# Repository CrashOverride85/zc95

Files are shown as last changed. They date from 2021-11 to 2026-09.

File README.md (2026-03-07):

# ZC95

**Note**: This repo has submodules, so if cloning, it's best to use the recursive option.

## Introduction
The ZC95 is a DIY four channel EStim box with similar output design and feel to the MK312-BT (which in turn is a clone of the ET-312B).

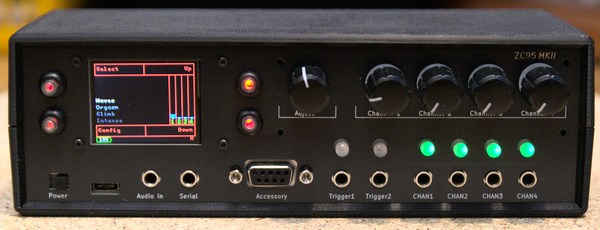
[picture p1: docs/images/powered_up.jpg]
zc95


The box is primarily intended for standalone use (i.e. not used whilst connected to phone/laptop/tablet), but can be controlled remotely via a Python GUI, and run Lua scripts that have been uploaded to it over serial or WiFi.

Main features:
- 4 isolated channels 
- [Audio input](./docs/AudioInput-Operation.md) - line level for estim tracks or microphone input (selectable via menu)
- [Many inbuilt patterns](./docs/Patterns.md) - around 14, not counting audio and more esoteric stuff
- Custom patterns can be written in [Lua](./docs/LuaNotes.md)
- Two stereo 3.5mm trigger input sockets, allowing for up to 4 external inputs (e.g. remote buttons, foot pedals, etc.)
- Support for many [BLE remote/camera buttons](./docs//BluetoothPeripherals.md), e.g. to trigger output when the button is pressed
- [Remote control](./docs/RemoteAccess.md) over WiFi or serial using a python app
- Allows limited control of a certain type of 433MHz shock collar
- Somewhat experimental [BLE steaming](./docs/BleStreaming.md) - allows for per-pulse level control from laptop or other device, with an example in python
- An accessory port with 3 output lines that can be controlled from Lua scripts, to allow interacting with other devices

Technical details:
- Has been designed with the JLC PCB assembly service in mind, and is mostly an SMD design with a few though hole parts
- Uses 2x Raspberry Picos
- Firmware is open source and mostly C++, and makes use of many [3rd party libraries](./docs/Credits.md)
- 26650 cell for power
- KiCad project files included in repo, not just gerbers
- Audio input includes microphone preamp that can be toggled via menu, along with variable gain
- Consists of 3 PCBs:
   * Front panel - no traces, just text / mounting holes
   * Front panel controls - 4x POTs and associated ADC, 1x rotary encoder and 6 serial RGB LEDs. Designed for production using the SMT assembly service at JLCPCB, with a handful of extra through hole parts also requiring hand soldering.
   * Main board - power supply / charging, pattern generation, button input, output signal generation, audio input
- Case is either an off the shelf Hammond 1598DBK (larger), or a 3D printed case (step/stl files provided)

## [Build guide](docs/Build.md)

## [Schematics](schematics/)

## [Gerbers](pcb/)

## [Compiled firmware](https://github.com/CrashOverride85/zc95/releases/)

## [Operation notes](docs/Operation.md)

## [Pattern guide](docs/Patterns.md)

## [Lua scripting notes](docs/LuaNotes.md)

## [Notes on building source](docs/SourceBuildNotes.md)

## [Credits](docs/Credits.md)

# Miscellaneous  
## History
The ZC95 is very heavily inspired by the MK312-BT, which is a reversed engineered version of the ET-312. The original repo for that project is long gone, but there is a fork [here](https://github.com/CrashOverride85/mk312-bt).

The [ZC95 mk1](https://github.com/CrashOverride85/zc95/tree/MKI) was made public in late 2021, and had a similar form factor to the MK312. That version has been built successfully by many.

The [ZC95 mk1](https://github.com/CrashOverride85/zc95/tree/MKI) had the output stage on a separate PCB. It's no longer part of the zc95 build, but could still be built and used to add 4 channel estim output to an Arduino (with notes for & tested with an ESP32).
The PCB / BoM / build notes for it are [here](./misc/OutputBoard/README.md).

## MKI vs. MKII
These are the main changes from the MKI to MKII:

 - Much smaller - the mainboard is less than half the size
 - Output, Audio and main board are now combined
 - USB-C charger input instead of 15v barrel jack
 - 26650 cell instead of 12v SLA battery (similar capacity)
 - "Aux" socket swapped for separate "Serial" and "Audio" sockets
 - Output sockets changed from 2.5mm to 3.5mm
 - Serial selectable (via jumpers) between 3.3v TTL and RS232
 - Display no longer briefly flashes white on power on
 - Removed: 12v output on accessory port

## Support, feedback, etc.
The ZC95 project is provided 'as is' without warranty of any kind, either express or implied. The project is provided for your use at your own risk.

Having said that, if you run into difficulties or have questions, the two best places to try are:
- Github [discussions](https://github.com/CrashOverride85/zc95/discussions) or [issues](https://github.com/CrashOverride85/zc95/issues)
- The ZC95 channel on [Joanne's E-Stim Community discord](https://discord.gg/HbGKY2t), see Estim control boxes -> zc95
  - I'd highly recommend joining this discord server anyway, the zc95 chanel is a _tiny_ part of what's there

## Other projects
Other related projects that are worth checking out:

- [NeoDK](https://github.com/Onwrikbaar/NeoDK) - Advanced electrostimulation machine development kit. In active development, and also has a chanel on [Joanne's E-Stim Community discord](https://discord.gg/HbGKY2t)

- MK-312BT - Project the ZC95 was inspired by, and shares lot in common with (original repo gone, but there are many [forks](https://github.com/CrashOverride85/mk312-bt))

- [WT-312](https://github.com/WendyTeslaburger/WT-312) - 312 style driver, intended for integration into other projects

- [FOC-Stim](https://github.com/diglet48/FOC-Stim) - In development, checkout the foc-stim channel on [Joanne's E-Stim Community discord](https://discord.gg/HbGKY2t) for the latest

# TODO
## Firmware
   - Triphase support from Lua 
   - Allow Lua scripts to interact with shock collars
   - Combo pattern? Having, e.g., waves on channels 1+2 plus something like TENS on 3+4 would be good
   - Save pattern settings on exit?
   - Disable when plugged in / switch to charging screen (maybe a setting in the menu to disable)
   - Accessory port doesn't do much - just 3 output lines. There's a serial interface there too, which could be exposed in the Lua environment

## Hardware
   - Improved 3D printed case?

## Known issues
   - Will charge faster if switched on when plugged in, and not switched off for at least 10 seconds (or just left on)
   - Sometimes when finished charging (battery icon showing solid green), the battery percentage will only show ~95% despite being fully charged. Should be fixed in a future firmware version. 

[zc95]: docs/images/powered_up.jpg "Assembled ZC95"

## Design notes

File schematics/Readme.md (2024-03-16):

For hardware change log, see [readme in PCB folder](../pcb/Readme.md)

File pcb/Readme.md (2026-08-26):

# Changes

## Front panel

### v1.1 (Mk2 Only)
- Kindly designed by rootuz. Please note that whilst the project files (EasyEDA) & gerbers for this PCB are available, they are provided under the [CERN-OHL-S](../pcb-project/FrontPanelControls/v1_x/LICENSE.txt) licence
- Updated to match the v1.1 FrontPanelControls board

### v0.5 (Mk2 only)
- Updated for Mk2: USB-C, separate audio & serial sockets, output sockets changed from 2.5mm to 3.5mm

### v0.4
- *Not publicly released*

### v0.3 (Mk1 only)
- Button holes enlarged to 8.1mm for LP1OA1Ax illuminated buttons

### v0.2 (Mk1 only)
- Left most 3.5mm socket renamed from "Serial" to "Aux"
- 4x holes for potentiometers enlarged so RK09L1140A2U fits without needing to manually enlarge the hole
- Project updated to KiCad 6

### v0.1 (Mk1 only)
First public version

## FrontPanelControls
### v1.1 (Mk2 only)
Technically this PCB should work on a Mk1, however there is no corresponding Front panel pcb
- Kindly designed by rootuz. Please note that whilst the project files (EasyEDA) & gerbers for this PCB are available, they are provided under the [CERN-OHL-S](../pcb-project/FrontPanelControls/v1_x/LICENSE.txt) licence
- Square buttons mounted direct to the PCB
- As the PCB extends to the buttons, the display is mounted to this PCB
- LEDs are surface mount, with light pipes to the front

### v0.2 (Mk1 & Mk2)
- Requires firmware version >=1.8
- Now mostly SMD aimed at JLCPCB's SMT assembly service
- 4x front panel buttons are now connected to this board, not the main board
- ADC changed from PCF8591 (EoL) to ADS1115
- I/O expander changed from PCF8574 to TCA9534
- Allows use of illuminated buttons (LP1OA1Ax) controlled by TLC59108
- Project updated to KiCad 6

### v0.1 (Mk1 only)
First public version

## MainBoard

### v2.6
Fix:
 - Improve layout: Move input capacitor closer to the BQ25601 charge controller

Tweaks:
 - Added header for audio input next to the audio jack

### v2.5
Fix:
 - Update power switch so that it toggles the power enable pin of the voltage regulators, instead of directly switching the power as before. To avoid over current fault / shutdown of BQ25601.

 Tweaks:
 - Changed 500mΩ sense resistors from 1218 to 2512 footprint for availability reasons
 - Sleeve and Ring of output TRS jacks are now connected together. Previously Ring was unconnected.

### v2.4
- *Not publicly released*

### v2.3
Tweaks:
 - No more vias in pads
 - Changed charge controller from TP4056 to BQ25601
 - Added 3.3v LDO powered from 5v rail to supply some of the audio circuitry (reduces noise when using a mic)
 - Changed footprint of LCD and Debug connectors to make intended orientation clear
 - Added ability to sense voltage on USB CC lines to determine type of charger connected
 - Display reset line now connected to port expander instead of pull up to 5v. Fixes intermittent issue where display would show pure white if the box was powered off, then powered up a few seconds later.

### v2.2
- *Not publicly released*

### v2.1
Fixed solder mask minimum width setting - restore to KiCad default of 0

### v2.0
Mk2. Many changes:
 - Now includes functionality that was previously on separate output & audio boards
 - USB-C charger input instead of 15v barrel jack
 - 26650 cell instead of 12v SLA battery (similar capacity)
 - "Aux" socket swapped for separate "Serial" and "Audio" sockets
 - Output sockets changed from 2.5mm to 3.5mm
 - Serial selectable (via jumpers) between 3.3v TTL and RS232
 - Display no longer briefly flashes white on power on
 - Removed: 12v output on accessory port
 - Will not work with FrontPanelControls PCB v0.1

### v0.2
Mk1. First public version.

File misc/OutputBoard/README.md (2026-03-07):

# Output board

The original ZC95 mk1 had the estim output stage on a separate PCB; that's been incorporated into the main board with the mkII. Whilst it was only ever intended to be used as a part of the ZC95, the output board could also be used from other projects, and there is an included [Arduino library](../Arduino/libraries/Zc624Output/README.md) for it.
So these are the (slightly tweaked) original build notes from that board, in case it's still of interest to anyone.

---

## PCBs
The output board ("ZC624 Output module") has been designed with the JLCPCB SMT assembly service in mind, although the footprints are the hand-solder versions where applicable, and some (through hole) parts still need hand assembly.
Order the board using [these gerbers](./pcb/OutputBoard-gerbers.zip) and the default options as per the other boards.

This time, select the "SMT Assembly" option at the bottom - pick "Assemble top side" and Tooling holes "Added by JLCPCB".
On the next page, add the BOM and CPL files:
* [output_bom_jlc.csv](./pcb/output_bom_jlc.csv)
* [output_cpl_jlc.csv](./pcb/output_cpl_jlc.csv)

The next page should show a list of all parts found / matched. The BoM/CPL file also includes some through hole parts - I'd suggest un-ticking these and soldering them yourself as it's cheaper.

## Other parts
Other parts required to assemble the board are listed in the [BoM](OutputModuleBom.fods).

## Transformers
The ZC624 output board was originally designed and tested with 42TL004 transformers in mind. However, v0.2 is designed so that the larger/more powerful 42TU200 transformers _should_ also fit. This isn't something I've tested. I recommend sticking with the 42TL004's listed in the BoM.

## Assembly
Photo of board as it arrived from JLCPCB:

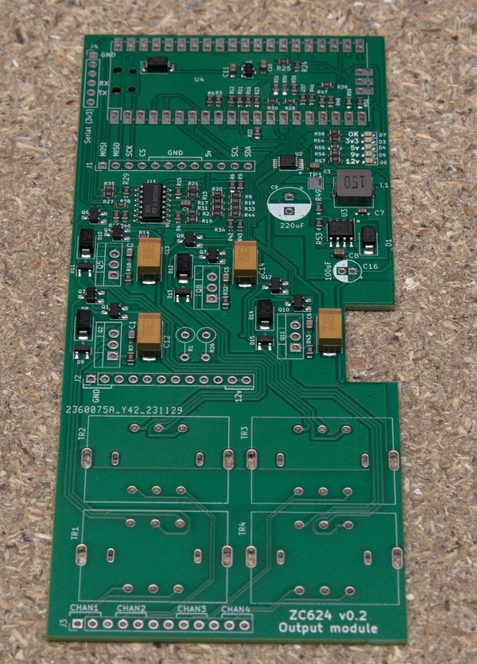
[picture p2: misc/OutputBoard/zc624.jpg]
zc624 smt only


Notes
* The pin headers J1, J2 & J3 go on the bottom of the board, J4 ("Serial") on the top. I found it easier to plug the board into the main board, then solder J1, J2 & J3 to be sure they were straight / lined up
* The 4 transformers have the "P" facing towards the bottom. Note that the transformers are used "backwards" - the side labelled primary goes to outputs.
* PFETs Q2, Q5, Q8 & Q11 should have the metal back facing towards the left of the board (silkscreen is correct)
* Solder on both the 1x20 pin sockets for the Pico. The 3 pin header on the right should be unpopulated.

Fully assembled board:

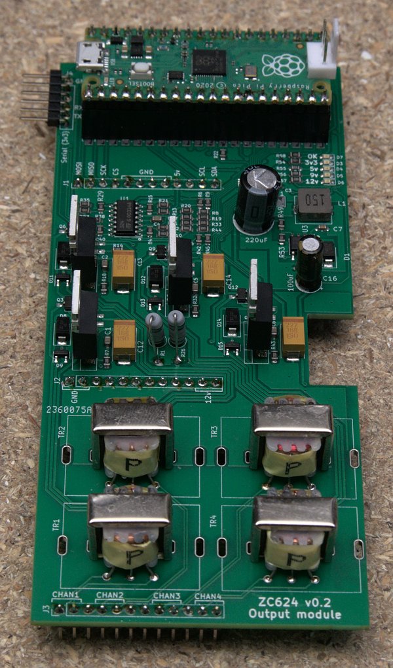
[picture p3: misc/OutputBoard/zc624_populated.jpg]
zc624 populated


## Loading firmware
Download the "OutputZc.uf2" firmware from [Releases](https://github.com/CrashOverride85/zc95/releases).

To load firmware onto a Pico:
* Hold down the BOOTSEL button
* Connect to PC via USB
* The Pico should appear as a USB mass storage device. Drag the uf2 firmware binary onto the drive

## Troubleshooting
If the ZC624 passes its self test, the OK LED should light (which should be ~1-2 seconds after power on). If it fails, this light should flash.

There is also debugging output from the ZC624 board on the serial header. Note that is at 3v3 level, and RS232 levels would damage it.

Connect a 3.3v TTL serial to USB adapter to the pins labelled Tx and GND on the header, connect at 115200 baud, and power it on. 
After the output of an I2C scan and a few other bits, it should output something similar to this on success:

```
calibrate for sm=0 OK: dac_val = 2860, voltage = 0.075732
calibrate for sm=1 OK: dac_val = 2870, voltage = 0.075732
calibrate for sm=2 OK: dac_val = 2870, voltage = 0.076538
calibrate for sm=3 OK: dac_val = 2840, voltage = 0.078149
Calibration success
```

On failure, the end of output may look something like this:

```
calibrate for sm=3 FAILED! final voltage = 0.011279, dac_value = 2600 (expecting 0.075v - 0.090v)
One or more chanel failed calibration, not enabling power.
CMessageProcess()
HALT.
```

### Self calibration notes
The purpose of the self calibration is to figure out exactly when the P-channel MOSFET for each channel starts to switch on, as this can vary slightly due to variances between parts, etc. It also serves as a basic self-test.

This probably needs a brief explanation about how the output board is working. The two n-channel MOSFETs per chanel are used to generate +ve/-ve pulses (in the range of 10-255 microseconds). In normal operation, only one is switched on at once, but during calibration both are switched on so that there is little/no estim output.

The P-channel MOSFET is connected to the DAC via an op-amp, and is used to set the output power. With the maximum DAC value (4096) the MOSFET will (should) be fully OFF, and at 0 fully ON (i.e. maximum power).

In practice, if starting at a DAC value of 4000 and working down, the MOSFET should start to turn on at around 3000, and be fully on by ~1000.

During calibration, the voltage across the 0.5R sense resistor is measured, which corresponds to current flow though the P-channel MOSFET and transformer. This can be used to tell when the MOSFET starts to switch on.

The process for self power-on calibration (for each channel) is:
1. With the 3 MOSFETs switched off (dac value = 4000), the voltage across the sense resistor is measured - ideally it should be 0v as everything is off, but in reality noise means it won't quite be 0; however if it is > 0.03v something is clearly wrong so the calibration errors out.
2. The DAC is set to 3400
3. Both N-chanel MOSFETs are switched on
4. The voltage across the sense resistor is measured, then the N-channel fets switched off
    - If > 0.09v, something's gone wrong (unexpected jump in current), and calibration errors out
    - If > 0.075v, the DAC value is saved as the calibration value, and calibration for the channel completes successfully
    - Otherwise, the DAC value is reduced and the process repeats from step 3. If it's reached 2400 and the voltage still hasn't hit 0.075v, calibration errors out as the P-channel fet should be starting to switch on by this point.

All this means is that an error like this:
```
calibrate for sm=3 FAILED! final voltage = 0.011279, dac_value = 2400 (expecting 0.075v - 0.090v)
```
means that the PFET never switched on (enough) to complete calibration successfully.

An error like this:
```
calibrate for sm=3 FAILED! final voltage = 1.541235, dac_value = 3400 (expecting 0.075v - 0.090v)
```
means the opposite - at the starting value of 3400, the voltage across the sense resistor (and therefore current flow though the PFET & transformer) was already way above what it should be.

Possible causes (not exhaustive!) for calibration to fail:
* If all channels are showing a similar and very low voltage (~0.01v) at a DAC value of 2400, suspect the 9v supply (and in turn, the 12v supply it's derived from)
* Bad/incorrect PFET - e.g. not an IRF9Z24**NPBF**
* Too low value sense resistor (if DAC value is 2400), or too high (if DAC value is 3400)
* Incorrect resistor value in the opamp circuit - likely if the final voltage is wildly off. Also suspect a bad/cracked resistor or poor solder joint if the final voltage keeps changing between power cycles 

**Note**: If calibration fails, the 9v supply is switched off, so this not being present after a calibration failure is not a fault.

[zc624 smt only]: zc624.jpg "ZC624 as received from JLCPCB"
[zc624 populated]: zc624_populated.jpg "Fully populated ZC624"

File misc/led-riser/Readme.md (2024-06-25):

LED riser for front panel LEDs, contributed by @electro991, see [#102](https://github.com/CrashOverride85/zc95/discussions/102)

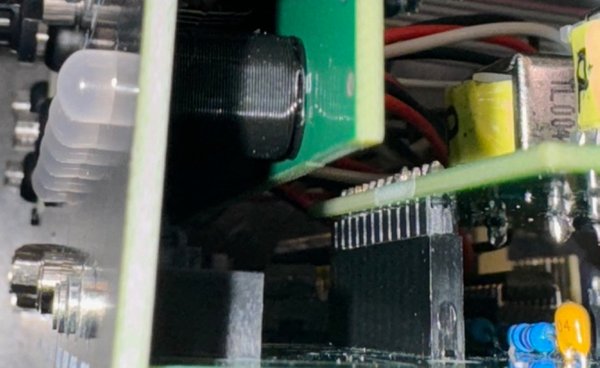
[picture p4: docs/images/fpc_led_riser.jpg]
Riser LED riser


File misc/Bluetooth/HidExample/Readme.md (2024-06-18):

# Bluetooth HID example

## Summary
This is the counterpart to the example [bluetooth_hid.lua](../../../remote_access/lua/bluetooth_hid.lua) script. It requires a separate Pico-W & a potentiometer. As the potentiometer is changed, the power level on the connected ZC95 running the bluetooth_hid script is changed.
It's intended as an example of the bluetooth support, not a useful project in its own right.

## Build
### Hardware
Connect a potentiometer (anything between 10k & 100k should be fine) between a ground pin and the 3v3 out pin of the Pico, and connect the wiper to pin 31 (ADC0/GP26). If needed, serial debug output is on pin 1 (GP0).
Power over USB.

### Firmware
Same as the [main ZC95 firmware](../../../docs/SourceBuildNotes.md) - run cmake & make, and copy the resulting UF2 file to the pico.

## Use
* Upload the [bluetooth_hid.lua](../../../remote_access/lua/bluetooth_hid.lua) script to the ZC95
* Enable bluetooth
* Power on the pico-w with the hid_example firmware
* On the ZC95, go to Config -> Bluetooth -> Scan/Pair
* Hopefully the "Zc Hid Ex" device shows up - pair with it
* Go back, and start the "BtHid" pattern previously uploaded
* Make sure the power is turned up on at least one chanel 

After a few moments it should connect, and turning the potentiometer should change the power level for all 4 channels.

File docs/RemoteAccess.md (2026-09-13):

# Remote access

***Warning***: All remote access and Lua stuff is somewhat experimental at this point

## Summary
The ZC95 can be controlled remotely either using serial (Aux port) or using WiFi if a Pico-W is used for the MCU on the main board.

The remote access options can be used to:
* Upload Lua scripts (of which 5 can be stored) using either a web interface or python utility
* Control the box remotely with a Python GUI
* Limited control using an Arduino/ESP32 with the [ZC95 Arduino library][ArduinoLib].
* Custom app using the [JSON interface](./JSON.md)

## Connecting using WiFi
If a Pico-W is used, the Config -> Remote Access menu should include options relating to WiFi.

Once connected to WiFi, patterns can be controlled either using the python scripts below ran on a PC, or using the mobile-friendly web interface (`webgui.py`, see below) from any device on the same network - e.g. a phone.

The basic process is use the "Config Wifi/AP mode" option, ideally connect to the ZC95 using a phone, then use the web interface to enter a WiFi SSID/Password. When the "Connect to Wifi" option is next used, these credentials will be used. At present, other than setting the WiFi SSID/password, nothing else can be done in ap mode.

When selecting "Config Wifi/AP mode", a screen showing the strongest networks found is displayed:

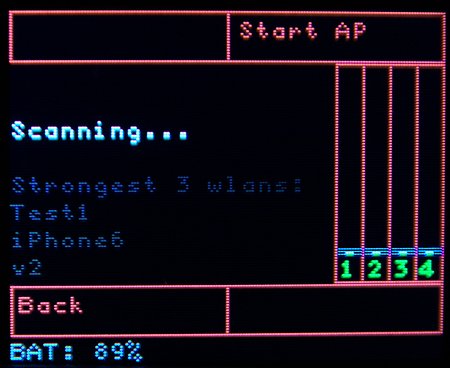
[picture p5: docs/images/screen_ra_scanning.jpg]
Scanning


This will continue to scan for networks for as long as the screen is open.

When at least one WiFi network is detected, the "Start AP" soft button (top right) is enabled. Pressing this starts the Access Point mode, and shows a QR code to allow connecting:

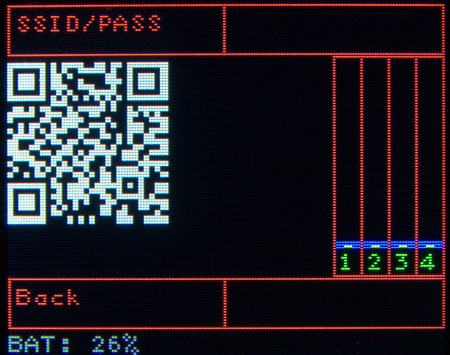
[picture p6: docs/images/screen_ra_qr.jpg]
QrCode


### Apple phones
Scan the QR code - you should get a popup to connect to the zc95-xxx WiFi network - press join. Then go to settings -> Wi-Fi, you should get a popup titled "Log in" followed by this screen (can take 4-5 seconds or so to appear):

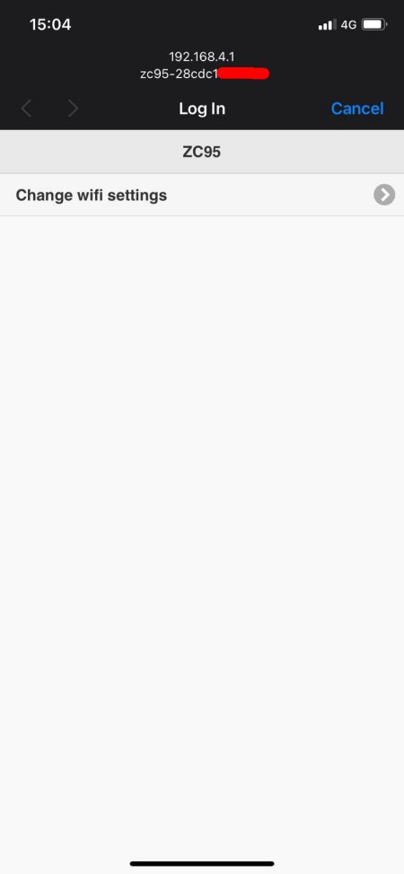
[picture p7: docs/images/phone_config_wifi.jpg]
PhoneConfigWifi


Go into "Change wifi settings", it should list all WiFi networks found. Pick the appropriate one, then enter the password for it when prompted then "Connect to the wifi network". 
That should be it - exit the menu on the ZC95 and try connecting to the network.

If the QR code isn't working for some reason, press the top left ("SSID/PASS") soft button and you should see a screen giving the SSID and password required to connect manually, e.g.:

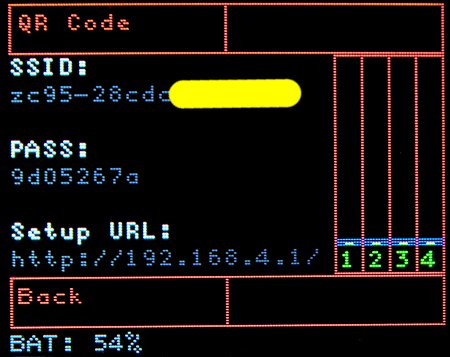
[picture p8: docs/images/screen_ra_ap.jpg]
ShowSsidAndPassword


If the config page doesn't automatically appear, manually browse to "http://192.168.4.1/" once connected to the hotspot.

### Android
Untested, but hopefully similar.

### Connecting
Select the "Connect to WiFi" option, and it should connect to the WiFi network previously configured using the above steps. Once connected, you should see something that looks like:

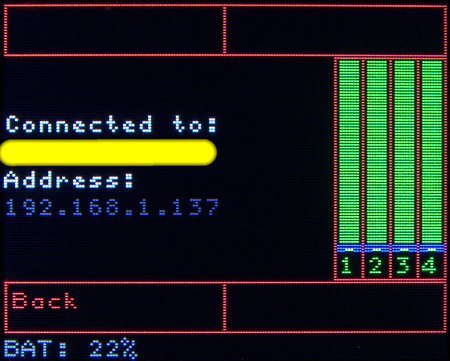
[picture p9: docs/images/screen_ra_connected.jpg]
ConnectedToWifi


At this point, the Python GUI, scripts and integrated web interface to list/upload Lua scripts should work if given the IP displayed on screen.

To upload a script using the built in web interface, browse to the address displayed on screen, click the "Upload" button next to one of the script slots, then pick a script to upload:

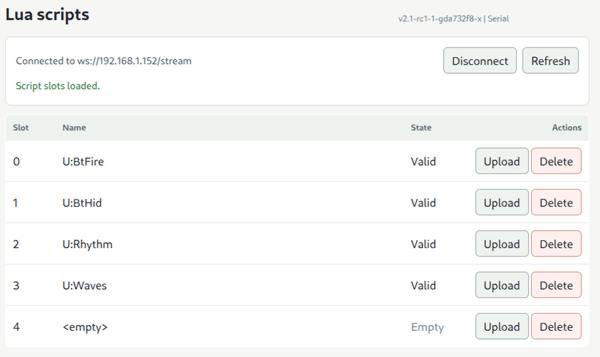
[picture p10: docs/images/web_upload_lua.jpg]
WebInterface


## Serial control
The ZC95 can also be controlled using serial via the 3.5mm aux/serial port. 
For the MKI, this is always RS-232. For the MKII, it is either TTL or RS-232 depending on the position of jumpers on J5 (see build notes).

Pin out:

* Tip = Receive
* Ring = Transmit (ZC95 output)
* Sleeve = Ground

Before this mode can be used, the hardware configuration needs to be set to:
* Debug output = `Accessory port` or `Off`
* MKI only: Aux port use = `Serial I/O`

(see Hardware config section in [Operation notes](./Operation.md))

Once selected, and screen is showing "Serial control mode", the Python GUI and scripts to list/upload Lua scripts should work if given the serial port the ZC95 is connected to.

## Python scripts
The python scripts can be used to upload and manage up to 5 scripts (stored in slots 0-4) on the ZC95.
Scripts in slots 1-4 can be up to 24k, slot 0 is larger and the script can be up to 48k.

There are a few Python scripts available in the `remote_access` folder for interacting with the ZC95 once it's connected to wifi, or via serial:
* pattern_list.py - lists all patterns available remotely, along with the ID number (excludes Audio patterns)
* lua_manage.py - lists uploaded Lua scripts, and allows for them to be deleted
* lua_upload.py - uploads a Lua script
* pattern_gui.py - starts a tkinter GUI that starts a pattern and can then be used to control it
* webgui.py - starts a web server providing a mobile-friendly version of pattern_gui.py, so a pattern can be started and controlled from a phone/tablet browser (or several at once) instead

For all scripts other than webgui.py (see its own section below):
* Either ``--ip <IP address>`` _or_ ``--serial <serial port>`` must be specified
* The optional `--debug` parameter can be used to show messages being sent/received, and sometimes other extra info

### pattern_list.py
Used to list all pattens on the ZC95 that can be controlled remotely, including any from Lua scripts uploaded. E.g.:
```
$ python3 pattern_list.py --ip 192.168.1.137
Connecting
Connection opened
Patterns on ZC95:
0       U:Waves
1       Waves
2       Toggle
3       RoundRobin
4       TENS
5       Climb
6       Triggered Climb
7       Fire
12      Climb with pulse
13      Predicament
14      Shock choice
15      Camera Trigger
16      Buzz
Websocket connection closed
$
```
All uploaded Lua scripts are prefixed with "U:". Note that the pattern ID listed isn't fixed - it will change as extra Lua scripts are uploaded and if the pattern order is changed in future versions.

Finally, the Audio patterns are excluded for the time being as these do not work remotely.

### lua_manage.py
Can be used to list and delete Lua scripts on the box, e.g.:
```
$ python3 lua_manage.py --serial /dev/ttyUSB0 --list
Opening: /dev/ttyUSB0
Connection opened
Script slots on ZC95:
4 - <empty>
3 - <empty>
2 - <empty>
1 - <empty>
0 - U:Waves
Connection closed
$
```
When uploading a Lua script, it's the id/index from the above list that needs to be used to specify where to put the script.

A script can be deleted by running `lua_manage.py --ip 192.168.1.137 --delete <index>`, but it can be overwritten without being deleted.

### lua_upload.py
Uploads a Lua script to the designated slot/index on the ZC95, e.g.:
```
$ python3 lua_upload.py --script ./lua/waves.lua --ip 192.168.1.137 --index 0
Connecting
Connection opened
Uploading...
Done!
Websocket connection closed
$ 
```

If the script isn't valid, you may see an error like:
```
$ python3 lua_upload.py --script ./lua/waves.lua --ip 192.168.1.137 --index 1
Connecting
Connection opened
Uploading...
Got error message: 
    Invalid script: [string "_freq_min_hz = 25..."]:9.00000: '=' expected near 'Config'
Websocket connection closed
Failed
$ 
```
The "9.00000" means the error is likely on/around line `9`; I'm not sure why Lua includes the `.00000`. 

Note that many errors won't be picked up at this stage - a successful upload doesn't mean the script is good.

Once uploaded, the script will be visible at the top of the usual patterns list, as well as being available for pattern_gui.py to control.

See [Lua](./LuaNotes.md) for notes on writing Lua scripts.

### pattern_gui.py
See next section for more details on running a pattern remotely. 

### webgui.py
Starts a small local web server providing a mobile-friendly equivalent of pattern_gui.py - the pattern to run is picked from a dropdown in the browser rather than passed on the command line, and any number of devices/tabs on the same network can connect at once, all controlling (and seeing the state of) the same running pattern.

Needs a couple of extra dependencies beyond the other scripts here:
```
$ pip3 install -r requirements-webgui.txt
```

Start it pointed at the ZC95's IP (serial isn't supported - a web interface reachable from a phone implies WiFi):
```
$ python3 webgui.py --ip 192.168.1.137
Starting web interface - browse to http://<ip of this machine>:8080/ from your phone/tablet/PC
```

Then, from any device on the same network (e.g. a phone), browse to `http://<ip of the PC running webgui.py>:8080/`. Use `--port` to change the port it listens on, and `--debug` to log messages sent/received to/from the ZC95 to the console.

See the next section for more on the power sliders/dials, which apply the same way here as with pattern_gui.py.

## Running a pattern remotely

### Power setting
When running a pattern remotely, the 4 power dials on the front panel are used to set the maximum power setting possible for the respective channel. I.e. setting all channels to maximum means the box can be fully controlled, up to maximum power, remotely. 

### Starting
Start by passing the index (as given by `pattern_list.py`) of the pattern to run to the pattern_gui.py script:
```
$ python3 pattern_gui.py --ip 192.168.1.137 --index 1
Connecting
Connection opened
```

After connecting the GUI should then appear:

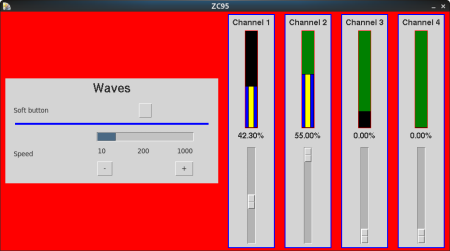
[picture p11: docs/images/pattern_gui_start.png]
Gui


The 4 channels are set to different levels:
1. Front panel is set to full power, and the GUI is slider is about half way; power is as set on the GUI
2. Front panel is set to just over half power, but the GUI slider is set to full power; power is limited to just over half
3. Front panel is set low, but GUI is set to zero; power is 0%
4. Front panel and GUI is at minimum; power is 0%

### Debug mode
If started with the ```--debug``` flag, in addition to showing messages sent/received, an output window appears at the bottom of the GUI:

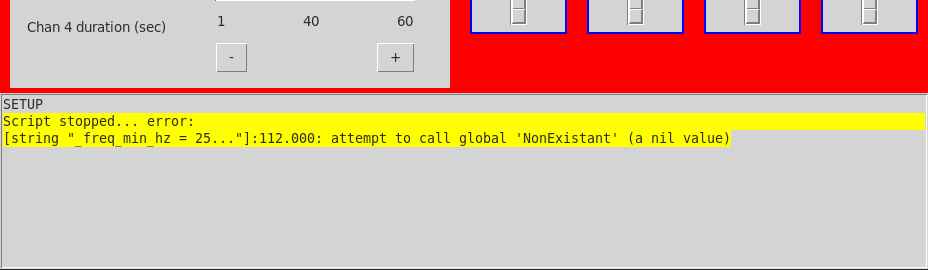
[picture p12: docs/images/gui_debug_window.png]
GuiDebug


In this case, it's showing a script that's failed on line 112 due to a call to a function that doesn't exist. Any `print()` output from Lua scripts will also appear here, making this mode useful for testing new Lua scripts.

[Scanning]: images/screen_ra_scanning.jpg "Remote access (AP mode) scanning screen"
[QrCode]: images/screen_ra_qr.jpg "Remote access (AP mode) screen showing QR code"
[PhoneConfigWifi]: images/phone_config_wifi.jpg "Configure wifi on iphone"
[ShowSsidAndPassword]: images/screen_ra_ap.jpg "Screen showing SSID and password for AP mode"
[ConnectedToWifi]: images/screen_ra_connected.jpg "Connected to WiFi screen"
[WebInterface]: images/web_upload_lua.jpg "Integrated web interface to upload Lua scripts"
[Gui]: images/pattern_gui_start.png "Python GUI showing Waves pattern"
[GuiDebug]: images/gui_debug_window.png "Python GUI showing debug window"
[ArduinoLib]: ../misc/Arduino/libraries/Zc95/README.md

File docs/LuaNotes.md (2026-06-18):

# Lua

## Capability
Lua scripts can be written / uploaded (see [Remote Access](./RemoteAccess.md) for how to upload) to add new patterns to the ZC95. These scripts are able to switch each channel on/off, set the frequency and pulse width, and set the power level (scaled to what the front panel is set to - i.e. a Lua script can't set the output power to higher than set on the front panel).
They can also receive notification of settings being changed via the menu, and inputs from the external trigger inputs along with the top left soft button being pressed.
There is also limited support for audio - so far only reacting to volume, and no audio wave display when running over Wifi (and no audio support at all over serial).

## Example scripts
There are a few example scripts in `remote_access/lua`, which demonstrate some of things that can be done from Lua. These scripts are:

* fire.lua - If the soft button is pressed, all channel's are activated for as long as the button is held down. If any of the 4 external triggers (assuming stereo connectors are being used), the the corresponding channel (1-4) is activated for as long the trigger is active.

* toggle.lua - switches between channel 1+2 & 3+4 at a speed that can be set via the menu. If the channels are switched on constant or just pulsed can also be set from the menu

* waves.lua - a basic waves pattern. For each channel, this varies the frequency between 25Hz and 250Hz and the pulse width between 40us and 200us, with the time taken for each cycle being set per channel on the menu.

* audio.lua - audio example assuming microphone input. Channels 1 & 2 are on constant at the default pulse width/frequency. Channels 3 & 4 react to volume changes

* bluetooth_fire.lua - uses Left/Up/Down/Right buttons on a bluetooth remote to trigger chanel's 1 to 4 respectively for a configurable pulse duration

* acc_test.lua - uses the accessory port to cycle between HIGH/LOW on the 3 output lines. See "AccIoWrite" section below for more details. Doesn't produce any estim output, so not really of any practical use, just a demo of how to use the accessory port.

The inbuilt Waves, Climb & Orgasm patterns are also written in Lua (contributed by someone who prefers to remain anonymous); the source for these can be found in `source/zc95/LuaScripts/`. Note that these are designed to closely resemble the patterns of the same name from another popular box, so might not be the best example to follow for new scripts.

## toggle.lua

It's probably easier to explain Lua as implemented in the ZC95 by going though one of the example scripts.

toggle.lua:
```
_delay_ms = 500

Config = {
    name = "Toggle",
    audio_processing_mode = "OFF",
    menu_items = {
        {
            type = "MIN_MAX",
            title = "Delay",
            group = 0,
            id = 1,
            min = 100,
            max = 2000,
            increment_step = 100,
            uom = "ms",
            default = _delay_ms
         },
         {
            type = "MULTI_CHOICE",
            title = "Output",
            group = 0,
            id = 2,
            choices = {
                {choice_id = 1, description = "Pulse"},
                {choice_id = 2, description = "Constant"}
            }
         }
    }
}

_channel12_on = false
_wait_until_ms = 0
_pulse_mode = true

function MinMaxChange(menu_id, min_max_val)
    if (menu_id == 1)
    then
        _delay_ms = min_max_val
    end
end

function MultiChoiceChange(menu_id, choice_id)
    if (menu_id == 2 and choice_id == 1)
    then
        _pulse_mode = true
    end

    if (menu_id == 2 and choice_id == 2)
    then
        _pulse_mode = false
    end
end

function Loop(time_ms)
    if (time_ms > _wait_until_ms)
    then
        ToggleChannel();
        _wait_until_ms = time_ms + _delay_ms
    end
end

function ToggleChannel()
    if (_channel12_on == true)
    then
        zc.ChannelOff(1)
        zc.ChannelOff(2)

        if (_pulse_mode == true)
        then
            zc.ChannelPulseMs(3, 100)
            zc.ChannelPulseMs(4, 100)
        else
            zc.ChannelOn(3)
            zc.ChannelOn(4)
        end
        _channel12_on = false
    else
        if (_pulse_mode == true)
        then
            zc.ChannelPulseMs(1, 100)
            zc.ChannelPulseMs(2, 100)
        else
            zc.ChannelOn(1)
            zc.ChannelOn(2)
        end

        zc.ChannelOff(3)
        zc.ChannelOff(4)
        _channel12_on = true
    end
end
```

The `Config` section is used to set the name and build the on screen menu:
```
Config = {
    name = "Toggle",
    audio_processing_mode = "OFF",
    menu_items = {
        {
            type = "MIN_MAX",
            title = "Delay",
            id = 1,
            group = 0,
            min = 100,
            max = 2000,
            increment_step = 100,
            uom = "ms",
            default = _delay_ms
         },
         {
            type = "MULTI_CHOICE",
            title = "Output",
            id = 2,
            group = 0,
            choices = {
                {choice_id = 1, description = "Pulse"},
                {choice_id = 2, description = "Constant"}
            }
         }
    }
}
```
`name = "Toggle"` sets the name for the script - this is prefixed with `U:` then used on the patterns menu.

Optional fields:
* `group` - group number; this only has any affect when ran remotely using the GUI, and allows related options to be grouped together, instead of appearing in one long list (useful for scripts with many options)
* `audio_processing_mode` - if the script can use audio, sets the mode. Currently either `OFF` (default) or `AUDIO_INTENSITY`. See audio section later.
* `bluetooth_remote_passthrough` - if present and set to `True`, keypresses from connected to bluetooth remotes are passed though to the `BluetoothRemoteKeypress()` function, instead of using the configured mappings from the config menu. See `BluetoothRemoteKeypress()` notes later for more details
* `serial` - see later "Serial I/O" section for options available in the `serial` block. If supplied, allows access to the serial lines on the accessory port from the script.

A menu entry is displayed when the script is running for each item in `menu_items`; each must be given a unique id, numbered sequentially from 1.

 There are four types supported:
* `MIN_MAX` - shows a horizontal bar graph that can be changed between the set min/max using the adjust dial. The unit of measure (uom) text is displayed as suffix to the numeric value in the bar chart 
* `MULTI_CHOICE` - used to show a menu option that allows for one of multiple settings to be picked. Each choice must have a unique id.
* `AUDIO_VIEW_INTENSITY_STEREO` - show a stereo waveform display; see audio section later
* `AUDIO_VIEW_INTENSITY_MONO` - show a mono waveform display; see audio section later

```
function MinMaxChange(menu_id, min_max_val)
    if (menu_id == 1)
    then
        _delay_ms = min_max_val
    end
end
```
If present, the `MinMaxChange(menu_id, min_max_val)` function is called whenever a `MIN_MAX` menu type is changed, with the ID of the menu and the new value.

```
function MultiChoiceChange(menu_id, choice_id)
    if (menu_id == 2 and choice_id == 1)
    then
        _pulse_mode = true
    end

    if (menu_id == 2 and choice_id == 2)
    then
        _pulse_mode = false
    end
end
```
Similar to MinMaxChange but for `MULTI_CHOICE` menu types; if present, the `MultiChoiceChange(menu_id, choice_id)` function is called whenever a `MULTI_CHOICE` type menu entry is changed, with the menu ID and the choice ID now selected.

```
function Loop(time_ms)
    if (time_ms > _wait_until_ms)
    then
        ToggleChannel();
        _wait_until_ms = time_ms + _delay_ms
    end
end
```
The `Loop(time_ms)` function is mandatory, and is called periodically for as long as the Lua script is running. The time_ms parameter is how long, in milliseconds, since the box was powered up.

```
function ToggleChannel()
    if (_channel12_on == true)
    then
        zc.ChannelOff(1)
        zc.ChannelOff(2)

        if (_pulse_mode == true)
        then
            zc.ChannelPulseMs(3, 100)
            zc.ChannelPulseMs(4, 100)
        else
            zc.ChannelOn(3)
            zc.ChannelOn(4)
        end
        _channel12_on = false
    else
        if (_pulse_mode == true)
        then
            zc.ChannelPulseMs(1, 100)
            zc.ChannelPulseMs(2, 100)
        else
            zc.ChannelOn(1)
            zc.ChannelOn(2)
        end

        zc.ChannelOff(3)
        zc.ChannelOff(4)
        _channel12_on = true
    end
end
```

The `ToggleChannel()` function (could have been named anything) is switching between the two pairs of channels. The relevant parts are the zc.* functions:
* `zc.ChannelPulseMs(channel, duration)` - will pulse a channel on for the specified number of milliseconds
* `zc.ChannelOn(channel)` - switches a channel on until switched off
* `zc.ChannelOff(channel)` - switches a channel off

See zc.* functions section below for more details along with all available zc.functions

## zc.* functions
Functions that can be called from Lua scripts to control the box. In addition to these, `print("<whatever>")` can be used from scripts (no `zc.` prefix); the output will appear in the serial output prefixed with '`[LUA]`', and in the debug window of the `pattern_gui.py` GUI if running remotely. 

### SetPower
```
Params:
    * channel - 1-4
    * power   - 0-1000
```
Sets the output power of channel from 0 to 1000. This output power is scaled based on what the front panel dial is set to for the channel. E.g if the front panel is set to 50% and a power level of 500 is set, the result will be a power level of 250 (25%).

If there is no `Setup()` function in the script, all channels will default to full power (i.e. only affected by front panel dials), so it often isn't necessary to use this. Most inbuilt patterns don't change the power level.

### SetFrequency
```
Params:
    * channel number (1-4)
    * frequency (1 - 300) Hz
```
Sets the output frequency of the specified channel. Currently defaults to 150Hz, but this default may move into the config menus at some point.

### SetPulseWidth
```
Params:
    * channel number (1-4)
    * positive pulse width (0-255) us
    * negative pulse width (0-255) us
```
Sets the pulse width used for the channel, defaults to 150us, but this default may move into the config menus at some point.
For symmetric pulses (as used by most/all inbuilt patterns), these two values should be the same. 

### SetMenuOption
```
Params:
    * menu_id
    * value
```
This can be used to allow a Lua script to change the setting of one of its menu options.
MenuId must match an `id` in the menu_items section of the Config block.

For MIN_MAX type menu entries, the `value` must be between the configured `min` and `max` for that menu entry.

For MULTI_CHOICE type menu entries, `value` must match one of the `choice_id`s. 

**Important**: The change will result in the scripts `MinMaxChange` or `MultiChoiceChange` function being called asynchronously when the update takes effect. After calling `SetMenuOption`, it is possible (but not guaranteed) that the `Loop` function could be called many times _before_ the menu is updated.

### ChannelPulseMs
```
Params:
    * channel number (1-4)
    * duration (ms)
```
Switch the channel on for the specified number of milliseconds, using the previously set frequency, pulse width and power level (or the defaults, if not changed).

### ChannelOn
```
Params:
    * channel number (1-4)
```
Switch on the specified channel, until ChannelOff is called, using the previously set frequency, pulse width and power level (or the defaults, if not changed).

### ChannelOff
```
Params:
    * channel number (1-4)
```
Switch off the specified channel.

### EnableTriphase
```
Params:
    * enabled true/false
```
Enables triphase support - see Triphase section further down. Requires `allow_triphase = true` to be present in the config section, and allows the use of `LinkChannels`.

### LinkChannels
```
Params:
    * lead channel 1-4
    * linked channel 1-4, or 0 to unlink
    * offset percentage (0-100)
```

`EnableTriphase(true)` must be called first.

Links `linked` channel to `lead` channel - causes a pulse on the linked channel to be generated to overlap with lead channel. An offset of 0% would generate the pulses simultaneously, where 100% would cause the pulses on the linked channel to be generated as the pulse on the lead finishes.
Once a channel is linked, the linked chanel should not be controlled directly other than changing its power setting - i.e. don't call `ChannelOn`, `SetPulseWidth` etc. for it - doing so will cause it to be unlinked.

See triphase section later for further details.

### AccIoWrite
```
Params:
    * Accessory I/O line number (1-3)
    * State: true (high) or false (low)
```
Controls the 3 I/O lines on the accessory port - allows setting between high (3.3v) and low.

Note that the default state of these 3 lines from power on is HIGH, so bear that in mind when connecting anything.
These lines can only source a few milliamps safely, so should only be used for signalling, i.e. it's probably best to connect a logic level MOSFET to switch anything more substantial than an LED.

Also worth noting that there is _very_ limited protection on this port, something to be corrected in a possible future hardware revision, so be careful to avoid higher voltages. In particular, there is 12v on pin 7 (in hindsight a poor decision) - connecting this to pretty much any other pin would be bad.

Minimal example for using the accessory port to control 3 LEDs. Can be used with the "acc_test.lua" example LUA script to switch between each LED in turn.

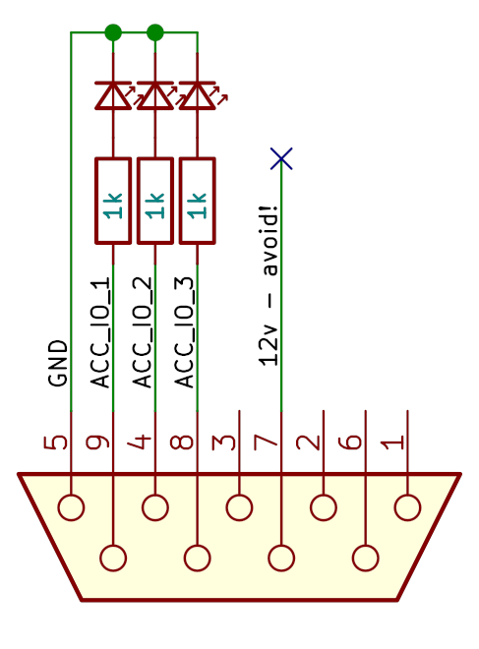
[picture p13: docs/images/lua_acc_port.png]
acc port


### AccIoSetInput
```
Params:
    * Accessory I/O line number (1-3)
```
Sets an I/O line on the accessory port to be an input, with a weak pull up.
This is the default state of the lines from power on, and each is reset to be an input when a pattern is started; i.e. there should not normally be a need to call this method.

When the state of an I/O line set to input changes, the `ExternalTrigger` method in the Lua script (if present) is called - see description of `ExternalTrigger` for more details.

### AccSerialWrite
```
Params:
    * String to write to serial on accessory port
```
See later "Serial I/O" section.

### DelayMs
```
Params:
    * Delay in milliseconds (0 - 10000)
```
Delay/sleep for the specified number of milliseconds. During the delay, other events (e.g. `MinMaxChange`, `SoftButton`) will still fire, so be sure the script is written to expect that.

## Special functions
These are functions that will be automatically called when applicable whilst the Lua script is running. With the exception of `Loop()`, all are optional. 

### MinMaxChange(menu_id, new_value)
Called when a `MIN_MAX` type pattern option is changed, and is called with the menu ID of the option, and the new value (which should lie between the min and max configured).

### MultiChoiceChange(menu_id, choice_id)
Called when a `MULTI_CHOICE` type pattern option is changed, and is called with the menu ID of the option, and the ID of the selected choice.

### SoftButton(pushed)
Called with `pushed=True` when the top left soft button is pressed, and then again when it is released with `pushed=False`. The soft button text is set by specifying `soft_button = "<label>"` in the `Config = {}` section. See `fire.lua` script for an example.

### ExternalTrigger(socket, part, active)
Called when an external trigger happens.

Socket: can be either "`TRIGGER1`", "`TRIGGER2`" or "`ACCESSORY`" for the Trigger1, Trigger2 or Accessory sockets respectively. 

For the 3.5mm trigger sockets, part can be either "`A`" or "`B`". With a stereo 3.5mm TRS cable inserted, shorting Tip and Sleeve is part `A` (trigger LED lights up green). Shorting Tip and Ring is part `B` (trigger LED lights up red). When triggered, `active` will be `True`, when released it will be `False`.

This function will also be called for input on the accessory port. Shorting ACC_IO_1, 2 or 3 to ground will result in a part of A, B or C respectively:

| I/O line | Pin | Part |
|---|-----|---|
| ACC_IO_1 |  9  |  A |
| ACC_IO_2 |  4  |  B |
| ACC_IO_3 |  8  |  C |
| GND |  5  | |

### BluetoothRemoteKeypress (key)
See bluetooth_fire.lua for an example of this.

If `bluetooth_remote_passthrough = true` is present in the config section, key presses from a [connected bluetooth remote](./Bluetooth.md) are passed through to this function, instead of using the mappings configured in the bluetooth menu. Key will be one of:
* "`KEY_BUTTON`"
* "`KEY_UP`"
* "`KEY_DOWN`"
* "`KEY_LEFT`"
* "`KEY_RIGHT`"
* "`KEY_SHUTTER`"
* "`KEY_UNKNOWN`"

Note that unlike `SoftButton` and `ExternalTrigger`, there is only a single event, i.e. not pressed followed by released.

If `bluetooth_remote_passthrough = false` (or is absent), this function is never called, and key presses from a connected bluetooth remote are interpreted according to the configured mappings. E.g. if SHUTTER is mapped to "`Top left soft`", pressing the shutter button will cause `SoftButton(true)` immediately followed by `SoftButton(false)` to be called.

### BluetoothHidEvent (usage_page, usage, value)
Allows the ZC95 to receive events from custom bluetooth devices. See `bluetooth_hid.lua` and the example BT project that can be paired with the ZC95 and use this functionality [HidExample](../misc/Bluetooth/HidExample/).

When paired to bluetooth HID device, this method will be called for each event received. If you value your sanity, I would suggest not attempting to write Lua scripts to support miscellaneous bluetooth devices unless you're particularly familiar with bt (I'm not) and _exactly_ what the device in question is sending. 

### SerialData(data)
If serial enabled, is called whenever serial data is received. See "Serial I/O" section.

### AudioIntensityChange(left_chan, right_chan, virt_chan)
Receive audio data from aux socket.

See audio section later.

### Setup()
Called once when the pattern is started, before `Loop()`. It can be used to do any initial setup, including setting power level. If this function does _not_ exist, the power level is defaulted to 1000, otherwise it is set to 0 and can be set to something more appropriate here. 

### Loop(time_ms)
Called periodically for as long as the pattern is running. `time_ms` is how long in milliseconds the box has been powered on, and since v1.7 is a floating point number with microsecond precision. 

`Loop()` is called as often as possible by default, but how often will depend enormously on how much work is done in the Loop() function - expect an empty Loop() to be called around every 50us, and a complex loop() to be called closer to every 4000us (or more).

If a specific frequency is required (rather than just as often as possible), a `loop_freq_hz = n` option can be added to the `Config = {}` block, where `n` is between 1 and 400. Be aware that for particularly complex scripts, higher values are unlikely to work well - and note that this setting will only reduce how often Loop() is called when compared to the default.

## Audio
Lua scripts can be made to react to audio intensity/volume changes when being ran locally, or over Wifi.

To use audio support:
* Configure the box for audio as per the usual [audio operation](./AudioInput-Operation.md) notes, and confirm that the inbuilt `Audio intensity` pattern is working as expected
* Set `audio_processing_mode = "AUDIO_INTENSITY"` in the script `Config` section
* Optionally, add a `AUDIO_VIEW_INTENSITY_STEREO` or `AUDIO_VIEW_INTENSITY_MONO` menu item. Only useful if the script isn't being ran remotely
* Implement `function AudioIntensityChange(left_chan, right_chan, virt_chan)` in the script to receive audio data

### Microphone input
With the [microphone pre-amp enabled](./AudioInput-Operation.md), the amplified signal will be present in the `left_chan` value. `right_chan` will have the same signal, but without the mic pre-amp so will be much weaker - likely unusablely so - therefore should be discarded. For microphone input, if a waveform display is desired a `AUDIO_VIEW_INTENSITY_MONO` menu item should be added.

### Line input
With the [microphone pre-amp disabled](./AudioInput-Operation.md), the line level signal will be present in `left_chan` and `right_chan` for the left and right audio channels respectively. 
If the signal is expected to be stereo, a stereo waveform display can be shown by adding a menu item with the type `AUDIO_VIEW_INTENSITY_STEREO`.

### AudioIntensityChange(left_chan, right_chan, virt_chan)
With `audio_processing_mode = "AUDIO_INTENSITY"` in the `Config` section of the script, it is expected that a `AudioIntensityChange` function will be present to receive audio volume/intensity changes. 

The `left_chan` and `right_chan` parameters are for the left and right audio channels respectively. The `virt_chan` is an attempt a simulating a triphase effect on a separate logical channel, and probably isn't much use - I suggest ignoring it for now.

All values sent to these functions will be 0-255, so if used to modulate the output power of a channel, will need to be scaled to 0-1000.

### Example
The `audio.lua` script shows an example of audio support assuming microphone input. Channels 1 & 2 are on constant at the default pulse width/frequency, and channels 3 & 4 react to volume changes

## TriPhase
The ZC95 now has _limited_ triphase support from Lua.

As recap, "triphase" is where two channels are linked together with a common electrode. There is a good description of it on [Joanne's Reviews](https://www.sexmachinereviews.co.uk/estim-systems-triphase-cable-review.html). Due to the interactions between channels, it is more important to **not make any connections above the waist with triphase enabled.**

In normal operation, the ZC95 will never generate two pulses at same time - if the channels have been configured with frequencies that would cause two pulses to overlap, one is delayed. This is done as pulses overlapping in an uncontrolled/unintended manner can cause unexpected spikes if electrodes are in close proximately, and certainly if two have been joined together in a triphase configuration.

The triphase support is used to allow the ZC95 to intentionally generate pulses that overlap, but in a controlled manner with consistent results. 

At present, it only allows one channel to be linked to another, where a pulse on the linked linked channel is generated with a set overlap with the lead channel (further options likely to follow in the future).

### Setup
Before triphase can be used, the Config section must include `allow_triphase = true` - without this the triphase commands will be ignored. Setting this flag causes the pattern to be displayed prefixed with a `(!)` on the menu, as a warning that it uses triphase / disables channel isolation.

With that set, `zc.EnableTriphase(true)` can then be called - the best place is probably in the `Setup` function, but it can be anywhere. With triphase enabled, the ZC95 will no longer do anything to stop pulses being generated at the same time, regardless of where the pulses are coming from. So be careful - even unlinked channels will start generating pulses that can overlap if the frequencies set will cause them to clash. For the time being, it's probably best to stick to 2 channels when using triphase until it's expanded to be more configurable.

Finally, link two channel together using `zc.LinkChannels`, e.g. running `zc.LinkChannels(1, 2, 0)`, will link channel 2 to channel 1 (lead channel), and cause a pulses to be generated on channel 2 at the same time as pulses on channel 1. 
Changing the pulse width & frequency of channel 1 will affect channel 2. Once linked, only the power level of the linked channel should should be changed.

### Example
See [trifade.lua](../source/zc95/LuaScripts/trifade.lua) for an example Lua script that enables triphase, then continually alters the offset between to the two channels at a speed set from the menu.

A graphic example of what's happening may help.

With channel 1 and 2 linked, using the default pulse width of 150, at three different offsets:

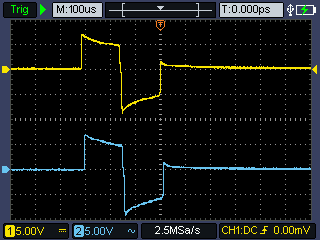
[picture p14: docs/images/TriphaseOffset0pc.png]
offset 0


*0% Offset* - No offset; the pulses on the linked channels are generated at the same time (result of `zc.LinkChannels(1, 2, 0)`)

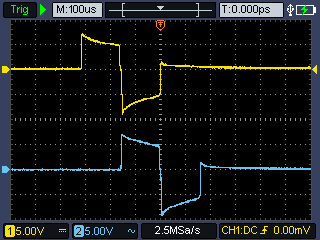
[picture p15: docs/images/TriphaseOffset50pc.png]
offset 50


*50% Offset* - the pulse on the linked channel starts half way through the pulse on the lead channel (result of `zc.LinkChannels(1, 2, 50)`)

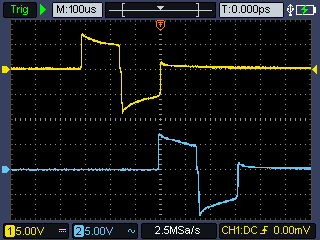
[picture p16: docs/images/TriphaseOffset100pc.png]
offset 100


*100% Offset* - the pulse on the linked channel starts as the pulse on the lead channel finishes  (result of `zc.LinkChannels(1, 2, 100)`)

## Serial I/O
If enabled in the `Config` block, Lua scripts can interact with devices connected via serial on the **Accessory** port.

To enable, include a serial block in `Config`, e.g:
```
    serial = {
      enabled = true,
      parity = "NONE",
      stop_bits = 1,
      baud = 9600,
      line_mode = true
    }
```

Fields:
* `enabled` - enables serial access. Defaults to false.
* `parity` - valid options are `ODD`, `EVEN` or `NONE` (default)
* `stop_bits` - valid options are 1 or 2. Defaults to 1.
* `baud` - Only tested with 9600 and 115200, but all common rates between at least 150 and 115200 should work. Defaults to 115200.
* `line_mode` - If true, received data is buffered until CR is received, then passed as a full line to the scripts `SerialData` function. If false, `SerialData` is called as data is received (can be 1 or a few characters at a time). When true, a CR is appended to any data sent using `zc.AccSerialWrite()`. Defaults to true.
    
    **Important**: with `line_mode = true`, any lines longer than 300 characters are discarded.

Where a field is omitted, the default is used.

When serial is enabled, it is expected that a 'SerialData` method will exist to receive serial data, e.g. to output received data:
```
function SerialData(data)
  print("> " .. data)
end
```

To send serial data, use the `zc.AccSerialWrite(<data>)` method, e.g.: `zc.AccSerialWrite("Hello world");`.

[acc port]: images/lua_acc_port.png "Accessory port"
[offset 0]: images/TriphaseOffset0pc.png "zc.LinkChannels(1, 2, 0)"
[offset 50]: images/TriphaseOffset50pc.png "zc.LinkChannels(1, 2, 50)"
[offset 100]: images/TriphaseOffset100pc.png "zc.LinkChannels(1, 2, 100)"

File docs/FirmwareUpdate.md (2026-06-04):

# Updating the firmware

The quickest way to update the firmware will always be the same process as originally flashing it - i.e. pull out the Picos, hold down the button, connect to usb, release the button, then copy over the appropriate uf2 file and reinstall in the zc95 after it completes. 

As an alternative, from F/W 2.1 onwards, there is bootloader present which allows the firmware to be updated using a USB to Serial cable plugged into the 3.5mm serial socket, then using the firmware upload tool in this repo.

This won't be of any practical use until F/W v2.2 as v2.1 will still need to be installed by direct connection to the picos via USB.

## Updating via serial

Download the most recent firmwares (zc95.uf2 and OutputZc.uf2) from the [Releases](https://github.com/CrashOverride85/zc95/releases) page.

From the [`misc/firmware_uploader`](../misc/firmware_uploader/) directory, run `python3 -m firmware_uploader.ui`. You might need to either run `pip install .` in that directory first, or if on Debian/Ubuntu, something like `apt-get install python3-xmodem python3-serial python3-tk`.

The tool should appear:

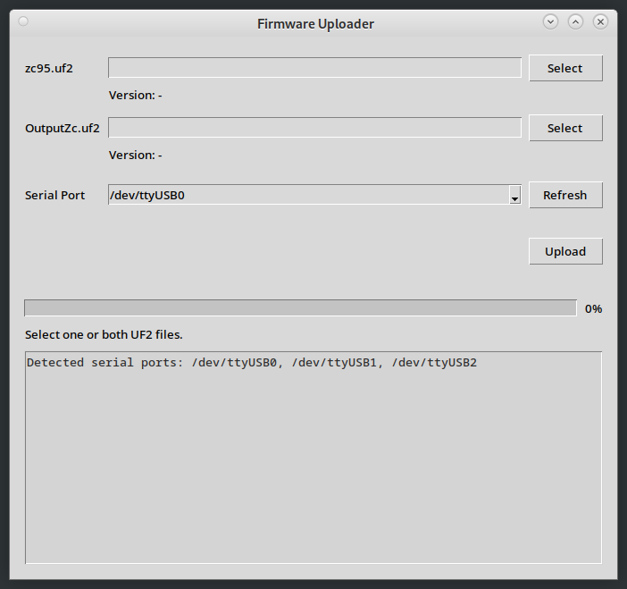
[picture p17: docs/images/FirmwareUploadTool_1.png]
Firmware upload tool


Select the zc95.uf2 and OutputZc.uf2 files downloaded from the [Releases](https://github.com/CrashOverride85/zc95/releases) page, and pick the serial port of the USB <> Serial cable.

**Note**: Versions 2.0 and older will be rejected with the error `xxx.uf2 is not a valid firmware image`.

Connect the zc95 leaving it switched off, click `Upload`, _then_ turn on the zc95. The upload should start within a few seconds. Expect the process to take 4-5 minutes, and for the first 1% to take longer than it should. 
All going well, after it completes you should get a `Firmware upload completed successfully` message, and the new firmware started on the ZC95.

If the update process gets interrupted, the zc95 likely won't boot, or will show an error. Just try again - this upload process can't update the bootloader, so it'll still be present to have another go.

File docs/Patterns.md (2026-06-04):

# Patterns

**Note**: Any pattern in the list/menu prefixed with `(!)` should not be used above the waist, as channel isolation - where only one channel pulses at the exact same moment - is disabled.

## Waves
Gradually increasing and decreasing intensity on all channels at different rates. Varying intensity is achieved by altering the gap between pulses rather than changing the power level.
Can NOT be used with shock collars.

### Menu options
* Frequency - controls how fast the intensity increases/decreases. 1-64, lower is faster.

## Orgasm
Pleasurable increasing and decreasing sensation, achieved by varying both pulse width and frequency. A full cycles takes a few minutes.

### Menu options
* Frequency - controls how fast the intensity increases/decreases. 15-255, lower is faster.

## Climb
Gradually increasing intensity.

### Menu options
* Frequency - controls how fast the intensity increases/decreases. 15-255, lower is faster.

## Phasing 2
An intensity ramp program, note that this is not triphase.

### Menu options
* Pulse Speed 

## Stroke
Channels 1+3 pulse to full set power, gradually reduce, then switch off. Channels 2+4 gently pulses around the present power level.

### Menu options
* Speed - lower is faster

## Rhythm
Outputs are enabled/disabled, with both the frequency and pulse widths changing.

### Menu options
* Spikeyness

## Torment
Short, activation of channels 1+3 and 2+4 and random intervals.

### Menu options
* (none)

## Combo

A mix of difference effects

### Menu options
* Speed - lower is faster

## Random 2

A mixture of different randomised effects, including varying pulse widths, frequency and power.

### Menu options
* (none)

## Intense
Continuous output on channels 1 & 2, with 3 & 4 switching/toggling. 

### Menu options
* Toggle delay - Delay between switching from channel 3 to 4 and back 100ms - 1000ms
* Chan 1&2 freq - Output frequency of channel 1 & 2
* Chan 3&4 freq - Output frequency of channel 3 & 4

## TriFade
Triphase effect - fades triphase effect in and out at the selected speed.

Only uses channel 1 & 2, and assumes they are connected together with a common electrode. Without the common electrode, the triphase effect won't be felt.

### Menu options
* Cycle time - controls how long, in milliseconds, it takes for a full cycle/fade in-out. Lower is faster.

*Warning*: Enables triphase mode / disables channel isolation, so should not be used above the waist. 

## Toggle
Switches between Channel 1+3 and 2+4. 
Can be used with shock collars.

### Menu options
* Speed - controls how fast it switches between 1+3 and 2+4. Higher is faster.
* Pulse/Cont.
  - Pulse - gives a brief (100ms) pulse on each channel
  - Continuous -  keeps the channel on until it's time to switch to the next

## RoundRobin
Cycles through channels 1->2->3->4.
Can be used with shock collars.

### Menu options
* Delay - How long (in ms) to wait before switching to the next channel. Lower is faster.
* Pulse/Cont.
  - Pulse - gives a brief (100ms) pulse on each channel
  - Continuous -  keeps the channel on until it's time to switch to the next

## TENS
Approximation of TENs style output, with all channels outputting the same.
Can NOT be used with shock collars.

### Menu options
* Mode - one of:
  - Burst - bursts of pulses at the rate configured by the "Burst frequency" option
  - Constant - continuous output at configured frequency / pulse width
  - Pulse rate mod - Pulse rate (frequency) modulation. The same as constant, except the frequency is varied between the configured frequency and 40% less
  - Pulse wid mod 40% - Pulse width modulation. The same as constant, except the pulse width is varied between the configured pulse width and 40% less
  - Pulse wid mod 70% - Pulse width modulation. The same as constant, except the pulse width is varied between the configured pulse width and 70% less

* Frequency - Frequency in Hz of signal, 20hz - 150hz. Most other modes use 150Hz
* Pulse width - Pulse width in microseconds. 10 - 255 us. Lower is weaker. Most other modes use 150us.
* Pulse type - Biphasic or Monophasic output. Other patterns generate Biphasic output, most TENS units generate Monophasic output
* Burst frequency - 0.1hz - 5hz. Applies only in "Burst" modes

## Triggered Climb
Power increases on channels 1+2 until a remote button is pressed, then a pulse is delivered on channels 3+4, and 1+2 is reset. Every time the button is pressed the shock delivered on channels 3+4 is increased.
Suggest bipolar nipple clamps for channels 3+4, 1-2 anywhere else, then handing the button to the person connected.
Channels 3+4 can be shock collars. Unlike Climb, this achieves increasing intensity by varying the power level (as can be seen on the display).

### Menu options
* Climb Duration - Approximately how long, in seconds, it takes to reach full power on channels 1+2
* Shock increment by - How many percentage points to increase the power level on channels 3+4 by every time the remote button is pressed (e.g. if the current power was 20%, a setting of "10" would mean increase from 20% -> 30%). Can be set to zero.
* Shock duration - How long, in milliseconds, should the shock delivered on channels 3+4 last.
* Soft button "Reset" - Reset power levels back to zero

### Extra hardware required
A remote button wired to trigger input 1.

## Fire
When either soft button or a remote button is pressed, trigger a shock on all channels.
Can be used with shock collars.

### Menu options
* Mode
  - Continuous - shock is delivered for as long as the button is held down
  - Pulse - a shock of preset (see below) length is delivered when the button is pushed
* Pulse length - When in pulse mode, how long, in milliseconds, the pulse should be
* Soft button "Fire" - deliver shock

### Extra hardware required
Optional: A remote button wired to trigger input 1 can be used as an alternative to the Fire soft button

## Audio Threshold
Only available if audio enabled. 
If the volume goes above the level set, triggers the output on all 4 channels. Intended to be used with a microphone.

### Menu options
* Audio trigger - Shows mini spectrum analyzer, with a horizontal red line that can be moved up/down using the adjust dial. Whenever the volume is loud enough to cross the line, the output is triggered.

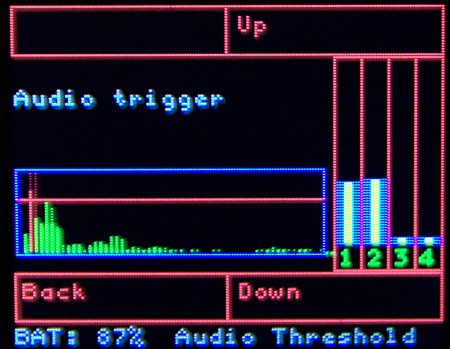
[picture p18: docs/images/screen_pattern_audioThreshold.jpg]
Audio Threshold


### Extra hardware required
Audio output board fitted and audio source

## Audio Wave
Only available if audio enabled. 

Well suited to estim audio tracks, with the audio [configured](./AudioInput-Operation.md) for line level input. It works with a triphase setup, where two channels are connected with a common electrode. Both frequency and volume of audio input affects the output.

The left audio channel is output on channels 1+2, the right on 3+4. It probably makes most sense to only use channel 1+3 (or 2+4) with this mode. 

*Warning*: Enables triphase mode / disables channel isolation, so should not be used above the waist. 

### Menu options
* Stereo view - Shows two wave forms - for left and right channels. 
* Triphase view - Shows three wave forms - left, right and a virtual / calculated triphase effect.
* Range - affects how much the input signal affects the output. 1%-100%. 100% (default, fixed <= v2.0 behaviour) means a strong signal is full power and weak signal is minimum power. 50% means a strong signal is full power but a weak signal is half power. No input signal always results in no output.

Note that the selected view does not affect the output, and the indicated triphase effect will only be felt if channel 1+3 (or 2+4) have a common electrode. The adjust dial changes the gain, which is displayed on the thin yellow bar at the bottom of the waveform display.

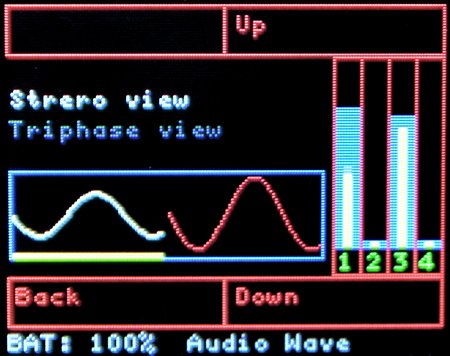
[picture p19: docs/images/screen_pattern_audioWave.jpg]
Audio Wave Stereo


### Extra hardware required
Audio output board fitted and audio source

## Audio intensity
Only available if audio enabled. 

Intended for use with a microphone (see [audio config](./AudioInput-Operation.md) to switch to mic mode), but also allows for stereo input. 

The louder the sound, the greater the output. Not much more to this pattern.

### Menu options
* Mono - Shows one waveform corresponding to the left channel, and all output channels are the same intensity depending on the input from the left channel
* Stereo - Shows two waveform corresponding to the left and right channels. Output channels 1+2 have an intensity corresponding to the left channel, and channels 3+4 have an intensity corresponding to the right channel

The adjust dial changes the gain, which is displayed on the thin yellow bar at the bottom. 

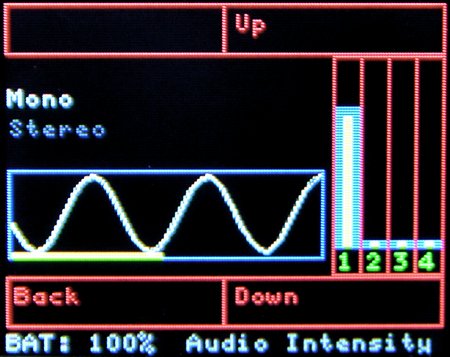
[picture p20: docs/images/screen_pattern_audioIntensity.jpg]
Audio intensity mono


### Extra hardware required
Audio output board fitted and audio source

## Audio virtual 3
Only available if audio enabled. 

Well suited to estim audio tracks, with the audio [configured](./AudioInput-Operation.md) for line level input. Generates a 3rd channel from the difference between the left and right channels, and outputs it on channel 3 (channel 4 is not used).

Unlike the "Audio Wave" pattern, this does not disable channel isolation, so could be used above the waist with suitable electrode placement (usual warnings still apply). This also means the channels should *not* be connected with a common electrode.

### Menu options
* Audio view - Shows three wave forms - left (channel 1), right (channel 2) and simulated "triphase" effect (channel 3).

The adjust dial changes the gain, which is displayed on the thin yellow bar at the bottom. 

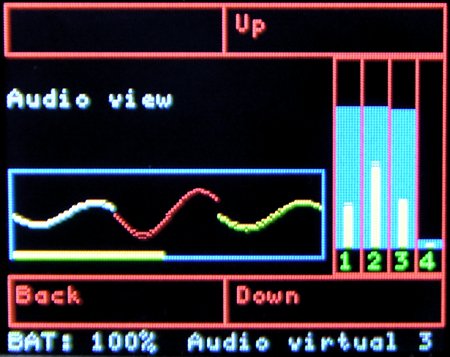
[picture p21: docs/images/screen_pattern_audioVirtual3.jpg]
Audio virtual 3


### Extra hardware required
Audio output board fitted and audio source

## Climb with pulse
Channels 1+2 behave the same as Climb, but when full intensity is reached, channels 3+4 are enabled/pulsed (depending on mode).
Channels 3+4 can be shock collars.

### Menu options
* Duration - Approximately how long, in seconds, it takes to reach full power
* Reset after climb
  - Yes - once full power is reached, start over
  - No - once full power is reached, stay there
* Pulse duration - how long, in milliseconds, the pulse delivered on channels 3+4 should be
* Soft button "Reset" - Reset power levels back to zero

## Predicament
Designed for predicament bondage scenarios. I'm finding this difficult to explain, so hopefully some examples will help.
Requires at least one input, ideally two, connected to the Trigger1 & Trigger2 ports. Based on the settings, delivers a shock
based on which inputs have been triggered.
For example, if two foot pedals are used, it can deliver a shock unless both are kept pressed (this is the default settings).

### Menu options
(assumes a Normally Open switch connected to both trigger inputs)
* Trigger1 invert - If "yes", the rest of the logic assumes that trigger1 is high if *not* pressed
* Trigger2 invert - As above, but for trigger 1
* Logic - "Or" or "And". If "Or", then either trigger being high will result in shock. If "And", both need to be high for a shock
* Output invert - Inverts the result of the above. I.e. if set to yes and "And" is set for Logic, then with both triggers high no shock is delivered

### Examples
| Trigger1 inv | Trigger2 inv | Logic | Output inv | Description  
| --- | --- | ----- | --- | ---
| No | No | And | Yes | Default. Shock if either button not pressed
| No | No | And | No | Shock if both both buttons pressed
| No | No | Or | No | Shock if either button pressed
| Yes | Yes | Or | No | Shock if either button not pressed (different way achieving the default behavior)
| No | No | Or | Yes | If only one button connected to trigger1, shock when it is not pressed

### Extra hardware required
Yes - Sensors (e.g. foot pedals) connected to trigger inputs 1 & 2

## Shock choice
Gives the subject a choice of where to receive a shock, with no decision resulting in both (and for longer).

Requires a remote button connected to each of the two trigger inputs.

Every _Choice frequency_ seconds, channel 4 is briefly pulsed as an indication that a choice needs to be made (channel 4 being configured as a shock collar in "beep" mode works well). If button A is pressed, a 0.5s shock is delivered on channel 1. If button B is pressed a 0.5s shock is delivered on channels 2+3 (think a pair of bipolar nipple clamps). If no choice is made within 3 seconds, a 1s shock is delivered on channels 1, 2 & 3.
Each time a shock is delivered, the power level for that channel(s) is increased.

### Menu options
* Choice frequency - How often, in seconds, does a shock need to be delivered
* Shock increment by - How many percentage points to increase the power level on channels 3+4 by every time the remote button is pressed (e.g. if the current power was 20%, a setting of "10" would mean increase from 20% -> 30%). Can be set to zero.
* Soft button "Reset" - Reset power levels back to zero

### Extra hardware required
Remote buttons wired to trigger inputs 1 & 2.

## Camera Trigger
When the "Trigger" soft button is pressed, a shock is delivered on all channels, then a preset amount of time later ACC_IO_1 (pin 9 on the DB9 socket) is pulsed low. The intention is for this to be connected to a remote camera trigger.
At present, there is a hard-coded assumption that the camera will take 300ms to react to the pulse (this was the case for me using a cheap wireless camera trigger).
This is only really practical if the camera is in manual focus mode.

### Menu options
* Shock Length - how long, in milliseconds, the shock should be
* Camera delay - how long to wait after delivering the shock before taking a photo. Note that if set to zero, ACC_IO_1 will be pulsed low 300ms _before_ the shock is delivered: i.e. assuming a 300ms response time from the camera should mean that the photo is taken as the shock is delivered. For good results, 500ms seems to work well.
* Soft button "Trigger" - deliver shock and take photo

### Extra hardware required
Something connected to the accessory port that triggers a photo on pin 9 being pulsed low.

## Buzz
Intended to be used with a buzz wire game, probably better explained with a photo:

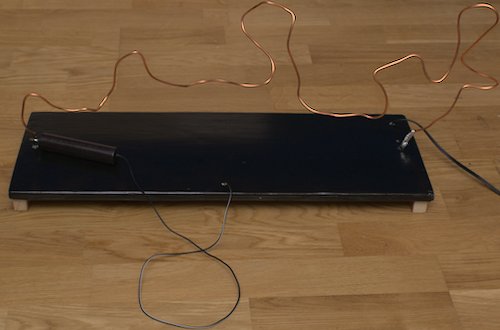
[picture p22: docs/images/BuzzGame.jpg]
Buzz wire game


Whenever the wand touches the wire, a shock is delivered on channels **3+4**. The shock level increases as the wire is touched.
As an option to make things more interesting, channels 1+2 generates a slowly increasing power level, to hurry things along a bit - although probably not worth the effort of connecting.

The game finishes (all outputs go to zero) when the wand is used touch a contact at the end.

Note: This mode works well enough when just channel 3 (or 4) is used with a pair of pads.

### Menu options
* Game length - how long, in seconds, it takes channels 1+2 to reach full power
* Shock increment - How many percentage points to increase the power level on channels 3+4 by when the wand touches the wire. Can be set to zero.
* Initial shock power - percentage power level shock delivered on channels 3+4 starts at
* Min shock length - the minimum length, in milliseconds, of the shock delivered on channels 3+4. The shock will continue to be delivered for as long as the wand touches the wire, this only sets the minimum duration that applies to brief touches
* Soft button "Start" - starts the game: channels 1+2 are switched on and start increasing, and touching the wand against the wire results in a shock from channel 3+4

### Extra hardware required
Yes! Trigger input 1 needs a stereo Tip, Ring, Sleeve (TRS) 3.5mm plug wired as follows:
* Tip = wand (common ground)
* Ring = contact at end of wire (green)
* Sleeve = wire (red)

Alternatively, the accessory socket can be used for input - use ACC_IO_1 for the contact at the end, and ACC_IO_2 for the wire.

[Buzz wire game]: images/BuzzGame.jpg "Buzz wire game"
[Audio Threshold]: images/screen_pattern_audioThreshold.jpg "Audio Threshold"
[Audio Wave Stereo]: images/screen_pattern_audioWave.jpg "Audio Wave"
[Audio virtual 3]: images/screen_pattern_audioVirtual3.jpg "Audio virtual 3"
[Audio intensity mono]: images/screen_pattern_audioIntensity.jpg "Audio intensity mono"

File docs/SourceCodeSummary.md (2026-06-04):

# ZC95 source

## Summary
* `zc95Bootloader` - bootloader for the zc95. This builds `zc95Bootloader.bin`, which is included by the main zc95 project, so no need to upload the bootloader separately (although it can be).
* `zc95` - main ZC95 source code. Copies in the zc95Bootloader, so that needs to be built first.
* `zc624Bootloader` - Same as `zc95Bootloader`, except for the zc624 (output) pico
* `zc624` - main zc624 source. Copies in the zc624Bootloader, so that needs to be built first.
* `common` - header files that are shared between the above 4 projects. Include hardware config for the zc95 & zc624 which will be common with their respective bootloaders, and i2c message details for communication between zc95 & zc624.

If you're looking to make changes to patterns, the UI etc, the `zc95` source is almost certainly the one you want.

## zc95Bootloader
The bootloader is designed to allow the main firmware (zc95 & zc624) to be updated without having to open the case, by using serial or SD card (a future version of the zc95 firmware should manage downloading to SD).
Updating the bootloader itself still requires a direct USB connection to the Pico; although a benefit of that is that it should be extremely difficult to get the zc95 into a state where it can't be updated via serial.

### Main features
* Accessed using the 3.5mm serial connector, with some debug (output only) on the accessory port
* Menu driven, or API access from the firmware upload tool
* Can backup current firmware (zc95 & zc624) to an SD card, and copy a pending firmware from SD to flash
* An EEPROM flag can be set which triggers the bootloader to update the firmware from SD card
* Checks the ZC624 firmware version is compatible with the zc95 firmware on startup. If it's not, and a compatible version can be found on the SD card, the zc624 is updated to use that.

### Memory map
The image below shows the flash part of the memory map of the zc95, and where the bootloader fits in:

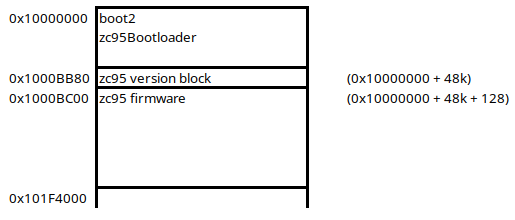
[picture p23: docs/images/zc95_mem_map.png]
zc95mem


When the zc95 firmware is built, instead of including the standard Pico boot2 bootloader, it includes zc95Bootloader (which has boot2 at the start). This means the resulting uf2 file can be copied straight to the Pico, without having to upload the bootloader, then use that to upload the zc95 firmware.

### Firmware upload process
Steps to prepare and upload a firmware to the zc95 without using the python tool, and the general overview of what happening:

#### zc95
1. Build the zc95 firmware as usual

2. Use the generated `zc95.bin` file from the build directory, or use a uf2 to bin converter (what the upload tool does)

3. Remove the first 48k bytes of the file, e.g.: `dd if=./zc95.bin of=./zc95.for_upload.bin bs=1 skip=48k`
  
   This is to strip off the bootloader, which can't be updated via serial.

4. Use a serial terminal which supports XMODEM (minicom is good here), connect to the 3.5mm serial connector on the zc95, set to 115200 8N1

5. Hold down ESC, and power on the box, after a banner showing the version, you should see a menu

6. Pick `[ 1 ] Manage ZC95 firmware`, then `[ 5 ] Upload f/w direct to flash`

7. In the serial terminal, start an XMODEM/CRC transfer of the `zc95.for_upload.bin` file

  After a few moments, the transfer should start. After the first block is received, the bootloader will wipe all flash after the first 48k used for the bootloader, then start writing the received file 256 bytes at a time. The very first 256 bytes of the file is buffered, and only written at the end after the transfer completes; this hopefully ensure partial transfers result in a non-booting box, rather than an unstable box.

  After the transfer is completed, the menu is re-displayed, and `[ 7 ] Launch f/w` can be used to start the new firmware.
  If the firmware is invalid / corrupt, power cycling the box will result in it staying in the bootloader (left and right most LEDs illuminated purple), showing an error on the 3.5mm serial connection, then showing the menu.

  The bootloader can detect obviously bad firmware by looking at the first 128 bytes. This is a version block which includes a version string, compatible zc624 versions, and a magic 32bit value that must be present.
  This is enough to protect against the wrong file being uploaded, but more subtle errors won't be picked up and it'll try to start it.

#### zc624
Essentially follow steps 1-7, but pick the zc624 option from the menu.

The bootloader will then check the zc624 is still in bootloader mode, send a flash erase command over i2c, then start transferring the received firmware in 128 byte blocks as received via XMODEM. Like with the zc95, it will buffer the first 256 byte block and write that last.

## zc624Bootloader
Similar in structure - i.e. same memory map, but there is no way of directly interacting with it. It receives instructions via i2c from the zc95Bootloader, doesn't have access to a SD card and is generally much simpler.

[zc95mem]: images/zc95_mem_map.png "zc95 memory map"

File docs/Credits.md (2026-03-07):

## Credits

The ZC95 is built on top of many great libraries and bits of other code. Hopefully I've managed to list all of them here.

In addition to code, the hardware - in particular the estim output section - draws very heavily on the design of the MK312-BT.

----

### Library/code:
hagl & hagl_pico_mipi - Hardware Agnostic Graphics Library & Pico HAL

### License:
    MIT License

    Copyright (c) 2021 Mika Tuupola

### URL:
https://github.com/tuupola/hagl

https://github.com/tuupola/hagl_pico_mipi

### Use:
Everywhere! - Display driver

----

### Library/code:
ESP32 FFT

### License:
MIT License

    This code was written by [Robin Scheibler](http://www.robinscheibler.org) during rainy days in October 2017.
    "Classified" for ESP and ARduino by M. Steltman Mey 2021

### URL:
https://github.com/yash-sanghvi/ESP32/issues/1

https://github.com/yash-sanghvi/ESP32/files/6474828/ESPfft.zip

### Use:
Spectrum analyzer in the "Audio Threshold" pattern

----

### Library/code:
picow-wlan-setup-webinterface

### License:
    * Author: Floris Bos
    * ### License: public domain / unlicense

### URL:
https://github.com/maxnet/picow-wlan-setup-webinterface
 
### Use:
Forms the base of the WiFi AP mode and configuration, including QR code and Web interface to set SSID/PSK. Whilst not a library, large parts (including the web interface) are mostly used as-is

----

### Library/code: 
LWIP HTTP server implementation

### License:
BSD-3-Clause

    * Copyright (c) 2001-2003 Swedish Institute of Computer Science.
    * All rights reserved.

    * Author: Adam Dunkels <adam@sics.se>
    *         Simon Goldschmidt

### Use:
HTTP server used both when in AP mode for WiFi setup, and when connected to Wifi for the websocket server. Modifications:
 * In AP mode, returns a "HTTP/1.1 511 Network Authentication Required" response which causes phones (only tested on an iPhone so far) to automatically display the web config page on connecting, instead of having to either enter an address, or browse to a non-https page first.
 * Websocket support - see below

----

### Library/code: 
esp-httpd - for websocket support

### License:
As per lwIP httpd

### URL:
https://github.com/lujji/esp-httpd

### Use:
Websocket server when connected to WiFi. Websocket code extracted and patched into the Pico version of the httpd server, then modified to support websocket pings (opcode 0x09).

----

### Library/code: 
RFC 1521 base64 encoding/decoding
    
### License:
    *  Copyright (C) 2006-2015, ARM Limited, All Rights Reserved
    *  SPDX-License-Identifier: Apache-2.0
 
### Use:
Websocket implementation

----

### Library/code: 
sha1

### License:
BSD-3-Clause
    
     Copyright (c) 2011, Micael Hildenborg
     All rights reserved.
 
### URL:
https://github.com/daviswalker/smallsha1
 
### Use:
Websocket implementation

----

### Library/code: 
QR Code generator library (C)

### License:
    Copyright (c) Project Nayuki. (MIT License)
### URL:
https://www.nayuki.io/page/qr-code-generator-library

### Use:
Generating QR code used to provide network details when in AP mode for WiFi setup

----

### Library/code: 
dhcpserver - part of the MicroPython project

### License:
    * The MIT License (MIT)
    * Copyright (c) 2018-2019 Damien P. George

### Use:
DHCP server used when running in AP mode

----

### Library/code: 
dnsserver 

### License:
    * The MIT License (MIT)
    * Copyright (c) 2015 by Sergey Fetisov <fsenok@gmail.com>
  
### Use:
DNS server used when running in AP mode
    
----

### Library/code:
ArduinoJson

### License:
The MIT License (MIT)

    Copyright © 2014-2022, Benoit BLANCHON

### URL:
https://arduinojson.org/
 
### Use:
Serializing and deserializing JSON based websocket messages

----

### Library/code: 
Lua 5.1.5

### License:
    MIT License

    Copyright (C) 1994-2012 Lua.org, PUC-Rio.  All rights reserved.

### URL:
https://www.lua.org
 
### Use:
Running uploaded Lua scripts

----

### Library/code: 
Lua CMake files

### License:
?

### URL:
https://github.com/walterschell/Lua
 
### Use:
Building Lua with CMake. Note above URL includes Lua 5.4.4, but has been tweaked to build Lua 5.1.5

----

### Library/code: 
Lua-5.1.5-TR - Lua 5.1.5 with tiny ram patch
    
### License:
    MIT License
    Copyright (c) 2021 Vincent Hamp

### URL:
https://github.com/higaski/Lua-5.1.5-TR
 
### Use:
Running uploaded Lua scripts

----

### Library/code: 
BQ27441 LiPo Fuel Gauge
    
### License:
    * Apache-2.0 license 
    * Copyright (c) 2020 Vitaliy Nimych (Cvetaev) @ cvetaevvitaliy@gmail.com

### URL:
https://github.com/cvetaevvitaliy/bq27441
 
### Use:
Battery monitoring

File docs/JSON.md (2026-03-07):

# JSON interface

The ZC95 can be controlled remotely using a JSON based interface over either serial or a WiFi/Websocket connection.

Consider this a work in progress, with the messages subject to change for the time being.
These messages primarily exist to allow the supplied python utilities (see [Remote Access](./RemoteAccess.md)) to interact with the box, and have been available since firmware version 1.4.

These allow for Lua scripts to be uploaded, deleted, started, and controlled. Unlike a [BLE connection](./BleStreaming.md), it does not allow direct control of the estim output / per pulse control. It can be used to manage the scripts on the box, and start + control a script.

The messages sent are the same regardless of connection method.

## Connection method
### Websocket
After configuring WiFi and connecting, connect to the box on `ws://<ip>:80/stream`. There is a fairly short timeout / idle disconnection period, so I would recommend setting a low ping interval on the connection - e.g. 6 seconds.

On disconnection, any running pattern will be stopped.

### Serial
Connect using 115200-8-N-1. All messages should be surrounded with STX (0x02) / ETX (0x03) characters, e.g. 

```<STX>{"Type": "GetLuaScripts", "MsgId": 3}<ETX>```

Messages sent from the ZC95 are also sent surrounded by STX/ETX. Any data received from the ZC95 not enclosed with STX/ETX should be ignored. 

An EOT (0x04) character can be sent at any point to reset the connection - this has much the same effect as disconnecting if using a web socket connection, and will stop any running pattern and reset power levels.

Consider sending an EOT, then waiting ~50ms, on first connection to make sure the ZC95 is in a known state. The python utilities currently don't do this. They probably should.

## States
The connection can be in one of three states, with the initial state being `ACTIVE`. The state affects which messages are valid.

![states diag]

The LUA_LOAD is used to upload a script, ROUTINE_RUN to run and control a pattern, and ACTIVE for everything else.

## Messages
### Structure
All messages sent should have at least these two fields:
* `Type` - type / name of message 
* `MsgId` - incrementing message counter. This will be present in the response from the ZC95

The ZC95 will respond to all messages sent to it, and at a minimum the response will include:
* `Type` - will either be specific to the request (e.g. if `GetLuaScripts` was sent, the response would have a type of `LuaScripts`), or just `Ack`
* `MsgId` - id of the message that it is a response to
* `Result` - Either `OK` on success, or `ERROR` on failure

On error, the response _may_ also include an `Error` field, which includes an error message with more details about the problem.

Some messages (e.g. power level change) will be sent by the ZC95 not linked to any request - these will have the `MsgId` set to `-1`, and will not include a `Result` field.

### Messages for state: ACTIVE
In the active state, these messages are recognised:

* GetLuaScripts
* DeleteLuaScript
* GetPatterns
* GetPatternDetail
* GetVersion
* LuaStart
* PatternStart

#### GetLuaScripts
Returns a list of all uploaded Lua scripts, e.g.:

Send:
```
{"Type": "GetLuaScripts", "MsgId": 3}
```

Response:
```
{
   "Type":"LuaScripts",
   "MsgId":3,
   "Scripts":[
      {
         "Index":4,
         "Empty":true,
         "Valid":false,
         "Name":"<empty>"
      },
      {
         "Index":3,
         "Empty":true,
         "Valid":false,
         "Name":"<empty>"
      },
      {
         "Index":2,
         "Empty":true,
         "Valid":false,
         "Name":"<empty>"
      },
      {
         "Index":1,
         "Empty":false,
         "Valid":true,
         "Name":"U:Test Script"
      },
      {
         "Index":0,
         "Empty":true,
         "Valid":false,
         "Name":"<empty>"
      }
   ],
   "Result":"OK"
}
```
Assume scripts array is unordered, as the order may change in future versions.

Fields:
- `Index` - script slot. Currently 0-4, may be extended in the future
- `Empty` - true if there is no script in the slot
- `Valid` - true if there is a script uploaded, and it parses ok
- `Name` - name of script as displayed on the zc95 scripts menu

#### DeleteLuaScript
Clears a Lua script slot, removing the script from the menu. It is _not_ necessary to call this before uploading a new script to an in-use slot.

There is no error when deleting an already empty script slot.

Send:
```
{"Type": "DeleteLuaScript", "MsgId": 5, "Index": 1}
```

Response:
```
{"Type":"Ack","MsgId":5,"Result":"OK"}
```

#### GetPatterns
Returns a list of all patterns that can be ran remotely - i.e. including uploaded scripts along with built in patterns.

Send:
```
{"Type": "GetPatterns", "MsgId": 4}
```

Response:
```
{
   "Type":"PatternList",
   "MsgId":4,
   "Patterns":[
      {
         "Id":0,
         "Name":"U:Test script"
      },
      {
         "Id":1,
         "Name":"Waves"
      },
      {
         "Id":2,
         "Name":"Orgasm"
      },
      {
         "Id":3,
         "Name":"Climb"
      }

      ....
   ],
   "Result":"OK"
}
```

#### GetPatternDetail
Get all details required to show an option screen for a specific pattern. Expects an `Id` parameter that corresponds to pattern id as returned in the `PatternList` message (i.e. not a slot number/index from the `LuaScripts` message).

The contents of the `PatternDetail` message is mostly generated from, and so closely related to, the Config block in Lua scripts.

```
{"Type": "GetPatternDetail", "MsgId": 6, "Id": 11}
```

Response:
```
{
   "Type":"PatternDetail",
   "MsgId":6,
   "Name":"Toggle",
   "Id":11,
   "ButtonA":"",
   "MenuItems":[
      {
         "Id":1,
         "Title":"Speed",
         "Group":0,
         "Type":"MIN_MAX",
         "Min":500,
         "Max":4000,
         "IncrementStep":50,
         "UoM":"mHz",
         "Default":2000
      },
      {
         "Id":2,
         "Title":"Pulse/Cont.",
         "Group":0,
         "Type":"MULTI_CHOICE",
         "Default":0,
         "Choices":[
            {
               "Id":0,
               "Name":"Continuous"
            },
            {
               "Id":1,
               "Name":"Pulse"
            }
         ]
      }
   ],
   "Result":"OK"
}
```

#### GetVersion
Used to query the zc95 for its version.

Send:
```
{"Type": "GetVersion", "MsgId": 2}
```

Response:
```
{"Type":"VersionDetails","MsgId":2,"ZC95":"v2.0-rc3-7-g052b00a","WsMajor":1,"WsMinor":0,"SerialNo":"E661640843703B2B","Result":"OK"}
```

The `ZC95` field holds the firmware version of the zc95 - this will match the text displayed in grey at the bottom of the ZC95 boot screen.

`WsMajor` is likely to be increased for breaking changes to this JSON interface, and the `WsMinor` for additional features. For time being, don't trust them, and consider everything on this page to be work in progress. At some point I'll start incrementing them, and keeping a proper change log for the messages.

#### LuaStart
Used to start the upload of a Lua script, and switch to the `LUA_LOAD` state on success. Expects an `Index` parameter, which is the script slot (0-4) to upload the following script to.

Send:
```
{"Type": "LuaStart", "Index": 0, "MsgId": 2}
```

Response:
```
{"Type":"Ack","MsgId":2,"Result":"OK"}
```

#### PatternStart
Used to start a pattern, and on success, switches to the `ROUTINE_RUN` state. Expects one parameter, `Index`, which is the script id (as returned in the `PatternList` message) to start.

Send:
```
{"Type": "PatternStart", "MsgId": 7, "Index": 1}
```

Response:
```
{"Type":"Ack","MsgId":7,"Result":"OK"}
```

### Messages for state: LUA_LOAD
Entered following a successful `LuaStart` message.
Used to upload a new Lua script. 

The expected sequence is:
- LuaStart
- 1 LuaLine message per line in the script
- LuaEnd

In this state, these messages are recognised:

* LuaLine
* LuaEnd

#### LuaLine
Send a line of a Lua script

Send:
```
{"Type": "LuaLine", "LineNumber": 0, "Text": "_delay_ms = 500", "MsgId": 3}
```

Response:
```
{"Type":"Ack","MsgId":3,"Result":"OK"}
```

Wait for the `Ack` for each line before sending the next `LuaLine` message.
`LineNumber` should be incremented for each line sent.

#### LuaEnd
Send after the final `LuaLine` message has been sent and Ack'd. Causes the zc95 to parse the script, and make it available in the Menu if it appears to be valid.

Even on failure, it is likely that the previous script in the target slot/index will have been removed.

Success or failure, the state will return to `ACTIVE` after this message.

Send:
```
{"Type": "LuaEnd", "MsgId": 90}
```

Response:
```
{"Type":"Ack","MsgId":90,"Result":"OK"}
```

### Messages for state: ROUTINE_RUN
This state is entered following a successful `PatternStart` message.

In this state, these messages are recognised:

* PatternMinMaxChange
* PatternMultiChoiceChange
* PatternSoftButton
* PatternStop
* SetPower

Additionally, the zc95 can send these messages at any time whilst in this state (with a `MsgId` of -1):

* LuaScriptError
* LuaScriptOutput
* MenuOptionChanged
* PowerStatus

#### PatternMinMaxChange
Send to change the value of a min/max pattern parameter.

Send:
```
{"Type": "PatternMinMaxChange", "MsgId": 5, "MenuId": 1, "NewValue": 5100}
```

Response:
```
{"Type":"Ack","MsgId":5,"Result":"OK"}
```

#### PatternMultiChoiceChange
Send to change the value of a multi choice pattern parameter.

Send:
```
{"Type": "PatternMultiChoiceChange", "MsgId": 5, "MenuId": 2, "ChoiceId": 1}
```

Response:
```
{"Type":"Ack","MsgId":5,"Result":"OK"}
```

#### PatternSoftButton
Send to simulate the top left soft button being pressed or released. Send with Pressed=1 to "press" the button, then Pressed=0 to release.

To avoid unexpected results, always send a Pressed=1 message followed by a Pressed=0 message, with similar timings to the button being physically pushed/released.

Send:
```
{"Type": "PatternSoftButton", "MsgId": 5, "Pressed": 1}
```

Response:
```
{"Type":"Ack","MsgId":5,"Result":"OK"}
```

#### PatternStop
Stops the running pattern, and returns to the `ACTIVE` state.

Either disconnecting if using the web socket interface, or sending an EOT (0x04) over serial, will achieve a similar result.

Send:
```
{"Type": "PatternStop", "MsgId": 4}
```

Response:
```
{"Type":"Ack","MsgId":4,"Result":"OK"}
```

#### SetPower
Set the power level for each channel, 0-1000. The front panel dials act as an upper limit to power level. E.g if the front panel is set to 50%, and a power level of 1000 is sent, the actual power level will be set to 500.

Send:
```
{"Type": "SetPower", "MsgId": 5, "Chan1": 0, "Chan2": 0, "Chan3": 0, "Chan4": 0}
```

Receive:
```
{"Type":"Ack","MsgId":5,"Result":"OK"}
```

#### LuaScriptError
Sent if a Lua script errors out and is stopped. Equivalent to the display showing a red x and "script error"

A `LuaScriptOutput` message will also usually be sent if more details are available. 

Receive:
```
{"Type":"LuaScriptError","MsgId":-1}
```

#### LuaScriptOutput
Sent either if `print("<message>")` is called from script, or if a script fails/errors out.

Fields:
* `TextType` will either be `Print` for messages from a `print` statement, or `Error` for error messages
* `Text` is either the message from a `print` statement, or an error message
* `Time` corresponds to the time the message was generated/queued to send. It is the number of microseconds since the box was powered on.

Receive:
```
{"Type":"LuaScriptOutput","MsgId":-1,"Text":"Script stopped... error: \n[string \"...\"]:34.0000: attempt to call field 'fff' (a nil value)","Time":3856714853,"TextType":"Error"}
```

#### MenuOptionChanged
Sent if a script changes one of its own parameters by calling `zc.SetMenuOption`. At present, none of the inbuilt pattern do this, but the option is there for uploaded Lua scripts.

Fields:
* `MenuId` - corresponds to Config.menu_items.id in the Lua script
* `Value` - for MIN_MAX type menu entries, will be between the min and max value. For MULTI_CHOICE menu entries, it will be one of the choice_id's for that entry

Receive:
```
{"Type":"MenuOptionChanged","MsgId":-1,"MenuId":1,"Value":500}
```

#### PowerStatus
Sent whenever the front panel dials are changed, or the script changes the requested output power.

Fields:
* `OutputPower` - 0-1000. Actual output power after front panel power limit, power sent in the `SetPower` message, and level requested by script considered. Corresponds to the yellow bar on the display
* `MaxOutputPower` - 0-1000. The lower of the power set for the chanel using the `SetPower` message, and the limit set on the front panel
* `PowerLimit` - 0-1000. Power limit set on the front panel

Receive:
```
{
   "Type":"PowerStatus",
   "MsgId":-1,
   "Channels":[
      {
         "Channel":1,
         "OutputPower":0,
         "MaxOutputPower":0,
         "PowerLimit":183
      },
      {
         "Channel":2,
         "OutputPower":0,
         "MaxOutputPower":0,
         "PowerLimit":0
      },
      {
         "Channel":3,
         "OutputPower":0,
         "MaxOutputPower":0,
         "PowerLimit":1000
      },
      {
         "Channel":4,
         "OutputPower":1000,
         "MaxOutputPower":1000,
         "PowerLimit":1000
      }
   ]
}
```

[states diag]: images/states.png "Valid states"

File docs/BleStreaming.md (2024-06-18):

# BLE remote access
## Summary
Right now, the BLE remote access functionality is likely only of use to developers. It allows the box to be controlled at a more fundamental level remotely, where patterns are generated remotely and streamed to it. 

There are two main ways in can be used:
1. For each channel, the pulse width, frequency and power level can be set. When the channel is then switched on, it will continue outputting with these settings until either changed, or BLE disconnection. This level of control is all most inbuilt patterns use (arguably more, as most inbuilt patterns don't change the power level).
There's a pattern_runner python script, and a couple of python patterns that demonstrate this.
2. Individual pulse pairs can be streamed to the box. There's some examples of doing this from a CSV file. This allows for the possibility of creating triphase effects if enabled, if the pulses are created with that in mind. This mode should be considered experimental. 

Whilst the examples are in python, it should be easy enough to use this from embedded projects.

Unless you _know_ you need #2, I'd suggest #1 is far easier to use and produce good results with. 
Whilst there's nothing stopping you, mixing the two approaches on the same channel is unlikely to go well.

To use either mode, start BLE remote access by going to `Config -> Remote access -> BLE remote access`.

All python scripts are in [misc/PythonBle](../misc/PythonBle/).

## Configuration
BLE remote access can be configured from `Config -> Remote access -> BLE config`. There are two options:
* Allow triphase - `Yes`/`No`. See "Channel isolation & triphase" section later, but allows for channel isolation to be remotely disabled allowing for tripahse affects (**a triphase cable is still required**)
* Power dial mode - affects how the front panel dials impact the power level output
  - `Limit` - Sets the maximum output power. E.g. if a power level of 500 is set remotely and the dial is at 50%, you get 50% power. If 750 is set remotely, you still get 50%
  - `Scale` - the output power is scaled according to the power dial setting. E.g. if a power level of 500 is set remotely and the dial is at 50%, you get 25% power. If 750 is set remotely, you get 37.5%

The intention is for the `Scale` option to be used when a pattern is to be generated remotely, but using the power dials on the ZC95 to control output power as needed, and for the `Limit` mode to be used where ZC95 is being fully controlled remotely, but keeping the the ability to set a limit for each channel to avoid unexpectedly high outputs.

## Setting pulse width, frequency and power level 
All relevant characteristics are grouped together in the custom "General control service", one per property, see table under "Services & characteristics".

These are hopefully fairly self explanatory; e.g. the general approach to output a 100hz, 120us signal on channel 1 and 50% power would be:
- set "Channel 1 pulse width" to 120
- set "Channel 1 frequency" to 100
- set "Channel 1 power level" to 500 (range is 0-1000 for 0-100%)
- Switch on power for the channel by setting "Channel 1 power enable" to 1

Changing the pulse width/frequency/power level whilst the channel is on _does_ work, and is how internal patterns work.

The difference between 0% output and a switched off channel is how it shows on the user interface. Switching a channel off sets the LED to green, and on to red. Setting the power to 0% changes the yellow bar in the power graph to a stub at the bottom, setting to 100% causes it to match the height of the blue bar.

### Examples

The `pattern_runner.py` script should scan for the ZC95, connect, then start the specified python pattern.

The script expects 1 parameter, which is the pattern to run, expected to be in the `patterns/` directory. Currently there are two:
- `intense.py` 
- `toggle.py`

E.g. `pattern_runner.py toggle`

## Sending individual pulses
Using this mode requires a slightly greater understanding of exactly what signals the zc95 can generates, and, fair warning, is just much harder to use. 

### ZC95 output capability
The ZC95 has been designed around the idea of generating pulses in pairs - I've called them positive and negative, but in reality A and B may have made more sense. I'm sticking with it for now.
E.g. one pulse pair where both positive and negative pulses are 80us looks something like:

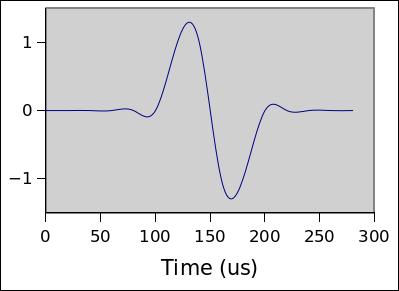
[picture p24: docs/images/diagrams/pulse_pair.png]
p1


And a pulse pair where the positive pulse was 80us and the negative pulse 0us would be:

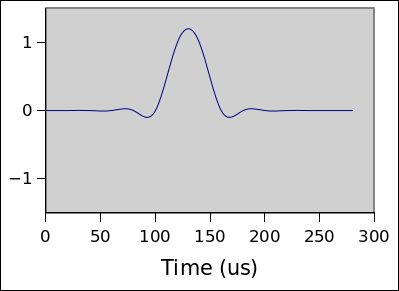
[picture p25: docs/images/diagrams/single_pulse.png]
p2


To generate a 150hz output similar to the below it would be necessary to send pulse pairs to the ZC95 with timestamps 10ms apart:

p150hz

(pulse widths not to scale!)

Firmware limitations of the ZC95 (which I currently have no intention to change) mean that it cannot:
* Swap the positive/negative pules around
* Insert a short - less than around 500us - delay between the positive and negative pulses. For longer, you can send a pulse pair with only a negative pulse then a pair with only a positive pulse

### Channel isolation & triphase
By default, the ZC95 will never generate more than one pulse at the same time - there will always be a minimum of 150us between a pulse pair finishing and the next pulse pair being generated; this is mostly for safety reasons to avoid unanticipated interactions between the channels. Where pulses have the same timestamp (or the same message is used to generate pulses on multiple channels), these pulses will automatically be separated by the ZC624 output board when channel isolation is enabled (default).

However, this prevents the generation of triphase effects where multiple channels need to be active at once, so it can be disabled. Whilst the channel outputs still need to be physically connected with a suitable triphase cable to generate triphase effects, **do not place any electrodes above the waist** with channel isolation disabled.

Steps required to support triphase effects:
* Use a triphase cable to connect two channels together
* Using the `Config -> Remote access -> BLE config` screen, set `Allow triphase` to `Yes`
* Write 0x00 to the the "Channel isolation" characteristic
* -> The ZC95 screen should show "Triphase: ACTIVE"

### Message format
When in this mode the ZC95 is expecting to receive messages which have:
* time_us - time to generate the pulse. To allow for buffering, this should be in the region of 10-100ms in the future, and not more than 1 second in the future
* positive & negative pulse width
* channel mask - which channel(s) to generate the pulse on
* power - what power level to set

A single BLE packet can have multiple messages, and these messages are streamed over the "Pulse stream" service, using the "Pulse stream" characteristic.

Messages should have the format:

```
 0                8                16               24               32  
 +-+-+-+-+-+-+-+-+-+-+-+-+-+-+-+-+-+-+-+-+-+-+-+-+-+-+-+-+-+-+-+-+-+-+
 | cmd_type       | pulse_width_pos| pulse_width_neg| channel_mask   |
 +-+-+-+-+-+-+-+-+-+-+-+-+-+-+-+-+-+-+-+-+-+-+-+-+-+-+-+-+-+-+-+-+-+-+
 |                              time_us                              |
 |                                                                   |
 +-+-+-+-+-+-+-+-+-+-+-+-+-+-+-+-+-+-+-+-+-+-+-+-+-+-+-+-+-+-+-+-+-+-+
 | Amplitude                       | Reserved                        |
 +-+-+-+-+-+-+-+-+-+-+-+-+-+-+-+-+-+-+-+-+-+-+-+-+-+-+-+-+-+-+-+-+-+-+
 ```

 Or as a C structure:
 ```
 struct ble_message_pulse_t
{
    uint8_t cmd_type;          
    uint8_t pulse_width_pos;   
    uint8_t pulse_width_neg;   
    uint8_t channel_mask;  
    uint64_t time_us;
    uint16_t amplitude;        
    uint16_t reserved;
} __attribute__((packed));
```

(fields are little endian where applicable)

`cmd_type` can be:
* 0x00 = START
* 0x01 = PULSE

`pulse_width_pos` & `pulse_width_neg` - pulse widths in us. All values supported

`channel_mask` - which channel(s) the pulse is for, and if positive, negative or both pulses should be generated for that channel:

```
 0         2         4         6         8
 +-+-+-+-+-+-+-+-+-+-+-+-+-+-+-+-+-+-+-+-+
 |C1+ |C1- |C2+ |C2- |C3+ |C3- |C4+ |C4- |
 +-+-+-+-+-+-+-+-+-+-+-+-+-+-+-+-+-+-+-+-+
 ```

So, for example, 0x03 would generate the pulse pair on just channel 1, 0x0C on channel 2 etc.

`time_us` - Time the pulse should be generated. `time_us = 0` is when the START message was sent, so all times are expected to be relative to that message, and must be sequential

`amplitude` - Power level - 0-1000 for 0-100%. **Warning**: At present power level changes happen asynchronously to pulse generation, so while this will change the power level, it may not necessarily be in time for the pulse. If you're wanting to modulate the power on a per-pulse basis, consider sending a message with the new power level, and a 0us pulse width, with a timestamp a few hundred microseconds before the new power level is needed. 

`reserved` - Reserved for future use. Send as 0x0000.
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

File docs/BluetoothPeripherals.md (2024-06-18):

# Bluetooth Peripherals

The ZC95 allows for the use of small shutter remotes meant for phones, and custom Bluetooth (HID) devices. The remotes can be used to either simulate keypresses / triggers, or passed through more directly to a Lua script to use. Events from custom Bluetooth devices can only be used with Lua scripts.

When bluetooth is active, a logo is displayed in the bottom right corner of the screen. White means trying to connect and blue connected.
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

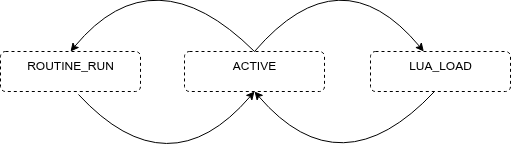
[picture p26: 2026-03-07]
docs/images/states.png

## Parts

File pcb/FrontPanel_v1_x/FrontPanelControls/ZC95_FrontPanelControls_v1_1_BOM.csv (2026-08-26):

No. | Quantity | Comment | Designator | Footprint | Value | Manufacturer Part | Manufacturer | Supplier Part | Supplier
1 | 17 | 100nF | C1,C4,C5,C6,C7,C8,C9,C10,C11,C13,C14,C15,C16,C17,C18,C19,C20 | C0603 | 100nF | CC0603KRX7R9BB104 | YAGEO(国巨) | C14663 | LCSC
2 | 2 | 10uF | C2,C12 | C0603 | 10uF | CL10A106KP8NNNC | SAMSUNG(三星) | C19702 | LCSC
3 | 6 | WS2812 | LED1,LED2,LED3,LED4,LED5,LED6 | LED-SMD_4P-L5.0-W5.0-TL_WS2812B-B |  | WS2812 | worldsemi | C5380881 | LCSC
4 | 1 | HC-FPC-05-09-18RLTAG | P3 | FPC-SMD_18P-P0.50_HC-FPC-05-09-18RLTAG |  | HC-FPC-05-09-18RLTAG | HCTL(华灿天禄) | C5213754 | LCSC
5 | 5 | 100Ω | R1,R16,R17,R18,R19 | R0603 | 100Ω | 0603WAF1000T5E | UNI-ROYAL(厚声) | C22775 | LCSC
6 | 9 | 10kΩ | R2,R3,R4,R5,R7,R8,R9,R10,R11 | R0603 | 10kΩ | 0603WAF1002T5E | UNI-ROYAL(厚声) | C25804 | LCSC
7 | 1 | 1kΩ | R6 | R0603 | 1kΩ | 0603WAF1001T5E | UNI-ROYAL(厚声) | C21190 | LCSC
8 | 4 | 10kΩ | RV1,RV2,RV3,RV4 | RES-ADJ-TH_RK09L1140A65 | 10kΩ | RK09L1140A2U | ALPSALPINE(阿尔卑斯阿尔派) | C470448 | LCSC
9 | 1 | PEC11L-4125F-S0020 | SW1 | SW-TH_PEC11L-4125F-S0020 |  | PEC11L-4125F-S0020 | BOURNS | C143783 | LCSC
10 | 4 | K6-6275D03 | SW2,SW3,SW4,SW5 | SW-TH_K6-6275D03 |  | K6-6275D03 | 韩国韩荣 | C693828 | LCSC
11 | 1 | TLC59108IPWR | U1 | TSSOP-20_L6.5-W4.4-P0.65-LS6.4-BL |  | TLC59108IPWR | TI(德州仪器) | C130031 | LCSC
12 | 1 | TCA9534APWR | U2 | TSSOP-16_L5.0-W4.4-P0.65-LS6.4-BL |  | TCA9534APWR | TI(德州仪器) | C206010 | LCSC
13 | 1 | ADS1115IDGSR | U3 | MSOP-10_L3.0-W3.0-P0.50-LS5.0-BL |  | ADS1115IDGSR | TI(德州仪器) | C37593 | LCSC

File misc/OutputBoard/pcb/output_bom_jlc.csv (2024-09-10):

Comment | Designator | Footprint | LCSC Part #
100nF | C1,C2,C3,C4,C5,C6 | C_0603_1608Metric_Pad1.08x0.95mm_HandSolder | C14663
10nF | C7 | C_0603_1608Metric_Pad1.08x0.95mm_HandSolder | C57112
10uF | C8 | C_0603_1608Metric_Pad1.08x0.95mm_HandSolder | C96446
220uF | C9 | CP_Radial_D8.0mm_P3.50mm | C440836
1uF | C10,C11 | C_0603_1608Metric_Pad1.08x0.95mm_HandSolder | C15849
220uF | C12,C13,C14,C15 | CP_EIA-7343-43_Kemet-X_Pad2.25x2.55mm_HandSolder | C122311
100uF | C16 | CP_Radial_D5.0mm_P2.00mm | C108360
SS34 | D1,D2 | D_SMA | C8678
3v3 | D3 | LED_0603_1608Metric_Pad1.05x0.95mm_HandSolder | C2986059
5v | D4 | LED_0603_1608Metric_Pad1.05x0.95mm_HandSolder | C2986059
9v | D5 | LED_0603_1608Metric_Pad1.05x0.95mm_HandSolder | C2986059
12v | D6 | LED_0603_1608Metric_Pad1.05x0.95mm_HandSolder | C2986059
OK | D7 | LED_0603_1608Metric_Pad1.05x0.95mm_HandSolder | C2986059
SMAJ13A | D8,D10,D12,D14 | D_SMA | C110519
BAV23CL | D9,D11,D13,D15 | SOT-23-3 | C232533
15uH | L1 | L_7.3x7.3_H3.5 | C177243
AO3400A | Q1,Q3,Q4,Q6,Q7,Q9,Q10,Q12 | SOT-23_Handsoldering | C20917
IRF9Z24NPBF | Q2,Q5,Q8,Q11 | TO-220-3_Vertical | C2576
0.5R | R1,R26 | R_Axial_DIN0309_L9.0mm_D3.2mm_P5.08mm_Vertical | C479327
100k | R2,R4,R5,R8,R10,R12,R13,R15,R16,R19,R21,R23,R24,R25,R27,R29,R30,R33,R35,R37,R38,R40,R41,R44,R46,R48,R52 | R_0603_1608Metric_Pad0.98x0.95mm_HandSolder | C25803
10k | R3,R7,R11,R14,R18,R22,R28,R32,R36,R39,R43,R47,R49,R56,R57 | R_0603_1608Metric_Pad0.98x0.95mm_HandSolder | C25804
150k | R6,R9,R17,R20,R31,R34,R42,R45 | R_0603_1608Metric_Pad0.98x0.95mm_HandSolder | C22807
4k7 | R50,R51,R55 | R_0603_1608Metric_Pad0.98x0.95mm_HandSolder | C23162
1.5k | R53,R54,R58 | R_0603_1608Metric_Pad0.98x0.95mm_HandSolder | C22843
680 | R59 | R_0603_1608Metric_Pad0.98x0.95mm_HandSolder | C23228
LM324 | U1 | SOIC-14_3.9x8.7mm_P1.27mm | C71035
MCP4728 | U2 | MSOP-10_3x3mm_P0.5mm | C108207
TPS5430DDA | U3 | TI_SO-PowerPAD-8_ThermalVias | C9864
XC6206P332MR | U5 | SOT-23 | C5446

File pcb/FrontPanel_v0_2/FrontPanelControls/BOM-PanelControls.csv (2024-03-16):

Comment | Designator | Footprint | LCSC
TLC59108IPWR | U9 | TSSOP-20_4.4x6.5mm_P0.65mm | C130031
100nF | C1,C10,C11,C13,C14,C15,C4,C5,C6,C7,C8,C9 | C_0603_1608Metric_Pad1.08x0.95mm_HandSolder | C14663
10uF | C12,C2 | C_0603_1608Metric_Pad1.08x0.95mm_HandSolder | C19702
TCA9534 | U2 | TSSOP-16_4.4x5mm_P0.65mm | C206010
1K | R6 | R_0603_1608Metric_Pad0.98x0.95mm_HandSolder | C21190
100R | R1 | R_0603_1608Metric_Pad0.98x0.95mm_HandSolder | C22775
10K | R10,R11,R2,R3,R4,R5,R7,R8,R9 | R_0603_1608Metric_Pad0.98x0.95mm_HandSolder | C25804
ADS1115IDGS | U1 | TSSOP-10_3x3mm_P0.5mm | C37593
WS2812D | U3 | WS2812D-F5
WS2812D | U4 | WS2812D-F5
WS2812D | U5 | WS2812D-F5
WS2812D | U6 | WS2812D-F5
WS2812D | U7 | WS2812D-F5
WS2812D | U8 | WS2812D-F5
R_POT | RV1 | ALPSALPINE RK09L1140A2U
R_POT | RV2 | ALPSALPINE RK09L1140A2U
R_POT | RV3 | ALPSALPINE RK09L1140A2U
R_POT | RV4 | ALPSALPINE RK09L1140A2U
ADJ | SW1 | BOURNS PEC11L-4125F-S0020
Conn_02x04_Odd_Even | J5 | IDC-Header_2x04_P2.54mm_Vertical

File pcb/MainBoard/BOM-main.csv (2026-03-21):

Comment | Designator | Footprint | LCSC
0.01R | R126 | R_1206_3216Metric_Pad1.30x1.75mm_HandSolder | C105362
MCP4728 | U7 | MSOP-10_3x3mm_P0.5mm | C108207
SMAJ13A | D11,D15,D7,D9 | D_SMA | C110519
220uF | C11,C14,C17,C19,C46 | CP_EIA-7343-43_Kemet-X_Pad2.25x2.55mm_HandSolder | C122311
USB_C_Receptacle | J20 | 1054500101 | C134092
HT7533-1 | U16 | SOT-89-3 | C14289
433TX | J9 | PinSocket_1x03_P2.54mm_Vertical | C146243
100nF | C10,C12,C13,C15,C16,C18,C20,C28,C3,C30,C31,C34,C4,C49,C51,C59,C6,C61,C7,C8 | C_0603_1608Metric_Pad1.08x0.95mm_HandSolder | C14663
MCP4651 | U10 | TSSOP-14_4.4x5mm_P0.65mm | C148010
AO3401A | Q1,Q14,Q15,Q16,Q18 | SOT-23_Handsoldering | C15127
1uF | C1,C2,C21,C26,C32,C36,C37,C39,C41,C42,C43,C44,C45,C48,C5,C52 | C_0603_1608Metric_Pad1.08x0.95mm_HandSolder | C15849
USBLC6-2P6 | U19,U20,U21,U22,U23,U24,U25 | SOT-666 | C15999
3.3nF | C29,C33,C35,C60 | C_0603_1608Metric_Pad1.08x0.95mm_HandSolder | C1613
47nF | C50 | C_0603_1608Metric_Pad1.08x0.95mm_HandSolder | C1622
0.47uF | C47 | C_0603_1608Metric_Pad1.08x0.95mm_HandSolder | C1623
1.5uH | L1,L2 | FXL0630 | C167217
1SMA4734A | D5 | D_SMA | C19077477
4.7uF | C69 | C_0603_1608Metric_Pad1.08x0.95mm_HandSolder | C19666
10uF | C25,C40,C56,C66,C67,C68,C70,C72,C9 | C_0603_1608Metric_Pad1.08x0.95mm_HandSolder | C19702
AT24C04CDRG | U5 | SOP-8_3.76x4.96mm_P1.27mm | C19723707
AO3400A | Q10,Q11,Q13,Q17,Q19,Q2,Q4,Q5,Q7,Q8 | SOT-23_Handsoldering | C20917
1k | R102,R115,R130,R131 | R_0603_1608Metric_Pad0.98x0.95mm_HandSolder | C21190
BZX584C3V6 | D1,D18,D20,D21,D22,D23,D24,D25,D26,D27,D28,D6 | D_SOD-523 | C22395574
100R | R110,R121,R124,R127,R134,R135,R14,R16,R19,R20,R21,R22,R27,R28,R29,R30,R31,R32,R35,R5,R6,R7,R8,R88,R9,R156,R157 | R_0603_1608Metric_Pad0.98x0.95mm_HandSolder | C22775
150k | R148,R149,R41,R44,R52,R55,R66,R69,R79,R82,R91,R92,R97,R99 | R_0603_1608Metric_Pad0.98x0.95mm_HandSolder | C22807
1.5k | R78 | R_0603_1608Metric_Pad0.98x0.95mm_HandSolder | C22843
330K | R141,R153,R86,R95 | R_0603_1608Metric_Pad0.98x0.95mm_HandSolder | C23137
4k7 | R100,R106,R107,R113,R133,R154,R93,R94 | R_0603_1608Metric_Pad0.98x0.95mm_HandSolder | C23162
5.1k | R139,R140 | R_0603_1608Metric_Pad0.98x0.95mm_HandSolder | C23186
56k | R145,R87,R89 | R_0603_1608Metric_Pad0.98x0.95mm_HandSolder | C23206
BAV23CL | D10,D12,D16,D8 | SOT-23-3 | C232533
IRF9Z24NPBF | Q12,Q3,Q6,Q9 | TO-220-3_Vertical | C2576
100k | R104,R108,R111,R112,R116,R118,R119,R12,R122,R13,R142,R144,R147,R150,R37,R39,R40,R42,R45,R47,R48,R50,R51,R53,R56,R58,R59,R60,R62,R64,R65,R67,R70,R72,R73,R75,R76,R80,R83,R85,R96,R98 | R_0603_1608Metric_Pad0.98x0.95mm_HandSolder | C25803
10k | R1,R101,R103,R105,R109,R11,R114,R117,R125,R128,R129,R132,R136,R137,R146,R15,R151,R152,R155,R17,R18,R2,R23,R24,R25,R26,R3,R33,R34,R38,R4,R43,R46,R49,R54,R57,R63,R68,R71,R74,R77,R81,R84 | R_0603_1608Metric_Pad0.98x0.95mm_HandSolder | C25804
500mA | F1 | Fuse_0805_2012Metric_Pad1.15x1.40mm_HandSolder | C269104
Conn_01x02 | J13 | Molex_KK-254_AE-6410-02A_1x02_P2.54mm_Vertical | C27543
BQ25601 | U2 | Texas_S-PWQFN-N24_EP2.7x2.7mm_ThermalVias | C2859691
0.5R | R36,R61 | R_2512_6332Metric_Pad1.40x3.35mm_HandSolder | C2904268
9v | D13,D14,D3,D4 | LED_0603_1608Metric_Pad1.05x0.95mm_HandSolder | C2986059
LCD | J6 | Molex_KK-254_AE-6410-10A_1x10_P2.54mm_Vertical | C30169
SW_SPDT | SW1 | SS-12D06L5 | C319015
TRG1 | J1,J11,J12,J14,J15,J18,J2,J4 | PJ-3062-CO | C319113
MAX3232EEAE+T | U4 | SOP65P777X199-16N | C33379
SN74LVC1G3157DCKR | U12,U18,U26,U27 | SOT-363_SC-70-6_Handsoldering | C38663
2k2 | R10,R120,R123,R138,R143,R90 | R_0603_1608Metric_Pad0.98x0.95mm_HandSolder | C4190
22uF | C22,C23,C24,C38,C53,C54,C55,C64,C65 | C_0805_2012Metric_Pad1.18x1.45mm_HandSolder | C45783
BQ27441-G1 | U13 | Texas_S-PDSO-N12 | C473397
Conn_02x04_Odd_Even | J3,J5 | PinSocket_2x04_P2.54mm_Vertical | C492421
10nF | C27,C57,C62 | C_0603_1608Metric_Pad1.08x0.95mm_HandSolder | C57112
FTC201610S1R0MBCA | L3 | FTC201610S | C5832342
26650 Cell | BT1 | BH-26650-A5BJ001 | C6937119
LM324 | U11,U6 | SOIC-14_3.9x8.7mm_P1.27mm | C71035
ACC Port | J7 | DSUB-9_Female_Horizontal_P2.77x2.84mm_EdgePinOffset7.70mm_Housed_MountingHolesOffset9.12mm | C75749
TCA9534 | U1,U28 | TSSOP-16_4.4x5mm_P0.65mm | C783615
HY2111-GB | U14 | SOT-23-6_Handsoldering | C82747
SS34 | D17 | D_SMA | C8678
TPS61088 | U17,U8 | IC_TPS61088RHLR | C87357
FS8205A | U15 | SOT-23-6_Handsoldering | C908265
FrontPanel | J8 | IDC-Header_2x04_P2.54mm_Vertical | C9135

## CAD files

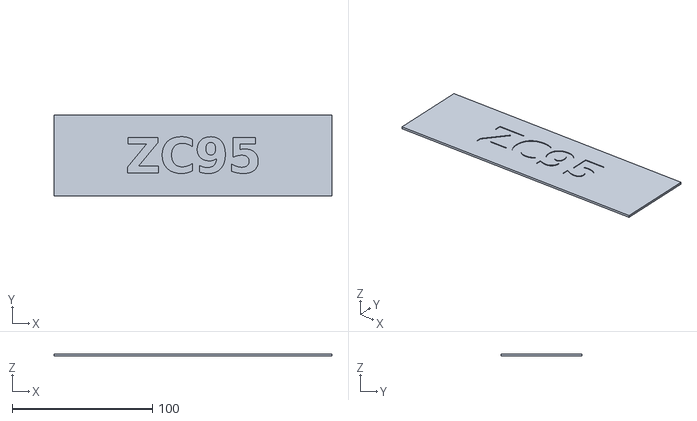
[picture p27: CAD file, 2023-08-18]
misc/case_backplate/zc95panel.stl
198.0 x 58.0 x 1.50

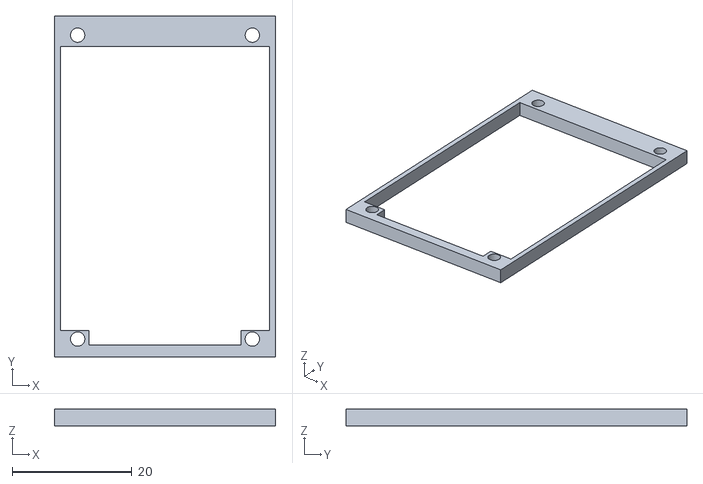
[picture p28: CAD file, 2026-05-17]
misc/display-frame/lcd_frame_ada.stl
37.0 x 57.0 x 2.80

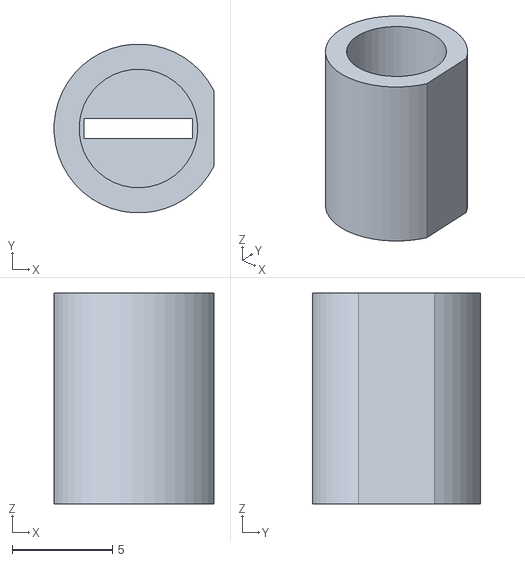
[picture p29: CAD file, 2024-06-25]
misc/led-riser/led-riser.stl
7.94 x 8.38 x 10.5

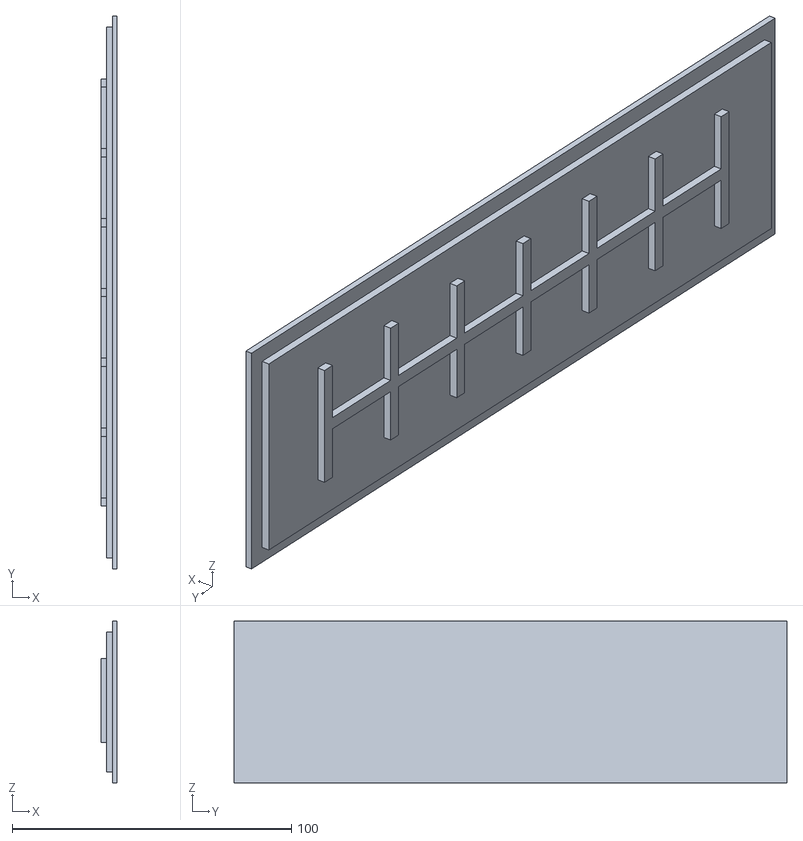
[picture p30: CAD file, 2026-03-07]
misc/Mk2Case/endplate.stl
5.65 x 198.0 x 58.0

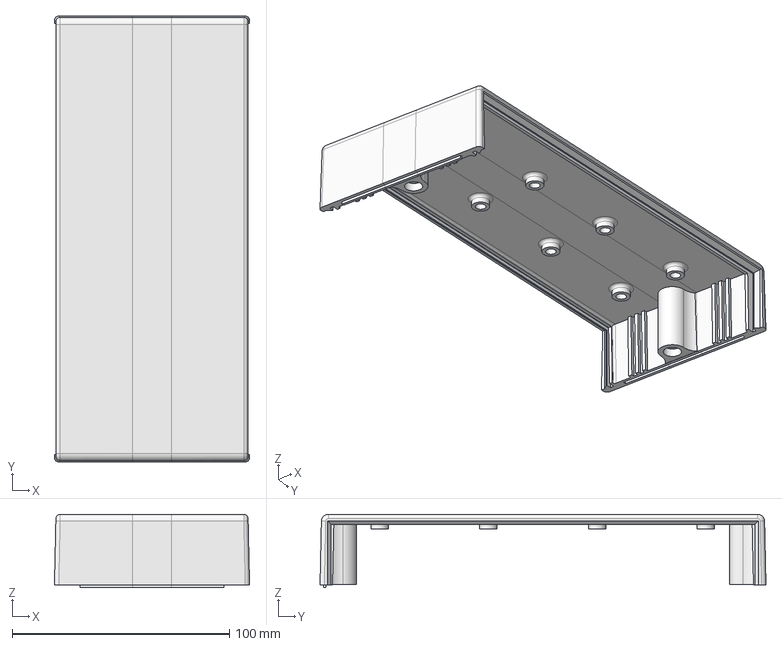
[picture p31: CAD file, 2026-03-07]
misc/Mk2Case/top.step
89.8 x 205.1 x 33.8 mm

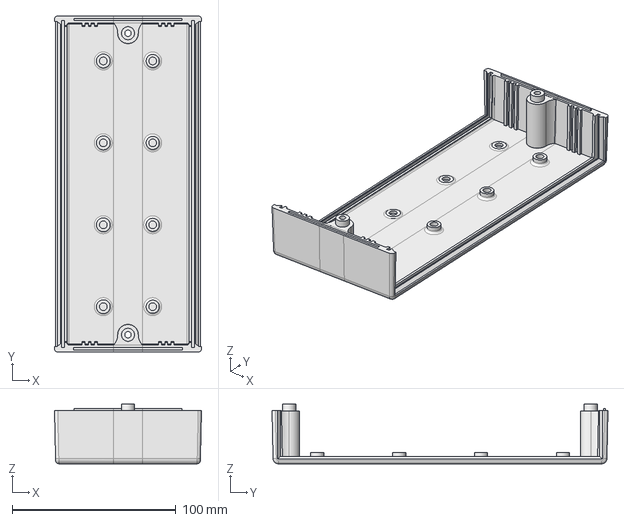
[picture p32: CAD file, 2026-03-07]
misc/Mk2Case/bottom.step
89.8 x 205.1 x 36.4 mm

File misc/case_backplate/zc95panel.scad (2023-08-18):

difference() {
  cube([198,58,1.5]);
  translate([0,0,1])linear_extrude(height=.5){ 
    translate([198/2, 58/2]) {
         text("ZC95", font = "Liberation:style=Bold", size=25,halign="center",valign="center");
    }
  }
}

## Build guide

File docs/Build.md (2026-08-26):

# Hardware build notes 

## Prerequisites 
These notes assume a reasonable amount of experience assembling electronic kits. I suggest having a read though these notes before ordering anything.

Not covered, but assumes you have a crimp tool for molex kk style connectors, something to make up IDC cables (I just use a mini-vice) and the usual tools.

## PCB + Parts ordering

The ZC95 is made up of 3 PCBs:
1. Main board
2. Front panel controls - board with potentiometers, LEDs etc on it
3. Front panel - no components, previous board is mounted to the back of it

1 + 2 have CPL & BOM files as well as gerbers, and are aimed at JLCPCB SMT assembly service. 

For the pair of front panel PCBs, there are two options:
1. Original version (v0.2): through hole LEDs, hand soldered (round) buttons with leads attaching to a smaller PCB
  
  zc95 powered up

2. New version (v1.1), kindly contributed by rootuz: SMD LEDs with light pipes to front, (square) buttons mounted directly onto a larger PCB

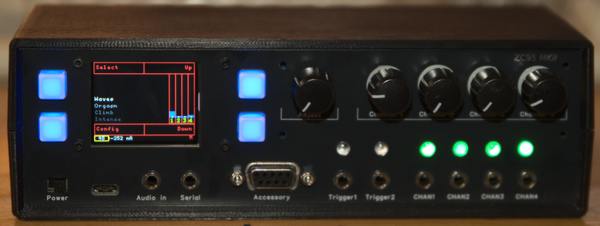
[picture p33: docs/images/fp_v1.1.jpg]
fp v1.1
  

For either option, order a matching pair of "Front panel controls" and "Front panel" boards.

### PCBs

#### 1. Main board
Order from JLCPCB using the linked gerbers and default settings (FR-4, 1.6mm thick, 1oz, etc.):

* [Main board](../pcb/MainBoard/GERBER-main.zip)

Select the "SMT Assembly" option at the bottom - pick "Assemble top side" and Tooling holes "Added by JLCPCB". 
On the next page, add the BOM and CPL files:

* [BOM-main.csv](../pcb/MainBoard/BOM-main.csv)
* [CPL-main.csv](../pcb/MainBoard/CPL-main.csv)

#### 2. Front panel
Order a pair of matching front panel PCBs - see "Order PCBs" section in relevant notes:
* [Notes for v0.2 - round buttons](./Build_fp_0_2.md)
* [Notes for v1.1 - square buttons](./Build_fp_1_x.md)

### PCB Parts
All remaining parts not covered by the JLC PCB assembly service required to populate the PCBs - with the exception of the transformers - can be purchased from LCSC, and this BOM spreadsheet lists required parts + quantity with the LCSC part number for each board on separate tabs:

[BoM (openoffice format)](BoM.fods)

#### Part substitutions
A few parts in particular are likely to cause problems if substituted:

* Transformers. The zc95 is designed around the 42TL004, and that's what all my testing (Mk1 & Mk2) has been with. The larger 42TU200's would _likely_ also work, but I'm not sure if they'll physically fit - there is space / mounting holes on the main PCB for them, but I suspect there wouldn't be enough clearance between them and the front panel. Expect problems using other transformers unless they are a very close match.

* IRF9Z24NPBF P-chanel MOSFETs - if out of stock with JLC, I strongly advise either obtaining these elsewhere and fitting yourself, or waiting. The design is _very_ sensitive to any changes to this particular part. 

### Case
There are two options for a case:
1. Hammond 1598DBK - same case as Mk1
2. 3D printed case - works, but somewhat of a work in progress

The Hammond case is just over twice as deep as the 3D printed case, but if size isn't a concern, it's a good option as it's strong/well made, readily available and quite affordable.

#### 3D printed case
The case is based on a design for the Mk1 case by [@liselotte111](https://github.com/CrashOverride85/zc95/discussions/84), that I've modified for the Mk2.
I've not got a 3D printer, and editing the case to fit the Mk2 is my first attempt at doing something like that, so beware! 

There are three parts:

1. [Top section](../misc/Mk2Case/top.step) STEP
2. [Bottom section](../misc/Mk2Case/bottom.step) STEP
3. [End plate](../misc/Mk2Case/endplate.stl) STL

I got mine produced by JLCPCB, and went for the "FDM(Plastic)", "ABS", black option. No idea if that's the most suitable, but the result seemed ok.

### Misc parts
[The BoM spreadsheet](BoM.fods) includes a Misc tab with the rest of the parts required to complete the build (battery, display, etc.).

* Battery: Use a **protected** 26650 cell that can can be safely charged at 2000 mA. The firmware currently has a hardcoded assumption of a 5300mAh cell, but it will learn the battery to an extent after a full discharge/charge cycle, so anything reasonably close should be fine (and it only affects the battery gauge anyway). Be aware that a battery is _required_ for the ZC95 to function correctly. It might power on and pass the self test without it if you're lucky, but expect stability problems without it.

* Display: I would advise sticking to the ADA358 despite the cost, as the front panel has been designed for it. However I'm aware of at least one person who used a generic 1.8" ST7735 display from aliexpress, and it mostly worked ok. 

## Assembly

### Case
Applies to the 3D printed case; there's nothing extra to do for the Hammond one.

If you're familiar with 3D printing stuff, you probably have a better idea than me here. But what I've done:

- The bottom part of the case has two rows of 4 PCB standoffs - the back row is pretty much cut off and (intentionally) mostly missing, ignore them. Of the front row, only the left and right most holes are used and line up with the PCB.

- Use M4 heat set inserts on the left and right most PCB stand offs at the front, leave the rest unused / empty

- Use M3 heatset inserts in the two screw holes used to hold the case together. Not sure how you're supposed to use them, but after installing them I ended up using (I think) a 2.5mm drill though the holes and down ~1cm, then running an M3 tap though the insert and into the hole so the length of screw used didn't matter as much.

- The back plate doesn't quite fit the way around I think it's supposed to fit due to the PCB being right up against the edge of the case - you need to have the side with cross pattern facing outwards

### Main board
Photo of board as it arrived from JLCPCB:

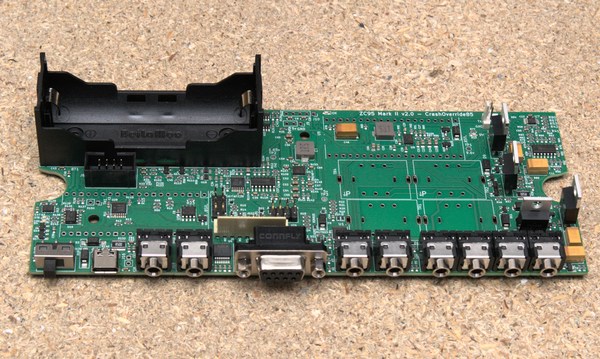
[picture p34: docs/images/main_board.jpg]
main board


* Solder four 20-pin pin sockets for the two Picos

* Configure jumpers. There is a serial interface on the "Serial" 3.5mm socket and on the 9pin accessory port - both can be independently changed between TTL & RS232 signalling. This is much easier to do before the front panel is attached and it's in a case!
My suggestion would be to have the 3.5mm socket as 3.3v TTL level as compatible serial cables are cheap on aliexpress. If you have one, a 2B cable should also work if set to TTL.

3.5mm set for TTL and accessory set for RS232:

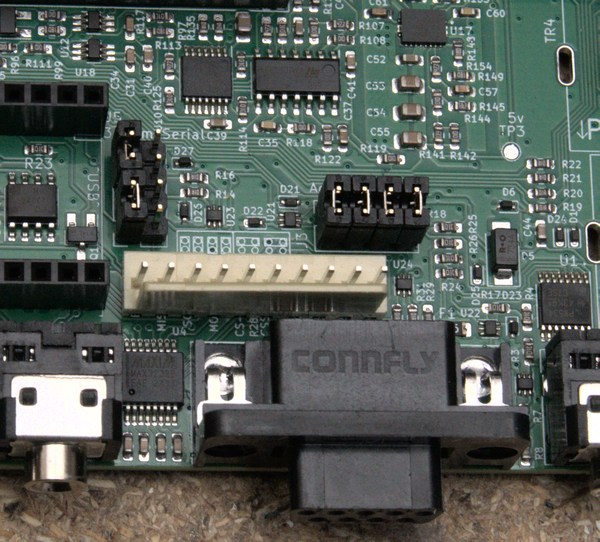
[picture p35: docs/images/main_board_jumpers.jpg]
main board_jumpers


* Fit the 4 transformers. These have the "P" facing towards the front of the case. Note that the transformers are used "backwards" - the side labelled primary goes to outputs.

* Thermistor: Attach two short wires to TH1 (under the left most Pico), and connect to a 10k thermistor. Later this will taped to the battery. For now, thread it through one of the slots in the PCB that lines up with a slot in the battery holder. I'd suggest using heat-shrink to insulate the legs of it.

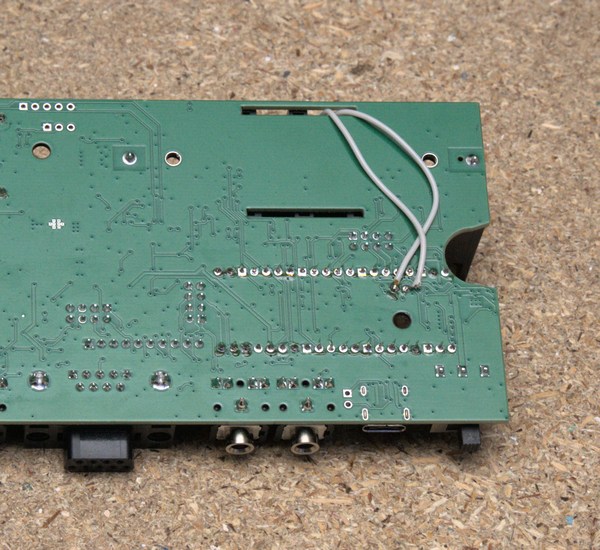
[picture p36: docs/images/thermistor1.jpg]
thermistor1


Given that it's a large protected cell being charged with quite a low current, the thermistor probably isn't really essential. If you skip it, use a 10k resistor across TH1 instead (with nothing, the battery won't charge).

* Optional: If you want to use a 433 MHz transmitter with it, solder a 3-pin pin socket onto J9 (top, to the right of the battery holder)

Populated board, minus Picos:

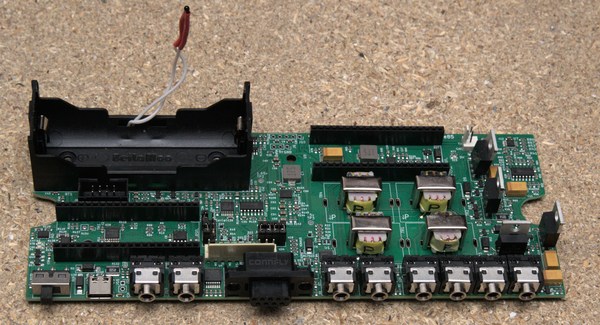
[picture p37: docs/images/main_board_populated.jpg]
main board populated


### Front panel

If using the "new" version of the display, there's a pull up resistor on the backlight enable pin that needs to be removed to prevent the display showing white on power on for a few seconds:

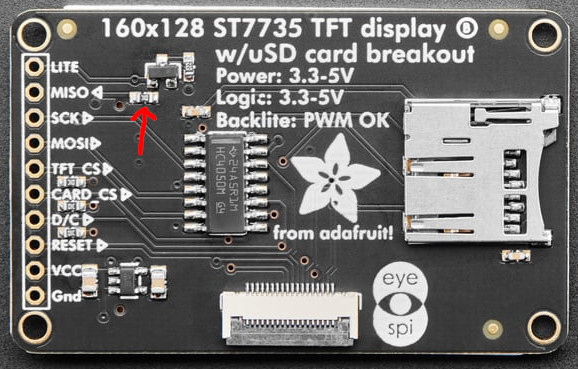
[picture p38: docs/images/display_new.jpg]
new ada358 display


The old version of the display (with a blue PCB and without the ribbon connector) doesn't have this issue, so there is nothing to remove.

Then follow the appropriate notes depending on the version of the front panel ordered:

* [Notes for v0.2 - round buttons](./Build_fp_0_2.md)
* [Notes for v1.1 - square buttons](./Build_fp_1_x.md)

### Miscellaneous
* Create a 10pin F-F cable for the display:

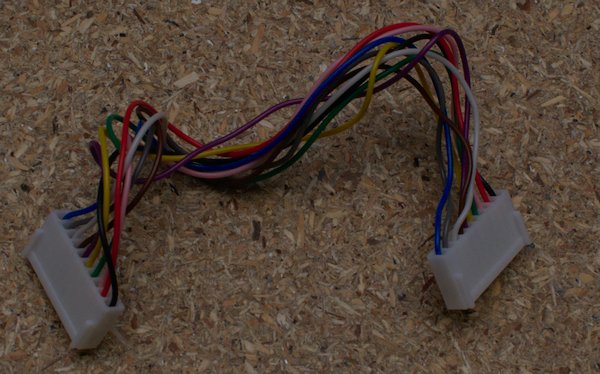
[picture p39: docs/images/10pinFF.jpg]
10pin F-F cable


(ok, so that looks pretty messy, but it works)

* Create a 2x4 way IDC cable for the front panel controls to main board:

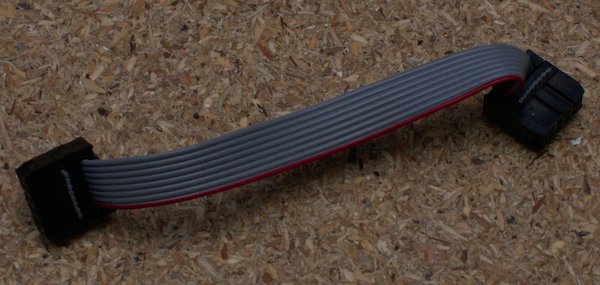
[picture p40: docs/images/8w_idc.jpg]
8w IDC


* Push the front panel (with controls board already attached) onto the main board, then screw on the DB9 socket:

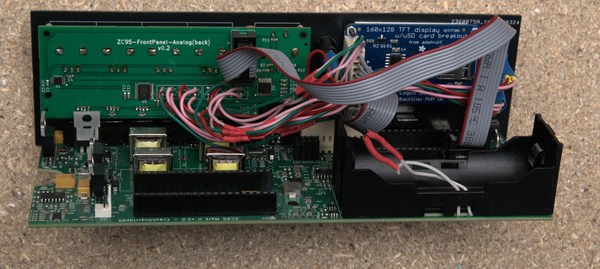
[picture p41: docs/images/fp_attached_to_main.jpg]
front panel attached to main


* Slot the boards into the case, and screw in place. There are two screw holes, one of which is hiding under the left most Pico
  - Hammond case: use screw Length (Excluding Head): 1/4" (6.5mm), Screw Size: No.6 (3.5mm)
  - 3D printed case: I used 6mm M4 screws

* Connect front panel to main board using IDC cable

* Connect LCD to main board using 10pin cable

* Copy main board firmware onto PicoW on the left (see section below), then plug into main board (USB socket pointing towards the right / towards case centre). This can be a bit fiddly

* Copy ZC624 firmware onto second Pico (see section below), then plug into the right most Pico socket, USB socket pointing towards the right / edge of the case

* Use kapton tape to secure the thermistor to the battery, then insert battery. This is a tight fit! I've found it helps to use pliers to flatten one of the contacts on the battery holder a bit first. The zc95 also might not power up on first switch on even if the battery has sufficient charge (due to battery protection). If this happens, briefly connect a charger then power it up. It should be fine after that until/unless the battery is removed/reinstalled.

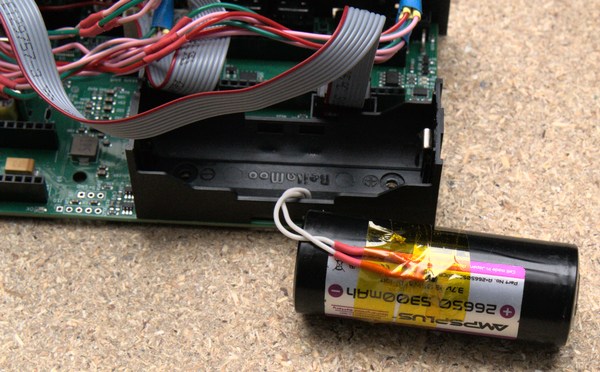
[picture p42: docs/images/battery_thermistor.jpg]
battery thermistor


Assembled ZC95 should look something like this (3d printed & Hammond 1598DBK):

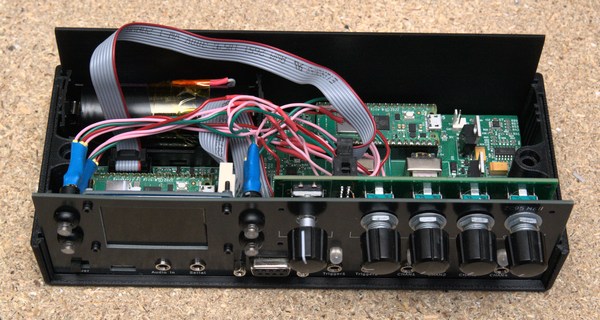
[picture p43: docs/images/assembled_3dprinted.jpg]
zc95 assembled1
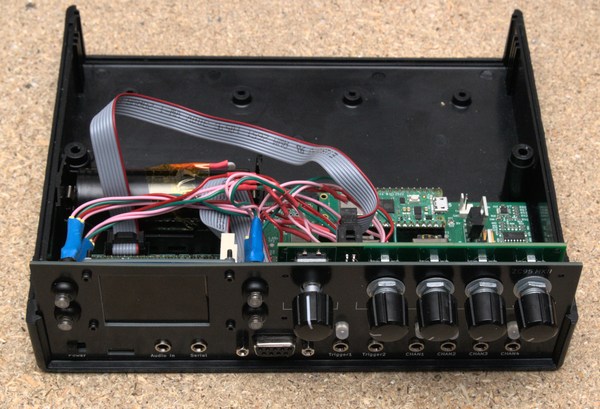
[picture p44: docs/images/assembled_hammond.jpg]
zc95 assembled2
 

### The two Picos
I feel like some explanation here is required. The ZC95 Mk1 had the output stage on a separate daughter board ("ZC624") with its own Pico, in addition to a Pico on the main board. This Mk2 is very much an evolution of that design, so retains the two Picos, except everything has now been combined onto one PCB to make it smaller, as well as making assembly easier/cheaper.

Quick summary of what they do:
* Pico on the left, below the battery - UI, pattern generation / Lua interpreter, I/O (serial, accessory, triggers), WiFi, BLE, audio
* Pico in the top right - signal generation

Any references in the documentation/code/etc to either the "ZC624" or "Output module" is about the pico/circuitry now on the right hand side of the mainboard PCB.

### Loading firmware
Download firmware from [Releases](https://github.com/CrashOverride85/zc95/releases). Use the latest version, but certainly something >= v2.0-rc2

To load firmware onto a Pico:
* Hold down the BOOTSEL button
* Connect to PC via USB
* The Pico should appear as a USB mass storage device. Drag the appropriate uf2 firmware binary onto the drive:
  - zc95.uf2 - Pico on the left, below the battery (1)
  - OutputZc.uf2 - Pico at the top right (2)

{TODO}

### Power up
On power up, the LEDs should briefly turn purple (~2s), then turn green as the screen switches on and shows:

zc95 powered up

To vastly improve the accuracy of the battery gauge, I recommend leaving the box on until the battery is flat and it shuts off, then fully charging. 

# Troubleshooting
## Doesn't power on without charger attached
For the first power on after installing a battery, a USB-C charger needs to be connected - this is to be expected and not a fault.

Applies to PCB v2.3 (only): If the ZC95 doesn't power on after having being switched off for more than a few minutes, fit a 100uF capacitor (this is on the BoM) between the right most switch contact (as viewed from the top, with the switch towards you) and the top of the USB-C connector, like so:

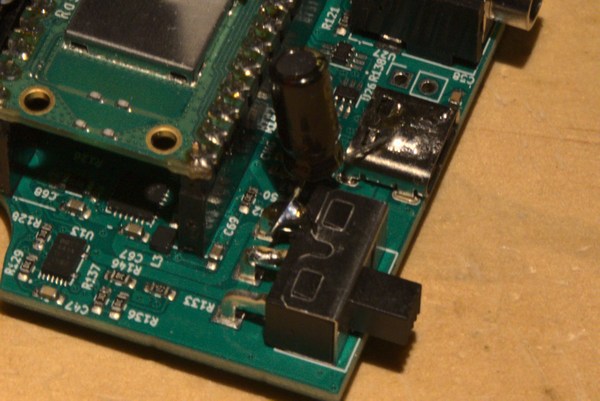
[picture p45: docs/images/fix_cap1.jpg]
fix1 100uF


If C64 & C65 are fitted, also remove them:

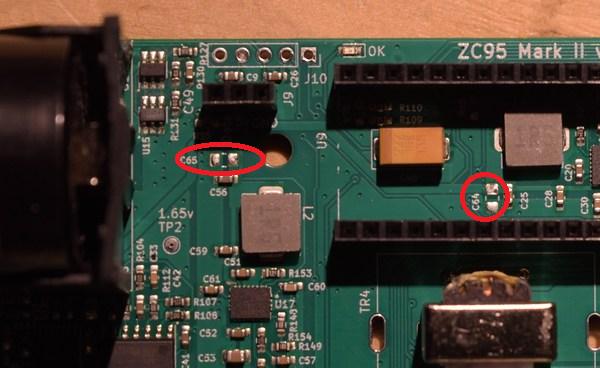
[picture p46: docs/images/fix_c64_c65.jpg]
fix1 C64 C65


(these were removed from the BoM/CPL files 2025-08-18)

That should fix the issue. In the unlikely event it doesn't, try fitting something like a 22uF 1210 capacitor between the same switch contact as before and a ground on the bottom of the PCB, e.g.:

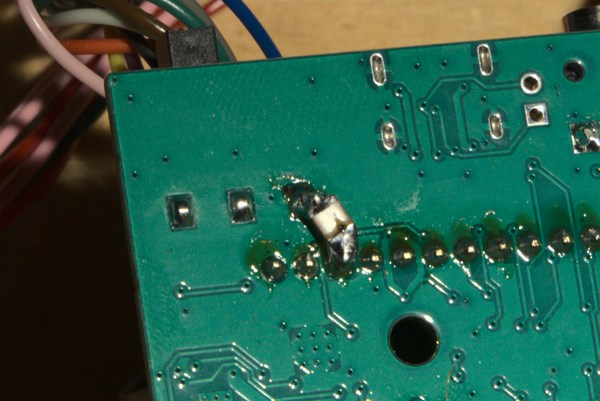
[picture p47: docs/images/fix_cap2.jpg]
fix1 22uF


## Hardware check failed
If any of the I2C devices aren't detected, you should see an error similar to the below:

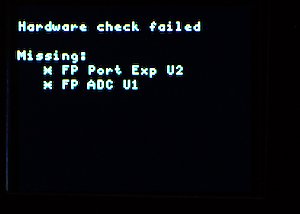
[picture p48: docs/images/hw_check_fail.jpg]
hw check fail


Here, it can't find the two ICs on the front panel (in this case, the IDC cable was unplugged).
There is serial debugging output on the "Accessory" DB9 connector (tx pin 3, ground pin 5) on the front panel. Either 3v3 TTL or RS232, depending on jumper settings.

## Battery gauge is wrong
If the battery gauge is showing filled green to indicate finished charging, but the percentage is some way off 100%, the best approach is to disconnect the charger, leave the box on until it shuts off due to low battery, then fully charge it (this should only need doing once). If you're impatient, removing the battery, leaving it a few minutes (maybe 15 to be sure), then reinstalling it and connecting the charger will probably improve it. But a full discharge/recharge cycle is best if you want it to be accurate. 

## Clearing saved settings / EEPROM
So far I've never found it necessary, but the EEPROM and user settings in flash can be reset to defaults by holding down the top right button and powering the box on. This will show a confirmation screen asking what should be reset:
* EEPROM - reset to defaults all settings that can be changed via the menus
* Flash  - clear any uploaded Lua scripts along with a section used by the btstack library for some bluetooth pairing data

Once reset, there should be a confirmation message, followed by flashing red lights. Power cycle the box, and the flash or EEPROM will have been reset to defaults.

Before showing the confirmation screen, the box will have confirmed the EEPROM IC can be detected, but no saved settings will have been used. 

## Flashing LEDs / no or corrupted display / output fault / general stability problems
For general erratic behaviour, the most likely cause is a problem with the battery - and is especially likely if the device sometimes powers up, but shows a red "?" in the battery indicator.

Even when powered via USB, a battery must still be present for reliable operation. If you're determined to run it without a battery, try putting a 470 uF (or higher) electrolytic capacitor in place of the battery.

## Output section
If the output section passes its self test, the OK LED, which is just above the left corner of the right most pico, should light (which should be ~1-2 seconds after power on). If the self test fails, this light will flash slowly (on for 0.5s, off for 0.5s etc).

There is also debugging output from the output pico on a 2 pin serial header next to it. Note that is at 3v3 level, and RS232 levels would damage it.

Connect a 3.3v TTL serial to USB adapter to the pins labelled Tx and GND on the header, connect at 115200 baud, and power it on. 
After the output of an I2C scan and a few other bits, it should output something similar to this on success:

```
calibrate for sm=0 OK: dac_val = 2860, voltage = 0.075732
calibrate for sm=1 OK: dac_val = 2870, voltage = 0.075732
calibrate for sm=2 OK: dac_val = 2870, voltage = 0.076538
calibrate for sm=3 OK: dac_val = 2840, voltage = 0.078149
Calibration success
```

On failure, the end of output may look something like this:

```
calibrate for sm=3 FAILED! final voltage = 0.011279, dac_value = 2600 (expecting 0.075v - 0.090v)
One or more chanel failed calibration, not enabling power.
CMessageProcess()
HALT.
```

### Self calibration notes
The purpose of the self calibration is to figure out exactly when the P-channel MOSFET for each channel starts to switch on, as this can vary slightly due to variances between parts, etc. It also serves as a basic self-test.

This probably needs a brief explanation about how the output stage is working. The two n-channel MOSFETs per chanel are used to generate +ve/-ve pulses (in the range of 10-255 microseconds). In normal operation, only one is switched on at once, but during calibration both are switched on so that there is little/no estim output.

The P-channel MOSFET is connected to the DAC via an op-amp, and is used to set the output power. With the maximum DAC value (4096) the MOSFET will (should) be fully OFF, and at 0 fully ON (i.e. maximum power).

In practice, if starting at a DAC value of 4000 and working down, the MOSFET should start to turn on at around 3000, and be fully on by ~1000.

During calibration, the voltage across the 0.5R sense resistor is measured, which corresponds to current flow though the P-channel MOSFET and transformer. This can be used to tell when the MOSFET starts to switch on.

The process for self power-on calibration (for each channel) is:
1. With the 3 MOSFETs switched off (dac value = 4000), the voltage across the sense resistor is measured - ideally it should be 0v as everything is off, but in reality noise means it won't quite be 0; however if it is > 0.03v something is clearly wrong so the calibration errors out.
2. The DAC is set to 3400
3. Both N-chanel MOSFETs are switched on
4. The voltage across the sense resistor is measured, then the N-channel fets switched off
    - If > 0.09v, something's gone wrong (unexpected jump in current), and calibration errors out
    - If > 0.075v, the DAC value is saved as the calibration value, and calibration for the channel completes successfully
    - Otherwise, the DAC value is reduced and the process repeats from step 3. If it's reached 2400 and the voltage still hasn't hit 0.075v, calibration errors out as the P-channel fet should be starting to switch on by this point.

All this means is that an error like this:
```
calibrate for sm=3 FAILED! final voltage = 0.011279, dac_value = 2400 (expecting 0.075v - 0.090v)
```
means that the PFET never switched on (enough) to complete calibration successfully.

An error like this:
```
calibrate for sm=3 FAILED! final voltage = 1.541235, dac_value = 3400 (expecting 0.075v - 0.090v)
```
means the opposite - at the starting value of 3400, the voltage across the sense resistor (and therefore current flow though the PFET & transformer) was already way above what it should be.

Possible causes (not exhaustive!) for calibration to fail:
* If all channels are showing a similar and very low voltage (~0.01v) at a DAC value of 2400, suspect the 9v supply
* Bad/incorrect PFET - e.g. not an IRF9Z24**NPBF**
* Too low value sense resistor (if DAC value is 2400), or too high (if DAC value is 3400)
* Incorrect resistor value in the opamp circuit - likely if the final voltage is wildly off. Also suspect a bad/cracked resistor or poor solder joint if the final voltage keeps changing between power cycles 
* If either chanel 1+2 or 3+4 fail with the same figures, take a close look at the corresponding ADC input pin on the Pico (pin 31/ADC0 for chan 1+2 or 32/ADC1 for chan 3+4) for bad solder joints. Also inspect the DAC (U7) and look for any bridged pins

**Note**: If calibration/self test fails, the 9v supply is switched off, so this not being present after a calibration failure is likely a symptom not a cause.

[main board]: images/main_board.jpg "Unpopulated main board"
[main board_jumpers]: images/main_board_jumpers.jpg "Main board with jumpers set"

[thermistor1]: images/thermistor1.jpg "Thermistor attached"

[main board populated]: images/main_board_populated.jpg "Populated main board"

[10pin F-F cable]: images/10pinFF.jpg "10 pin F-F cable"
[8w IDC]: images/8w_idc.jpg "2x4 IDC cable"
[display frame]: images/display_frame.jpg
[front panel attached to main]: images/fp_attached_to_main.jpg "Front panel attached to main board"
[battery thermistor]: images/battery_thermistor.jpg "Thermistor taped to battery"
[zc95 assembled1]: images/assembled_3dprinted.jpg "Fully assembled ZC95 in 3d printed case, minus cover"
[zc95 assembled2]: images/assembled_hammond.jpg "Fully assembled ZC95 in 1598DBK case, minus cover"
[zc95 powered up]: images/powered_up.jpg "Fully assembled ZC95 powered up"
[fp v1.1]: images/fp_v1.1.jpg "Front panel v1.1"
[hw check fail]: images/hw_check_fail.jpg "Power up error"
[fix1 C64 C65]: images/fix_c64_c65.jpg "C64 and C65 location on PCB"
[fix1 100uF]: images/fix_cap1.jpg "100uF capacitor between switch and USB-C"
[fix1 22uF]: images/fix_cap2.jpg "22uF capacitor on underside of PCB"
[new ada358 display]: images/display_new.jpg "New version of the ADA358 display"
[q1]: images/build_Q1.jpg "Use diode for Q1"
[gh25]: https://github.com/CrashOverride85/zc95/discussions/25
[gh46]: https://github.com/CrashOverride85/zc95/issues/46

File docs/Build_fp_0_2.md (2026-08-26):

 # Front panel v0.2
 
Ordering & build instructions for front panel v0.2, which should result in a zc95 that looks like this:

zc95 powered up

## Order PCBs

### Front panel controls
Order the board using [these gerbers](../pcb/FrontPanel_v0_2/FrontPanelControls/GERBER-PanelControls.zip) and the default options as per the main board.

Select the "SMT Assembly" option again at the bottom - pick "Assemble **BOTTOM** side" (this is _not_ the default) and Tooling holes "Added by JLCPCB". 
On the next page, add the BOM and CPL files:
* [BOM-PanelControls.csv](../pcb/FrontPanel_v0_2/FrontPanelControls/BOM-PanelControls.csv)
* [CPL-PanelControls.csv](../pcb/FrontPanel_v0_2/FrontPanelControls/CPL-PanelControls.csv)

### Front panel
Order the board using [these gerbers](../pcb/FrontPanel_v0_2/FrontPanel.zip). Not essential, but as the board forms the front of the case, I would suggest:
* **Order in black**; or at least, think about what colour you want the front panel to be and don't just go with the default of green unless that's what you really want
* For "Mark on PCB" in the "High-spec Options" section, pick "Order Number (Specify Position)". This is makes sure the order number is put on the back of the PCB (the placeholder is already on the back of the board for this)

Keep the other options as default.

### 3D printed parts

Both of these are optional.

#### LED riser
Order or 3d print LED riser: [STL file](../misc/led-riser/led-riser.stl). These make it easier to install the LEDs at the correct/consistent height.

#### Display frame
Allows the screws holding the Adafruit display to the front panel to be tightened without crushing the display. [STL file](../misc/display-frame/lcd_frame_ada.stl).

### Misc ordering notes

* If substituting parts, be aware that not all WS2812D LEDs have the pinout

* Buttons: Consider what colour you want the buttons. The BoM lists LP1OA1A**B** for blue (as I used for the Mk1), but for this Mk2 I've gone with LP1OA1A**R** for red. Still not sure which I prefer ¯\_(ツ)_/¯

## Assembly

### Front panel controls 
* Photo of board as it arrived from JLCPCB:

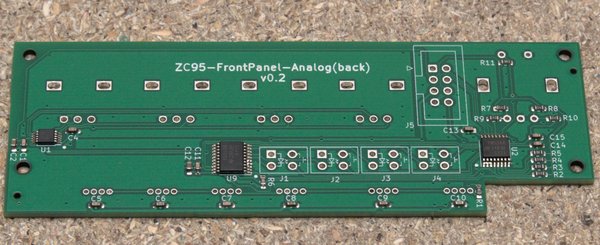
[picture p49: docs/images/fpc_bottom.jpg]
front panel controls-bottom

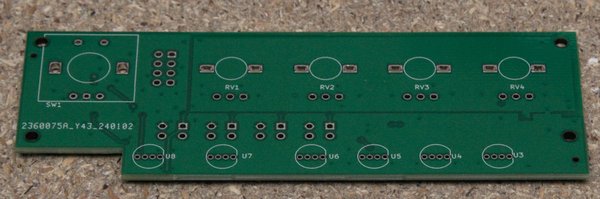
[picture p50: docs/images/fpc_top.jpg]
front panel controls-top


* If printed/ordered, use the LED risers to get the LEDs at the correct height, e.g.:

  ![front panel LED riser]:

  (Photo shows front panel attached to a mk1)

  Thanks to @electro991 for this, see [#102][gh102].

* Otherwise, getting the LEDs at the correct height can be a little awkward. Suggest soldering the POTs + rotary encoder first, putting the LEDs in (no solder yet), then attaching the board to the front panel (using 20mm bolts). Make sure the LEDs are level-ish, then solder in place.
* Stating the obvious, but put all the hand-solder parts (LEDs, POTs and rotary encoder) on the side indicated by the silkscreen

Fully assembled board:

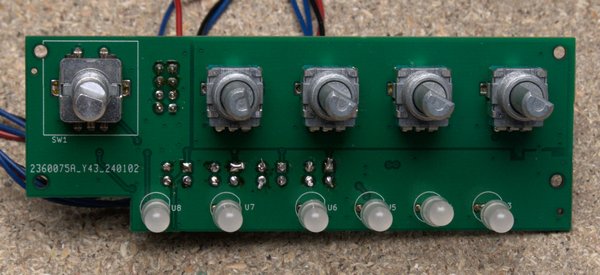
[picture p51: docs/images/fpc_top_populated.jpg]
front panel controls-top-populated


### Front panel
Photo of board as it arrived from JLCPCB:

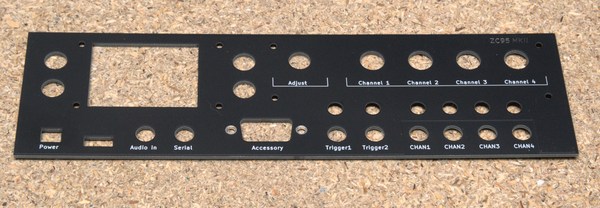
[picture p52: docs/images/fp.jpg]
front panel


Perhaps the most annoying part of the whole build is wiring the 4 buttons to the front panel. The buttons should be attached to the corresponding position on the front panel controls PCB:

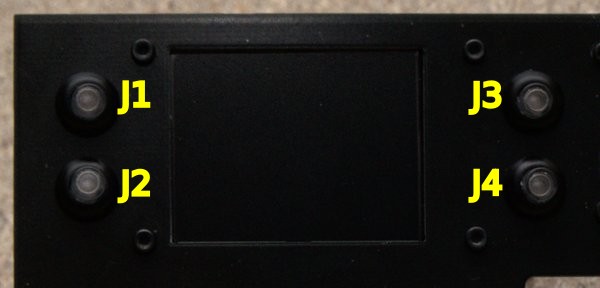
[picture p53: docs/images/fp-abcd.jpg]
front panel buttons


If using the illuminated LP1OA1Ax buttons, there are 4 wires per button - 2x for switch contacts and 2x for the LED. The LED part of the buttons should be connected like this:

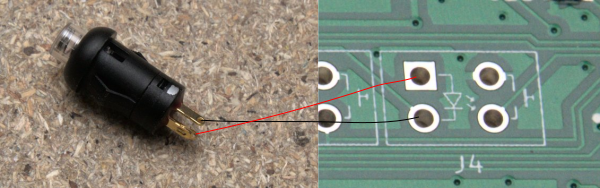
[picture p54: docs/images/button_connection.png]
button connections


The pin marked with the white dot is the LED cathode, the opposite pin is the anode, the other two pins are the switch contacts.

Once connected, it should look something like:

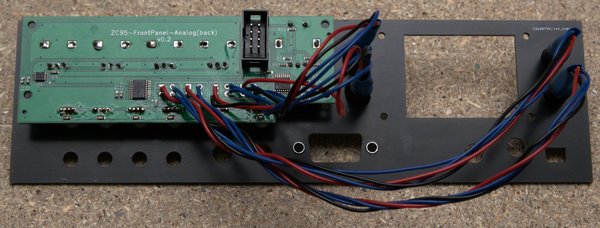
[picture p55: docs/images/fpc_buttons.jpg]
front panel buttons connected


_Optional_: If you ordered/printed the display frame, place it around the display before mounting to the front panel:

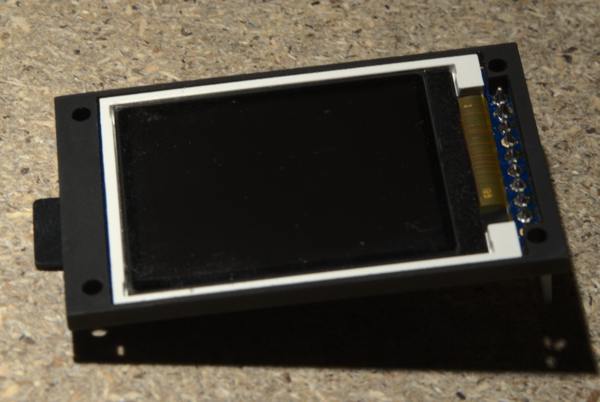
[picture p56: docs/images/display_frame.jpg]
display frame


(Thanks to rootuz for this frame)

Use the M2 nuts & 20mm bolts to attach the board to the front panel, then screw on the washers & nuts for the potentiometers. 

Attach connector to back of LCD, then LCD to the front panel with M2 nuts, 12mm bolts.

The assembled front panel should look something like this:

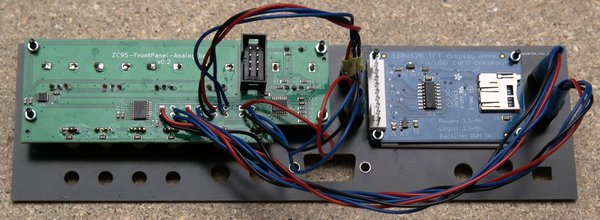
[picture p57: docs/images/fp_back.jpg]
front panel back


[button connections]: images/button_connection.png "Front panel buttons to fpc board connection"
[display frame]: images/display_frame.jpg
[front panel]: images/fp.jpg "Front panel"
[front panel buttons]: images/fp-abcd.jpg "Front panel with buttons labelled"
[front panel back]: images/fp_back.jpg "Back of front panel with LCD and buttons attached"
[front panel buttons connected]: images/fpc_buttons.jpg "Front panel with buttons attached"
[front panel controls-bottom]: images/fpc_bottom.jpg "Unpopulated front panel controls board - bottom"
[front panel controls-top]: images/fpc_top.jpg "Unpopulated front panel controls board - top"
[front panel controls-top-populated]: images/fpc_top_populated.jpg "Populated front panel controls board - top"
[front panel LED riser]: images/fpc_led_riser.jpg "Front panel with LED riser"
[zc95 powered up]: images/powered_up.jpg "ZC95 with v0.2 front panel"
[gh102]: https://github.com/CrashOverride85/zc95/discussions/102

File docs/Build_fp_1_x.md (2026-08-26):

 # Front panel v1.x
 
Ordering & build instructions for new front panel kindly designed and contributed by rootuz. This should result in a zc95 that looks like this:

fp v1.1

Please note that whilst the project files & gerbers for these PCBs are available, they are provided under the [CERN-OHL-S](../pcb-project/FrontPanelControls/v1_x/LICENSE.txt) licence.

## Order PCBs

### Front panel controls
Order the board using [these gerbers](../pcb/FrontPanel_v1_x/FrontPanelControls/ZC95_FrontPanelControls_v1_1_Gerber.zip) and the default options as per the main board.

On the next page, add the BOM and CPL files:
* [BOM-PanelControls.csv](../pcb/FrontPanel_v1_x/FrontPanelControls/ZC95_FrontPanelControls_v1_1_BOM.csv)
* [CPL-PanelControls.csv](../pcb/FrontPanel_v1_x/FrontPanelControls/ZC95_FrontPanelControls_v1_1_CPL.csv)

### Front panel
Order the board using [these gerbers](../pcb/FrontPanel_v1_x/FrontPanel.zip). Not essential, but as the board forms the front of the case, I would suggest
 **Order in black**; or at least, think about what colour you want the front panel to be and don't just go with the default of green unless that's what you really want

Keep the other options as default.

## 3D printed parts

### Display frame
Optional: Allows the screws holding the Adafruit display to the front panel to be tightened without crushing the display. [STL file](../misc/display-frame/lcd_frame_ada.stl).

## Boards

Photo of front panel as it arrived from JLCPCB:

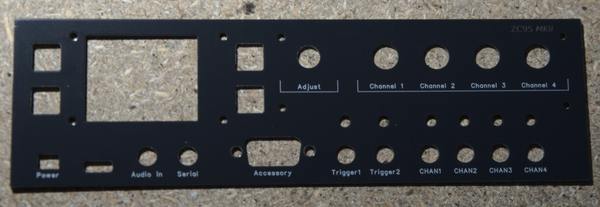
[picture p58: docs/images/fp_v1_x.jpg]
fp


Photo of front panel controls board as it arrived from JLCPCB:

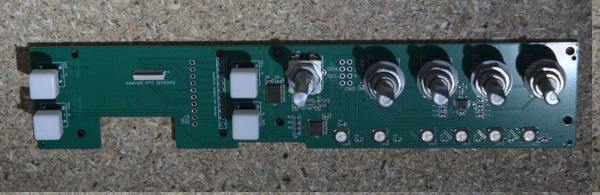
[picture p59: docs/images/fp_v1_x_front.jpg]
fp front

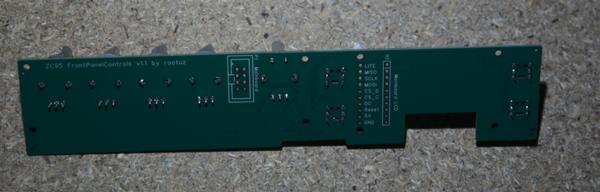
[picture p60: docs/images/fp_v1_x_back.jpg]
fp back


## Assembly
There are two ways to attached the display to the front panel: either solder it, or connect it using an 18 way 0.5mm pitch FPC flat flexible ribbon cable (recommended).

* Solder on a 2x4 IDC socket on the rear of the board for "P1" - make sure orientation matches the silkscreen.

* Solder a 10 pin molex KK style connector for "H1" ("Mainboard LCD").

* If soldering display to front panel: Solder 10 way pin header onto back on LCD. Skip this if using FPC ribbon.

* If ordered/printed, fit the display frame to the display:
  
  display frame

* Use 4x bolts to attach the display (& optional frame) to the front panel, and secure with nuts

* Remove all nuts & washers from the potentiometers & rotary encoder, and push the front panel onto the controls board, lining up display header with PCB

* Either
  1. Ensure the rear/controls PCB is level (all buttons are level), and solder display in place, **OR**
  2. Plug in the FPC ribbon to the display and the front panel:

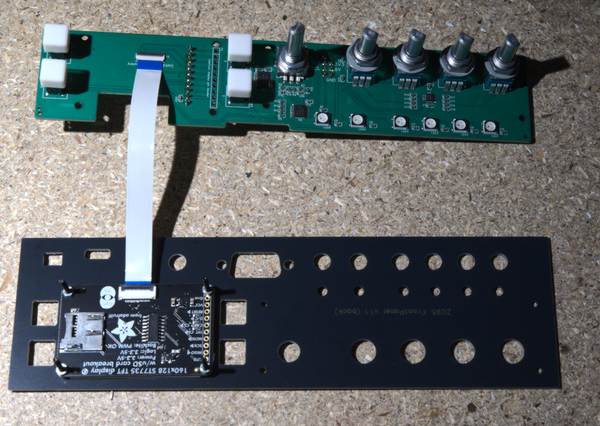
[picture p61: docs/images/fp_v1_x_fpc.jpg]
fp fpc
     

* Add remaining nuts for display/pcb, and add the 4x nuts & bolts around the potentiometers & rotary encoder

* Push the 6x light pipes into front panel. This should require some force.

The assembled front panel should look something like this:

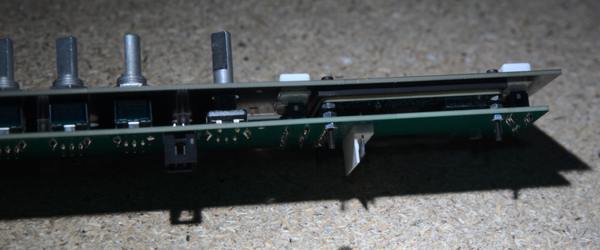
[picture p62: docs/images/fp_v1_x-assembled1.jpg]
fp assembled1


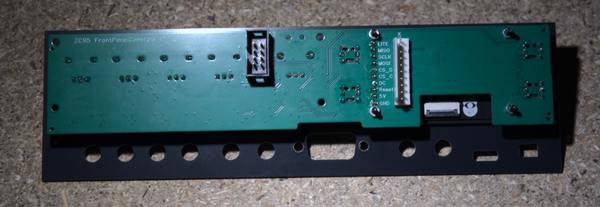
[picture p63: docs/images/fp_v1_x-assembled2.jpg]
fp assembled2


(shows assembled with display soldered to front panel)

[fp v1.1]: images/fp_v1.1.jpg "Front panel v1.1"
[fp front]: images/fp_v1_x_front.jpg "Front panel controls PCB, top side as it arrived from JLCPCB" 
[fp back]: images/fp_v1_x_back.jpg "Front panel controls PCB, bottom side as it arrived from JLCPCB" 
[fp fpc]: images/fp_v1_x_fpc.jpg "Front panel attached to display using FPC" 
[fp]: images/fp_v1_x.jpg "Front panel as it arrived from JLCPCB"
[display frame]: images/display_frame.jpg

[fp assembled1]: images/fp_v1_x-assembled1.jpg "Front panel, assembled, top down view " 
[fp assembled2]: images/fp_v1_x-assembled2.jpg "Front panel, assembled, rear view"

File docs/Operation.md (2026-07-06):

# Operation

## Device layout
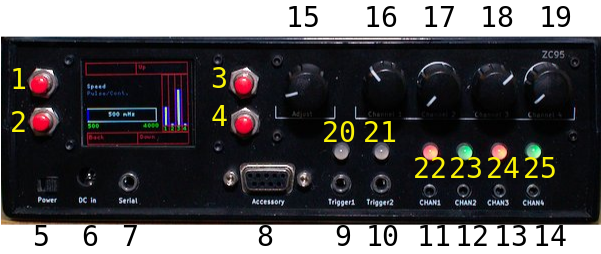
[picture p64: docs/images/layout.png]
device layout


Buttons 1 - 4 are soft buttons and the purpose changes dependant on the screen. 

| Number | Description
| --- | ---
| 1 | Softbutton - Used to select pattern from the main menu, and changes dependant on the selected pattern.
| 2 | Softbutton - Usually back / return to previous screen
| 3 | Softbutton - Usually scroll up
| 4 | Softbutton - Usually scroll down
| 5 | Power. Left is off, right is on. Probably should have labelled that.
| 6 | Power in. MKI: Should be centre positive 15v DC. MKII: any USB-C charger
| 7 | MKI: Either Serial port, or if optional audio input board fitted, can be toggled between serial and audio input. MKII: separate serial and audio sockets (not in photo). Both: In serial mode, Tip is TX / output from box, Sleeve is ground.
| 8 | Accessory port. Includes power, serial and 3x GPIO pins. See "Accessory port" in misc section. Currently not really used by much.
| 9 | Trigger input 1. Shorting either Sleeve or Ring to Tip registers trigger. The box can differentiate between S-T and R-T triggers (i.e. each trigger socket can react to two different inputs)
| 10 | Trigger input 2. As above, except currently unused.
| 11 | 2.5mm (MKI) or 3.5mm (MKII) socket for channel 1 output
| 12 | 2.5mm (MKI) or 3.5mm (MKII) socket for channel 2 output
| 13 | 2.5mm (MKI) or 3.5mm (MKII) socket for channel 3 output
| 14 | 2.5mm (MKI) or 3.5mm (MKII) socket for channel 4 output
| 15 | Adjust - Used to change the setting of on-screen sliders / multi choice options. A blue bar/background in the middle/left section of the screen indicates when the Adjust control can be used
| 16 | Power control for channel 1
| 17 | Power control for channel 2
| 18 | Power control for channel 3
| 19 | Power control for channel 4
| 20 | LED indicator for trigger 1. Lights up when triggered
| 21 | LED indicator for trigger 2. Lights up when triggered
| 22 | LED indicator for channel 1. Green = Internal channel 1 selected, but no output. Yellow = Shock collar 1 selected - see config section - but no output (2.5mm CHAN1 unused). Red = output on (either 2.5mm output or shock collar, depending on config)
| 23 | As above, but for channel 2 
| 24 | As above, but for channel 3
| 25 | As above, but for channel 4

## Screen
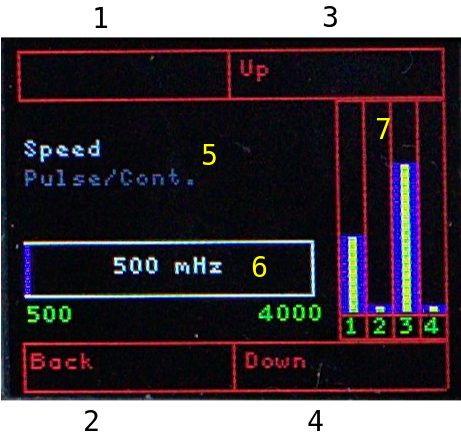
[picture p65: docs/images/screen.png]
screen layout


| Number | Description
| --- | ---
| 1 | Softbutton - Text for softbutton 1
| 2 | Softbutton - Text for softbutton 2 
| 3 | Softbutton - Text for softbutton 3
| 4 | Softbutton - Text for softbutton 4
| 5 | Menu items. White text is the currently selected option
| 6 | Option corresponding to selected menu item. Can be changed using the Adjust dial
| 7 | Current power level for each channel. The blue bar represents the current maximum power the pattern can use, as set by the power control dials. The yellow bar inside it shows the current power level the patten is using. For most patterns, these will be the same, but some (e.g. triggered climb) will have a much smaller (but rising) yellow bar.

## On power up
On first power up, the box shows a menu of available patterns. Either the highlighted pattern can be started by pressing soft button 1, or the config menu can be entered by using soft button 2.

## Config
Configuration options so far:

* Remote access - Allows for remote access to the ZC95 over WiFi + BLE (if running on a Pico-W) and serial, for the purpose of either remotely controlling it or uploading Lua scripts. See [Remote Access](./RemoteAccess.md) for serial & WiFi, and [BLE Streaming](./BleStreaming.md) for BLE remote control

* BLE peripherals - Only visible if running on a Pico-W. For configuring bluetooth remotes; see [Bluetooth peripherals page](./BluetoothPeripherals.md)

* Output - Settings related to signal output. Options:
  - Power level - High (default), Medium or Low
  - Start ramp duration - When starting a pattern, how many seconds does it take to ramp up to the power level set for the channel on the front panel
  - Extended ramp conf. - in addition to the initial ramp up period whenever a pattern is started, the ZC95 can also gradually increase the power level over an extended period of time - from a few minutes to over an hour. The extended ramp configuration menu has these options:

    * Show ramp start - Yes or No. If Yes, when running a pattern the top item on the list will always be "Ramp start". To start the ramp up, select this option, and press the top left soft button (labelled "Start"). 
    * Start level - 1% - 100%. At what percentage of the power selected on the front panel does the ramp start. Setting to 100% effectively disables the ramp function
    * Time per p.p. - Time taken in seconds to increase the power level by one percentage point. This increase is relatively smooth, and will increase the power level in 0.1% increments to achieve the selected rate.
    * Ramp shape - Affects how the ramp is performed. -ve values result in a fast initial rise that slows down as the ramp progresses. +ve values result in a slow initial rise, which speeds up as the ramp progresses. The graph on screen gives a visual representation of how the ramp will progress for the selected value. The default setting of 0 results in a linear rise (which is how the ramp functioned prior to this setting).
    * Show on status bar - if set to "Yes", shows the progress in percent and the ramp time remaining in the status bar whilst the ramp is running.

    With either "Start level" or "Time per p.p." selected, the bottom of the menu will indicate the estimated time in minutes for the ramp to complete.

* Channel config - For each channel 1-4, picks if either the internal output (on the 3.5mm connector) should be used, or if a shock collar should be triggered

* Collar config - Allows 4x shock collars to be configured. Each shock collar needs to be paired to the box, and the bottom option allows for testing the collar with the current settings. The "Chan." option corresponds to the CH button on the original remote, and it probably makes sense to be left as 1 for all collars, as each will have a unique ID anyway. Note that the mode (shock / vibrate / beep) needs to be set here, and won't change outside of this config screen (for the time being, at least)

* Display options - sub-menu, with:
  - LED brightness - Pretty much what it says. If you value your eyesight, single digit values are good.

  - Power level display - where to show the numeric power level as percentage. Options are:
    - Off (default) - Only show power level as a bar graph
    - Disappearing - Show in large text on screen for a few moments on change
    - In bar graph - Show value, rotated 90 degrees, inside the corresponding bar graph
    - Both - Enable Disappearing text display and in bar graph

  - Battery status - Controls what is displayed in the battery icon: Percentage (default) or voltage

  - Button brightness - controls how bright the LEDs in the 4 front panel buttons are

  - MKII only: Display brightness - as you would expect, changes the display brightness

  - MKII only: Status bar text. What the status bar should show. Options:
    - Running pattern - name of the currently running pattern, or blank if nothing running. This is what MKI's show
    - Battery current - current draw from battery in mA. -ve indicates current being drawn from battery, +ve current going into battery (i.e. charging).
      For PCB versions >= 2.3, this may go negative even when plugged in, as if the charger can't supply enough current, the difference will come from the battery.

    Note that if the extended ramp configuration has been set to show progress on the status bar, that will override this setting whilst the ramp is in progress.

* Audio input - Displayed if audio board present by default, depends on "Hardware config > Audio" setting. See [Audio Input](./AudioInput-Operation.md)

* Hardware config - configure various hardware settings. Shouldn't need changing. Options:
  - Audio - control display of audio options. See [Audio Input](./AudioInput-Operation.md) 
  - Debug output - where debugging information is sent:
    - Accessory port
    - Aux port
    - Off

    Note that if the Aux port is configured to be used for audio, picking Aux port here is essentially the same as "Off". Also worth noting that when the box is first powered up, debug info is always sent to the accessory port until the configuration is read, before potentially switching to aux or off.

  - MKI only: Aux port use - what the Aux port on the front is used for. Options:
    - Audio input
    - Serial I/O

    If the audio board isn't present, this menu has no effect, i.e. Aux is always in Serial I/O mode.

  - v2.3+ only: Batt charge current. Set the maximum charge current for the battery between 0 mA and 3000 mA.

      **Caution** : Do not rely on this - the battery must be capable of being _safely_ charged at 2000 mA, even if a lower value is set for battery longevity / power consumption (whatever) reasons. 2000 mA is the default for the charge controller, so it's possible there are some scenarios where the default may get used.

  - LED colour format - set the colour format (RGB, GBR, etc) expected by the 6 front panel LEDs. This should only need changing if not using the part specified in the BoM. When this option is selected, the LEDs should show:
    
      - Trigger1 + Trigger2: Red
      - Chan1 + Chan2: Green
      - Chan3 + Chan4: Blue

    Adjust the colour format until the LEDs on the front panel show as above.

* Battery info - MKI & MKII: Shows battery voltage and state of charge (%). MKII only: Also shows estimated battery capacity and capacity remaining in mAh along with current flow in/out of battery in mA (-ve is out of battery, +ve is in, i.e. charging).

* About - shows firmware version of main board, and zc624 output board

## Shock collars
If the box is fitted with a 433Mhz AM transmitter in J11 on the main board, it can be used to control one specific type of shock collar:

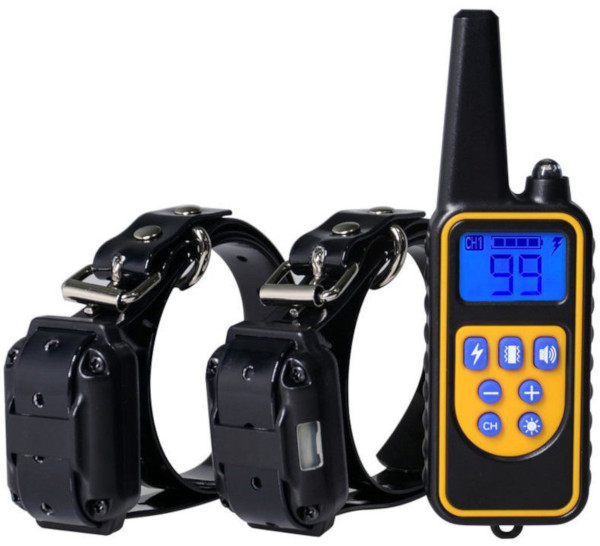
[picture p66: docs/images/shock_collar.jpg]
Shock collar


(note that there is 915MHz variant of these that looks identical on the outside...)

These will only function in certain patterns which have simpler output demands, and is generally pretty experimental.

[device layout]: images/layout.png "Device layout"
[screen layout]: images/screen.png "screen layout"
[shock collar]: images/shock_collar.jpg "Supported shock collar"

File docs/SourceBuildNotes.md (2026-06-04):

# Building

## Docker
If you just want to build the current dev release, the quickest and easiest way to compile the firmware is to use the docker image ([source](../misc/Docker/)).

Steps to build the dev branch, adjust paths as required:
```
cd /data
git clone -b dev https://github.com/CrashOverride85/zc95.git --recurse-submodules
docker run -v /data/zc95:/src --rm ghcr.io/crashoverride85/zc95-build:1.1.0
```
All going well, complied firmware images should appear in /data/zc95/source/CompiledUF2/

### pico2
This project has been designed around and tested with the original pico (rp2040). However if you really want to build for the pico2, add `pico2` as the first and only command line argument to the container, i.e.:
```
docker run -v <path to repo>:/src --rm ghcr.io/crashoverride85/zc95-build:1.1.0 pico2
```
I do not recommend using pico2's for the zc95:

- This project is likely going to continue to target the original pico(w) for as long as it is readily available in order to remain compatible with exiting zc95's, so the advantages of the pico2 (and there are many) will be wasted
- It doesn't include the bootloader; so firmware upgrades via serial - and likely later from the UI - won't be possible
- I'm not going to be routinely testing future changes even build for the pico2, much less work as intended
- I've barely tested it. On 2026/04/16, it does build from the dev branch, boots up, and appears functional at first glace 🤷‍♂️️

You have been warned.

## Local setup

Quick start building notes for Linux, tested on a fresh install of Debian Bookworm, but should be very similar for any Debian derived distro.
For other environments, see the [pico getting started guide][gs].

This is the bare minimum to get to the point where you can build a binary to copy to the Pico.

### Install build tools
```
apt-get install git cmake gcc-arm-none-eabi libnewlib-arm-none-eabi build-essential libstdc++-arm-none-eabi-newlib python3 python3-pycryptodome
```

### Setup pico-sdk
```
git clone https://github.com/raspberrypi/pico-sdk.git
cd pico-sdk
git submodule update --init
export PICO_SDK_PATH=`pwd`
cd ..
```

### Get zc95 source & build
```
git clone https://github.com/CrashOverride85/zc95.git --recursive
cd zc95/source/zc95/
cmake .
make

cd ../zc624/
cmake .
make
```
This should result in the two pico binaries being built that can be copied to the pico. 
* zc95/source/zc95/zc95.uf2 - for main board
* zc95/source/zc624/OutputZc.uf2 - for output board

## Debugging
For small fixes/changes/tweaks the above is fine, but requires manually copying to Pico via USB, and doesn't allow for debugging, so very quickly gets tedious for larger changes.

The pico-sdk integrates really well with Visual Studio Code & an SWD debugger, allowing single keypress build & upload, along with setting breakpoints, stepping through code, etc., so that would be my recommendation for a development environment. 
For the SWD debugger, I'm using a J-Link as that's what I had, but a [Picoprobe][pp] seems to be the Raspberry Pi recommend option, and well documented elsewhere.

Describing that setup is documented in the [pico getting started guide][gs], see Chapter 7 & Appendix A.

It's probably worth noting that the code is using both cores, so bare that in mind if unexpected things happen when debugging, setting break points, etc.

[gs]: https://datasheets.raspberrypi.com/pico/getting-started-with-pico.pdf
[pp]: https://www.raspberrypi.com/products/debug-probe/

## BTStack patch
In order to get one of the bluetooth remotes to work (#7 in [the bluetooth notes](./Bluetooth.md), and potentially later ones), in `pico-sdk/lib/btstack/src/ble/sm.c` I needed to comment this out:
```
        default:
            // Unexpected PDU
            log_info("Unexpected PDU %u in state %u", packet[0], sm_conn->sm_engine_state);
        //    sm_pdu_received_in_wrong_state(sm_conn);
            break;
    }

    // try to send next pdu
    sm_trigger_run();
}
```
(in `sm_pdu_handler()`, around line 4788)

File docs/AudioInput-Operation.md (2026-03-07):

# Audio Input

Audio input can be either line level or mic level (selectable), and optionally power can be provided for mics. It's intended to be used with PC style electret microphones. I've found this microphone works particularly well (and with the mk312bt): https://www.amazon.co.uk/gp/product/B07L6H7YYQ/

## Mk1 only:
When the audio input board is installed, the Aux port on the front can be configured for either Audio input (default) or serial I/O (currently only debug out).

## Configuration
There are two relevant menus for configuring audio - "Audio input", and for MK1's "Hardware config" ("Audio" and "Aux port use").

### Audio input
This is used to set gain, enable/disable microphone preamp (so set for mic or line level), enable/disable microphone power, and show a preview of the audio signal to aid setting volume and gain.
The configuration set here will be used in patterns, and will be retained after power off. 

On opening the screen, it should show the currently configured settings. E.g.:

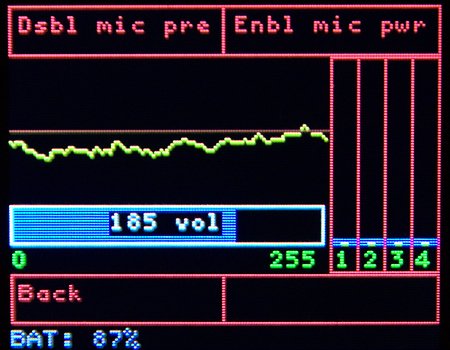
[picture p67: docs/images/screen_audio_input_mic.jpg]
Audio input mic


The above screenshot is when in microphone mode, with the microphone power disabled (using a self powered electret mic). Options:
* Ddbl mic pre: Disable microphone preamp - i.e. switch to line level input
* Enbl mic pwr: Enable microphone power - provide power for an unpowered electret microphone. Note this should not be used with dynamic mics or when connected to a line level output

Disabling the mic preamp switches to line level input, and shows stereo input:

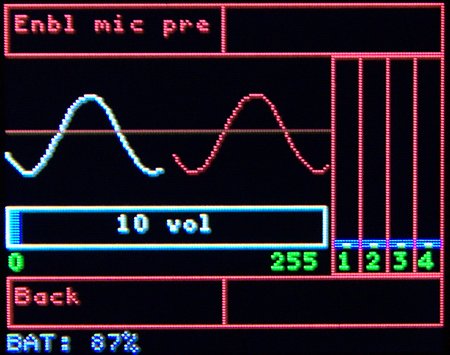
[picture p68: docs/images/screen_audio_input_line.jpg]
Audio input line


### Hardware config
Only applies to the Mk1 which has a single, dual purpose, serial+audio 3.5mm socket (Mk2s have separate/dedicated serial & audio sockets).

There are two relevant entries in the hardware config menu:

1. Audio. 
This is used to control audio functionality, and has 3 options
    - Auto - Default. If the audio output board is detected (specifically, if the MCP4651 digital potentiometer is found), then audio functionality is enabled, otherwise it's hidden.
    - On (no gain) - Audio input functionality is enabled regardless of the audio board being detected or not. But the gain/volume option is removed, as that requires the digital potentiometer to be present.
    - Off - hide audio functionality even if audio input board found

2. Aux port use. 
With the audio board present, the zc95 has the ability to switch the use of the port between serial I/O (for remote control or debugging output) and audio input. Two options:
    - Audio input - Default. Port is used for audio input
    - Serial I/O - port is used for serial I/O

Note this option has no effect if the audio input board isn't present; the port is always routed to the serial interface.

[Audio input mic]: images/screen_audio_input_mic.jpg "Audio input configuration screen - mic"
[Audio input line]: images/screen_audio_input_line.jpg "Audio input configuration screen - line input"

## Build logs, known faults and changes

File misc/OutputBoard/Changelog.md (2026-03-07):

## OutputModule changelog
### v0.2
- Fixed snubber. Swapped diode for diode + TVS diode (thanks to Onwrikbaar for suggestion)
- _Might_ now also work with larger 42TU200 transformers (currently out of stock, so unable to test)
- Increased resistor values for status LEDs to reduce brightness
- Swapped 4x 100uF through hole electrolytic capacitors for 4x 220uF tantalum capacitors
- Project updated to KiCad 6

### v0.1
First public version

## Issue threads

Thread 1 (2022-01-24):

Big Thanks & Audio

seuchato, 2022-01-24:
Hi
1st: Big fat thanks for developing this! Excellent work, indeed!
I ordered the stuff and expect it to arrive at my home soon. I'd be very interested in adding an audio input. Is there something else than the extra daughter board to be considered when assembling the pcb?
Do you have an eta for the audio daaghter board?
I'd like to suggest to add the audio jack seperate from the serial jack. I think it would be nice to have both.
Greez
seuchato

CrashOverride85, 2022-01-24:
Hi, I'm not sure about the audio input yet, it's on my list, but if I'm honest I'd say not soon, it's more an idea at this point.

I agree it'd be nice to have both audio and serial, but adding an audio jack would mean new versions of the front panel and main board, in which case it'd probably make more sense to just integrate the audio input circuitry straight onto the main board (there's plenty of space), and forget about a daughterboard.

The reason for adding the possibility of a daughterboard in the future was so audio input could to be added to an existing box, rather than having to build another.

bkifft, 2022-04-22:
Does it actually need analog audio in? Shouldn't the pi's  be beefy enough, to parse mp3 straight to output? Skipping the DAC and ADC.

If someone can describe me the input output behaviour I can try to do a proof of concept.

CrashOverride85, 2022-04-22:
Need? not really really, it's very much on my nice-to-have list :)
It's using Pico's not Pi's, which I don't think are really powerful enough to decode MP3 in any practical way - although a quick google suggests it is possible if that's all it's doing and with very low bitrate MP3s.
Getting MP3's into it would also be awkward... in theory there's a micro SD slot on the back of the display module, but I can't remember if it's connected, and even if it is, having to open the box to change the MP3's wouldn't be great.

I'll be honest, an internal digital source isn't something I'd considered, though. I've only ever used the mic audio input on a mk312bt, and that was just to trigger off, ummm, noises, made by the person attached to it, rather than dedicated estim audio files.

>If someone can describe me the input output behaviour I can try to do a proof of concept.
Heh, yes, I think figuring out that behaviour is likely going to be the hardest part, and a large part of the reason I've not attempted this yet.

CrashOverride85, 2022-08-27:
Audio input board and first pattern using it now added (#13). The current pattern is only really suitable for microphone input, but I hope to add a couple more over the next few months.
Its using the existing hardware for the time being, so no extra sockets, etc. on the front panel.

Closed 2022-08-27.

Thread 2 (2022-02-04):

Deviation kicad-gerber

electric1711, 2022-02-04:
Hi

Thanks for the project.
I'm in the process of building one.
I noticed that the Gerber flies for the frontpanel are available in version 0.2 the bom list and kikad files are in version 0.1.
Here is the question, are still all unmarked resistors 10k except those marked with 100R.
Is U2 still a PCF8574 and what is the replacement for U1.
What are the holes above the POTs for?

CrashOverride85, 2022-02-04:
Hi,

I am so sorry... I seem to have uploaded completely the wrong gerber for that board :(
It was for an alternate version of the front panel that used 4 rotary encoders for the channel power adjustments instead of 4 POTs.
I have corrected this, and uploaded the correct gerber.
Well spotted, and thanks for letting me know - I can only apologise if you've already ordered the board :/

BTW, which holes did you mean?

Crash

electric1711, 2022-02-04:
Hi

Thanks for the quick reply
Fortunately, I noticed it before ordering.
The additionally holes would probably have been for other pots (v0.2) .

Closed 2022-02-04.

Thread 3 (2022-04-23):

Polyfuse is undersized

CrashOverride85, 2022-04-23:
The current Polyfuse is a BK60-050 with a trip current somewhere between 0.5A and 1.0A, which is a bit too low. In TENs mode, when set to a large pulse width and high frequency with all the channels set to max, the box can pull ~900mA, which is enough to trip the fuse.
The schematic calls for a 1A fuse, so a BK60-090 (0.9A - 1.8A) or BK60-110 (1.1A - 2.2A) is probably a better option.

heavyrubberslave, 2024-09-01:
Would this be the recommended replacement: https://www.lcsc.com/product-detail/Resettable-Fuses_Brightking-BK60-110-DI-E0-6_C523033.html

CrashOverride85, 2024-09-01:
Yes, that should be fine.
TBH I'd probably go for the lower rated [BK60-090](https://www.lcsc.com/product-detail/Resettable-Fuses_Brightking-BK60-090-DI-E0-5_C523029.html) instead, as in my experience so far, it's only possible to trip the current fuse if you're deliberately trying to, so I think the BK60-110 is likely higher that it needs to be.

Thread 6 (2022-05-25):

Holes for potentiometers on front panel too small

CrashOverride85, 2022-05-25:
The holes for potentiometers on front panel are a bit too small, and need to be manually enlarged.
Need to fix gerbers to increase the size of these holes

Closed 2022-07-15.

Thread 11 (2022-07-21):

Possible DAC alternative?

shiny-mira, 2022-07-21:
Hi,

first - let me say thank you - this is a really great project and I am looking forward to try to build this.

I noticed that the DAC that is used in this (the MCP4728) is currently completely unavailable; Mouser, e.g., gives an estimated in-stock date of December 2023. I was just wondering if you randomly know of another DAC that one might be able to use instead - or if I just have to wait it out.

Thank you again :)

CrashOverride85, 2022-07-22:
Ahhh, that sucks, I hadn't realised. No - I'm not aware of anything else that could be used as a drop in replacement that's available :(
If I can find another suitable DAC that's still got plenty of stock in most places, I might have a go a tweaking the design to use that - having footprints for both may be an option

It does look like the MCP4728 is still in stock at conrad (I've never bought anything from them before though).

CrashOverride85, 2022-10-13:
It looks like the MCP4728 is currently in stock at LCSC, although at a somewhat inflated price. I guess an alternative is to buy a board with it on and remove it - e.g. the Adafruit ADA4470, which is about the same as the part costs at LCSC anyway.
Hopefully the parts situation will improve early next year...

Closed 2022-10-15.

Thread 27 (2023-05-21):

Problems with the adjustment knob

piepa12, 2023-05-21:
I also built myself a box and I think the concept and the idea are great!

I have a problem with the adjustment knob. I have to turn it very slowly so that the values change. Is the problem known or did I install the wrong component?

Greetings from Germany.

CrashOverride85, 2023-05-22:
hmmm, how slowly? You can't turn it that fast, but it shouldn't be much worse than, for example, the adjust dial on a 2B (if you have or have used one)

piepa12, 2023-05-22:
I made a short video of the mistake.

[Video](https://youtu.be/Rgsg2NaYpd8)

CrashOverride85, 2023-05-22:
Thanks, yeah, something is definitely wrong there, it should be possible to adjust it a lot faster than that.
Is it the same rotary encoder from the BoM, or if not, could you let me know the part number?

But I think it's most likely being caused by the interrupt pin of U2 (pin 13) on the front panel not being connected to the Pico (pin 9) on the main board, could you try measuring for continuity between the two?

If there isn't continuity, I'd suggest checking the cable between the main board on the front panel - the interrupt is on pin 2.

Closed 2023-07-31.

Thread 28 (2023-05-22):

Clear EEPROM

CrashOverride85, 2023-05-22:
Having a way to clear the EEPROM is probably a good idea to aid diagnosing some issues. E.g. hold down a certain button (or combination of buttons) on startup and the EEPROM will be reset to defaults.

CrashOverride85, 2023-06-04:
Can now hold down top right button when powering up to clear EEPROM (but requires confirmation by pressing bottom left button when prompted)

Closed 2023-06-04.

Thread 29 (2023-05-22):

Serial debug - main board

CrashOverride85, 2023-05-22:
Improve documentation to include notes on  the different ways to get debug output from the main board.

Documentation for serial output from output board looks ok.

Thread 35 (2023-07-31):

Menu layout in pattern_gui.py

RupertB-ES, 2023-07-31:
It would be good to add a gui_column tag to menu items in scripts - could be single or groups
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

CrashOverride85, 2023-07-31:
Interesting idea, I'll see if I can add this, but there's a couple of things I'm working on before that

CrashOverride85, 2023-08-12:
v1.6 now allows "group" to be specified in Lua scripts

Closed 2023-08-12.

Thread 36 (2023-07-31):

A few small build notes

shiny-mira, 2023-07-31:
Hi,

thank you very much for creating this repository. This is an awesome project.

I finished building my first zc95 a couple of weeks ago - and I have one small comment that might be neat for the manual, plus a couple of notes about deprecated components (with replacements for most of them).

For the "Front panel controls" board, it might be nice to somehow note the orientation of the PCF8591 - I don't think that it is currently indicated on the board; I had to look it up in the Kicad files.

To continue with the PCF8591 - sadly, NXP just EOL-ed that chip, and it will not be available after January 2024. The  notice for this is available here: https://media.digikey.com/pdf/PCNs/NXP/202306034DN%20.pdf. I am not sure if there is an easy substitute for it.

Two of the LCSC components are no longer available; there are easy substitutes for them.

For the front panel controls, C191532 is discontinued; I used C216315 instead. Main & output boards: C50984 -> C124410

Thank you very much again,
 Mira

CrashOverride85, 2023-07-31:
Thanks for your feedback 🙂
Those suggestions look good, thanks, I'll try and update the BoM and build notes this week.

I'm not sure what to do about the PCF8591 yet, I was trying to keep that board as easy to hand solder as possible, and IIRC that didn't leave many choices at all for the ADC.
Hopefully it's still going to be available for a while yet, whilst I figure out what to swap it for - thanks for the warning.

CrashOverride85, 2023-08-05:
Build notes & BoM updated, thanks :+1:

Closed 2023-08-05.

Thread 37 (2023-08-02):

lua upload issue

RupertB-ES, 2023-08-02:
Error uploading lua script - syntax appears to be clean according to https://www.jdoodle.com/execute-lua-online/
ps Github doesn't support attaching lua files either !

C:\zc95>python lua_upload.py --script ./lua/ramp_exp_phases_rb.lua --ip 192.168.1.157 --index 3
Connecting
Connection opened
Uploading...
Didn't get any message, expected Ack (msgId = 261)
[ramp_exp_phases_rb.txt](https://github.com/CrashOverride85/zc95/files/12237843/ramp_exp_phases_rb.txt)

Websocket connection closed
Failed

C:\zc95>python lua_upload.py --script ./lua/ramp_exp_rb.lua --ip 192.168.1.157 --index 3
Connecting
Connection opened
Uploading...
Done!
Websocket connection closed

CrashOverride85, 2023-08-02:
Hmm, looks like it's hitting a line length limit. At the moment, each line is limited to ~155 characters. If you break up the 3 long lines with line breaks, it should upload ok.

I'll look at increasing this limit, and also include an error when whatever the limit becomes is reached.

RupertB-ES, 2023-08-02:
Thanks
I simplified the logic and it fixed the problem pro tem
Also the debug print statement seems to have a real hit on performance

CrashOverride85, 2023-08-03:
Yeah, I don't think there's much I can realistically do about that one :(
I'd suggest using print() really is only good for debugging - Loop() is called often enough that having it call print will badly affect it, to the point it may start dropping debug messages.

CrashOverride85, 2023-08-12:
Should now be resolved in v1.6 by increasing max line length limit, and showing an error then the new limit is hit

Closed 2023-08-12.

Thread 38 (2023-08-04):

zc.SetPower(chan,0)

RupertB-ES, 2023-08-04:
Setting the power to 0 on a channel seems to be ignored in code - is this intentional - setting power to 1 works as a minimum
i.e. is this a documentation bug and the power range should be 1-1000 not 0-1000

CrashOverride85, 2023-08-04:
No - definitely a bug; there's no good reason why it's not possible to set the power for a channel to 0

Closed 2023-08-12.

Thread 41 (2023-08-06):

Issue on script startup

RupertB-ES, 2023-08-06:
Got this trace on starting a pattern - its worked ok up to now and I hadn't changed it at all

C:\zc95>python pattern_gui.py --ip 192.168.1.154 --index 3
Connecting
Connection opened
Didn't get any message, expected PatternDetail (msgId = 2)
Traceback (most recent call last):
  File "C:\zc95\pattern_gui.py", line 220, in <module>
    gui = ZcPatternGui(root, pattern, zc_messages, rcv_queue, args.debug)
  File "C:\zc95\pattern_gui.py", line 24, in __init__
    self.InitDisplay(self.root)
  File "C:\zc95\pattern_gui.py", line 76, in InitDisplay
    self.DrawPatternFrame(root, row=0, col=0)
  File "C:\zc95\pattern_gui.py", line 92, in DrawPatternFrame
    Label(pattern_frame, text=pattern["Name"], font='Helvetica 18 bold').grid(row=0, column=0, padx=5, pady=5)
TypeError: 'NoneType' object is not subscriptable

RupertB-ES, 2023-08-06:
PS Worked ok the next time I ran the same command

RupertB-ES, 2023-08-08:
Its only done it the once - I notice that the speed of running a remote pattern via python seems a bit variable especially initially  launching the gui

CrashOverride85, 2023-08-09:
hmmm, interesting, thanks. How fast the pattern actually runs _shouldn't_ be affected by running remotely, even if the GUI runs a bit slow

RupertB-ES, 2023-08-09:
I think its just the speed of the python vm launch/run but its surprising its so variable as its on an i7 box with nothing else much going on

CrashOverride85, 2023-08-10:
I wonder if it's a wifi thing / not a great connection for some reason. It shouldn't me taking long for the gui to start up

RupertB-ES, 2023-08-10:
I am seeing some WiFi strangeness but haven't figured out a pattern - it seems to be something DHCP Lease related - other wireless devices I have seem to be ok - phones/Echo Dots.
The connection drops after several hours sometimes a couple of days and doesn't reestablish unless I power cycle the box  - just selecting reconnect gives me a message Connected - No IP most times

RupertB-ES, 2023-08-11:
Similar error today in pattern list after rebooting box
5>python pattern_list.py --ip 192.168.1.146
Connecting
Connection opened
Didn't get any message, expected PatternList (msgId = 2)
Traceback (most recent call last):
  File "C:\zc95\pattern_list.py", line 22, in <module>
    patterns = zc_messages.GetPatterns()
  File "C:\zc95\lib\ZcMessages.py", line 52, in GetPatterns
    return response["Patterns"]
TypeError: 'NoneType' object is not subscriptable

CrashOverride85, 2023-08-11:
Thanks - I may have seen the DHCP thing when fairly rapidly rebooting the box, and figured it was probably just the router. I'll take a closer look at that

CrashOverride85, 2023-08-13:
I'm starting to wonder if WiFi flakiness is related to #46  and #25

RupertB-ES, 2023-08-13:
Just reflashed the box this morning - it feels snappier but have not tried anything in anger on it

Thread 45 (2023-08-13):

UT232A is out of stock most places, worth noting it on the BoM

jlatex, 2023-08-13:
UT232A has been unavailable at LCSC for some time.  MAX3232CPE+ is a pin compatible alternative, I got mine from mouser as 700-MAX3232CPE.  It works.

CrashOverride85, 2023-08-13:
In order to try and avoid having to order too many parts from different places, I think these two parts that LCSC sell are also pin compatible:
* C427446 - SIT SIT232EPE
* C968668 - XINLUDA XD3232

I'm going to order them and check they work, and update the BoM if they do. In the meantime, I'll list the MAX3232CPE+ as an alternative part.

jlatex, 2023-08-13:
Also those are both significantly cheaper than the MAXIM part!

Closed 2023-08-13.

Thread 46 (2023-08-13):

Wifi Config AP mode fails - add note to docs about known issue

jlatex, 2023-08-13:
With 1.6 release and with current git head, after selecting 'config wifi/ap mode' on the UI the UI freezes and the box is unresponsive.  Serial log:

```
CMenuApMode()
SetupWebInterface()
Loop time: 514, batt: 100
CAnalogueCapture::stop()
CAnalogueCapture::stop() done
CMenuApMode::wifi_scan(): Start scanning for wifi networks
CWifi::init(): wifi/cyw43 init success
dhcp_release_and_stop()
```

Since this is a new box I've not had this working yet

jlatex, 2023-08-13:
Oh, this might be https://github.com/CrashOverride85/zc95/discussions/25 I'll try that!

jlatex, 2023-08-13:
Okay, this is #25 and our friends box has the same problem, so suggest adding a note to the discussion from the docs for now until there's a solution.  Updated title of this issue

CrashOverride85, 2023-08-13:
Thanks for reporting this - I'm going to treat this more as a bug in the design (poor choice of MOSFET as you've identified), than just a documentation issue. Although short term, I agree that's a good idea.

CrashOverride85, 2023-08-13:
Added to known issues, will look for a more suitable mosfet

jlatex, 2023-08-15:
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

CrashOverride85, 2023-08-15:
Ahh cool, good to know it works, thanks for letting me know. I'm going to try a smaller diode when it arrives, and update BoM & build notes to match

Closed 2023-08-26.

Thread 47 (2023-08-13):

Add quick 'get starting building the source code' notes

jlatex, 2023-08-13:
I'd not built anything for rp2040 before, so would save a little time if there was a note somewhere of the quick steps to get up and running

i.e.

- checkout repo, ensure recursive (if you already have it checkout out then make sure to update the modules example 'git submodule update --recursive')
- get the pico-sdk (example 'git clone https://github.com/raspberrypi/pico-sdk.git; cd pico-sdk/; git -C . submodule update --init; export PICO_SDK_PATH=`pwd`' )
- get the arm gnu toolchain such as using https://lindevs.com/install-arm-gnu-toolchain-on-ubuntu and ensure it's on your path (example 'export PATH=$PATH:`pwd`/gcc-arm-none-eabi/bin/')
- in the zc95/source/zc95 directory 'cmake -Wno-dev .' then 'make' as usual

jlatex, 2023-08-14:
Thanks btw, got it working with jlink/vscode too which is great for debugging (although as far as I can tell you have to have the serial port connected as well to see the debug output)

CrashOverride85, 2023-08-14:
Ahhh cool :+1: , it makes life so much easier.
And yeah, still need to use a serial cable to get the debug output

Closed 2023-08-13.

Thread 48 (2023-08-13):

Consider adding a serial baud rate menu config option

jlatex, 2023-08-13:
By default the serial port runs at PICO_DEFAULT_UART_BAUD_RATE (115200).  My longish serial cable and usb serial adapter on aux couldn't keep up with that and so I edited CDebugOutput.cpp to drop the baud rate to 38400.  Ideally this would be a menu config option.

CrashOverride85, 2023-08-13:
Depending on what you're using serial for, this might be slightly harder than it seems.
For the new remote control & Lua upload over serial stuff, having it changeable via the menus should be ok.

But for debug/diagnostic output, the main issue I can see is that on startup there's a few things it does before reading the EEPROM, so it's going to be outputting at the default baud rate until that happens. Switching baud rates during startup doesn't seem ideal really.

jlatex, 2023-08-13:
That's fair; I don't mind keeping mine at 57600 or something by just compiling it myself.  And if anyone else has issues with the speed perhaps consider using that as the default.

Closed 2023-08-13.

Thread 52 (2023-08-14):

Wishlist item, display power levels

jlatex, 2023-08-14:
While using a zc95 we miss being able to see the power level as a percentage. This is handy when setting a level similar to one used before (knowing that say a 57 on channel A is a 'sweet spot'), but also when adjusting the control (wanting to turn it up by 1%). But the display doesn't have a lot of space for it with the current UI.

This issue is a wishlist for the future to find a nice way to display power levels.

I did a quick hack that overwrites the screen with the levels of the four channels whenever you change one of the levels (vanishing again after half a second ish) and that works okay, but it looks a bit messy (and hagl doesn't have a nice scaled large font so it just scales the bitmaps).  It's here, but not as a PR as it's probably not for everyone.

https://github.com/jlatex/zc95/compare/main...jlatex:zc95:displaypowerlevels?expand=1

CrashOverride85, 2023-08-14:
Interesting idea, probably wouldn't hurt to have as an optional thing that can be turned on/off as wanted

CrashOverride85, 2023-08-16:
Hi, yeah, I'm also crashoverride85 on discord.
Speaking of discord, I'd recommend joining [Joanne's E-Stim Community](https://discord.gg/rY8C27S) discord server, I kinda assumed that's how you found the project. There's a few people in there particularity knowledgeable about estim box design - the #boxes-pulse-based-diy channel is especially relevant to this kind of project

jlatex, 2023-08-22:
Tested, looks great to me!  Thanks!

Closed 2023-08-22.

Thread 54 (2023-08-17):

Confused menu when you have no audio board with 1.6

jlatex, 2023-08-17:
seemed to happen occasionally after using a mode the menu would be a bit confused, without an audio board the menu doesn't show the audio modes, but you occasionally get them anway:

reproducer for me: turn box on, select triggered climb, hit back, select climb with pulse - you get audio threshold instead, and the menu options now don't match what you get.

CrashOverride85, 2023-08-17:
Thanks for reporting this, should be fixed in the next version

jlatex, 2023-08-17:
works!

Closed 2023-08-17.

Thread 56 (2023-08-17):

MQTT/XToys integration

RupertB-ES, 2023-08-17:
I believe there is a LUA implementation of MQTT -any plans on this or other routes to integrate with XToys?

RupertB-ES, 2023-08-18:
This is what caught my eye https://github.com/xHasKx/luamqtt

CrashOverride85, 2023-08-18:
I think the problem's going to be that it depends on luasocket, which depends on a BSD-style sockets API, which LwIP used by the Pico SDK doesn't really provide. Plus I think trying to run Lua scripts of that size/complexity just isn't going to work well (if at all).
I think the way to get mqtt support in Lua would be to add a wrapper around the LwIP MQTT client to expose it in the Lua environment.

Also I need to have a think about how it would work when running Lua script locally, as at present, the box will only connect to WiFi when in remote access mode.

RupertB-ES, 2023-08-19:
I guess there are 2 routes - initially could the LUA client just handshake with a python app and let python do the work but in the longer term having the LUA client "phone home" and start the wifi in code would be the better way performance headroom permitting.

CrashOverride85, 2023-08-20:
Yeah, doing _something_ via the python app might be an option too

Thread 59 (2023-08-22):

Don't display Up/Down button text if there is no action

jlatex, 2023-08-22:
When in a mode that has no options, buttons C and D display the text up/down even though they have no action (and so is a little confusing when there's a bar graph if you forget it's controlled by the rotary encoder)

jlatex, 2023-08-23:
wfm

Closed 2023-08-23.

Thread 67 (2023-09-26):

OK LED on output board doesn't do anything

CrashOverride85, 2023-09-26:
There's an LED labelled "OK" on the output board, but currently doesn't do anything.
Either document in the build notes that it's not used, or make it do something vaguely useful, and document that.

Closed 2023-10-07.

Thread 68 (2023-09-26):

Update self test to check for working SPI comms between main and output board

CrashOverride85, 2023-09-26:
If there's a break in the SPI lines between main and output board, it currently still passes self test, but there is no estim output.
It should be possible to detect this during the self test / hw check at power on, and report it to aid debugging.

Closed 2023-10-08.

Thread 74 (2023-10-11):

Arduino library to control ZC95 via serial

CrashOverride85, 2023-10-11:
Add a basic Arduino library that can be used to control the ZC95 via serial.
(from #72 )

CrashOverride85, 2023-11-22:
Very basic Arduino lib added. More to follow at some point.

Closed 2023-11-22.

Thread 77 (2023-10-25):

PIO program question.

martinmikula, 2023-10-25:
Hi,

at first thanks for great project...
I'm not very good in pio programming in RP2040, but i found one thing which doesn't make sense for me:

you pulling block - 32bits into OSR register
`pull block`
then shifting 2x8bit into x and y regs
`out x, 8
out y, 8`
and then shifting 32bits into null
`out null, 32`

How the PIO works if there is not enough data to shift? I found that it can be configured to auto pull, but i think this is not the case, otherwise the x and y will be messed up... Probably you will also find if there is a problem, I just not understand so writing for clarification. :)

BR
Martin

CrashOverride85, 2023-10-26:
I've only written two PIO programs, and that was a couple of years ago now... so I can't quite remember unfortunately 😥️
I _think_ the reasoning behind the shift was just to make sure any remaining data got discarded, as only the first two bytes have any meaning.
When the `pull block` runs, it grabs the next 32bit entry on the FIFO buffer.
The code seems to do what it needs to, which is why I've not looked at it for so long

martinmikula, 2023-11-02:
Ok, than it's fine... :) I'm also programmer and hw designer, so if you have any new ideas or just need some help with some new features or problems please let me know... :) I don't have the hw now, but i'm working on it... :)

CrashOverride85, 2023-11-04:
heh thanks :)
No major changes planned for the hardware in the short term, but always trying to add bits to the firmware :slightly_smiling_face:
If you get one built, I'd deffo be interested in hearing how you get on with it, especially if it "just works", I only tend to hear about the ones that don't lol

Closed 2023-12-13.

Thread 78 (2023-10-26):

"ZC624 is not ready " issues when using the ZC-624 standalone

anonymous2nd, 2023-10-26:
Hi guys, thanks for the great work first. Really well done.

I use the ZC-624 output module separately for a custom box. The module is connected to an ESP32 (Az-Delivery).

I ordered 5 pcbs of the ZC-624  from JLC and got one working instantly. (This tells me that it's not an issue with my connection to the ESP32 or the connections)

The other 4 boards are assembled with exactly the same components (yes I use the correct mosfets) but none of them works.

When I run the demo firmware on the ESP32 I get the following message in the Serial Monitor:

MOSI: 23
MISO: 19
SCK: 18
SS: 5
ZC624 Version string: v1.6
Major version: 0
Minor version: 3
ZC624 is not ready (status = 1073500848)
Error: Zc624 is not ready. Stop.

What really confuses me is that the version string seems to be transmitted successfully via I2C. The major/minor version is a bit weird, but probably I overlooked something and 0.3 is correct? I expected 1.6 as maj.min. But then the scary stuff starts to begin. I checked the Raspi firmware and as far as I saw, it should either return 0, 1 or 2 but definitely not  1073500848 as the status. How is the version string correct but I2C transmits garbage as the status?

Another weird thing are the LED states. When I connect the 5V 3.3V and 5V LEDs glow. When I connect the 12V supply, the 12V LED glows and the 9V LED glows too but it only glows a short time and instantly fades then (capacitor?). The OK LED never glows. Should the 9V LED always glow when 12V is powered, or is this the expected behavior?

Do you guys have any idea how that can happen and how I can fix the boards?

What I tried already:
- Different ESP32 and Raspberry Pico
- Flashing the firmware on both again
- Checking the connectivity outside of my normal module using breadboard

Thanks in regard. Keep up the great work.

PS: I'm using version 1.6 and I replaced the 50V 220uf capacitor with a 25V 220uf capacitor but that should be fine, right?

CrashOverride85, 2023-10-26:
1. Major/minor versions
Yeah, that's right. It's more of an API version than a firmware version, and the ZC95 main board uses it to figure out if the zc624 version is compatible, without unnecessarily requiring an exact match.

2. 1073500848 state
That has to be a bug in the arduino library, I'll try and have a look at the weekend. It's reading an 8bit value, so anything over 255 is nonsense. I think it's just a display issue, and it it will be getting valid value, just not outputting it properly

3. LED state
In v1.6, the OK LED does nothing (always off), so that's to be expected. It's more useful in v1.7, but I still need to update the arduino library to work with v1.7.

The 9v supply will be switched off if the zc624 fails it's self test, so that's most likely more a symptom of it failing its self test, rather than an issue itself, so yeah - kinda expected behaviour.

4. Capacitor
Yeah, a 25v rated one is fine

I would suggest taking a look at the zc624 trouble shooting notes:
https://github.com/CrashOverride85/zc95/blob/main/docs/Build.md#zc624-output-module

But if you connect up a 3.3v serial adapter (115k baud) to the output board, it should tell you why the self test is failing.

CrashOverride85, 2023-10-29:
If you update the zc624 to v1.7 and use the new version of the arduino library, the state should be correctly reported, and the OK LED doing something more useful.

CrashOverride85, 2023-11-04:
Nice, great to hear you've fixed it :)
The new FW & Arduino lib version shouldn't really make any difference if it's all working, but updating would at least give non-corrupted error messages if it goes wrong

Closed 2023-12-05.

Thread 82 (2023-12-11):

Increase script size limit

CrashOverride85, 2023-12-11:
### Discussed in https://github.com/CrashOverride85/zc95/discussions/81

Lua scripts are currently limited to around 24k. Look at increasing this to at least 48k for one of the script slots, if not all of them.
Confirm that the upload utility still works, as it likely needs tweaking to wait a little longer after the last line of the script has been sent.

CrashOverride85, 2024-02-29:
Will be in v1.8.

But see #81 for a v1.7 fw with this change added in

Closed 2024-02-29.

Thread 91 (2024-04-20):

Uploading a large script causes a crash (bad stack size)

CrashOverride85, 2024-04-20:
See https://github.com/CrashOverride85/zc95/discussions/81#discussioncomment-9132948

Notes mostly for future me.

Uploading the script attached to the above discussions causes core0 to crash (hardfault).

## Observations:
* Disabling stack guards (PICO_USE_STACK_GUARDS) causes the upload to work
* On crashing, the stack pointer isn't close to limit, so it doesn't appear to be a stack overflow
* PICO_STACK_SIZE is set to 12288. _Reducing_ it to 8192 causes the upload to work, but breaks remotely running some scripts due to stack overflow (stack pointer at limit).

Although it doesn't appear to be explictly documented in the pico C SDK, the limit for PICO_STACK_SIZE seems to be 8k (multicore complicates things, so the limit is sort-of 4kb).
Going beyond that means the end of the stack - and the write protected section of memory that is the stack guard - ends up in memory that can be used for the heap.

### Cause of crash
Due to the stack/heap overlap, malloc is returning memory which includes the stack guards, and as soon as that gets written to => hardfault. So not a stack overflow, but the heap expanding to the area assigned to the stack.

## Fix
Options:
### 1. Expand stack properly
Keep `PICO_STACK_SIZE=12288`, and create a custom linker script which is just a copy/paste of the SDK `memmap_default.ld` named `memmap_zc95.ld`, with:
`RAM(rwx) : ORIGIN =  0x20000000, LENGTH = 256k `
changed to:
`RAM(rwx) : ORIGIN =  0x20000000, LENGTH = 244k `

Then added to `CMakeLists.txt` as:
`pico_set_linker_script(zc95 ${CMAKE_SOURCE_DIR}/memmap_zc95.ld)`

This means the heap can't ever expand into the region where the stack (and stack guard) is, effectively working around the 8kb stack limit.

Trying to upload the script with this change results in the error:
```
Opening: /dev/ttyUSB1
Connection opened
Uploading: |██████████████████████████████████████████████████| 100.0% Complete

Got error message:
    Invalid script: not enough memory
Connection closed
Failed
```
So significant improvement - it's no longer crashing, and is giving a reasonable error. And mostly confirms that it is the heap growing into the stack as the cause, as the 4kb reduction is enough to cause malloc to fail (note that `PICO_MALLOC_PANIC=0`, hence Lua being able to handle this rather than a panic).

### 2. Reduce stack usage
Set PICO_STACK_SIZE to 8192, and fix the issue where a lot of memory is being (unnecessarily!) used on the stack when generating messages to send of serial/wifi in remote access mode.

Going with 2 as it actually fixes the issue, but it's good to understand _why_ it was going so wrong.

CrashOverride85, 2024-04-20:
Mostly fixed in branch fix_large_script_crash, but need to have a rethink about how large scripts are uploaded. ATM the full 48k is allocated in memory at the start of the upload, then written to flash at the end.
It probably want's changing to write it in blocks, with a marker somewhere to indicate it's a valid script (maybe set the first block to nulls or something until it's finished).

CrashOverride85, 2024-04-25:
Fixed in dev, fix will be in version >=1.9

Closed 2024-04-25.

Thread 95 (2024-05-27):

Option to reduce output power

CrashOverride85, 2024-05-27:
Other boxes with a similar maximum output power have an option to reduce the output power.
It probably makes sense to add such an option to the ZC95.

Things to consider:
- What options to have, e.g. something like Low, Normal and High, or High and Low, or something else
- The UI should probably make it clear when the maximum output power has been reduced

See #94

CrashOverride85, 2024-06-15:
Will be in v1.9

Closed 2024-06-15.

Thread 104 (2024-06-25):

Update build notes

CrashOverride85, 2024-06-25:
### Discussed in https://github.com/CrashOverride85/zc95/discussions/102

<div type='discussions-op-text'>

<sup>Originally posted by **electro991** June 23, 2024</sup>
Here are some notes from my recent build that may be useful to others:

When ordering the output board from JLCPCB,
the LEDs (D3, D4, D5, D6, D7) part #C72043 were out of stock, i replaced with C2986059
Also, C16 part# C250973 no longer exist on the LCSC site, I replaced with C43348

On the main board BOM spreadsheet, J16 components could be removed as they are not needed anymore with the current rev of the board.

The placement of the header and orientation for the 2X4P IDC (J19) on the main board is not specified on the silkscreen. I had to make sure I soldered it in the right orientation, cable notch facing the rear of the board. (assuming you create your IDC cable pin to pin)
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

Finally, for the front panel controls board, I have created a 3d printed riser for the 6 LEDs (U3,U4,U5,U6,U7,U8). The LEDs slip (with a little pressure) into it and are automatically the proper height when fitting the front panel. see attached.
[led-riser.zip](https://github.com/user-attachments/files/15944518/led-riser.zip)

Hope this helps</div>

Closed 2024-06-25.

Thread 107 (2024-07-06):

HW check failure detecting front panel version

CrashOverride85, 2024-07-06:
### Discussed in https://github.com/CrashOverride85/zc95/discussions/106

<div type='discussions-op-text'>

<sup>Originally posted by **electro991** July  1, 2024</sup>
I get occasional « Hardware check failed » « Unable to determine front panel version » on boot. A simple off / on resolves it

It seems to occur only on first boot after being off.

Would you have an idea what could be causing this ?</div>

----

ZC95 is sometimes failing to detect which version of the front panel (v0.1 or v0.2) is connected.

The current logic looks for the presence of the v0.1 ADC on 0x38, and the v0.2 ADC on 0x48. If both (or neither) are found it errors out.

This sometimes goes wrong because on initial power up the TLC59108 LED driver also appears on an "ALLCALL" address of 0x48, and its reset line is floating (connected to the unconfigured TCA9534 port expander). So usually it doesn't show up on 0x48, but sometimes it does and the hw check fails.

Summary of i2c addresses in use:
### v0.1
0x26 I/O expander
0x48 ADC

### v0.2
0x38 I/O expander - doesn't show up on i2c scan unless written to first
0x41 LED driver (if reset high)
0x48 LED driver (if reset high and not configured - in addition to 0x41)
0x49 ADC

Firmware fix is probably to identify v0.1 by looking for the presence of 0x26, and v0.2 by looking for 0x49.
But ideally a pull up or pull down is needed at some point on the reset line to put the LED driver into a known state right from power up.

Closed 2024-07-06.

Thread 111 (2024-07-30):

433 mhz collar beeping only every other time unless quickly repeated

electro991, 2024-07-30:
It seems that the 433mhz collar i have requires the zc95 to send the beep signal twice every time it is required

if only sent once, for some reason the collar will skip every other beep request from the zc95

this behaviour is not the case for shock or vibrate mode

it is especially problematic if using shock choice as a beep is only heard every other time a choice needs to be made

electro991, 2024-07-30:
Correction; it seems to be inconsistent for vibrate as well. I believe the original remote sends its signal 2x as the vibration is longer on original (2x the length)

i believe it may just be that shock choice is just too brief for the collar to work every time. In other modes for example Round Robin, it never skips a beat at 1000ms

CrashOverride85, 2024-08-01:
I've tweaked the times so it should now be sending sending 2 sets of messages to a collar instead of 1 set as before.
This isn't a problem I've experienced, so I can't really test it beyond that it still works for me,
I've attached an updated F/W for the zc95 that has this fix, and the one for needing a reboot after changing settings, could you let me know if it works any better?
[zc95.uf2.zip](https://github.com/user-attachments/files/16460957/zc95.uf2.zip)

electro991, 2024-08-02:
Awesome. Thank you. I will test after the weekend and get back to you.

electro991, 2024-08-07:
Good evening,
I have tested this change and it is better but still missing some warnings on chan4 at times. I have loaded the increase_shockchoice_pulse_length branch and increased simple_channel_pulse(3, 600) to simple_channel_pulse(3, 1200) and recompiled. With that, it appears to be consistently working for me. I came up with 1200 by testing at what point it became consistent using the roundrobin pattern and increasing the delay until it worked every time.

CrashOverride85, 2024-08-08:
I'm assuming it's down to slightly different versions of the collars. I'll update it to 1200 shorty, thanks for experimenting that letting me know what works

electro991, 2024-08-08:
Thank you. Much appreciated. I have tested with 3 different of that model too. Pretty confident about the value

CrashOverride85, 2024-08-17:
Updated to 1200. With the collar/transmitter I've got, that consistently results in 2x pairs of beeps rather than one as before, but that's probably better than being intermittent with some combinations

Closed 2024-08-17.

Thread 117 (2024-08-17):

LCD startup

electro991, 2024-08-17:
Nothing serious but i have the following odd thing happening with the LCD

on assembled unit 1, screen on power up goes all white for a seconds, then black, then 2-3 seconds later, the populated main screen appears. This is rather clean except the white for one second

on assembled unit 2, screen on power goes white for a second, then mainly white with somewhat garbage pixels of purpleish colors for about another second, then main menu unpopulated appears, then about 2 seconds later main menu populates. This behaviour I think is not so clean

After troubleshooting, the problem follows the screen (keeping everything else consistent, including cable)

i tried a 3rd screen i had lying around and it behaves like assembled unit 2

i am not sure if within code the init of the screen can be optimized in any way. I have seen some discuss this behaviour on doing a google search. Turning off the backlight thru code during init seems to do it for them. I have not inspected the code for this project yet to determine if this has been tried.

CrashOverride85, 2024-08-17:
Mine behaves as per your unit 1, and that white flash is essentially design flaw in the zc95 main board unfortunately. The backlight pin on the display is connected to a PCF8574 I/O expander, which on power up defaults all the I/O pins to high. The brief flash is the time it takes to do some initial init then set that output pin to low. It then switches it back on when init is complete.

There's probably some scope to init the I/O expander and switch off the backlight slightly sooner, but I think there'd still be a white flash, and it wouldn't do anything for the other displays.

It sounds like the backlight pin isn't working on the other two displays, although it also seems quite unlikely that two displays would have a fault. I'm struggling to spot what could be causing it though.

Having tested mine, it behaves as per your unit 2 if I comment out line 192 in zc95.cpp

electro991, 2024-08-17:
Thank you for the insights. I will check that pin’s solder and continuity to the pcf and get back in a few days.

electro991, 2024-09-04:
Fixed! thank you.  It was a loose contact on the cable. It was on and off. For some reason it worked on one screen lol. Just had the right angle for the contact to work.

Closed 2024-09-04.

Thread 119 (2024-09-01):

Help: JLCPCB ordering issues with incompatible parts

moarkaboom, 2024-09-01:
After placing my order with JLCPCB they sent me the following response.
Even though I am not entirely sure what option A is, it seems the preferable one. I am unsure if they will recommend suitable parts or if I have to redefine them myself.
It's the first time for me ordering a populated PCB and my electronics skills are *very* basic. It would be a tremendous help, if somebody could support me in this process.

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

CrashOverride85, 2024-09-01:
arggg thanks for reporting this...
It looks like I've got the wrong part (0805 vs 0603) in the BoM/CPL files for those parts. I've been back and checked, and it was the same wrong parts when I ordered it from JLCPCB, I have no idea how they managed to assemble mine!

I've about to push a fix to the BoM & CPL files, so you can either do option C and use that, or option A and make these substitutions:
C4310   => C22843 (1.5k)
C17798  => C23228 (680)
C49678  => C14663 (100nF)
C149504 => C25803 (100k)
C17414  => C25804 (10k)
C17470  => C22807 (150k)
C28323  => C15849 (1uF)

Sorry about that!

electro991, 2024-09-01:
I had the same when i ordered but they advised they could still solder so that’s the option i took. Thanks for the fix

moarkaboom, 2024-09-02:
Thanks for taking care of this so quickly!
I noticed you didnt replace C15850, does that mean this part remains?

CrashOverride85, 2024-09-02:
Ahh yeah good spot, I missed that one
Now fixed
C15850 => C96446

Closed 2024-09-10.

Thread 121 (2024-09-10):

Sourcing help: 0.5 Ohm resistor

moarkaboom, 2024-09-10:
I am having real trouble finding the correct part for C479296 which is a 0.5 Ohm Resistor used on the output board (R1, R26).
Can somebody either point so a supplier (preferably EU) or to a better available part?

Edit: I just discovered, these two Rs are already on the board, but on the BOM, they are under hand assembly? Am I missing somthing here?

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

CrashOverride85, 2024-09-10:
Hadn't noticed that was out of stock, I'll update it.

From LCSC, [C479327](https://www.lcsc.com/product-detail/Through-Hole-Resistors_VO-MF1W-0-5-2-6T63_C479327.html) would be a suitable replacement, or [MCKNP01SJ050KA10](https://uk.farnell.com/multicomp/mcknp01sj050ka10/res-0r5-5-1w-axial-wirewound/dp/1903704) from farnell.

The resistor is listed in the BoM file, and it seems C479296 is still in stock with jlcpcb, so if it wasn't un-ticked when ordering, jlcpcb would have assembled it. The main reason some parts are marked as hand assembly is because it is (or was, not checked recently) quite a bit cheaper.

moarkaboom, 2024-09-10:
Thanks  for the response. Bur I don't need to source it now, right?

CrashOverride85, 2024-09-10:
Nope :)

Closed 2024-09-10.

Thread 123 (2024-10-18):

Suggestions for improvements/changes

heavyrubberslave, 2024-10-18:
Hello,

I successfully built the ZC95. Thank you so much for all the hard work you put into this and for sharing it with the public.

I have a list of things I see some improvements could be made. You may or may not had reasons for solving it the way you did. Let me post the list here and I can do separate issues in case you think it's worth looking into some of those:

### FrontPanel Controls
* J5 comes with just a pin header instead of a socket if assembly by JLCPCB is chosen. (Could be removed from BOM.)
* Make it possible to use a 2x2pin (Dupont or alike) plugs for the 4 LED buttons so the button's wires don't need to be soldered onto the board.
* Replace the Adafruit display with a cheaper alternative (with same driver).
* Use a rotary encoder which has the same/similar length as the potentiometers.

### Mainboard
* Use 3.5mm audio jacks for channels as well (for compatibility with MK312/E-Stim System's 2B)
* Use a 10pin JST XH pin header/socker for display (same on the display end), that way one could use standard 10pin JST XH cables
* Use a (15V PB) USB-C socket for charging

### Audio board
* Add option to use the assembly service for U1 (and potentially other components)

CrashOverride85, 2024-10-18:
Hi, glad to hear you've built it, hope you have fun with it :)

Thanks for your feedback, these are my comments on the issues:

### FrontPanel Controls
> J5 comes with just a pin header instead of a socket if assembly by JLCPCB is chosen. (Could be removed from BOM.)

Ahh yeah, that was unintentional - I think I must have unticked that part when ordering, and forget to take it out of the BoM file. Probably also means the LCSC part number is wrong for part in the schematic if it got populated with a pin header not a socket.
I'd always intended for that to be hand soldered.

> Make it possible to use a 2x2pin (Dupont or alike) plugs for the 4 LED buttons so the button's wires don't need to be soldered onto the board.

Didn't think of that, good idea, just changing the pin spacing to a 2x2 2.54mm grid should do it, then it could either be directly soldered or a connector used

> Replace the Adafruit display with a cheaper alternative (with same driver).

I chose that specific display because at the time it seemed to be widely available. A lot of the cheaper displays often either don't have an easy to search for model name, were only available from one retailer, and/or looked like the sort of part that would disappear quickly. I also wanted a complete module I could mount to the front panel (i.e. not just a bare display) for simplicity's sake.
The ADA358 module also had great documentation that actually gives dimensions / positions for mounting holes, it's surprising how few other display modules have this available!

Also whilst the display driver does support a wide variety of displays, it's a compile-time configuration thing, and I really don't want to get into maintaining two separate firmware binaries unless I have to (e.g. if the current display gets discontinued), so I'm not planning to change the display.

> Use a rotary encoder which has the same/similar length as the potentiometers.

Interesting, hadn't spotted there was much of a difference, I'll see what I can find

### Mainboard
> Use 3.5mm audio jacks for channels as well (for compatibility with MK312/E-Stim System's 2B)

This was a very deliberate choice as most of my cables are 2.5mm, and I've got 2.5mm<>3.5mm adaptors for things that aren't. I think @shiny-mira has a fork with a modified version of the main PCB and front panel which does have 3.5mm connectors though

> Use a 10pin JST XH pin header/socker for display (same on the display end), that way one could use standard 10pin JST XH cables

This really comes down to the choice of display :/ JST XH connectors have a 2.5mm pin pitch, but the header on the ADA358 display is 2.54mm, so it wouldn't be possible use a ready made JST cable. I guess cutting the end off one and soldering to the display would be an option, as it only really needs to be removable at one end. That would at least remove the need for a crimp tool to create the cable.

> Use a (15V PB) USB-C socket for charging

I think all USB-C PD IC's are SMT, and I was trying to keep the main board through hole only. I'm not keen on using a separate USB-C PD module as selecting one that's likely to still be easy to find in a year or two is probably tricky, and mounting it could be awkward.
Very long term (> 1 year definitely), I do plan to combine the main / output / audio boards into one SMD board, swap over to a lithium battery, and move to USB-C charging. But I agree a 15v barrel jack is far from ideal.
All I can suggest for the moment is a 15v USB-C to barrel jack cable - that's what I've been using and works well enough.

### Audio board
> Add option to use the assembly service for U1 (and potentially other components)

Redesigning this board to be SMT and using the JLC assembly service is high up my todo list - and definitely for more than just U1. I'll probably leave just the pin sockets and _maybe_ the relay requiring hand soldering.

> I think the pin headers J1 and J2 are not included in the BOM

It's line 9, part C35445 on the audio board tab of the BoM spreadsheet

> I think the IC socket for U2 (2x7pin) is not included in the BOM

ahhh good spot, looks like the socket for U3 is also missing, but you likely had a spare from the main board

electro991, 2024-10-21:
Regarding the 2.5mm plugs, i used this adapter. I like it as it prevents wear and tear on the sockets on the units itself

2.5mm Male to 3.5mm Female Aux Stereo Cable Connector Adapter
https://a.aliexpress.com/_ms5xhnO

electro991, 2024-10-21:
I had no issues here with this adapter

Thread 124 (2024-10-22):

FrontPanel Controls update BoM and allow use of connector for buttons

CrashOverride85, 2024-10-22:
1. If the JLCPCB assembly service is used (recommend), J5 is populated with a pin header instead of a socket. This was intended to be hand assembled, so should not be populated at all. Remove it from the BOM/CPL files

2. Update the footprint used to solder the button wires to so it is a 2x2 2.54mm grid, allowing a connector to be fitted if desired

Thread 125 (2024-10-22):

Audio board rework

CrashOverride85, 2024-10-22:
Whilst it does mostly work, there are numerous issues with the current audio board:
* Silkscreen for D3 is backwards
* 2n7000 is poor choice of MOSFET (see #114)
* R27 pull down should either be a pull up, or just omitted
* BoM spreadsheet is missing IC sockets for U2 and U3
* Having that one SMD part in there isn't great

Solution: redesign the board to be fully SMD, using the JLCPCB assembly service. Swap to AO3400 MOSFET.

heavyrubberslave, 2024-11-02:
I have a question regarding the R27. According to this issue it should be "omitted". Does this mean I need to jump/connect the two pads of the R27 with some plain wire, or does it mean I don't need to solder anything and leave the pads for R27 completely blank?

CrashOverride85, 2024-11-02:
Yeah, just don't solder anything and leave the pad for R27 empty.
Without R27, I think the odds are good that a 2n7000 will be ok; it's working for me with an 2n7000 and R27 present, and removing R27 will only make it (much) more likely to work.
I'll _hopefully_ be posting an update about the redesigned SMD board in about a week.

Closed 2024-11-06.

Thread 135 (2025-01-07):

Pairing shock collars

heavyrubberslave, 2025-01-07:
I ordered some shock collars that looked like the ones you show here but I cannot figure out how to pair them. I pressed the power button for 3s, it beeps, the light is blinking but what now? I tried to click TEST in the collar config menu several times but nothing happens. I haven’t paired them with the remote before, they‘re fresh out of the packaging.

Can anyone maybe point out the obvious I‘m missing?

CrashOverride85, 2025-01-07:
That does sound like you're trying to pair them the correct way. BTW they can be re-paired anytime by pressing and holding power button for a couple of seconds as you describe, i.e. swapping them between remote(s) & zc95 isn't an issue.

The only things I can think of is
1) double checking the 433 tx module is seated correctly and the right way around
2) seeing if you can check what frequency the collar operate at, e.g. using an SDR.
Alternatively, remove the back of the remote, and see if it looks more like the 433 or 915 version:
https://github.com/CrashOverride85/collar/blob/master/extra/Type1.MD

heavyrubberslave, 2025-01-08:
Okay, good to know, thanks. Maybe the menu point "TEST" could then be renamed to "PAIR/TEST"? Just so it's obvious.

1. It is placed correctly. But I ordered 5 modules from AliExpress and one module even prevented the ZC95 from starting up and there was a high-pitched buzzing sound coming from the capacitors/diodes at the top of the mainboard. When I removed it, the device started up normally. Maybe the store I got the modules from was bad. Where did you get yours from?
2. I opened it and it looks 1:1 like the 433 version in your picture, except the PCB being blue instead of green. But the layout looks exactly the same.

CrashOverride85, 2025-01-09:
Yes, I agree renaming is probably a good idea. TBH I need to revisit shock collars soon, and might see if I can make the pairing process more obvious.

I can't remember where mine came from, but it would have either been aliexpress or ebay. TBH I've bought a few over the last few years from various sellers. But see #103 . it sounds like some of these modules are a bit iffy

heavyrubberslave, 2025-02-09:
I ordered new transmitter modules and with those the shock collars work. But the TEST function works randomly. Sometimes they vibrate every single time when I click "TEST", sometimes they just don't react at all for a few times pressing "TEST".

CrashOverride85, 2025-02-09:
I wonder if this is related to #111, I think I might need to increase the duration of the signal sent when test is pressed

heavyrubberslave, 2025-02-09:
Could be. Maybe it would be worth exploring the idea of making the signal length configurable per collar, so everyone can find the length that works best for their collar(s)?

CrashOverride85, 2025-02-10:
Yeah, good idea, having that configurable probably makes a lot of sense, will add it to the list

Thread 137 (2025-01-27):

Hardware check failed - Output 9v missing

simonsolutions, 2025-01-27:
I have assembled a complete box with all boards (Main, Output, Audio v0.4, 433Mhz Board) and the box worked.

Now after one week not using it and reconnecting the battery the box shows FAULT on all channels and the Output Board is NOT lighting the LED 9V and OK - all other 3 are light.

- I assembled a new Output board and tried this.
- I reflashed board Raspi Picos with the current and correct image.
- I tried another battery.
Nothings changes and the FAULT message persists.

Any idea what i can check further?

Thanks in advance.

CrashOverride85, 2025-01-27:
What's the exact error it's showing?
Also is the OK  LED off completely, or flashing? Does the 9v LED briefly come on when the box is first powered on, then go off? or is it never on?

Just to confirm, the output board isn't connected to USB power?

To get more info on what's going wrong, can you try connecting a ttl serial cable to the output boards serial header? (115200 baud)
On power up, it should be giving some info on what's going wrong.

simonsolutions, 2025-01-27:
The exact error I attached as photo.

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

The OK is completely off and the 9v LED never is on when turning on.
Non of the Raspis or anything else is connected to USB power or something else. Just the battery.
This is on both output boards the same.

I tried a serial TTL, and didn't get any response. I just ordered another USB TTL converter to try.

CrashOverride85, 2025-01-27:
That's certainly a fault I've not encountered before. The 9v LED should always switch on moments after start up, then after a couple of seconds or so the OK LED should either stay on along with the 9v LED, or flash and the 9v LED switch off.
As neither is happening, it suggests something is very wrong with the output board.

The fault screen you're seeing does mean the output board has definitely been detected and successfully queried during startup though, which is odd given the lack of activity on the LEDs suggest it's not doing anything.

Could you try swapping the pico's over and reflashing? to rule out a problem with the pico on the output board.
Other than that, it's worth checking the actual voltages of the 5v & 12v supplies reaching the output board if you haven't already. A very low 12v would cause all channels to report a fault & possibly no 9V LED (but wouldn't explain no OK LED...)

simonsolutions, 2025-01-27:
Tthe exact same problem occurs with 2 completely separate output boards. so a mistake on one output board i would say could not be the reason.
The LED behaviour with all voltage LED on and then seconds later the OK i had at the beginning. i dont know what happend during on week not using it and then reconnecting the battery. The first output worked already some time.

I reflashed the picos already with no change in behaviour. I ordered new ones (will arrive at the end of the week) to try new Picos.

The voltages at the the measure points:
Battery directly: 12,66V (box turned off)
Output: TP1: 190 mV raising over time slowly to 266 mV
Mainboard:
TP1: 12,44 V
TP2: 0 V
TP3: 5,06 V
TP4: 3,346 V

CrashOverride85, 2025-01-27:
Yeah, two boards having the same issue does seem quite unlikely, but I'm struggling to see what else could cause it. Even if the self test fails, the OK LED should be flashing - that not happenings points to something being very wrong.

The output board should only need +5v and ground to get a flashing OK led, and +12v as well to pass the self test. It should do that even if the main board isn't working (beyond providing power), e.g. including if the main board pico was absent.

Those voltages look absolutely fine - to rule out poor connections, could you also check them on output board connector on top of the PCB? +v5 and +12v are labelled on the silkscreen

simonsolutions, 2025-01-28:
I checked the +5v and +12v on the top of the output board and they have the same current as on the mainboard, so there are no breaks in this connection.

The interesting part that it worked and when replugging the battery after one week it showed this behaviour. The new picos are already shipped and should arrive by the end of the week. So maybe there is the problem in the pico itself.

If it helps you I can send you a video of the behaviour via email.

CrashOverride85, 2025-01-28:
It does seem really odd that it initially worked, don't think I can explain that. I suspect getting serial output from it will help explain what's going on. Although hopefully a new pico fixes it 🤞

simonsolutions, 2025-01-28:
I tried serial output today, but didnt get any. Just to be sure on the output board i have to connect ground to ground of the 3,3 Serial TTL Converter und Tx of the board to Tx of the Converter? 115200 baud in the arduino ide serial monitor will work? or do i need something different?

As soon as the new Picos arrive i will test it an keep you posted. If it works then, we can see how we analyse the error in order to better address it in the future.

CrashOverride85, 2025-01-28:
ahhh, no, connect the TX on the output board to the RX line on the serial board (along with ground).
I've not used it with the Arduino serial monitor, but yes, that should work when set to 115200

simonsolutions, 2025-01-28:
Ok i'll try it Tx (board) <> Rx (converter).
With which program did you log the serial output?

simonsolutions, 2025-01-29:
Ok I tried it but there is no output on the serial port with Gnd-Gnd and Tx-board<>Rx-converter.

I tried to remove the Pico on the Output Board. That changes the message in the display that the ZC624 is missing - what would be a correct behaviour. But the LEDs dont change at all. 9V and OK never light up and the other 3 light up.

CrashOverride85, 2025-01-29:
That is really confusing :/
As it's clearly being detected, it should be outputting to serial on startup.
Could you double check with something else that the serial board is working as expected?
If it's not outputting to serial, there must be something wrong with the output board, even if it's affecting both of them.
If the output board's pico is getting power, it outputs the firmware version to serial before any communication with the main board can happen.

simonsolutions, 2025-01-30:
Okay today the new Picos arrived, just taking a new Pico (non-W) soldering the pins, flashing the output firmware and now it works again. I dont know what the old pico had, but that seems now as it was the source of the problem.

CrashOverride85, 2025-01-30:
Nice 🎉
At least it's working :)

simonsolutions, 2025-01-30:
Absolutely. If you need any analysis for further development, let me know

Closed 2025-01-30.

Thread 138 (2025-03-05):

Mainboard BoM - two parts not found

CrashOverride85, 2025-03-05:
Parts that don't seem to exist anymore at LCSC:
* C125988 - C9, C19
* C433514 - R14

CrashOverride85, 2025-03-05:
R14 shouldn't even be on the BoM. It's the resistor for a power LED that shouldn't be installed (and correctly is absent from the BoM)
C713347 looks like a suitable alternative for C9 & C19

Closed 2025-03-05.

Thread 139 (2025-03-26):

Board outline error

CrashOverride85, 2025-03-26:
Error showing 3D preview and exporting STEP file for the mainboard and front panel PCBs.
I'm pretty sure this must have worked at some point, but possibly related to originally designing in a 4 year old version of Kicad(?)

Closed 2025-03-26.

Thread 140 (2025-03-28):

Crash on BLE peripherals screen

CrashOverride85, 2025-03-28:
Open BLE peripherals, select "Scan/Pair", spin the rotary encoder. Box crashes,

Closed 2025-03-28.

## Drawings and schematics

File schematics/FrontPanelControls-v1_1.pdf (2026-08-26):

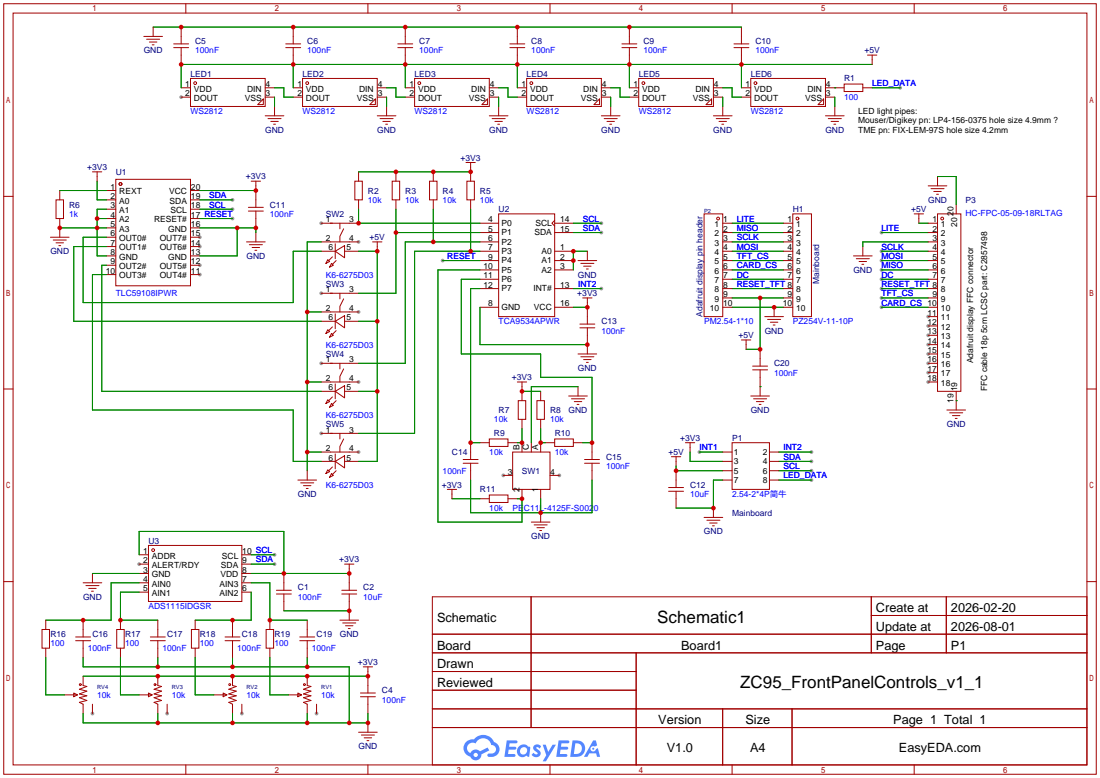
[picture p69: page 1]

LED_DATA
LED light pipes:
Mouser/Digikey pn: LP4-156-0375 hole size 4.9mm ?
TME pn: FIX-LEM-97S hole size 4.2mm

Adafruit display pin header

FFC cable 18p 5cm LCSC part: C2857498

Adafruit display FFC connector

Schematic | Schematic1 | Create at | 2026-02-20

Update at | 2026-08-01

Board | Board1 | Page | P1
Drawn | | ZC95_FrontPanelControls_v1_1
Reviewed

Version | Size | Page 1 Total 1
V1.0 | A4 | EasyEDA.com

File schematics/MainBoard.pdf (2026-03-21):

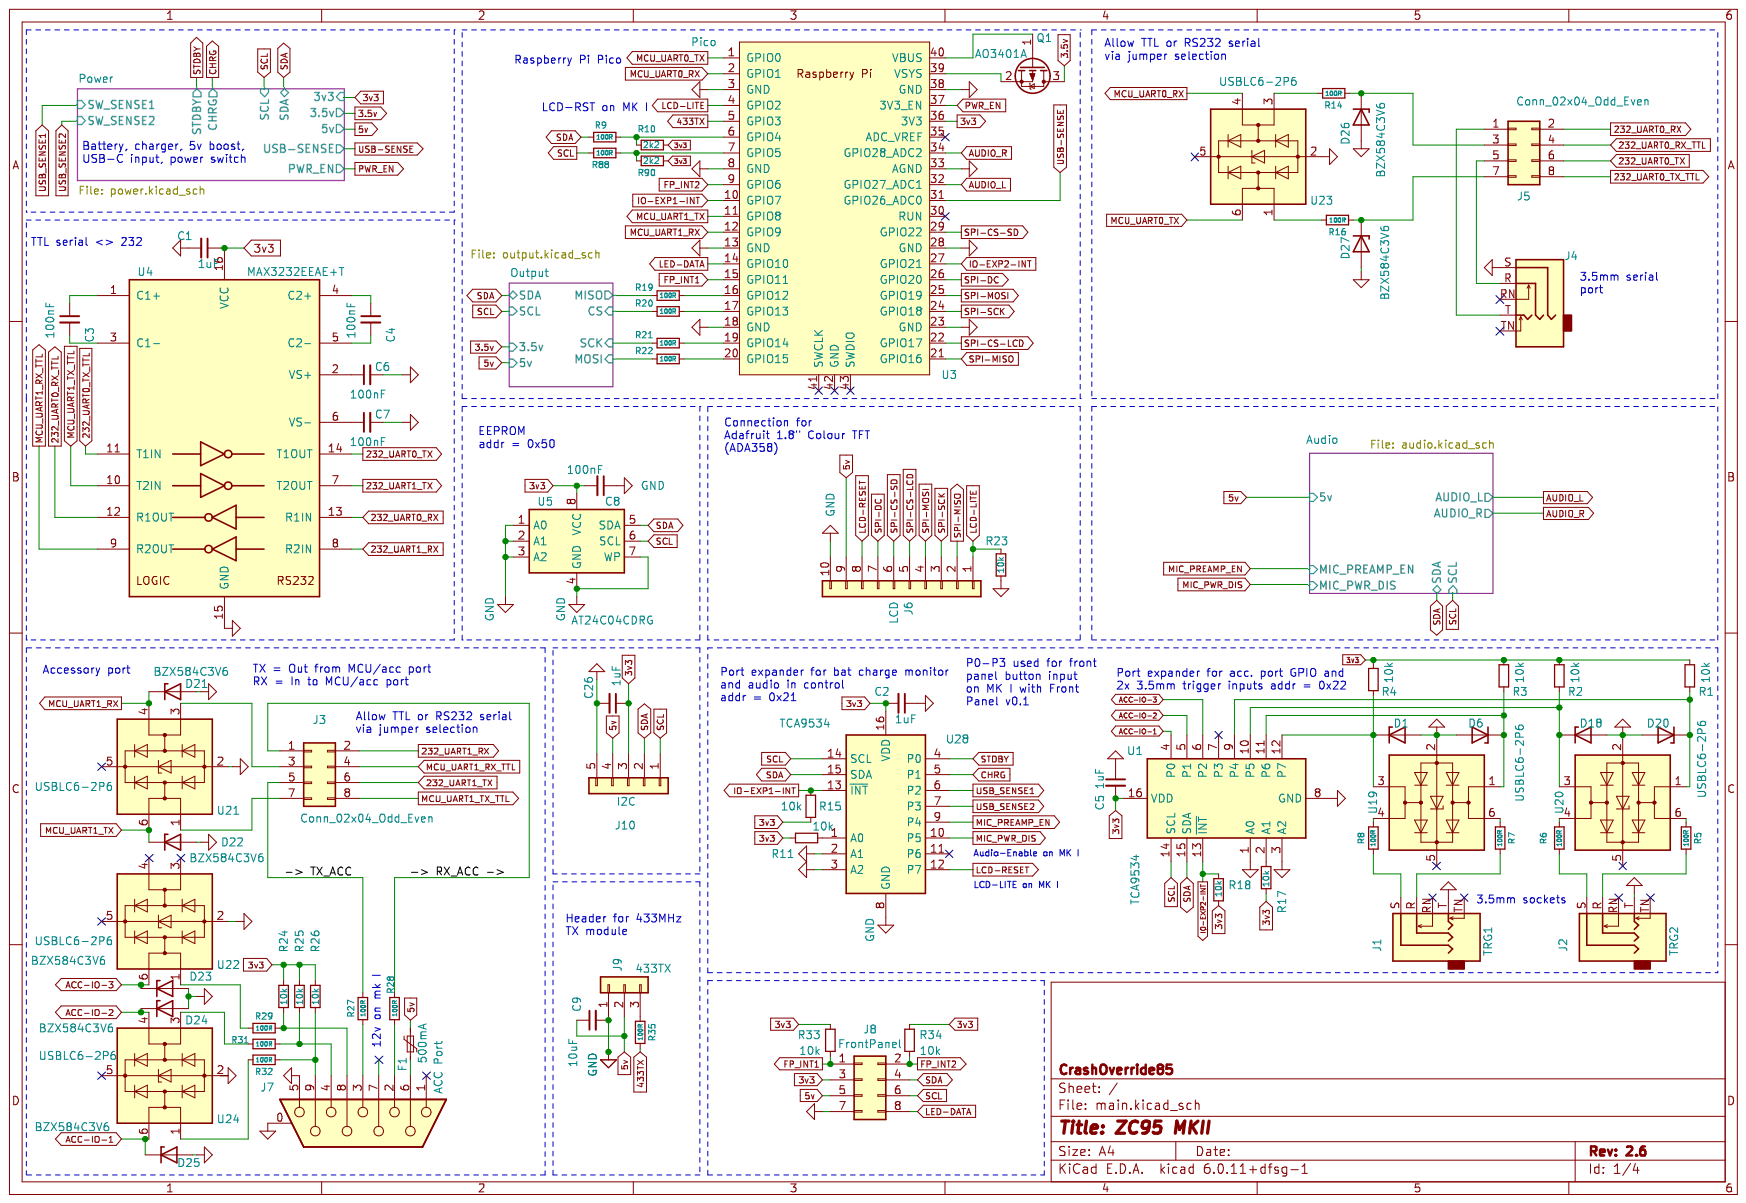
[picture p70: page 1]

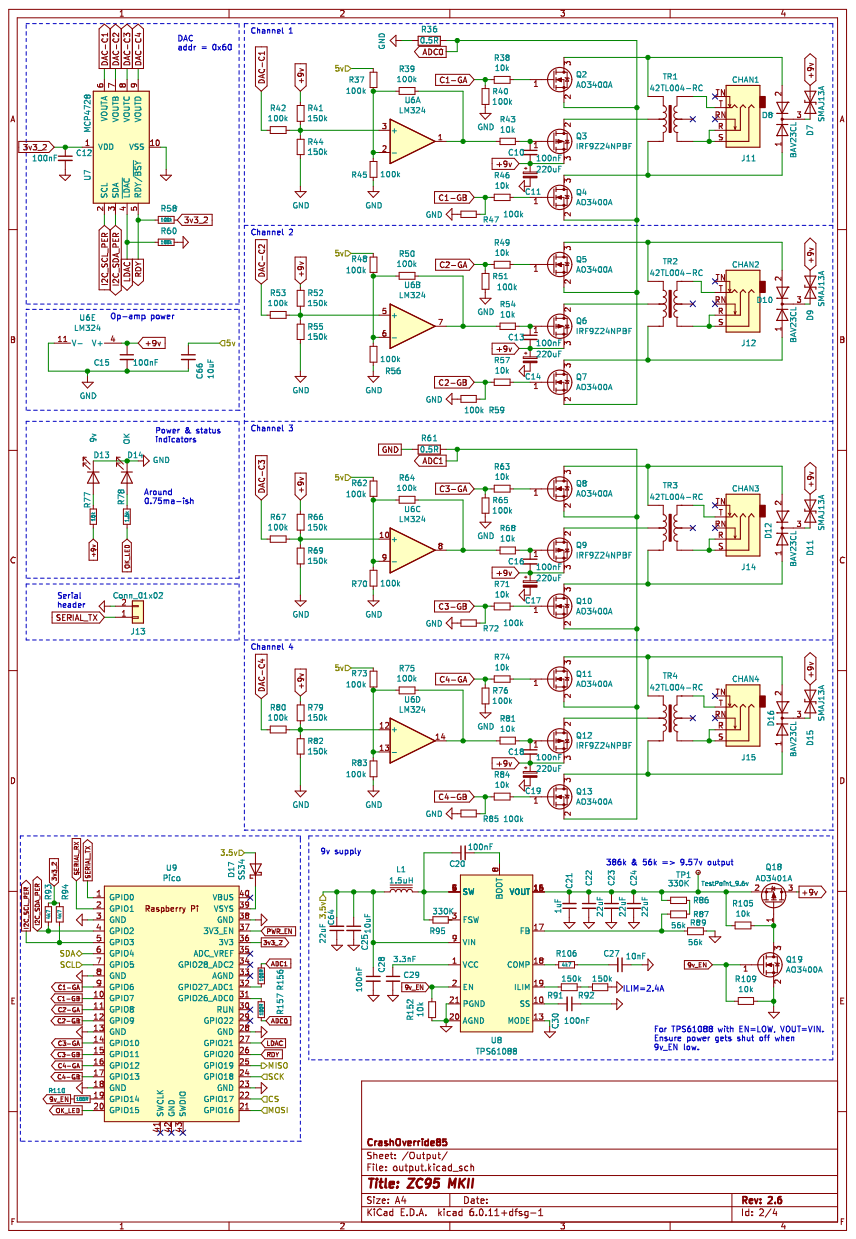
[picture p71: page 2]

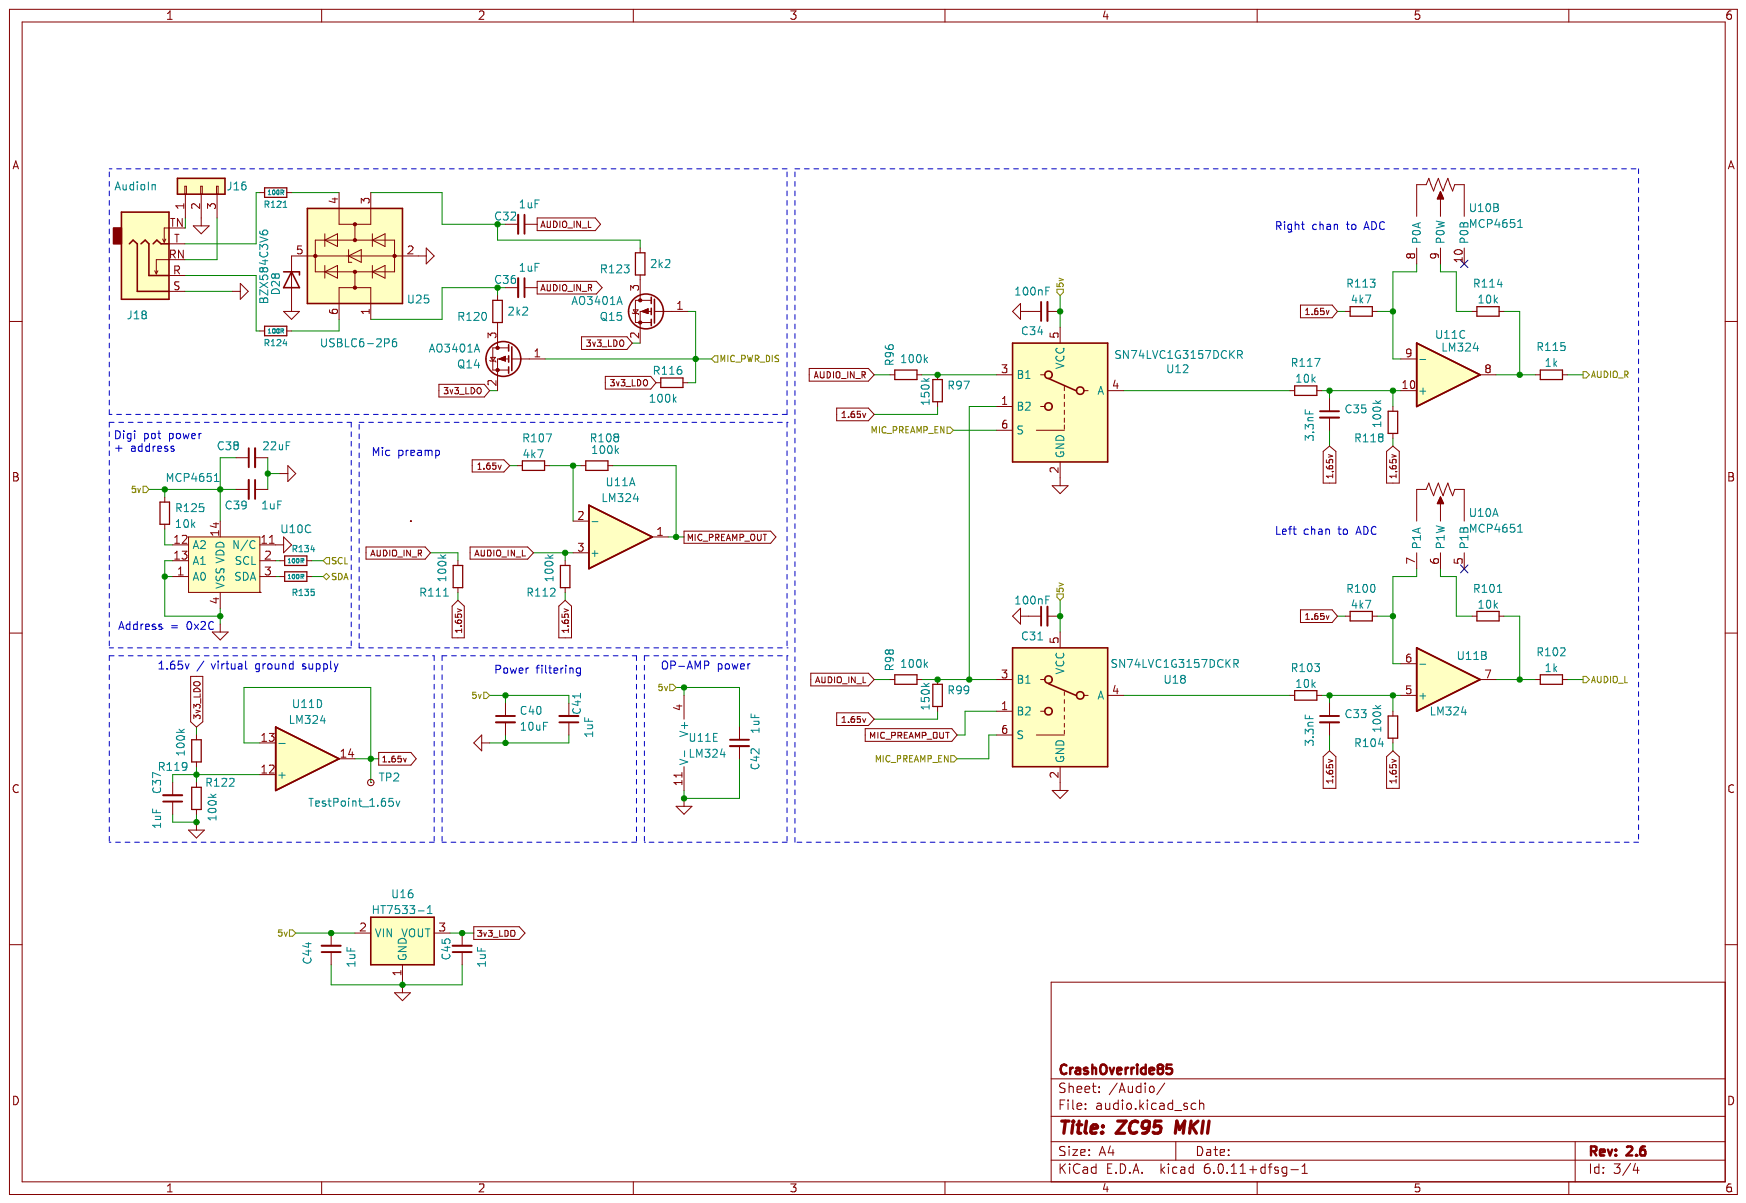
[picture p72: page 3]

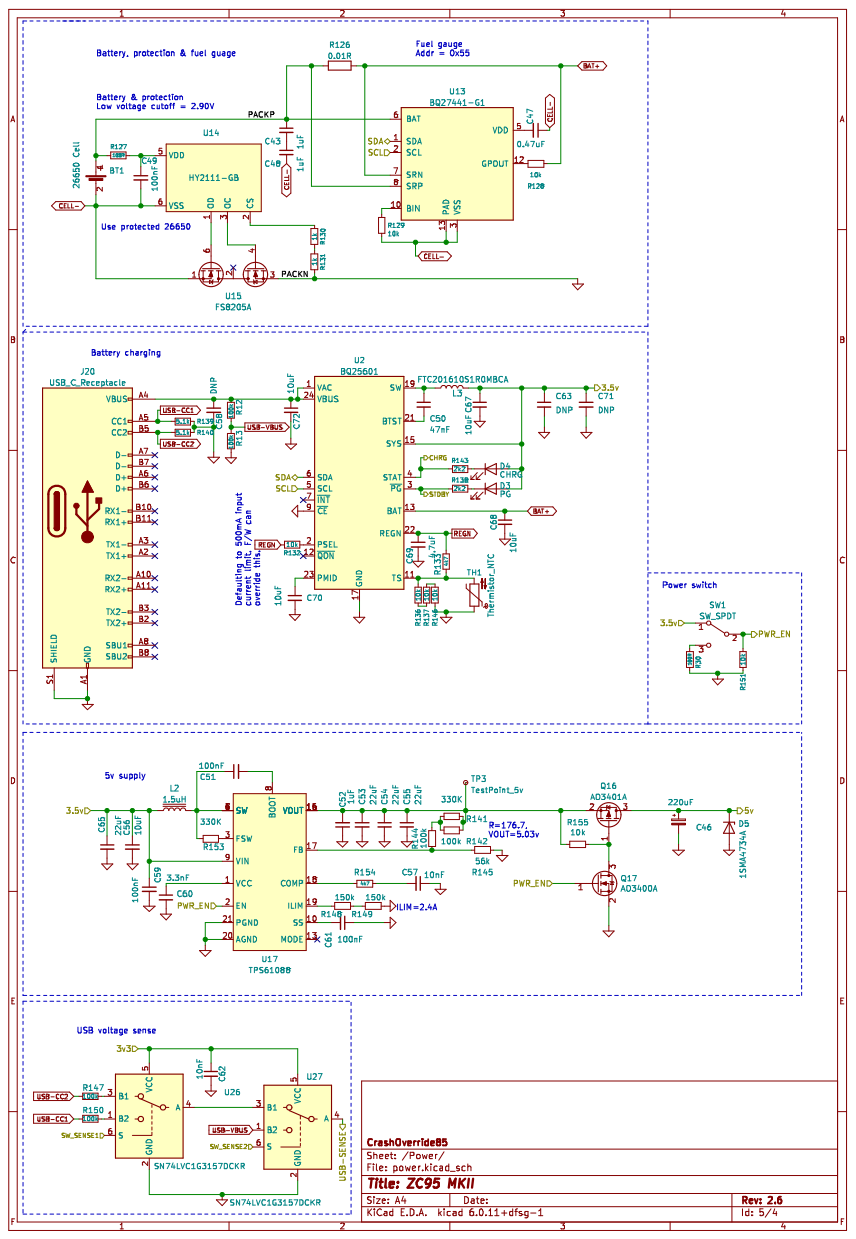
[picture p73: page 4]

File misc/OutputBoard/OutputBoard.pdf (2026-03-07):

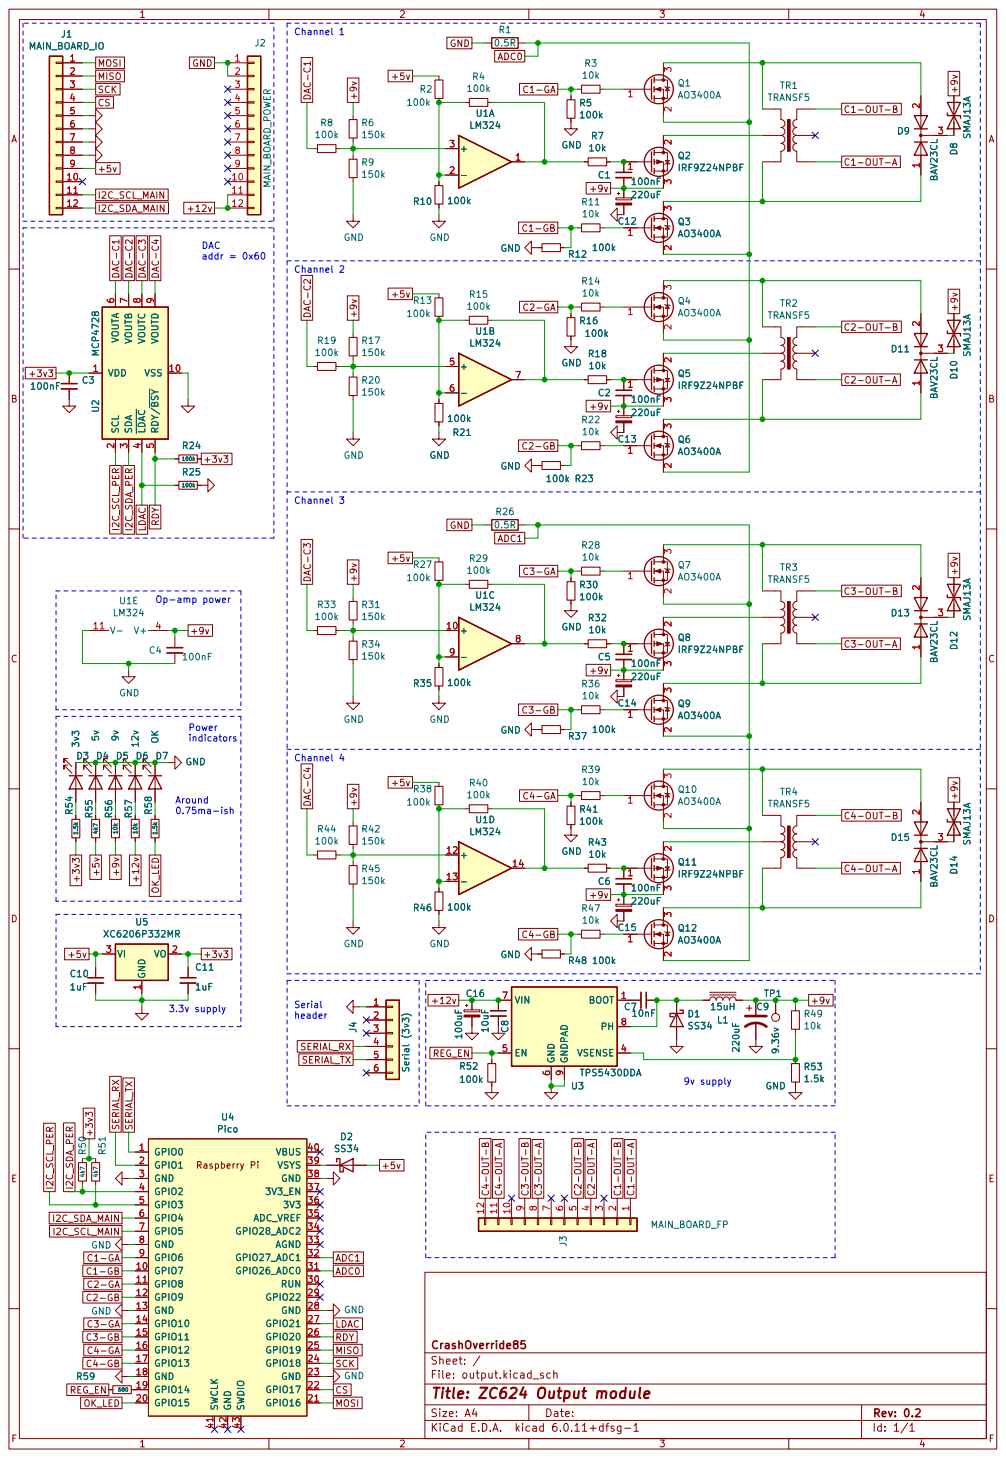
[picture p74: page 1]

3 ~{LDAC} 4 RDY/~{BSY} 5 VOUTA

Id: 1/1 Title: ZC624 Output module

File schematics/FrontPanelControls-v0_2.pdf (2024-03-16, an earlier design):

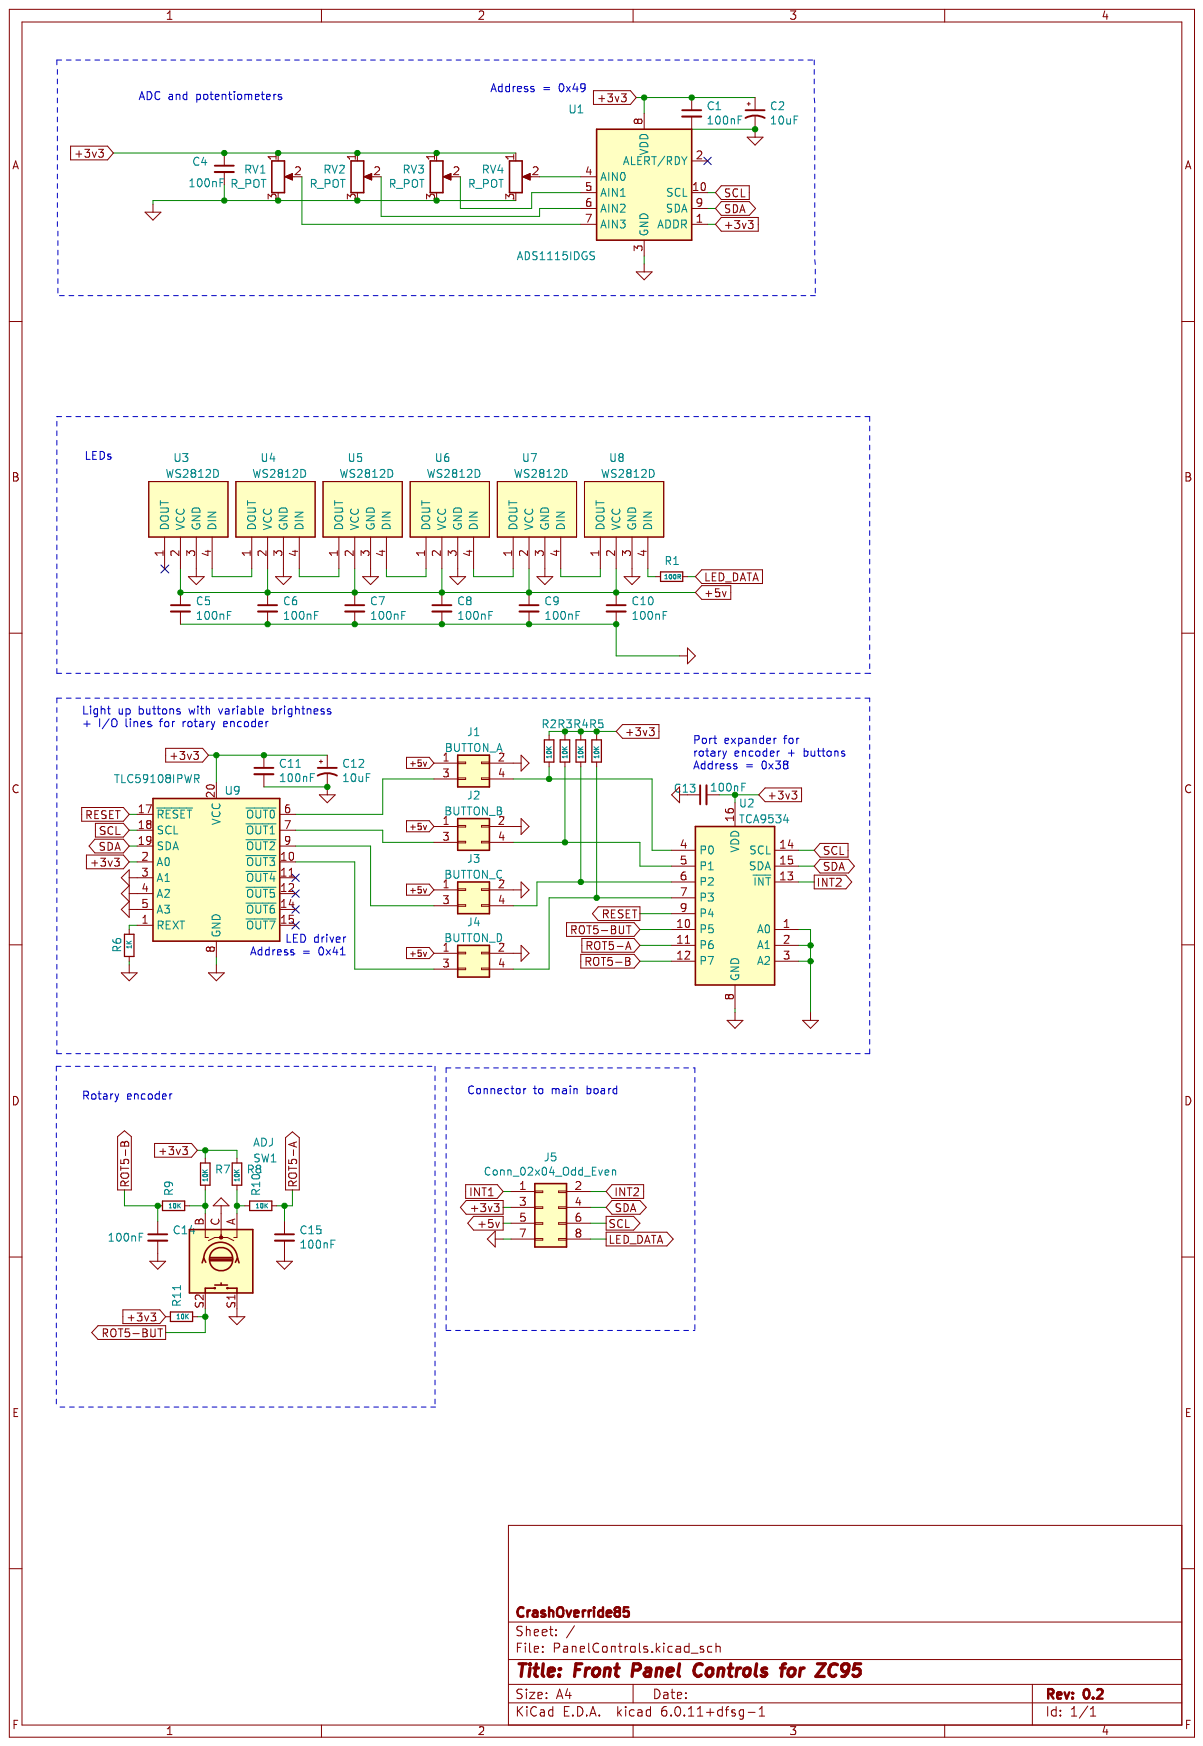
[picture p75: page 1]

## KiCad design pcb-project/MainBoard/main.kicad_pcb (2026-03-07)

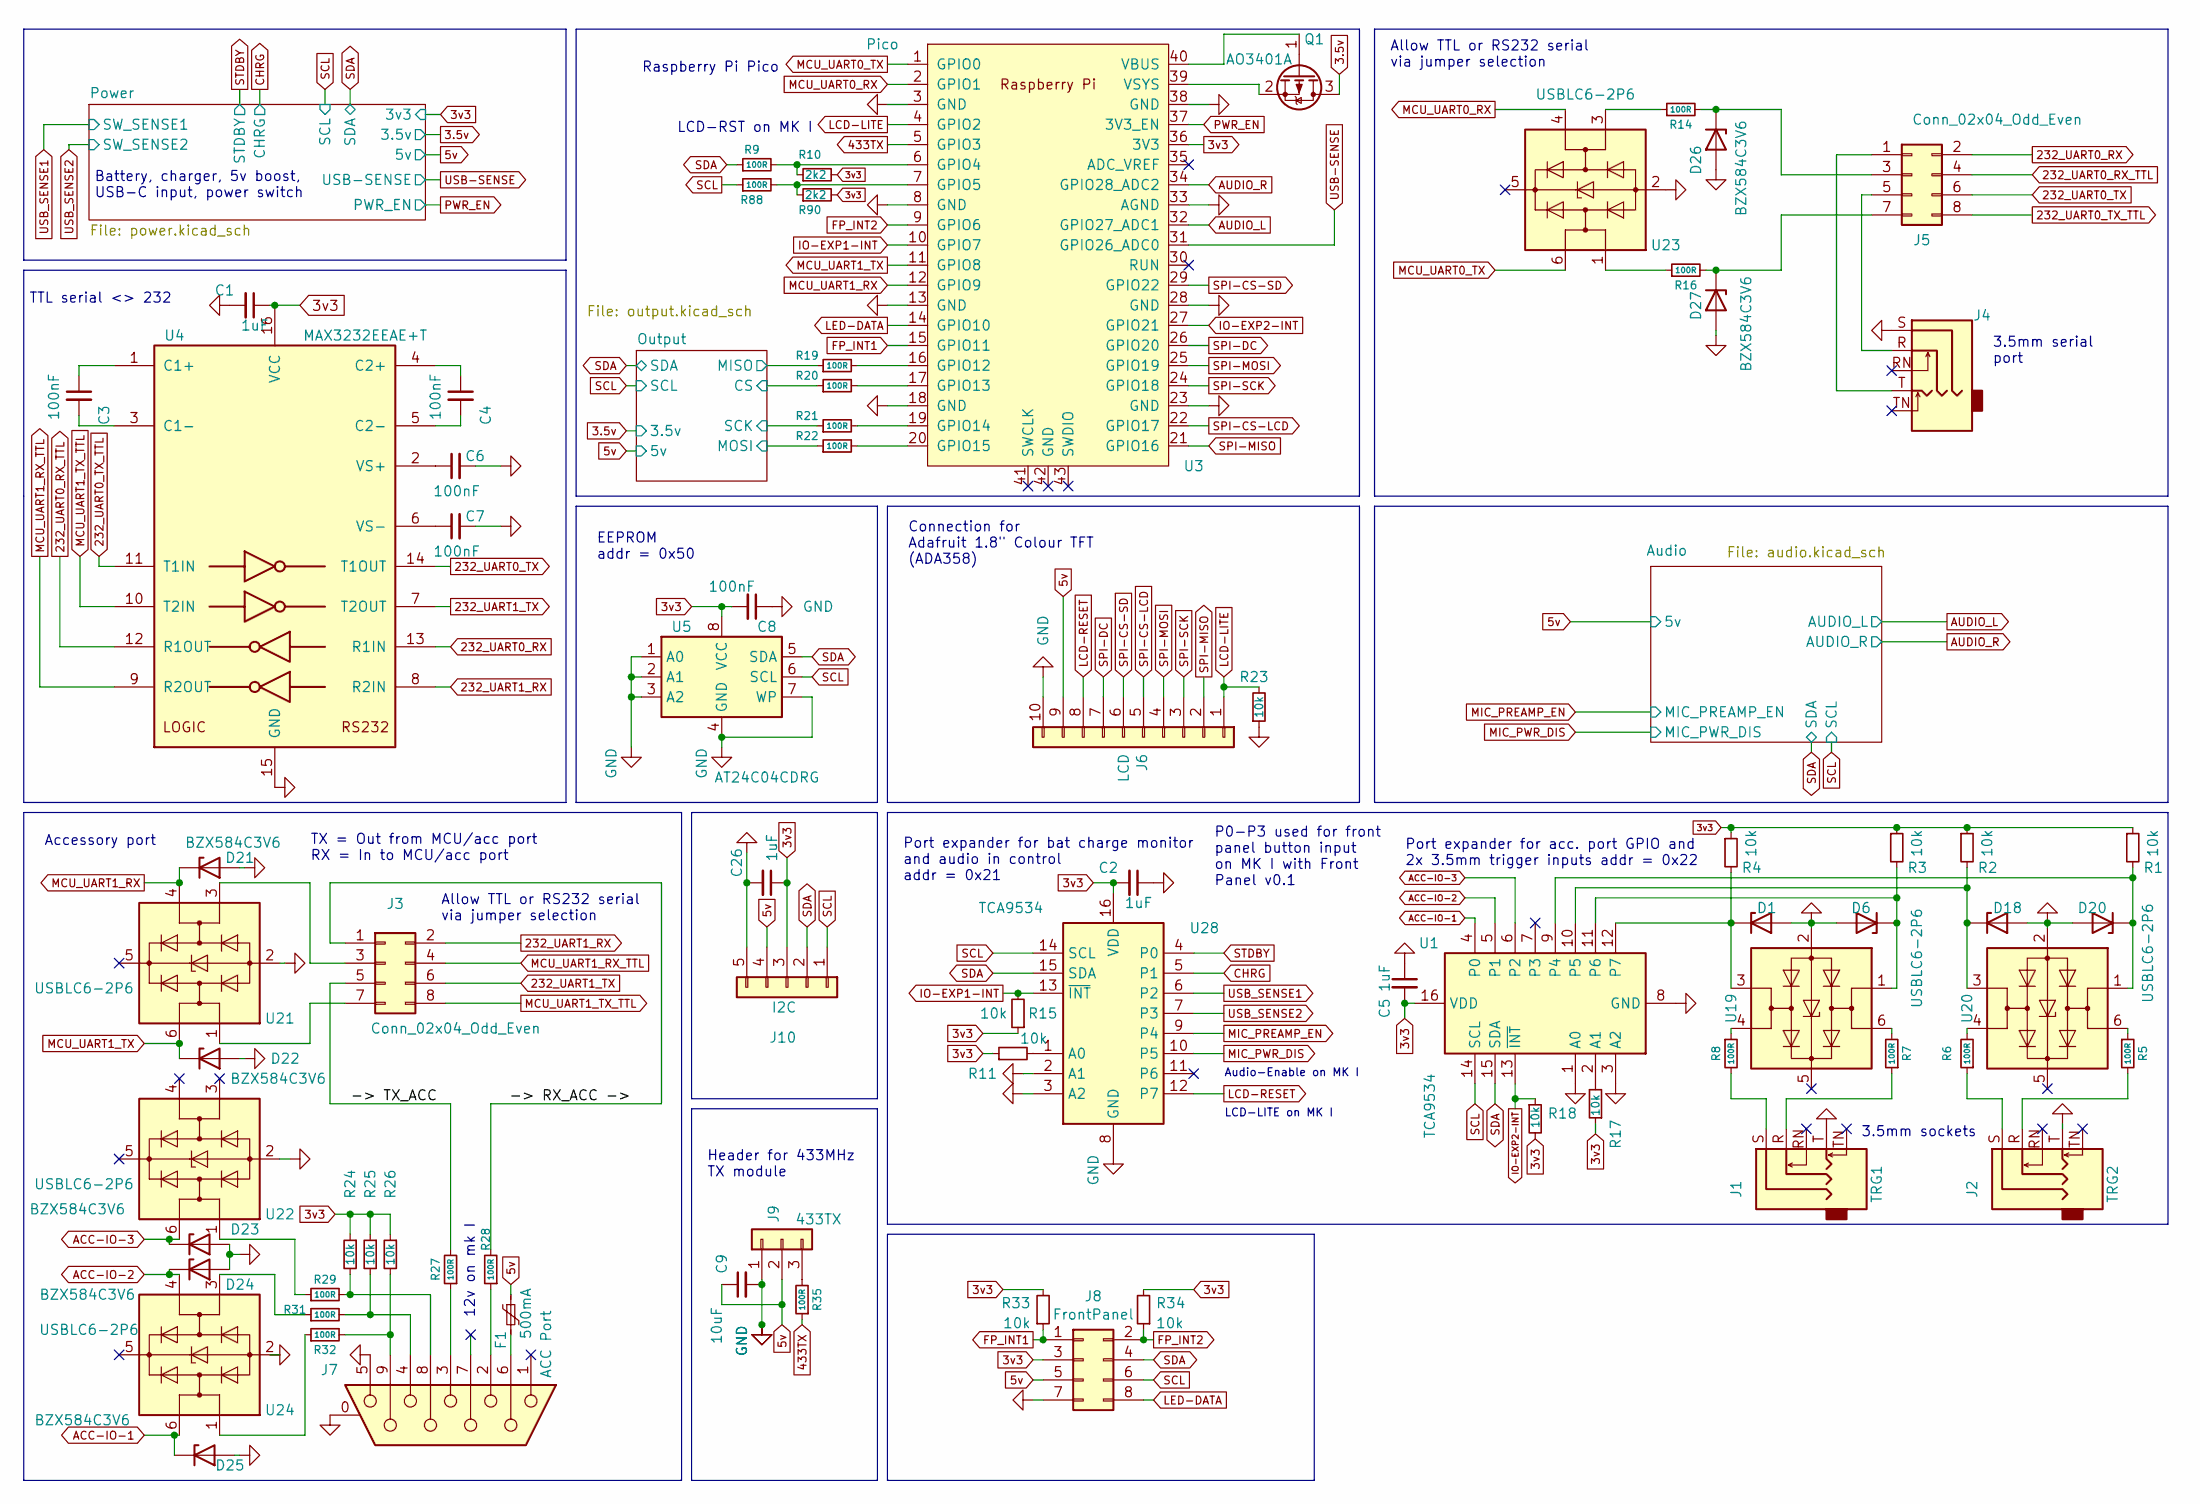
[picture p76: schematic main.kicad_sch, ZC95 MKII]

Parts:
C1, C2, C5, C26: 1uF; C_0603_1608Metric_Pad1.08x0.95mm_HandSolder; LCSC C15849
C3, C4, C6, C7, C8: 100nF; C_0603_1608Metric_Pad1.08x0.95mm_HandSolder; LCSC C14663
C9: 10uF; C_0603_1608Metric_Pad1.08x0.95mm_HandSolder; LCSC C19702
D1, D6, D18, D20, D21, D22, D23, D24, D25, D26, D27: BZX584C3V6; D_SOD-523; LCSC C22395574
F1: 500mA; Fuse_0805_2012Metric_Pad1.15x1.40mm_HandSolder; LCSC C269104
J1: TRG1; PJ-3062-CO; LCSC C319113
J2: TRG2; PJ-3062-CO; LCSC C319113
J3, J5: Conn_02x04_Odd_Even; PinSocket_2x04_P2.54mm_Vertical; LCSC C492421
J4: AudioJack3_SwitchTR; PJ-3062-CO; LCSC C319113
J6: LCD; Molex_KK-254_AE-6410-10A_1x10_P2.54mm_Vertical; LCSC C30169
J7: ACC Port; DSUB-9_Female_Horizontal_P2.77x2.84mm_EdgePinOffset7.70mm_H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; LCSC C75749
J8: FrontPanel; IDC-Header_2x04_P2.54mm_Vertical; LCSC C9135
J9: 433TX; PinSocket_1x03_P2.54mm_Vertical; LCSC C146243
J10: I2C; PinSocket_1x05_P2.54mm_Vertical
Q1: AO3401A; SOT-23_Handsoldering; LCSC C15127
R1, R2, R3, R4, R11, R15, R17, R18, R23, R24, R25, R26, R33, R34: 10k; R_0603_1608Metric_Pad0.98x0.95mm_HandSolder; LCSC C25804
R5, R6, R7, R8, R9, R14, R16, R19, R20, R21, R22, R27, R28, R29, R31, R32, R35, R88: 100R; R_0603_1608Metric_Pad0.98x0.95mm_HandSolder; LCSC C22775
R10, R90: 2k2; R_0603_1608Metric_Pad0.98x0.95mm_HandSolder; LCSC C4190
U1, U28: TCA9534; TSSOP-16_4.4x5mm_P0.65mm; LCSC C783615
U3: Pico; RPi_Pico_SMD_TH
U4: MAX3232EEAE+T; SOP65P777X199-16N; LCSC C33379
U5: AT24C04CDRG; SOP-8_3.76x4.96mm_P1.27mm; LCSC C19723707
U19, U20, U21, U22, U23, U24: USBLC6-2P6; SOT-666; LCSC C15999

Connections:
3.5v: Q1.3 (D); also elsewhere on the board
3v3: C1.1, C2.2, C5.2, C8.2, C26.1, J8.3, J10.3, R1.1, R2.1, R3.1, R4.1, R10.2, R11.1, R15.1, R17.1, R18.2, R24.1, R25.1, R26.1, R33.2, R34.2, R90.2, U1.16 (VDD), U3.36 (3V3), U4.16 (VCC), U5.8 (VCC), U28.16 (VDD); also elsewhere on the board
5v: C9.1, F1.1, J6.9, J8.5, J9.2, J10.4; also elsewhere on the board
232_UART0_RX: J5.2, U4.13 (R1IN)
232_UART0_RX_TTL: J5.4, U4.12 (R1OUT)
232_UART0_TX: J5.6, U4.14 (T1OUT)
232_UART0_TX_TTL: J5.8, U4.11 (T1IN)
232_UART1_RX: J3.2, U4.8 (R2IN)
232_UART1_TX: J3.6, U4.7 (T2OUT)
433TX: R35.1, U3.5 (GPIO3)
/-> RX_ACC ->: J3.1, R28.2
/-> TX_ACC: J3.5, R27.2
/Output/CS: R20.1; also elsewhere on the board
/Output/MISO: R19.1; also elsewhere on the board
/Output/MOSI: R22.1; also elsewhere on the board
/Output/SCK: R21.1; also elsewhere on the board
ACC-IO-1: D25.1 (K), U1.4 (P0), U24.6 (I/O1)
ACC-IO-2: D24.1 (K), U1.5 (P1), U24.4 (I/O2)
ACC-IO-3: D23.1 (K), U1.6 (P2), U22.6 (I/O1)
AUDIO_L: U3.32 (GPIO27_ADC1); also elsewhere on the board
AUDIO_R: U3.34 (GPIO28_ADC2); also elsewhere on the board
CHRG: U28.5 (P1); also elsewhere on the board
FP_INT1: J8.1, R33.1, U3.15 (GPIO11)
FP_INT2: J8.2, R34.1, U3.9 (GPIO6)
GND: C1.2, C2.1, C5.1, C6.2, C7.2, C8.1, C9.2, C26.2, D1.2 (A), D6.2 (A), D18.2 (A), D20.2 (A), D21.2 (A), D22.2 (A), D23.2 (A), D24.2 (A), D25.2 (A), D26.2 (A), D27.2 (A), J1.T, J2.T, J4.S, J6.10, J7.0 (PAD), J7.5, J8.7, J9.1, J10.5, R23.1, U1.1 (A0), U1.3 (A2), U1.8 (GND), U3.3 (GND), U3.8 (GND), U3.13 (GND), U3.18 (GND), U3.23 (GND), U3.28 (GND), U3.33 (AGND), U3.38 (GND), U4.15 (GND), U5.1 (A0), U5.2 (A1), U5.3 (A2), U5.4 (GND), U5.7 (WP), U19.2 (GND), U20.2 (GND), U21.2 (GND), U22.2 (GND), U23.2 (GND), U24.2 (GND), U28.2 (A1), U28.3 (A2), U28.8 (GND); also elsewhere on the board
IO-EXP1-INT: R15.2, U3.10 (GPIO7), U28.13 (~INT)
IO-EXP2-INT: R18.1, U1.13 (~INT), U3.27 (GPIO21)
LCD-LITE: J6.1, R23.2, U3.4 (GPIO2)
LCD-RESET: J6.8, U28.12 (P7)
LED-DATA: J8.8, U3.14 (GPIO10)
MCU_UART0_RX: U3.2 (GPIO1), U23.4 (I/O2)
MCU_UART0_TX: U3.1 (GPIO0), U23.6 (I/O1)
MCU_UART1_RX: D21.1 (K), U3.12 (GPIO9), U21.4 (I/O2)
MCU_UART1_RX_TTL: J3.4, U4.9 (R2OUT)
MCU_UART1_TX: D22.1 (K), U3.11 (GPIO8), U21.6 (I/O1)
MCU_UART1_TX_TTL: J3.8, U4.10 (T2IN)
MIC_PREAMP_EN: U28.9 (P4); also elsewhere on the board
MIC_PWR_DIS: U28.10 (P5); also elsewhere on the board
unnamed: C3.1, U4.1 (C1+)
unnamed: C3.2, U4.3 (C1-)
unnamed: C4.1, U4.4 (C2+)
unnamed: C4.2, U4.5 (C2-)
unnamed: C6.1, U4.2 (VS+)
unnamed: C7.1, U4.6 (VS-)
unnamed: D1.1 (K), R4.2, U1.12 (P7), U19.3 (I/O2)
unnamed: D6.1 (K), R3.2, U1.11 (P6), U19.1 (I/O1)
unnamed: D18.1 (K), R2.2, U1.10 (P5), U20.3 (I/O2)
unnamed: D20.1 (K), R1.2, U1.9 (P4), U20.1 (I/O1)
unnamed: D26.1 (K), J5.3, R14.2
unnamed: D27.1 (K), J5.7, R16.2
unnamed: F1.2, J7.6
unnamed: J1.R, R7.1
unnamed: J1.S, R8.2
unnamed: J2.R, R5.2
unnamed: J2.S, R6.1
unnamed: J3.3, U21.3 (I/O2)
unnamed: J3.7, U21.1 (I/O1)
unnamed: J4.R, J5.5
unnamed: J4.T, J5.1
unnamed: J7.2, R28.1
unnamed: J7.3, R27.1
unnamed: J7.4, R25.2, R31.2
unnamed: J7.8, R24.2, R29.2
unnamed: J7.9, R26.2, R32.2
unnamed: J9.3, R35.2
unnamed: Q1.1 (G), U3.40 (VBUS)
unnamed: Q1.2 (S), U3.39 (VSYS)
unnamed: R5.1, U20.6 (I/O1)
unnamed: R6.2, U20.4 (I/O2)
unnamed: R7.2, U19.6 (I/O1)
unnamed: R8.1, U19.4 (I/O2)
unnamed: R9.2, R10.1, U3.6 (GPIO4)
unnamed: R11.2, U28.1 (A0)
unnamed: R14.1, U23.3 (I/O2)
unnamed: R16.1, U23.1 (I/O1)
unnamed: R17.2, U1.2 (A1)
unnamed: R19.2, U3.16 (GPIO12)
unnamed: R20.2, U3.17 (GPIO13)
unnamed: R21.2, U3.19 (GPIO14)
unnamed: R22.2, U3.20 (GPIO15)
unnamed: R29.1, U22.1 (I/O1)
unnamed: R31.1, U24.3 (I/O2)
unnamed: R32.1, U24.1 (I/O1)
unnamed: R88.2, R90.1, U3.7 (GPIO5)
PWR_EN: U3.37 (3V3_EN); also elsewhere on the board
SCL: J8.6, J10.1, R88.1, U1.14 (SCL), U5.6 (SCL), U28.14 (SCL); also elsewhere on the board
SDA: J8.4, J10.2, R9.1, U1.15 (SDA), U5.5 (SDA), U28.15 (SDA); also elsewhere on the board
SPI-CS-LCD: J6.5, U3.22 (GPIO17)
SPI-CS-SD: J6.6, U3.29 (GPIO22)
SPI-DC: J6.7, U3.26 (GPIO20)
SPI-MISO: J6.2, U3.21 (GPIO16)
SPI-MOSI: J6.4, U3.25 (GPIO19)
SPI-SCK: J6.3, U3.24 (GPIO18)
STDBY: U28.4 (P0); also elsewhere on the board
USB-SENSE: U3.31 (GPIO26_ADC0); also elsewhere on the board
USB_SENSE1: U28.6 (P2); also elsewhere on the board
USB_SENSE2: U28.7 (P3); also elsewhere on the board

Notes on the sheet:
Allow TTL or RS232 serial via jumper selection
3.5mm serial port
LCD-RST on MK I
Battery, charger, 5v boost, USB-C input, power switch
P0-P3 used for front panel button input on MK I with Front Panel v0.1
Accessory port
Header for 433MHz TX module
Raspberry Pi Pico
TX = Out from MCU/acc port RX = In to MCU/acc port
EEPROM addr = 0x50
3.5mm sockets
Connection for Adafruit 1.8" Colour TFT (ADA358)
Audio-Enable on MK I
Port expander for acc. port GPIO and 2x 3.5mm trigger inputs addr = 0x22
TTL serial <> 232
12v on mk I
Port expander for bat charge monitor and audio in control addr = 0x21
LCD-LITE on MK I

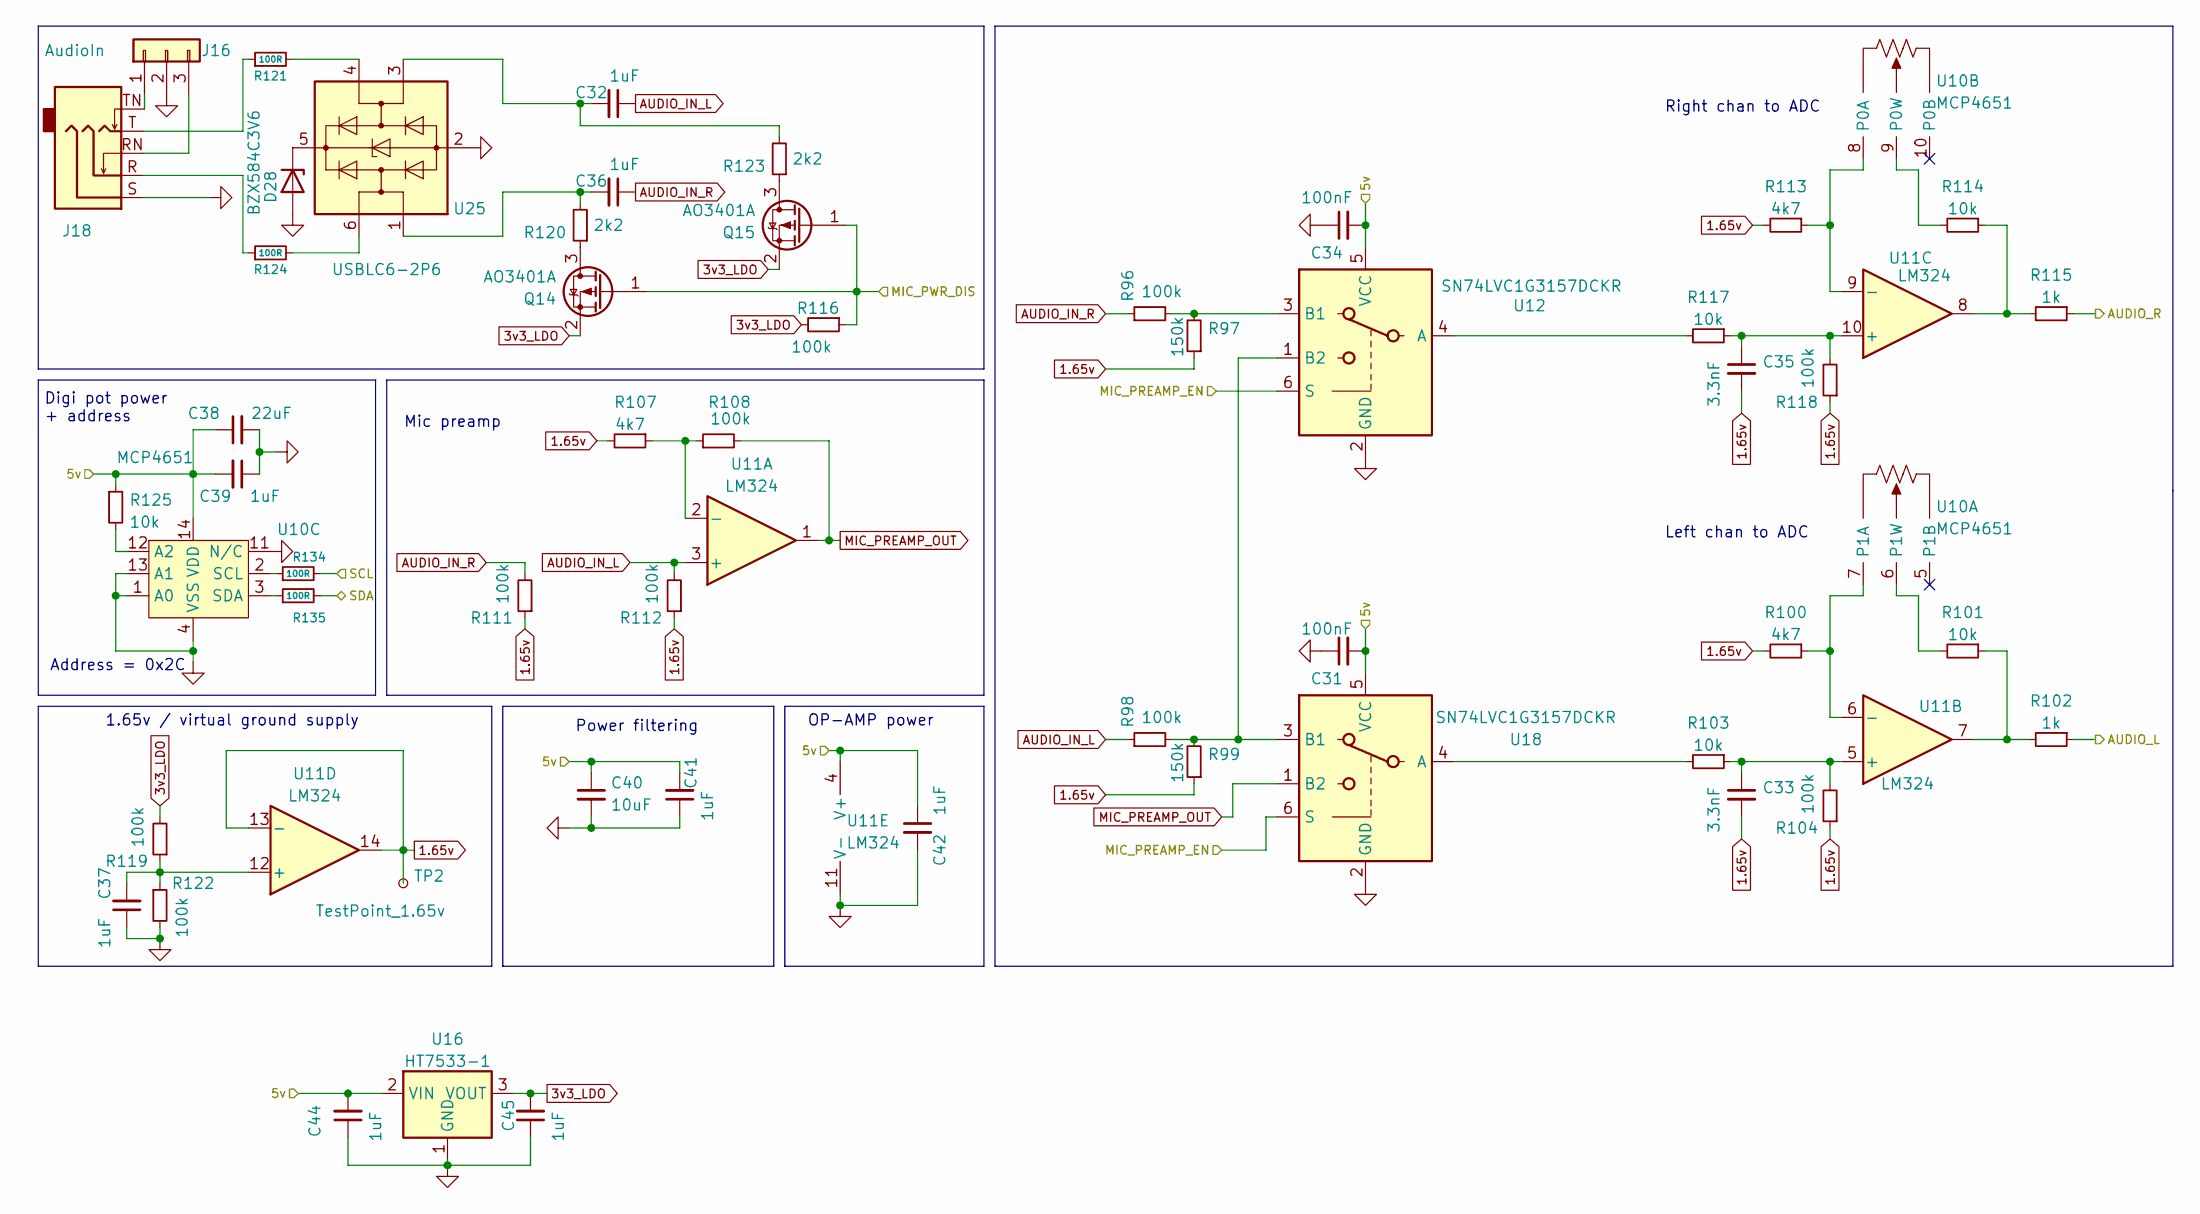
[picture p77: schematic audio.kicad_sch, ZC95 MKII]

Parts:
C31, C34: 100nF; C_0603_1608Metric_Pad1.08x0.95mm_HandSolder; LCSC C14663
C32, C36, C37, C39, C41, C42, C44, C45: 1uF; C_0603_1608Metric_Pad1.08x0.95mm_HandSolder; LCSC C15849
C33, C35: 3.3nF; C_0603_1608Metric_Pad1.08x0.95mm_HandSolder; LCSC C1613
C38: 22uF; C_0805_2012Metric_Pad1.18x1.45mm_HandSolder; LCSC C45783
C40: 10uF; C_0603_1608Metric_Pad1.08x0.95mm_HandSolder; LCSC C19702
D28: BZX584C3V6; D_SOD-523; LCSC C22395574
J16: AudioIn; PinSocket_1x03_P2.54mm_Vertical; LCSC C146243
J18: AudioJack3_SwitchTR; PJ-3062-CO; LCSC C319113
Q14, Q15: AO3401A; SOT-23_Handsoldering; LCSC C15127
R96, R98, R104, R108, R111, R112, R116, R118, R119, R122: 100k; R_0603_1608Metric_Pad0.98x0.95mm_HandSolder; LCSC C25803
R97, R99: 150k; R_0603_1608Metric_Pad0.98x0.95mm_HandSolder; LCSC C22807
R100, R107, R113: 4k7; R_0603_1608Metric_Pad0.98x0.95mm_HandSolder; LCSC C23162
R101, R103, R114, R117, R125: 10k; R_0603_1608Metric_Pad0.98x0.95mm_HandSolder; LCSC C25804
R102, R115: 1k; R_0603_1608Metric_Pad0.98x0.95mm_HandSolder; LCSC C21190
R120, R123: 2k2; R_0603_1608Metric_Pad0.98x0.95mm_HandSolder; LCSC C4190
R121, R124, R134, R135: 100R; R_0603_1608Metric_Pad0.98x0.95mm_HandSolder; LCSC C22775
TP2: TestPoint_1.65v; TestPoint_Pad_D1.5mm
U10: MCP4651; TSSOP-14_4.4x5mm_P0.65mm; LCSC C148010
U11: LM324; SOIC-14_3.9x8.7mm_P1.27mm; LCSC C71035
U12, U18: SN74LVC1G3157DCKR; SOT-363_SC-70-6_Handsoldering; LCSC C38663
U16: HT7533-1; SOT-89-3; LCSC C14289
U25: USBLC6-2P6; SOT-666; LCSC C15999

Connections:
1.65v: C33.2, C35.2, R97.1, R99.1, R100.2, R104.1, R107.2, R111.1, R112.1, R113.2, R118.1, TP2.1, U11.13 (-), U11.14
3v3_LDO: C45.2, Q14.2 (S), Q15.2 (S), R116.2, R119.2, U16.3 (VOUT)
5v: C31.2, C34.2, C38.1, C39.2, C40.1, C41.2, C42.1, C44.2, R125.1, U10.14 (VDD), U11.4 (V+), U12.5 (VCC), U16.2 (VIN), U18.5 (VCC); also elsewhere on the board
AUDIO_IN_L: C32.1, R98.1, R112.2, U11.3 (+)
AUDIO_IN_R: C36.1, R96.1, R111.2
AUDIO_L: R102.1; also elsewhere on the board
AUDIO_R: R115.1; also elsewhere on the board
GND: C31.1, C34.1, C37.1, C38.2, C39.1, C40.2, C41.1, C42.2, C44.1, C45.1, D28.2 (A), J16.2, J18.S, R122.2, U10.1 (A0), U10.4 (VSS), U10.11 (N/C), U10.13 (A1), U11.11 (V-), U12.2 (GND), U16.1 (GND), U18.2 (GND), U25.2 (GND); also elsewhere on the board
MIC_PREAMP_EN: U12.6 (S), U18.6 (S); also elsewhere on the board
MIC_PREAMP_OUT: R108.2, U11.1, U18.1 (B2)
MIC_PWR_DIS: Q14.1 (G), Q15.1 (G), R116.1; also elsewhere on the board
unnamed: C32.2, R123.2, U25.3 (I/O2)
unnamed: C33.1, R103.1, R104.2, U11.5 (+)
unnamed: C35.1, R117.1, R118.2, U11.10 (+)
unnamed: C36.2, R120.2, U25.1 (I/O1)
unnamed: C37.2, R119.1, R122.1, U11.12 (+)
unnamed: D28.1 (K), U25.5 (VBUS)
unnamed: J16.1, J18.TN
unnamed: J16.3, J18.RN
unnamed: J18.R, R124.1
unnamed: J18.T, R121.1
unnamed: Q14.3 (D), R120.1
unnamed: Q15.3 (D), R123.1
unnamed: R96.2, R97.2, U12.3 (B1)
unnamed: R98.2, R99.2, U12.1 (B2), U18.3 (B1)
unnamed: R100.1, U10.7 (P1A), U11.6 (-)
unnamed: R101.1, R102.2, U11.7
unnamed: R101.2, U10.6 (P1W)
unnamed: R103.2, U18.4 (A)
unnamed: R107.1, R108.1, U11.2 (-)
unnamed: R113.1, U10.8 (P0A), U11.9 (-)
unnamed: R114.1, R115.2, U11.8
unnamed: R114.2, U10.9 (P0W)
unnamed: R117.2, U12.4 (A)
unnamed: R121.2, U25.4 (I/O2)
unnamed: R124.2, U25.6 (I/O1)
unnamed: R125.2, U10.12 (A2)
unnamed: R134.1, U10.2 (SCL)
unnamed: R135.1, U10.3 (SDA)
SCL: R134.2; also elsewhere on the board
SDA: R135.2; also elsewhere on the board

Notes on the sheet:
Left chan to ADC
Power filtering
OP-AMP power
Right chan to ADC
1.65v / virtual ground supply
Digi pot power + address
Mic preamp
Address = 0x2C

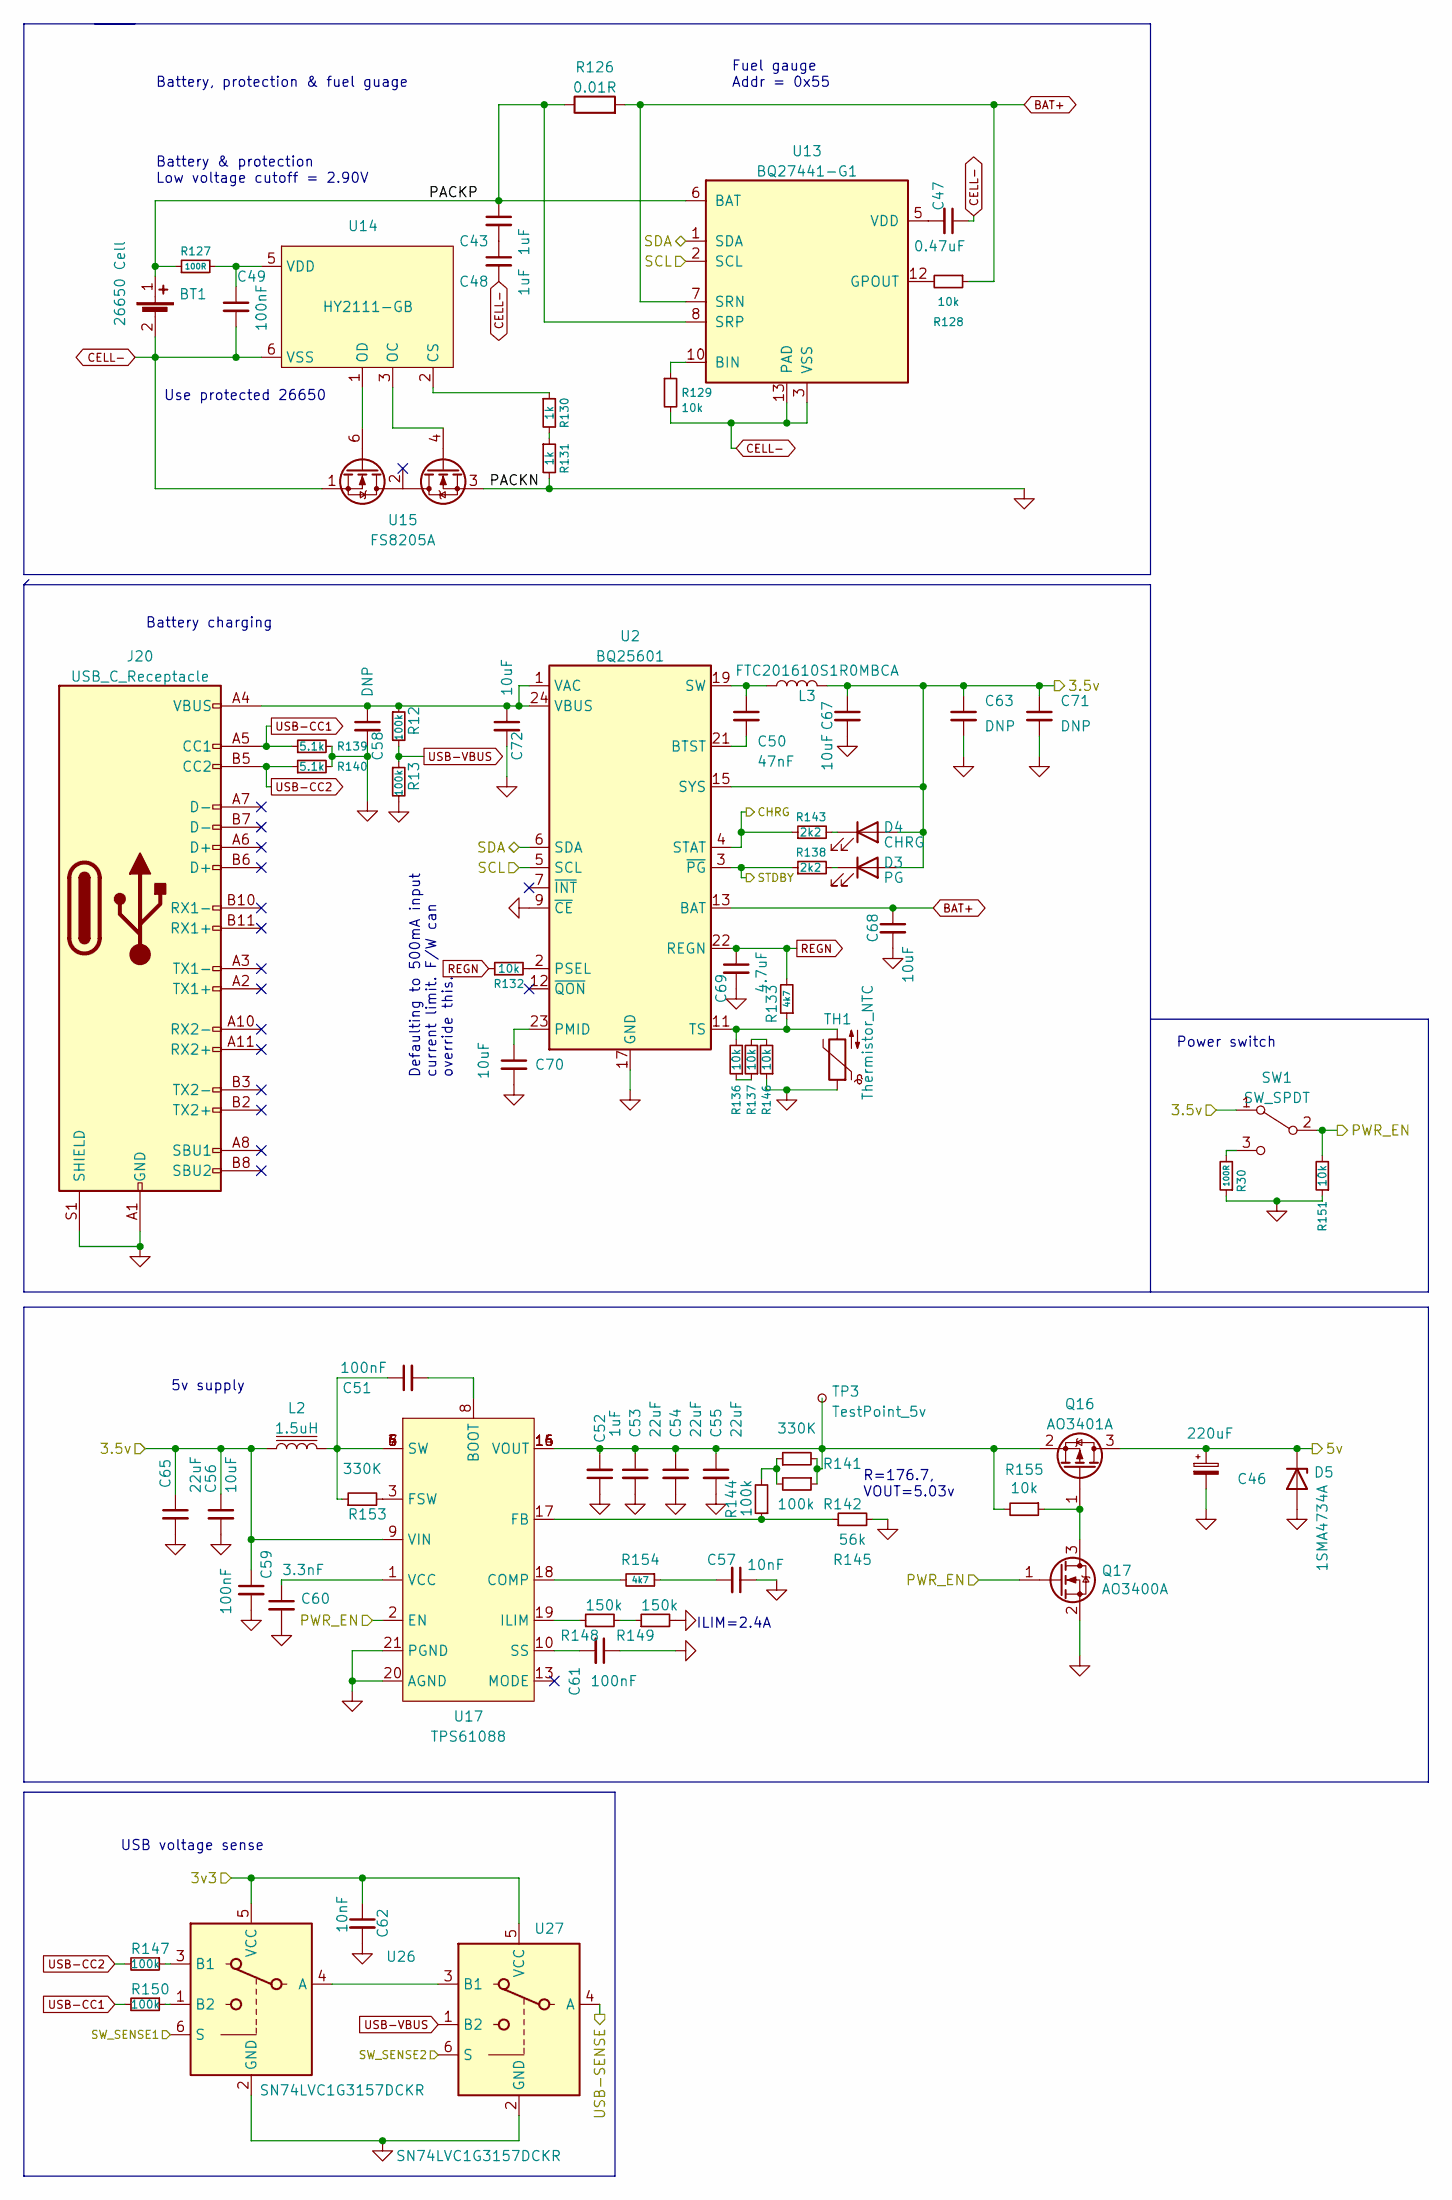
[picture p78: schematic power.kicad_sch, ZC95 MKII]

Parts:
BT1: 26650 Cell; BH-26650-A5BJ001; LCSC C6937119
C43, C48, C52: 1uF; C_0603_1608Metric_Pad1.08x0.95mm_HandSolder; LCSC C15849
C46: 220uF; CP_EIA-7343-43_Kemet-X_Pad2.25x2.55mm_HandSolder; LCSC C122311
C47: 0.47uF; C_0603_1608Metric_Pad1.08x0.95mm_HandSolder; LCSC C1623
C49, C51, C59, C61: 100nF; C_0603_1608Metric_Pad1.08x0.95mm_HandSolder; LCSC C14663
C50: 47nF; C_0603_1608Metric_Pad1.08x0.95mm_HandSolder; LCSC C1622
C53, C54, C55, C65: 22uF; C_0805_2012Metric_Pad1.18x1.45mm_HandSolder; LCSC C45783
C56, C67, C68, C70, C72: 10uF; C_0603_1608Metric_Pad1.08x0.95mm_HandSolder; LCSC C19702
C57, C62: 10nF; C_0603_1608Metric_Pad1.08x0.95mm_HandSolder; LCSC C57112
C58, C71: DNP; C_0603_1608Metric_Pad1.08x0.95mm_HandSolder
C60: 3.3nF; C_0603_1608Metric_Pad1.08x0.95mm_HandSolder; LCSC C1613
C63: DNP; R_0805_2012Metric_Pad1.20x1.40mm_HandSolder
C69: 4.7uF; C_0603_1608Metric_Pad1.08x0.95mm_HandSolder; LCSC C19666
D3: PG; LED_0603_1608Metric_Pad1.05x0.95mm_HandSolder; LCSC C2986059
D4: CHRG; LED_0603_1608Metric_Pad1.05x0.95mm_HandSolder; LCSC C2986059
D5: 1SMA4734A; D_SMA; LCSC C19077477
J20: USB_C_Receptacle; 1054500101; LCSC C134092
L2: 1.5uH; FXL0630; LCSC C167217
L3: FTC201610S1R0MBCA; FTC201610S; LCSC C5832342
Q16: AO3401A; SOT-23_Handsoldering; LCSC C15127
Q17: AO3400A; SOT-23_Handsoldering; LCSC C20917
R12, R13, R142, R144, R147, R150: 100k; R_0603_1608Metric_Pad0.98x0.95mm_HandSolder; LCSC C25803
R30, R127: 100R; R_0603_1608Metric_Pad0.98x0.95mm_HandSolder; LCSC C22775
R126: 0.01R; R_1206_3216Metric_Pad1.30x1.75mm_HandSolder; LCSC C105362
R128, R129, R132, R136, R137, R146, R151, R155: 10k; R_0603_1608Metric_Pad0.98x0.95mm_HandSolder; LCSC C25804
R130, R131: 1k; R_0603_1608Metric_Pad0.98x0.95mm_HandSolder; LCSC C21190
R133, R154: 4k7; R_0603_1608Metric_Pad0.98x0.95mm_HandSolder; LCSC C23162
R138, R143: 2k2; R_0603_1608Metric_Pad0.98x0.95mm_HandSolder; LCSC C4190
R139, R140: 5.1k; R_0603_1608Metric_Pad0.98x0.95mm_HandSolder; LCSC C23186
R141, R153: 330K; R_0603_1608Metric_Pad0.98x0.95mm_HandSolder; LCSC C23137
R145: 56k; R_0603_1608Metric_Pad0.98x0.95mm_HandSolder; LCSC C23206
R148, R149: 150k; R_0603_1608Metric_Pad0.98x0.95mm_HandSolder; LCSC C22807
SW1: SW_SPDT; SS-12D06L5; LCSC C319015
TH1: Thermistor_NTC; PinHeader_1x02_P2.54mm_Vertical
TP3: TestPoint_5v; TestPoint_Pad_D1.5mm
U2: BQ25601; Texas_S-PWQFN-N24_EP2.7x2.7mm_ThermalVias; LCSC C2859691
U13: BQ27441-G1; Texas_S-PDSO-N12; LCSC C473397
U14: HY2111-GB; SOT-23-6_Handsoldering; LCSC C82747
U15: FS8205A; SOT-23-6_Handsoldering; LCSC C908265
U17: TPS61088; IC_TPS61088RHLR; LCSC C87357
U26, U27: SN74LVC1G3157DCKR; SOT-363_SC-70-6_Handsoldering; LCSC C38663

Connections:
3.5v: C56.1, C59.1, C63.1, C65.1, C67.1, C71.1, D3.2 (A), D4.2 (A), L2.1, L3.2, SW1.1 (A), U2.15 (SYS), U2.16 (SYS), U17.9 (VIN); also elsewhere on the board
3v3: C62.1, U26.5 (VCC), U27.5 (VCC); also elsewhere on the board
5v: C46.1, D5.1 (K), Q16.3 (D); also elsewhere on the board
/Power/PACKP: BT1.1 (+), C43.1, R126.1, R127.1, U13.6 (BAT), U13.8 (SRP)
BAT+: C68.1, R126.2, R128.1, U2.13 (BAT), U2.14 (BAT), U13.7 (SRN)
CELL-: BT1.2 (-), C47.1, C48.2, C49.2, R129.2, U13.3 (VSS), U13.13 (PAD), U14.6 (VSS), U15.1
CHRG: R143.1, U2.4 (STAT); also elsewhere on the board
GND: C46.2, C52.1, C53.2, C54.2, C55.2, C56.2, C57.1, C58.2, C59.2, C60.2, C61.1, C62.2, C63.2, C65.2, C67.2, C68.2, C69.2, C70.2, C71.2, C72.2, D5.2 (A), J20.A1 (GND), J20.A12 (GND), J20.B1 (GND), J20.B12 (GND), J20.S1 (SHIELD), Q17.2 (S), R13.2, R30.1, R131.2, R139.2, R140.2, R145.2, R146.1, R149.2, R151.1, TH1.1, U2.9 (~CE), U2.17 (GND), U2.18 (GND), U2.25 (GND), U15.3, U17.20 (AGND), U17.21 (PGND), U26.2 (GND), U27.2 (GND); also elsewhere on the board
unnamed: C43.2, C48.1
unnamed: C47.2, U13.5 (VDD)
unnamed: C49.1, R127.2, U14.5 (VDD)
unnamed: C50.1, L3.1, U2.19 (SW), U2.20 (SW)
unnamed: C50.2, U2.21 (BTST)
unnamed: C51.1, L2.2, R153.1, U17.4 (SW), U17.5 (SW), U17.6 (SW), U17.7 (SW)
unnamed: C51.2, U17.8 (BOOT)
unnamed: C52.2, C53.1, C54.1, C55.1, Q16.2 (S), R141.2, R142.1, R155.2, TP3.1, U17.14 (VOUT), U17.15 (VOUT), U17.16 (VOUT)
unnamed: C57.2, R154.1
unnamed: C58.1, C72.1, J20.A4 (VBUS), J20.A9 (VBUS), J20.B4 (VBUS), J20.B9 (VBUS), R12.1, U2.1 (VAC), U2.24 (VBUS)
unnamed: C60.1, U17.1 (VCC)
unnamed: C61.2, U17.10 (SS)
unnamed: C70.1, U2.23 (PMID)
unnamed: D3.1 (K), R138.2
unnamed: D4.1 (K), R143.2
unnamed: Q16.1 (G), Q17.3 (D), R155.1
unnamed: R30.2, SW1.3 (C)
unnamed: R128.2, U13.12 (GPOUT)
unnamed: R129.1, U13.10 (BIN)
unnamed: R130.1, U14.2 (CS)
unnamed: R130.2, R131.1
unnamed: R132.2, U2.2 (PSEL)
unnamed: R133.1, R136.2, TH1.2, U2.11 (TS)
unnamed: R136.1, R137.1
unnamed: R137.2, R146.2
unnamed: R141.1, R142.2, R144.2
unnamed: R144.1, R145.1, U17.17 (FB)
unnamed: R147.1, U26.3 (B1)
unnamed: R148.1, U17.19 (ILIM)
unnamed: R148.2, R149.1
unnamed: R150.1, U26.1 (B2)
unnamed: R153.2, U17.3 (FSW)
unnamed: R154.2, U17.18 (COMP)
unnamed: U14.1 (OD), U15.6
unnamed: U14.3 (OC), U15.4
unnamed: U26.4 (A), U27.3 (B1)
PWR_EN: Q17.1 (G), R151.2, SW1.2 (B), U17.2 (EN); also elsewhere on the board
REGN: C69.1, R132.1, R133.2, U2.22 (REGN)
SCL: U2.5 (SCL), U13.2 (SCL); also elsewhere on the board
SDA: U2.6 (SDA), U13.1 (SDA); also elsewhere on the board
STDBY: R138.1, U2.3 (~PG); also elsewhere on the board
USB-CC1: J20.A5 (CC1), R139.1, R150.2
USB-CC2: J20.B5 (CC2), R140.1, R147.2
USB-SENSE: U27.4 (A); also elsewhere on the board
USB-VBUS: R12.2, R13.1, U27.1 (B2)
USB_SENSE1: U26.6 (S); also elsewhere on the board
USB_SENSE2: U27.6 (S); also elsewhere on the board

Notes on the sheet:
Defaulting to 500mA input current limit. F/W can override this.
Power switch
Battery, protection & fuel guage
Battery charging
ILIM=2.4A
Use protected 26650
USB voltage sense
R=176.7, VOUT=5.03v
Battery & protection Low voltage cutoff = 2.90V
5v supply
Fuel gauge Addr = 0x55

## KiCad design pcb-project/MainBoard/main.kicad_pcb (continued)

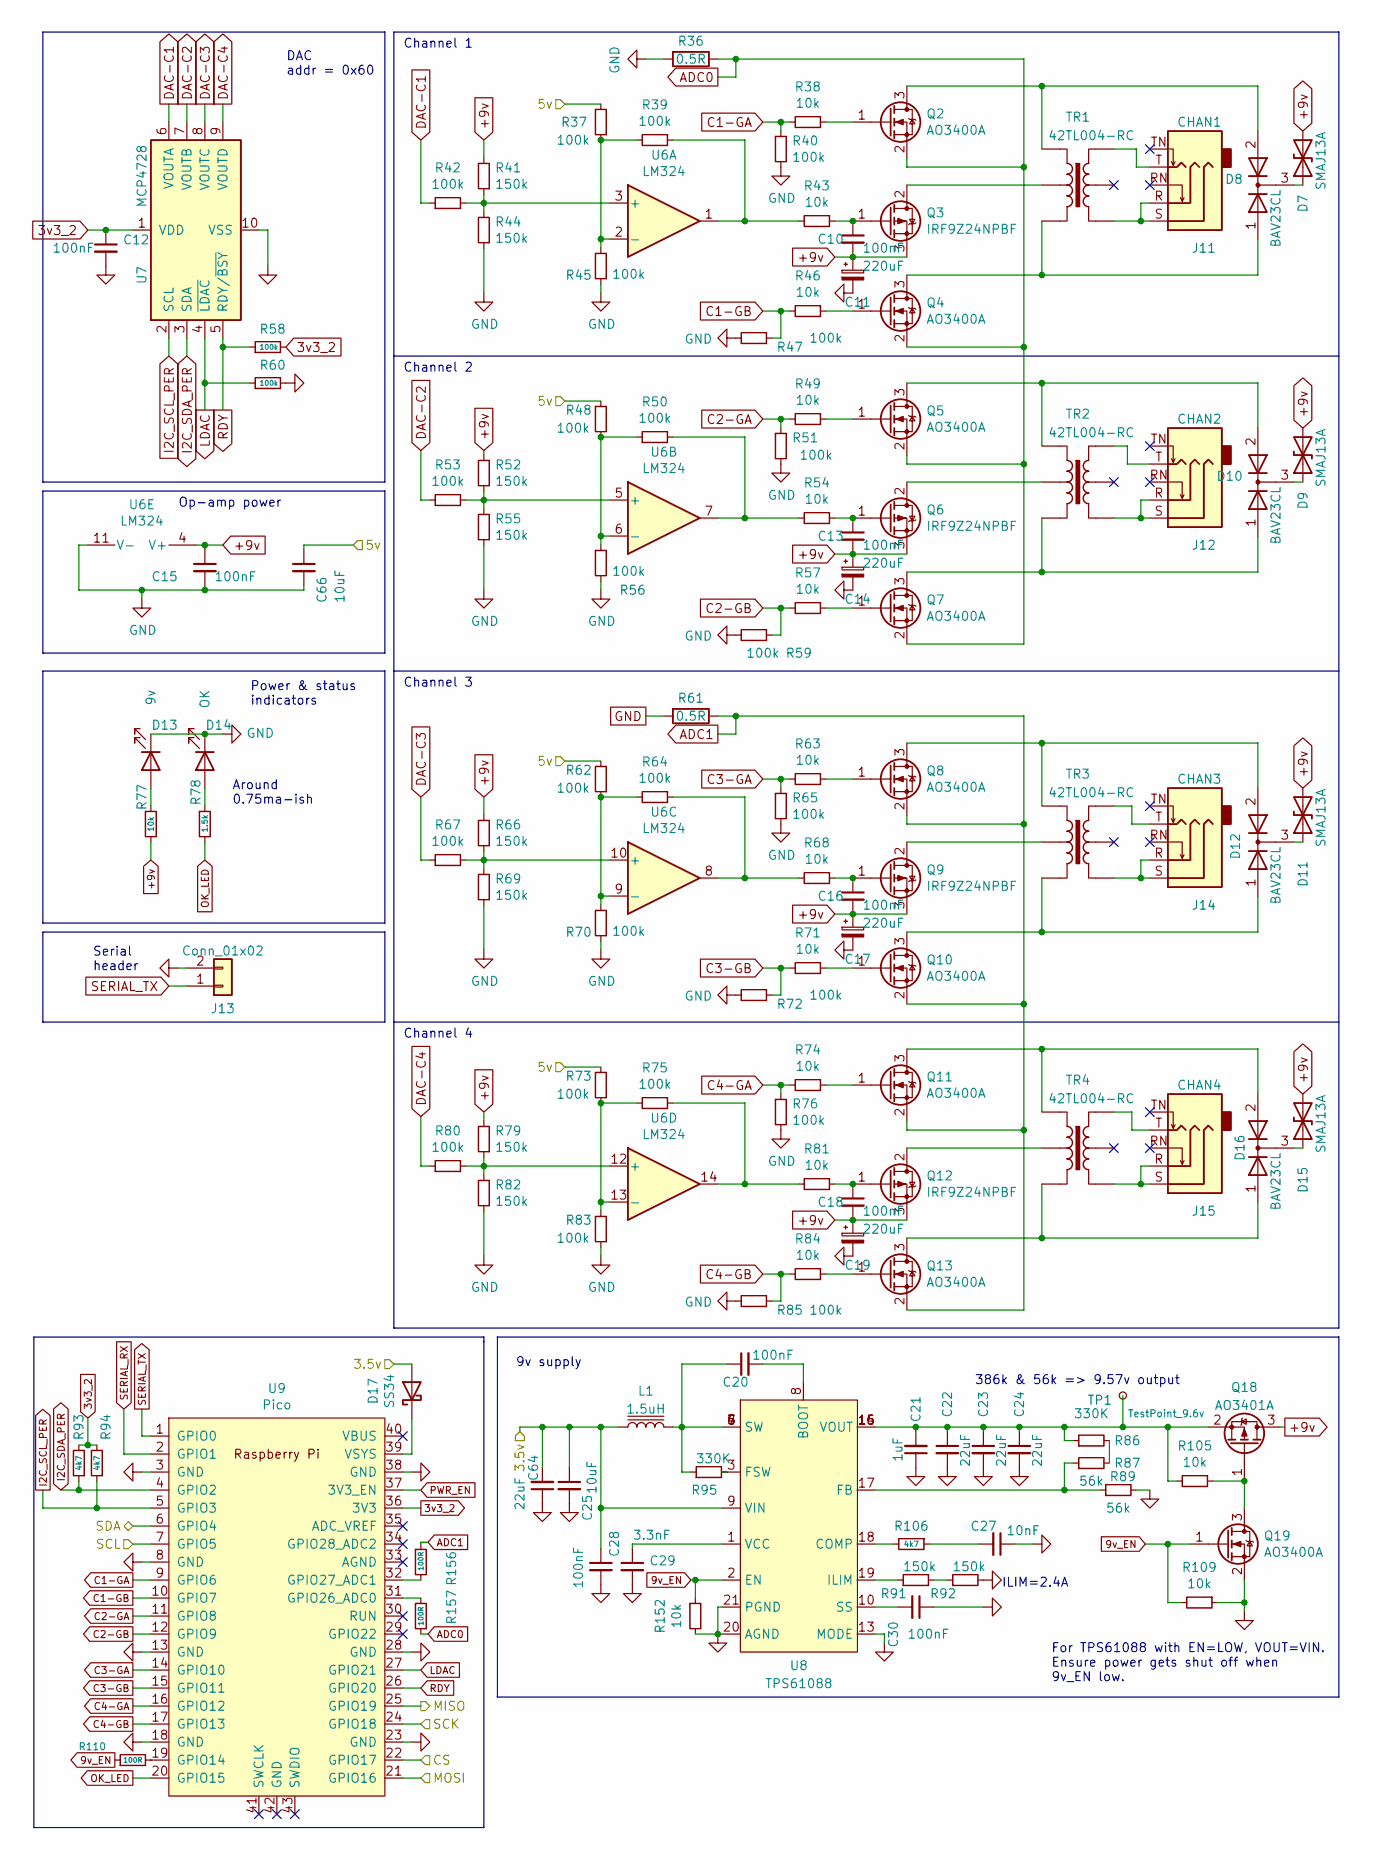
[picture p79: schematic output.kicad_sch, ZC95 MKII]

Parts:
C10, C12, C13, C15, C16, C18, C20, C28, C30: 100nF; C_0603_1608Metric_Pad1.08x0.95mm_HandSolder; LCSC C14663
C11, C14, C17, C19: 220uF; CP_EIA-7343-43_Kemet-X_Pad2.25x2.55mm_HandSolder; LCSC C122311
C21: 1uF; C_0603_1608Metric_Pad1.08x0.95mm_HandSolder; LCSC C15849
C22, C23, C24, C64: 22uF; C_0805_2012Metric_Pad1.18x1.45mm_HandSolder; LCSC C45783
C25, C66: 10uF; C_0603_1608Metric_Pad1.08x0.95mm_HandSolder; LCSC C19702
C27: 10nF; C_0603_1608Metric_Pad1.08x0.95mm_HandSolder; LCSC C57112
C29: 3.3nF; C_0603_1608Metric_Pad1.08x0.95mm_HandSolder; LCSC C1613
D7, D9, D11, D15: SMAJ13A; D_SMA; LCSC C110519
D8, D10, D12, D16: BAV23CL; SOT-23-3; LCSC C232533
D13: 9v; LED_0603_1608Metric_Pad1.05x0.95mm_HandSolder; LCSC C2986059
D14: OK; LED_0603_1608Metric_Pad1.05x0.95mm_HandSolder; LCSC C2986059
D17: SS34; D_SMA; LCSC C8678
J11: CHAN1; PJ-3062-CO; LCSC C319113
J12: CHAN2; PJ-3062-CO; LCSC C319113
J13: Conn_01x02; Molex_KK-254_AE-6410-02A_1x02_P2.54mm_Vertical; LCSC C27543
J14: CHAN3; PJ-3062-CO; LCSC C319113
J15: CHAN4; PJ-3062-CO; LCSC C319113
L1: 1.5uH; FXL0630; LCSC C167217
Q2, Q4, Q5, Q7, Q8, Q10, Q11, Q13, Q19: AO3400A; SOT-23_Handsoldering; LCSC C20917
Q3, Q6, Q9, Q12: IRF9Z24NPBF; TO-220-3_Vertical; LCSC C2576
Q18: AO3401A; SOT-23_Handsoldering; LCSC C15127
R36, R61: 0.5R; R_2512_6332Metric_Pad1.40x3.35mm_HandSolder; LCSC C2904268
R37, R39, R40, R42, R45, R47, R48, R50, R51, R53, R56, R58, R59, R60, R62, R64, R65, R67, R70, R72, R73, R75, R76, R80, R83, R85: 100k; R_0603_1608Metric_Pad0.98x0.95mm_HandSolder; LCSC C25803
R38, R43, R46, R49, R54, R57, R63, R68, R71, R74, R77, R81, R84, R105, R109, R152: 10k; R_0603_1608Metric_Pad0.98x0.95mm_HandSolder; LCSC C25804
R41, R44, R52, R55, R66, R69, R79, R82, R91, R92: 150k; R_0603_1608Metric_Pad0.98x0.95mm_HandSolder; LCSC C22807
R78: 1.5k; R_0603_1608Metric_Pad0.98x0.95mm_HandSolder; LCSC C22843
R86, R95: 330K; R_0603_1608Metric_Pad0.98x0.95mm_HandSolder; LCSC C23137
R87, R89: 56k; R_0603_1608Metric_Pad0.98x0.95mm_HandSolder; LCSC C23206
R93, R94, R106: 4k7; R_0603_1608Metric_Pad0.98x0.95mm_HandSolder; LCSC C23162
R110, R156, R157: 100R; R_0603_1608Metric_Pad0.98x0.95mm_HandSolder; LCSC C22775
TP1: TestPoint_9.6v; TestPoint_Pad_D1.5mm
TR1, TR2, TR3, TR4: 42TL004-RC; 42TL+U
U6: LM324; SOIC-14_3.9x8.7mm_P1.27mm; LCSC C71035
U7: MCP4728; MSOP-10_3x3mm_P0.5mm; LCSC C108207
U8: TPS61088; IC_TPS61088RHLR; LCSC C87357
U9: Pico; RPi_Pico_SMD_TH

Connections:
3.5v: C25.1, C28.1, C64.2, D17.2 (A), L1.1, U8.9 (VIN); also elsewhere on the board
3v3_2: C12.1, R58.2, R93.2, R94.2, U7.1 (VDD), U9.36 (3V3)
5v: C66.1, R37.2, R48.1, R62.2, R73.2; also elsewhere on the board
9v_EN: Q19.1 (G), R109.2, R110.1, R152.1, U8.2 (EN)
+9v: C10.2, C11.1, C13.2, C14.1, C15.1, C16.2, C17.1, C18.2, C19.1, D7.2 (A2), D9.2 (A2), D11.2 (A2), D15.2 (A2), Q3.3 (S), Q6.3 (S), Q9.3 (S), Q12.3 (S), Q18.3 (D), R41.2, R52.2, R66.2, R77.2, R79.2, U6.4 (V+)
/Output/CS: U9.22 (GPIO17); also elsewhere on the board
/Output/MISO: U9.25 (GPIO19); also elsewhere on the board
/Output/MOSI: U9.21 (GPIO16); also elsewhere on the board
/Output/SCK: U9.24 (GPIO18); also elsewhere on the board
ADC0: Q2.2 (S), Q4.2 (S), Q5.2 (S), Q7.2 (S), R36.1, R157.1
ADC1: Q8.2 (S), Q10.2 (S), Q11.2 (S), Q13.2 (S), R61.1, R156.1
C1-GA: R38.2, R40.1, U9.9 (GPIO6)
C1-GB: R46.2, R47.1, U9.10 (GPIO7)
C2-GA: R49.2, R51.1, U9.11 (GPIO8)
C2-GB: R57.2, R59.1, U9.12 (GPIO9)
C3-GA: R63.2, R65.1, U9.14 (GPIO10)
C3-GB: R71.2, R72.1, U9.15 (GPIO11)
C4-GA: R74.2, R76.1, U9.16 (GPIO12)
C4-GB: R84.2, R85.1, U9.17 (GPIO13)
DAC-C1: R42.1, U7.6 (VOUTA)
DAC-C2: R53.1, U7.7 (VOUTB)
DAC-C3: R67.1, U7.8 (VOUTC)
DAC-C4: R80.1, U7.9 (VOUTD)
GND: C11.2, C12.2, C14.2, C15.2, C17.2, C19.2, C21.1, C22.2, C23.2, C24.2, C25.2, C27.1, C28.2, C29.2, C30.1, C64.1, C66.2, D13.1 (K), D14.1 (K), J13.2, Q19.2 (S), R36.2, R40.2, R44.1, R45.1, R47.2, R51.2, R55.1, R56.2, R59.2, R60.2, R61.2, R65.2, R69.1, R70.1, R72.2, R76.2, R82.1, R83.1, R85.2, R89.2, R92.2, R109.1, R152.2, U6.11 (V-), U7.10 (VSS), U8.13 (MODE), U8.20 (AGND), U8.21 (PGND), U9.3 (GND), U9.8 (GND), U9.13 (GND), U9.18 (GND), U9.23 (GND), U9.28 (GND), U9.38 (GND); also elsewhere on the board
I2C_SCL_PER: R94.1, U7.2 (SCL), U9.5 (GPIO3)
I2C_SDA_PER: R93.1, U7.3 (SDA), U9.4 (GPIO2)
LDAC: R60.1, U7.4 (~LDAC), U9.27 (GPIO21)
unnamed: C10.1, Q3.1 (G), R43.1
unnamed: C13.1, Q6.1 (G), R54.1
unnamed: C16.1, Q9.1 (G), R68.1
unnamed: C18.1, Q12.1 (G), R81.1
unnamed: C20.1, L1.2, R95.1, U8.4 (SW), U8.5 (SW), U8.6 (SW), U8.7 (SW)
unnamed: C20.2, U8.8 (BOOT)
unnamed: C21.2, C22.1, C23.1, C24.1, Q18.2 (S), R86.1, R105.2, TP1.1, U8.14 (VOUT), U8.15 (VOUT), U8.16 (VOUT)
unnamed: C27.2, R106.1
unnamed: C29.1, U8.1 (VCC)
unnamed: C30.2, U8.10 (SS)
unnamed: D7.1 (A1), D8.3 (K)
unnamed: D8.1 (A), Q4.3 (D), TR1.3
unnamed: D8.2 (A), Q2.3 (D), TR1.1
unnamed: D10.1 (A), Q7.3 (D), TR2.3
unnamed: D10.2 (A), Q5.3 (D), TR2.1
unnamed: D9.1 (A1), D10.3 (K)
unnamed: D11.1 (A1), D12.3 (K)
unnamed: D12.1 (A), Q10.3 (D), TR3.3
unnamed: D12.2 (A), Q8.3 (D), TR3.1
unnamed: D13.2 (A), R77.1
unnamed: D14.2 (A), R78.1
unnamed: D15.1 (A1), D16.3 (K)
unnamed: D16.1 (A), Q13.3 (D), TR4.3
unnamed: D16.2 (A), Q11.3 (D), TR4.1
unnamed: D17.1 (K), U9.39 (VSYS)
unnamed: J11.R, J11.S, TR1.4
unnamed: J11.T, TR1.6
unnamed: J12.R, J12.S, TR2.4
unnamed: J12.T, TR2.6
unnamed: J14.R, J14.S, TR3.4
unnamed: J14.T, TR3.6
unnamed: J15.R, J15.S, TR4.4
unnamed: J15.T, TR4.6
unnamed: Q2.1 (G), R38.1
unnamed: Q3.2 (D), TR1.2
unnamed: Q4.1 (G), R46.1
unnamed: Q5.1 (G), R49.1
unnamed: Q6.2 (D), TR2.2
unnamed: Q7.1 (G), R57.1
unnamed: Q8.1 (G), R63.1
unnamed: Q9.2 (D), TR3.2
unnamed: Q10.1 (G), R71.1
unnamed: Q11.1 (G), R74.1
unnamed: Q12.2 (D), TR4.2
unnamed: Q13.1 (G), R84.1
unnamed: Q18.1 (G), Q19.3 (D), R105.1
unnamed: R37.1, R39.2, R45.2, U6.2 (-)
unnamed: R39.1, R43.2, U6.1
unnamed: R41.1, R42.2, R44.2, U6.3 (+)
unnamed: R48.2, R50.1, R56.1, U6.6 (-)
unnamed: R50.2, R54.2, U6.7
unnamed: R52.1, R53.2, R55.2, U6.5 (+)
unnamed: R62.1, R64.2, R70.2, U6.9 (-)
unnamed: R64.1, R68.2, U6.8
unnamed: R66.1, R67.2, R69.2, U6.10 (+)
unnamed: R73.1, R75.2, R83.2, U6.13 (-)
unnamed: R75.1, R81.2, U6.14
unnamed: R79.1, R80.2, R82.2, U6.12 (+)
unnamed: R86.2, R87.2
unnamed: R87.1, R89.1, U8.17 (FB)
unnamed: R91.1, U8.19 (ILIM)
unnamed: R91.2, R92.1
unnamed: R95.2, U8.3 (FSW)
unnamed: R106.2, U8.18 (COMP)
unnamed: R110.2, U9.19 (GPIO14)
unnamed: R156.2, U9.32 (GPIO27_ADC1)
unnamed: R157.2, U9.31 (GPIO26_ADC0)
OK_LED: R78.2, U9.20 (GPIO15)
PWR_EN: U9.37 (3V3_EN); also elsewhere on the board
RDY: R58.1, U7.5 (RDY/~BSY), U9.26 (GPIO20)
SCL: U9.7 (GPIO5); also elsewhere on the board
SDA: U9.6 (GPIO4); also elsewhere on the board
SERIAL_RX: U9.2 (GPIO1)
SERIAL_TX: J13.1, U9.1 (GPIO0)

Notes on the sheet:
Serial header
9v supply
For TPS61088 with EN=LOW, VOUT=VIN. Ensure power gets shut off when 9v_EN low.
Op-amp power
Channel 1
386k & 56k => 9.57v output
ILIM=2.4A
Power & status indicators
DAC addr = 0x60
Channel 3
Channel 4
Channel 2
Around 0.75ma-ish

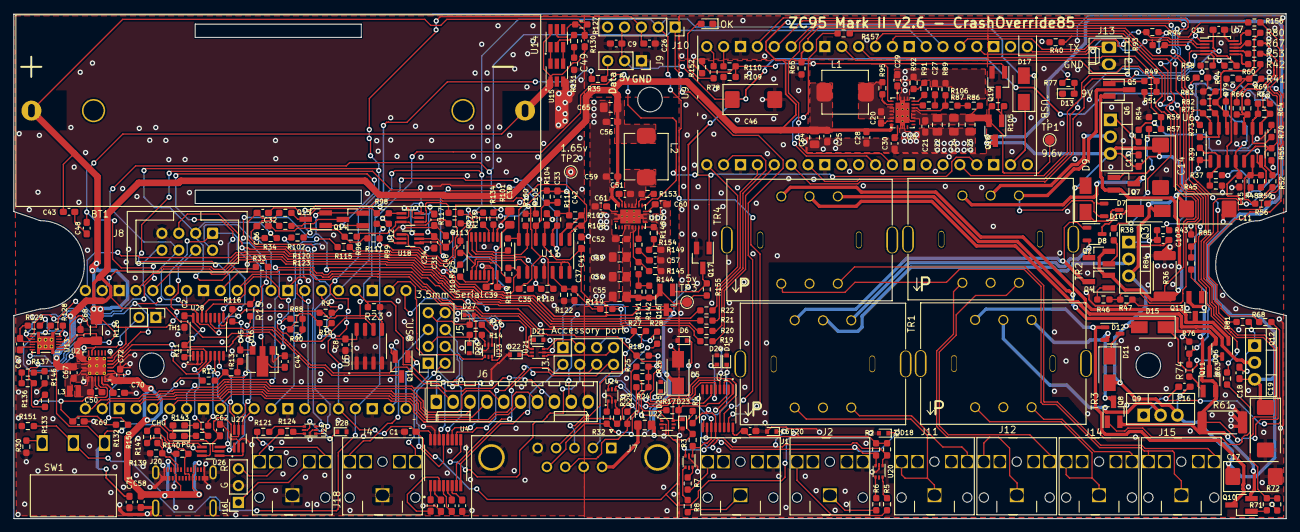
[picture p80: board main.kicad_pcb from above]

Board: 2 copper layers, 191.5 x 76.0 mm, 334 parts (1 on the bottom side), 263 nets.

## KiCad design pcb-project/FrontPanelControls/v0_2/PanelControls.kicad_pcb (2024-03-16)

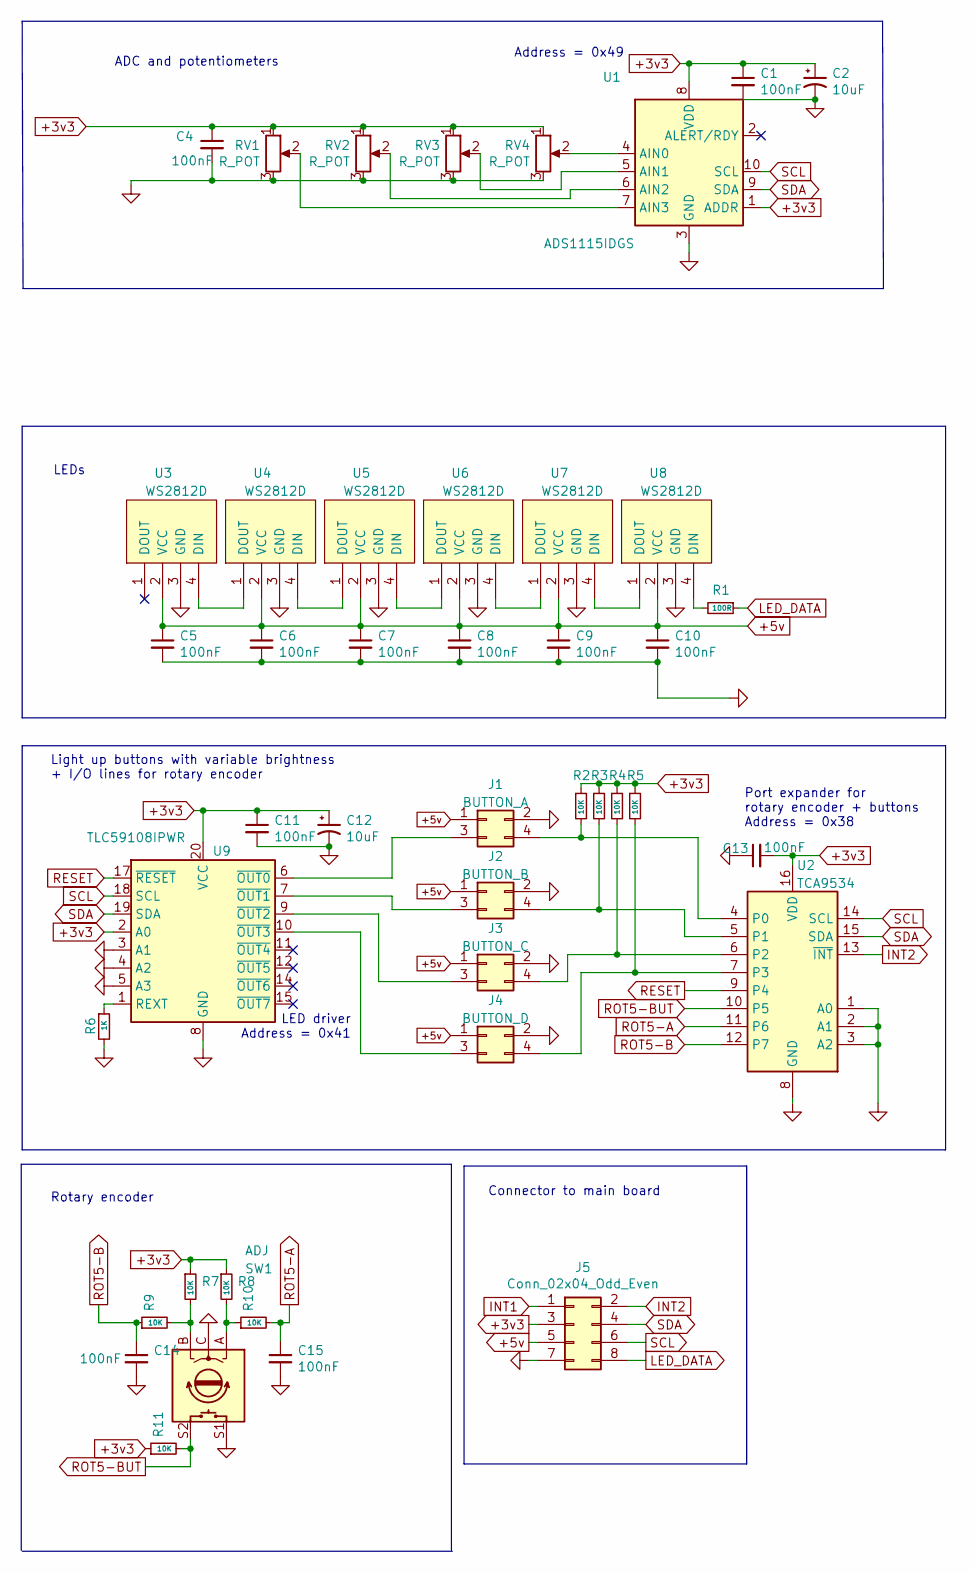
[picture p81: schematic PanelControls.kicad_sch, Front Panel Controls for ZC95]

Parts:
C1, C4, C5, C6, C7, C8, C9, C10, C11, C13, C14, C15: 100nF; C_0603_1608Metric_Pad1.08x0.95mm_HandSolder; LCSC C14663
C2, C12: 10uF; C_0603_1608Metric_Pad1.08x0.95mm_HandSolder; LCSC C19702
J1: BUTTON_A; ButtonConnector
J2: BUTTON_B; ButtonConnector
J3: BUTTON_C; ButtonConnector
J4: BUTTON_D; ButtonConnector
J5: Conn_02x04_Odd_Even; IDC-Header_2x04_P2.54mm_Vertical
R1: 100R; R_0603_1608Metric_Pad0.98x0.95mm_HandSolder; LCSC C22775
R2, R3, R4, R5, R7, R8, R9, R10, R11: 10K; R_0603_1608Metric_Pad0.98x0.95mm_HandSolder; LCSC C25804
R6: 1K; R_0603_1608Metric_Pad0.98x0.95mm_HandSolder; LCSC C21190
RV1, RV2, RV3, RV4: R_POT; ALPSALPINE RK09L1140A2U
SW1: ADJ; BOURNS PEC11L-4125F-S0020
U1: ADS1115IDGS; TSSOP-10_3x3mm_P0.5mm
U2: TCA9534; TSSOP-16_4.4x5mm_P0.65mm; LCSC C206010
U3, U4, U5, U6, U7, U8: WS2812D; WS2812D-F5
U9: TLC59108IPWR; TSSOP-20_4.4x6.5mm_P0.65mm; LCSC C130031

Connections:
+3v3: C1.1, C2.1, C4.1, C11.1, C12.1, C13.2, J5.3, R2.1, R3.1, R4.1, R5.1, R7.1, R8.1, R11.1, RV1.1, RV2.1, RV3.1, RV4.1, U1.1 (ADDR), U1.8 (VDD), U2.16 (VDD), U9.2 (A0), U9.20 (VCC)
+5v: C5.1, C6.1, C7.1, C8.1, C9.1, C10.1, J1.1, J2.1, J3.1, J4.1, J5.5, U3.2 (VCC), U4.2 (VCC), U5.2 (VCC), U6.2 (VCC), U7.2 (VCC), U8.2 (VCC)
GND: C1.2, C2.2, C4.2, C5.2, C6.2, C7.2, C8.2, C9.2, C10.2, C11.2, C12.2, C13.1, C14.2, C15.2, J1.2, J2.2, J3.2, J4.2, J5.7, R6.2, RV1.3, RV2.3, RV3.3, RV4.3, SW1.C, SW1.S1, U1.3 (GND), U2.1 (A0), U2.2 (A1), U2.3 (A2), U2.8 (GND), U3.3 (GND), U4.3 (GND), U5.3 (GND), U6.3 (GND), U7.3 (GND), U8.3 (GND), U9.3 (A1), U9.4 (A2), U9.5 (A3), U9.8 (GND), U9.13 (GND), U9.16 (GND)
INT1: J5.1
INT2: J5.2, U2.13 (~INT)
LED_DATA: J5.8, R1.1
unnamed: J1.3, U9.6 (~OUT0)
unnamed: J1.4, R2.2, U2.4 (P0)
unnamed: J2.3, U9.7 (~OUT1)
unnamed: J2.4, R3.2, U2.5 (P1)
unnamed: J3.3, U9.9 (~OUT2)
unnamed: J3.4, R4.2, U2.6 (P2)
unnamed: J4.3, U9.10 (~OUT3)
unnamed: J4.4, R5.2, U2.7 (P3)
unnamed: R1.2, U8.4 (DIN)
unnamed: R6.1, U9.1 (REXT)
unnamed: R7.2, R9.2, SW1.B
unnamed: R8.2, R10.1, SW1.A
unnamed: RV1.2, U1.7 (AIN3)
unnamed: RV2.2, U1.6 (AIN2)
unnamed: RV3.2, U1.5 (AIN1)
unnamed: RV4.2, U1.4 (AIN0)
unnamed: U3.4 (DIN), U4.1 (DOUT)
unnamed: U4.4 (DIN), U5.1 (DOUT)
unnamed: U5.4 (DIN), U6.1 (DOUT)
unnamed: U6.4 (DIN), U7.1 (DOUT)
unnamed: U7.4 (DIN), U8.1 (DOUT)
RESET: U2.9 (P4), U9.17 (~RESET)
ROT5-A: C15.1, R10.2, U2.11 (P6)
ROT5-B: C14.1, R9.1, U2.12 (P7)
ROT5-BUT: R11.2, SW1.S2, U2.10 (P5)
SCL: J5.6, U1.10 (SCL), U2.14 (SCL), U9.18 (SCL)
SDA: J5.4, U1.9 (SDA), U2.15 (SDA), U9.19 (SDA)

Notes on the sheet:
Rotary encoder
Light up buttons with variable brightness + I/O lines for rotary encoder
Port expander for rotary encoder + buttons Address = 0x38
Connector to main board
ADC and potentiometers
LEDs
Address = 0x49
LED driver Address = 0x41

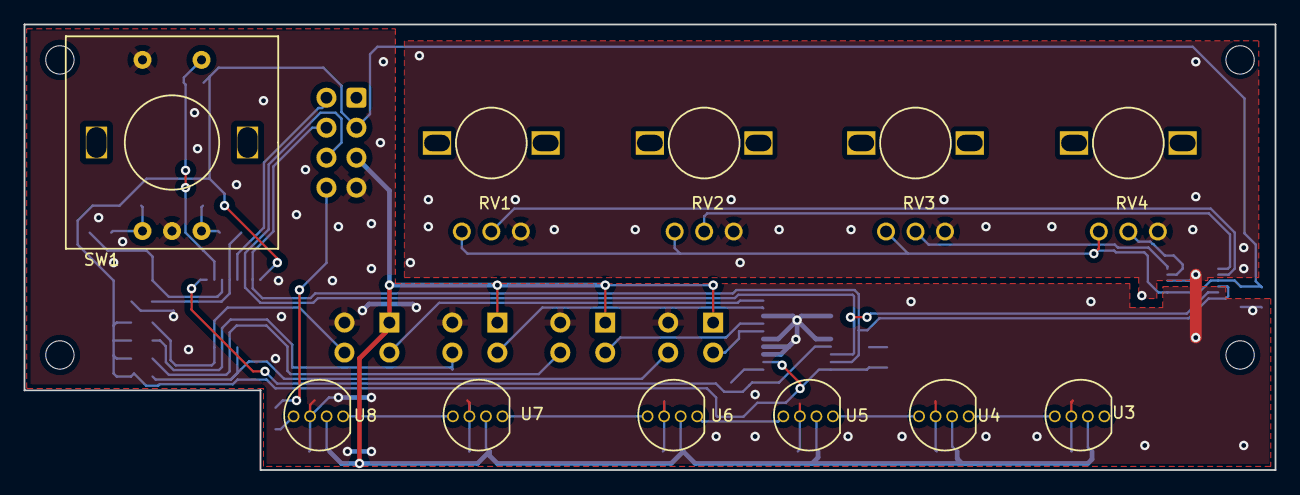
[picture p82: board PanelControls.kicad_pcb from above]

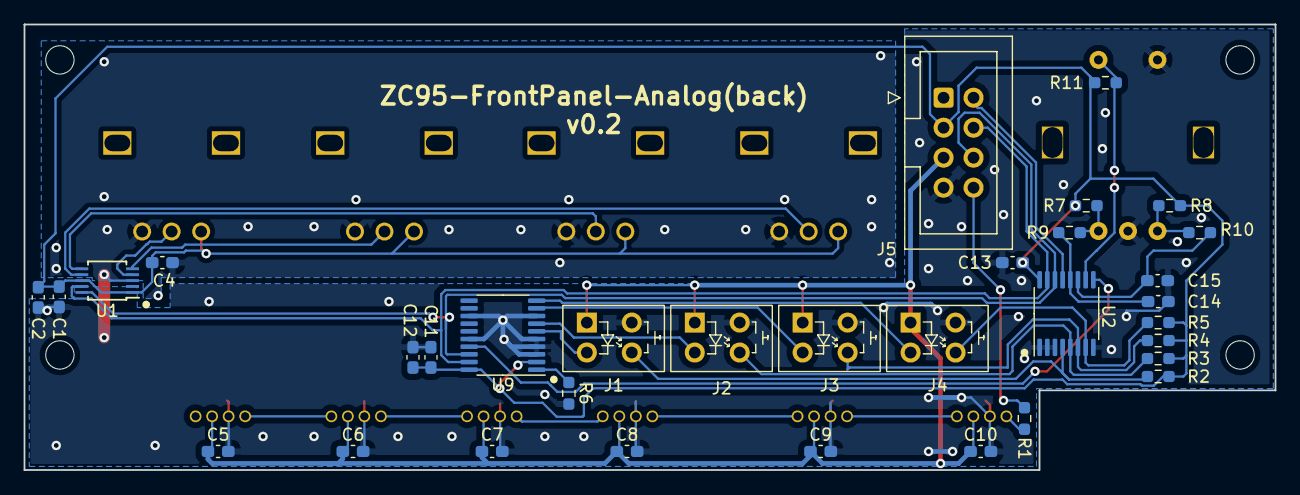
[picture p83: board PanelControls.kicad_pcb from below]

Board: 2 copper layers, 106.0 x 37.8 mm, 44 parts (33 on the bottom side), 32 nets.

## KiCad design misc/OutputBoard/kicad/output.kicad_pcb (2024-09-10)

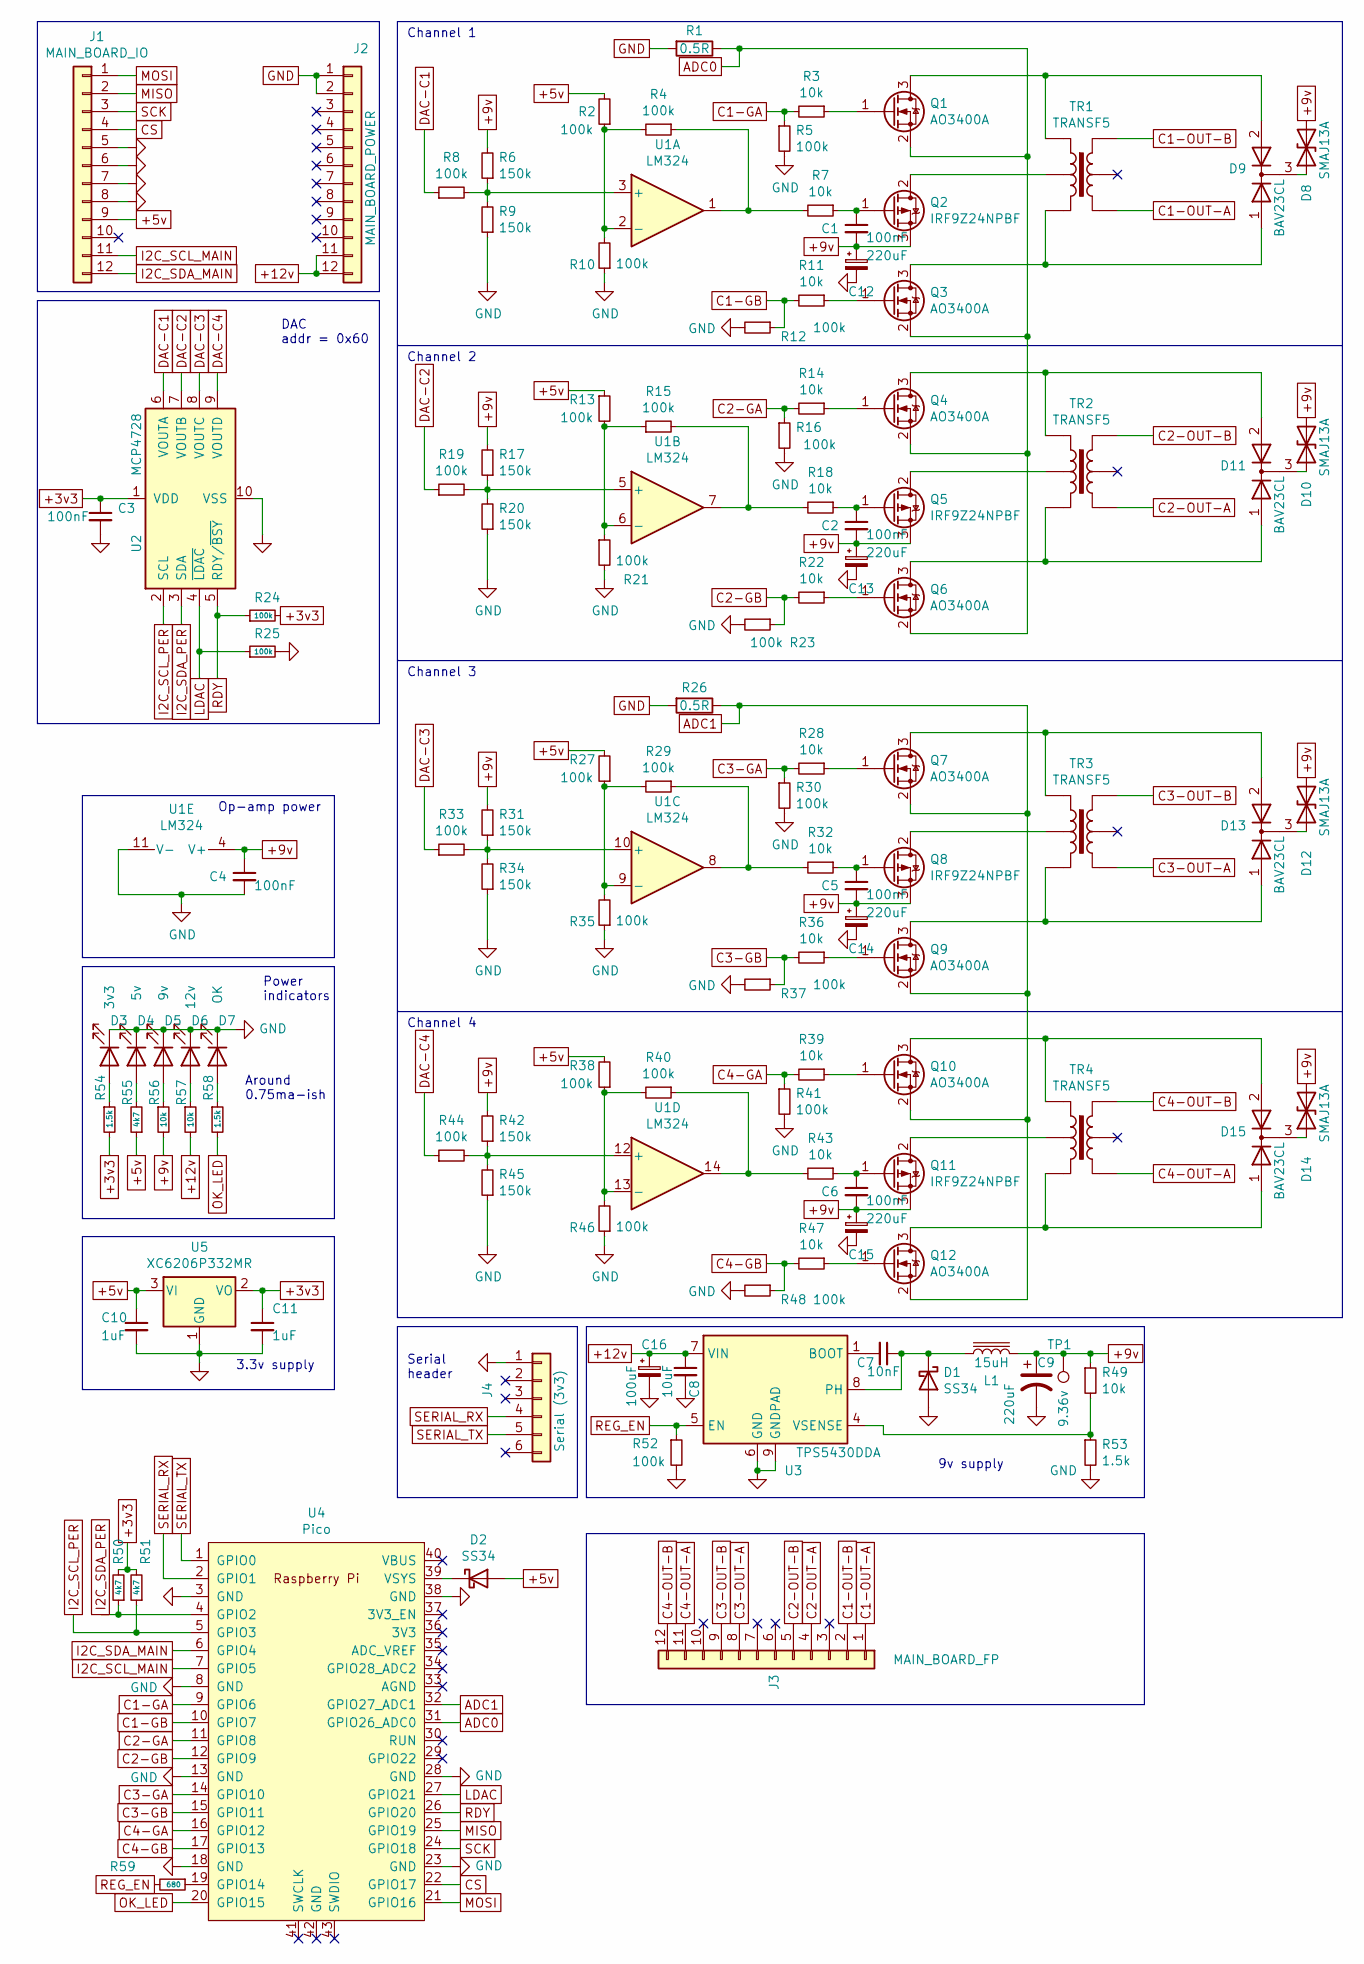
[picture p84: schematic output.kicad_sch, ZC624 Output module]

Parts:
C1, C2, C3, C4, C5, C6: 100nF; C_0603_1608Metric_Pad1.08x0.95mm_HandSolder; LCSC C49678
C7: 10nF; C_0603_1608Metric_Pad1.08x0.95mm_HandSolder; LCSC C57112
C8: 10uF; C_0603_1608Metric_Pad1.08x0.95mm_HandSolder; LCSC C15850
C9: 220uF; CP_Radial_D8.0mm_P3.50mm; LCSC C440836
C10, C11: 1uF; C_0603_1608Metric_Pad1.08x0.95mm_HandSolder; LCSC C28323
C12, C13, C14, C15: 220uF; CP_EIA-7343-43_Kemet-X_Pad2.25x2.55mm_HandSolder; LCSC C122311
C16: 100uF; CP_Radial_D5.0mm_P2.00mm; LCSC C108360
D1, D2: SS34; D_SMA; LCSC C8678
D3: 3v3; LED_0603_1608Metric_Pad1.05x0.95mm_HandSolder; LCSC C2986059
D4: 5v; LED_0603_1608Metric_Pad1.05x0.95mm_HandSolder; LCSC C2986059
D5: 9v; LED_0603_1608Metric_Pad1.05x0.95mm_HandSolder; LCSC C2986059
D6: 12v; LED_0603_1608Metric_Pad1.05x0.95mm_HandSolder; LCSC C2986059
D7: OK; LED_0603_1608Metric_Pad1.05x0.95mm_HandSolder; LCSC C2986059
D8, D10, D12, D14: SMAJ13A; D_SMA; LCSC C110519
D9, D11, D13, D15: BAV23CL; SOT-23-3; LCSC C232533
J1: MAIN_BOARD_IO; PinHeader_1x12_P2.54mm_Vertical
J2: MAIN_BOARD_POWER; PinHeader_1x12_P2.54mm_Vertical
J3: MAIN_BOARD_FP; PinHeader_1x12_P2.54mm_Vertical
J4: Serial (3v3); PinHeader_1x06_P2.54mm_Vertical
L1: 15uH; L_7.3x7.3_H3.5; LCSC C177243
Q1, Q3, Q4, Q6, Q7, Q9, Q10, Q12: AO3400A; SOT-23_Handsoldering; LCSC C20917
Q2, Q5, Q8, Q11: IRF9Z24NPBF; TO-220-3_Vertical; LCSC C2576
R1, R26: 0.5R; R_Axial_DIN0309_L9.0mm_D3.2mm_P5.08mm_Vertical; LCSC C479327
R2, R4, R5, R8, R10, R12, R13, R15, R16, R19, R21, R23, R24, R25, R27, R29, R30, R33, R35, R37, R38, R40, R41, R44, R46, R48, R52: 100k; R_0603_1608Metric_Pad0.98x0.95mm_HandSolder; LCSC C149504
R3, R7, R11, R14, R18, R22, R28, R32, R36, R39, R43, R47, R49, R56, R57: 10k; R_0603_1608Metric_Pad0.98x0.95mm_HandSolder; LCSC C17414
R6, R9, R17, R20, R31, R34, R42, R45: 150k; R_0603_1608Metric_Pad0.98x0.95mm_HandSolder; LCSC C17470
R50, R51, R55: 4k7; R_0603_1608Metric_Pad0.98x0.95mm_HandSolder; LCSC C23162
R53, R54, R58: 1.5k; R_0603_1608Metric_Pad0.98x0.95mm_HandSolder; LCSC C4310
R59: 680; R_0603_1608Metric_Pad0.98x0.95mm_HandSolder; LCSC C17798
TP1: 9.36v; TestPoint_Pad_2.5x2.5mm
TR1, TR2, TR3, TR4: TRANSF5; 42TL+U
U1: LM324; SOIC-14_3.9x8.7mm_P1.27mm; LCSC C71035
U2: MCP4728; MSOP-10_3x3mm_P0.5mm; LCSC C108207
U3: TPS5430DDA; TI_SO-PowerPAD-8_ThermalVias; LCSC C9864
U4: Pico; RPi_Pico_SMD_TH
U5: XC6206P332MR; SOT-23; LCSC C5446

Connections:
+3v3: C3.1, C11.1, R24.2, R50.2, R51.2, R54.2, U2.1 (VDD), U5.2 (VO)
+5v: C10.1, D2.2 (A), J1.9, R2.2, R13.1, R27.2, R38.2, R55.1, U5.3 (VI)
+9v: C1.2, C2.2, C4.1, C5.2, C6.2, C9.1, C12.1, C13.1, C14.1, C15.1, D8.2 (A2), D10.2 (A2), D12.2 (A2), D14.2 (A2), L1.2, Q2.3 (S), Q5.3 (S), Q8.3 (S), Q11.3 (S), R6.2, R17.2, R31.2, R42.2, R49.1, R56.2, TP1.1, U1.4 (V+)
+12v: C8.1, C16.1, J2.11, J2.12, R57.2, U3.7 (VIN)
ADC0: Q1.2 (S), Q3.2 (S), Q4.2 (S), Q6.2 (S), R1.1, U4.31 (GPIO26_ADC0)
ADC1: Q7.2 (S), Q9.2 (S), Q10.2 (S), Q12.2 (S), R26.1, U4.32 (GPIO27_ADC1)
C1-GA: R3.2, R5.1, U4.9 (GPIO6)
C1-GB: R11.2, R12.1, U4.10 (GPIO7)
C1-OUT-A: J3.1, TR1.4
C1-OUT-B: J3.2, TR1.6
C2-GA: R14.2, R16.1, U4.11 (GPIO8)
C2-GB: R22.2, R23.1, U4.12 (GPIO9)
C2-OUT-A: J3.4, TR2.4
C2-OUT-B: J3.5, TR2.6
C3-GA: R28.2, R30.1, U4.14 (GPIO10)
C3-GB: R36.2, R37.1, U4.15 (GPIO11)
C3-OUT-A: J3.8, TR3.4
C3-OUT-B: J3.9, TR3.6
C4-GA: R39.2, R41.1, U4.16 (GPIO12)
C4-GB: R47.2, R48.1, U4.17 (GPIO13)
C4-OUT-A: J3.11, TR4.4
C4-OUT-B: J3.12, TR4.6
CS: J1.4, U4.22 (GPIO17)
DAC-C1: R8.1, U2.6 (VOUTA)
DAC-C2: R19.1, U2.7 (VOUTB)
DAC-C3: R33.1, U2.8 (VOUTC)
DAC-C4: R44.1, U2.9 (VOUTD)
GND: C3.2, C4.2, C8.2, C9.2, C10.2, C11.2, C12.2, C13.2, C14.2, C15.2, C16.2, D1.2 (A), D3.1 (K), D4.1 (K), D5.1 (K), D6.1 (K), D7.1 (K), J1.5, J1.6, J1.7, J1.8, J2.1, J2.2, J4.1, R1.2, R5.2, R9.1, R10.1, R12.2, R16.2, R20.1, R21.2, R23.2, R25.2, R26.2, R30.2, R34.1, R35.1, R37.2, R41.2, R45.1, R46.1, R48.2, R52.2, R53.2, U1.11 (V-), U2.10 (VSS), U3.6 (GND), U3.9 (GNDPAD), U4.3 (GND), U4.8 (GND), U4.13 (GND), U4.18 (GND), U4.23 (GND), U4.28 (GND), U4.38 (GND), U5.1 (GND)
I2C_SCL_MAIN: J1.11, U4.7 (GPIO5)
I2C_SCL_PER: R51.1, U2.2 (SCL), U4.5 (GPIO3)
I2C_SDA_MAIN: J1.12, U4.6 (GPIO4)
I2C_SDA_PER: R50.1, U2.3 (SDA), U4.4 (GPIO2)
LDAC: R25.1, U2.4 (~LDAC), U4.27 (GPIO21)
MISO: J1.2, U4.25 (GPIO19)
MOSI: J1.1, U4.21 (GPIO16)
unnamed: C1.1, Q2.1 (G), R7.1
unnamed: C2.1, Q5.1 (G), R18.1
unnamed: C5.1, Q8.1 (G), R32.1
unnamed: C6.1, Q11.1 (G), R43.1
unnamed: C7.1, D1.1 (K), L1.1, U3.8 (PH)
unnamed: C7.2, U3.1 (BOOT)
unnamed: D2.1 (K), U4.39 (VSYS)
unnamed: D3.2 (A), R54.1
unnamed: D4.2 (A), R55.2
unnamed: D5.2 (A), R56.1
unnamed: D6.2 (A), R57.1
unnamed: D7.2 (A), R58.1
unnamed: D8.1 (A1), D9.3 (K)
unnamed: D9.1 (A), Q3.3 (D), TR1.3
unnamed: D9.2 (A), Q1.3 (D), TR1.1
unnamed: D10.1 (A1), D11.3 (K)
unnamed: D11.1 (A), Q6.3 (D), TR2.3
unnamed: D11.2 (A), Q4.3 (D), TR2.1
unnamed: D12.1 (A1), D13.3 (K)
unnamed: D13.1 (A), Q9.3 (D), TR3.3
unnamed: D13.2 (A), Q7.3 (D), TR3.1
unnamed: D14.1 (A1), D15.3 (K)
unnamed: D15.1 (A), Q12.3 (D), TR4.3
unnamed: D15.2 (A), Q10.3 (D), TR4.1
unnamed: Q1.1 (G), R3.1
unnamed: Q2.2 (D), TR1.2
unnamed: Q3.1 (G), R11.1
unnamed: Q4.1 (G), R14.1
unnamed: Q5.2 (D), TR2.2
unnamed: Q6.1 (G), R22.1
unnamed: Q7.1 (G), R28.1
unnamed: Q8.2 (D), TR3.2
unnamed: Q9.1 (G), R36.1
unnamed: Q10.1 (G), R39.1
unnamed: Q11.2 (D), TR4.2
unnamed: Q12.1 (G), R47.1
unnamed: R4.1, R7.2, U1.1
unnamed: R6.1, R8.2, R9.2, U1.3 (+)
unnamed: R2.1, R4.2, R10.2, U1.2 (-)
unnamed: R13.2, R15.1, R21.1, U1.6 (-)
unnamed: R15.2, R18.2, U1.7
unnamed: R17.1, R19.2, R20.2, U1.5 (+)
unnamed: R27.1, R29.2, R35.2, U1.9 (-)
unnamed: R29.1, R32.2, U1.8
unnamed: R31.1, R33.2, R34.2, U1.10 (+)
unnamed: R38.1, R40.2, R46.2, U1.13 (-)
unnamed: R40.1, R43.2, U1.14
unnamed: R42.1, R44.2, R45.2, U1.12 (+)
unnamed: R49.2, R53.1, U3.4 (VSENSE)
unnamed: R59.1, U4.19 (GPIO14)
OK_LED: R58.2, U4.20 (GPIO15)
RDY: R24.1, U2.5 (RDY/~BSY), U4.26 (GPIO20)
REG_EN: R52.1, R59.2, U3.5 (EN)
SCK: J1.3, U4.24 (GPIO18)
SERIAL_RX: J4.4, U4.2 (GPIO1)
SERIAL_TX: J4.5, U4.1 (GPIO0)

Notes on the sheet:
Serial header
Channel 1
Channel 2
DAC addr = 0x60
Power indicators
9v supply
Channel 4
Op-amp power
Channel 3
3.3v supply
Around 0.75ma-ish

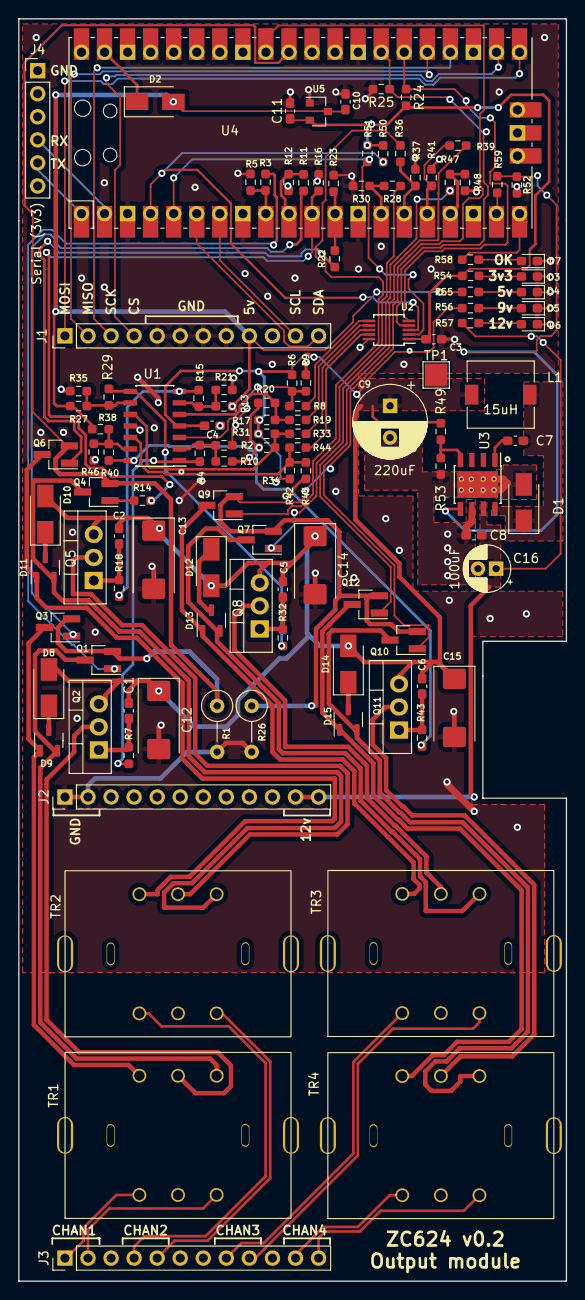
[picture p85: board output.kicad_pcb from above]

Board: 2 copper layers, 60.3 x 139.1 mm, 117 parts (0 on the bottom side), 91 nets.

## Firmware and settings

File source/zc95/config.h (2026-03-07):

#define PULSE_QUEUE_LENGTH 50  // queue size for pules sent from core0 to core1. Only used for audio pattern
                               // (maybe serial input in the future), where processing happens on core0

#define PATTERN_TEXT_OUTPUT_QUEUE_LENGTH 4 // Max number of queued text/debug messages from Core1 (so far just lua) to Core0

#define ZC624_ADDR                  0x10
#define MK1_EXT_INPUT_PORT_EXP_ADDR 0x21 // MKI: 3x I/O lines on front panel accessory port (p0-02), 4x for trigger inputs (p4-p7), 1x N/C (p3)
#define MK1_CONTROLS_PORT_EXP_ADDR  0x22 // MKI: 4x front panel buttons (p0-p03), 3x I/O lines on expansion header J17 (p4-p6), 1x LCD backlight (p7)
#define FP_0_1_PORT_EXP_ADDR        0x26 // Port expander (U2) on v0.1 of the front panel
#define AUDIO_DIGIPOT_ADDR          0x2C // Digital potentiometer used to set gain (MK1: on audio board, MKII: on main board)
#define FP_0_2_PORT_EXP_ADDR        0x38 // Port expander used on >= v0.2 of the front panel
#define FP_0_2_BUTTON_LED_DRV_ADDR  0x41 // LED driver for the LED's in the buttons of the v0.2 front panel
#define FP_0_1_ADC_ADDR             0x48 // ADC on v0.1 of front panel, used for power control dials
#define FP_0_2_ADC_ADDR             0x49 // ADC on v0.2 of front panel, used for power control dials
#define EEPROM_ADDR                 0x50 // EEPROM
#define BQ27441_I2C_ADDRESS         0x55 // MKII: Fuel/gas gauge
#define BQ25601_CHARGE_CONTROLLER   0x6B // MKII, for main board PCB version >= 2.2 only: BQ25601 charge controller

#define MK2_PORT_EXP_ADDR           0x21 // MKII: port expander used for charger and audio control (replaces MK1_CONTROLS_PORT_EXP_ADDR)
#define MK2_EXT_INPUT_PORT_EXP_ADDR 0x22 // MKII: port expander used for 3x acc io lines and trigger inputs (replaces MK1_EXT_INPUT_PORT_EXP_ADDR)

#define I2C_PORT i2c0  // main i2c bus for port expanders + eeprom

// Set expected version for zc624 output module
#define ZC624_REQUIRED_MAJOR_VERION 2
#define ZC624_MIN_MINOR_VERION      1

// Versions for the GetVersion/VersionDetails message, but that's not used by anything yet
#define WEBSOCKET_API_VERION_MAJOR  1   // Increment on breaking change
#define WEBSOCKET_API_VERION_MINOR  0   // Increment non-breaking change

// The maximum length a web socket message can be in bytes
#define MAX_WS_MESSAGE_SIZE 300

// How many Lua instructions can be run on each Lua call. Protects against infinite loops locking up box.
#define LUA_MAX_INSTRUCTIONS 10000

// Other pins
#define PIN_LED           10 // ws2812 LED chain
#define PIN_CONTROLS_INT   7 // front panel controls port expander interrupt pin
#define PIN_EXT_INPUT_INT 21 // external inputs port expander interrupt pin
#define PIN_433TX          3 // 433Mhz transmitter pin
#define PIN_SD_CS         22 // Chip select for SD card reader on LCD module. Unused.

#define PIN_FP_INT1       11 // front panel interrupt 1 (U1) - 4x channel rot encoders
#define PIN_FP_INT2        6 // front panel interrupt 2 (U2) - 5x rot encoder buttons & 1x adjust rot encoder (+ 1x unused line)

#define PIN_MK1_DISP_RST   2 // Display reset pin on MK1
#define PIN_MK2_DISP_BL    2 // Backlight pin on MK2


// Output board SPI
#define ZC624_SPI_PORT            spi1
#define PIN_OUTPUT_BOARD_SPI_RX   12
#define PIN_OUTPUT_BOARD_SPI_SCK  14
#define PIN_OUTPUT_BOARD_SPI_TX   15
#define PIN_OUTPUT_BOARD_SPI_CSN  13

// For routines that don't care about pulse width and/or frequency, what to use
// TODO: maybe move these two to config options and save in EEPROM
#define DEFAULT_FREQ_HZ 150
#define DEFAULT_PULSE_WIDTH 150

#define TRIGGER_INPUT_DEBOUNCE_US 10000 // 10ms
#define RAMP_UP_TIME_MAXIMUM_SECS 30    // the maximum ramp up time that can be configured in seconds (0-255)

// For the time being, allowing more than one web socket connection is likely to cause all sorts of issues, 
// e.g. fighting for control over running routine, possibility to change a lua script whilst it's running, etc.
#define MAX_WEBSOCKET_CONNECTIONS 1 

// Note that just changing these two values would likely break everything
#define MAX_POWER_LEVEL 1000
#define MAX_CHANNELS 4

// SPI Defines for display
#define SPI_PORT spi0
#define PIN_MISO 16
#define PIN_CS   17
#define PIN_SCK  18
#define PIN_MOSI 19

// I2C defines
#define I2C_SDA 4
#define I2C_SCL 5

#define PIN_AUX_UART_TX 0
#define PIN_AUX_UART_RX 1
#define AUX_PORT_UART uart0

#define PIN_ACC_UART_TX 8
#define PIN_ACC_UART_RX 9
#define ACC_PORT_UART uart1

#define SERIAL_TX_QUEUE_SIZE 2000 // only used when in remote access/serial mode

#define LUA_UPLOAD_BUFFER_SIZE  4096 // Will probably break if not a multiple of 4096, likely also depends on the script slot sizes in flash (see LuaScripts/LuaScripts.S)

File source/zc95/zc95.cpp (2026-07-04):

/*
 * ZC95
 * Copyright (C) 2025  CrashOverride85
 * 
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
 * You should have received a copy of the GNU General Public License
 * along with this program.  If not, see <http://www.gnu.org/licenses/>
 */

#include <stdio.h>
#include <vector>
#include <string.h>
#include <inttypes.h>

#include "globals.h"
#include "gDebugCounters.h"
#include "config.h"
#include "git_version.h"

#include "pico/stdlib.h"
#include "hardware/spi.h"
#include "hardware/i2c.h"
#include "hardware/dma.h"
#include "hardware/pio.h"
#include "hardware/regs/rosc.h"
#include "hardware/regs/addressmap.h"
#include "hardware/adc.h"
#include "hardware/structs/xip_ctrl.h"


#include "CLedControl.h"
#include "Hal/IHal.h"
#include "Hal/HalMk1.h"
#include "Hal/HalMk2.h"
#include "Hal/HalDummy.h"

#include "CEeprom.h"
#include "CSavedSettings.h"
#include "CTimingTest.h"
#include "HwCheck/CHwCheck.h"
#include "HwCheck/CDetermineHardwareVersion.h"
#include "CAnalogueCapture.h"
#include "CDebugOutput.h"
#include "CRadio.h"
#include "Bluetooth/CBluetooth.h"

#include "AudioInput/CMCP4651.h"
#include "AudioInput/CAudio.h"

#include "display/CDisplay.h"
#include "display/CMainMenu.h"
#include "display/config/remote_access/CMenuApMode.h"

#include "core1/Core1.h"
#include "core1/Core1Messages.h"
#include "core1/output/CChannelConfig.h"
#include "core1/routines/CRoutines.h"
#include "core1/CRoutineOutput.h"
#include "core1/CRoutineOutputCore1.h"

#include "PowerManagement/CPowerManagementMk1.h"
#include "PowerManagement/CPowerManagementMk2.h"

#include "RemoteAccess/CWifi.h"
#include "RemoteAccess/CSerialConnection.h"


#include "ECButtons.h"
#include "FlashHelper.h"

IHal* _hal = NULL;
CEeprom eeprom = CEeprom(I2C_PORT, EEPROM_ADDR);
CAnalogueCapture _analogueCapture;
CMCP4651 audio_gain;
CAudio* _audio = NULL;
CWifi *wifi = NULL;
CRadio *radio = NULL;
extern CSerialConnection *g_SerialConnection;

void check_button(CMenu *current_menu, Button button)
{
    bool new_state = false;
    if (_hal->front_panel()->has_button_state_changed(button, &new_state))
    {
        if (new_state)
            current_menu->button_pressed(button);
        else
            current_menu->button_released(button);
    }
}

void process_front_panel_input(CMenu *current_menu)
{
    check_button(current_menu, Button::A);
    check_button(current_menu, Button::B);
    check_button(current_menu, Button::C);
    check_button(current_menu, Button::D);
    check_button(current_menu, Button::ROT);
}

void update_power_levels_from_front_panel(CRoutineOutput *routine_output)
{
    for (int chan=0; chan < MAX_CHANNELS; chan++)
    {
        uint16_t fp_power = _hal->front_panel()->get_channel_power_level(chan);
        routine_output->set_front_panel_power(chan, fp_power);   
    }
}

/* Stolen from https://www.raspberrypi.org/forums/viewtopic.php?t=302960
 * "Random number generator - an example" by bgolab Feb 2021 */
void seed_random_from_rosc()
{
  uint32_t random = 0x811c9dc5;
  uint8_t next_byte = 0;
  volatile uint32_t *rnd_reg = (uint32_t *)(ROSC_BASE + ROSC_RANDOMBIT_OFFSET);

  for (int i = 0; i < 16; i++) {
    for (int k = 0; k < 8; k++) {
      next_byte = (next_byte << 1) | (*rnd_reg & 1);
    }

    random ^= next_byte;
    random *= 0x01000193;
  }

  srand(random);
} 

void set_leds_to_purple(CLedControl* led)
{
    led->set_all_led_colour(LedColour::Purple);
    led->loop(true);
    sleep_ms(1);
    led->loop(true);
}

void set_normal_bootloader_mode(CSavedSettings* settings)
{
    CSavedSettings::bootloader_mode_t current_mode = settings->get_bootloader_mode();
    printf("Current bootloader mode = %d\n", (uint8_t)current_mode);
    if (current_mode != CSavedSettings::bootloader_mode_t::NORMAL_BOOT)
    {
        printf("Updating bootloader mode to NORMAL\n");
        settings->set_bootloader_mode(CSavedSettings::bootloader_mode_t::NORMAL_BOOT);
        settings->save();
    }
}

int main()
{
    // Debugging with picoprobe causes cyw43_arch_init() to hang without this. JLink doesn't need it though ¯\_(ツ)_/¯
    timer_hw->dbgpause = 0; 

#ifdef PICO_RP2350
    // When uploading then debugging with JLINK (tested with 8.42) it leaves the XIP cache disabled, which absolutely kills performance.
    // See: https://forum.segger.com/index.php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
    uint32_t xip_ctl = xip_ctrl_hw->ctrl;
    if (xip_ctl != 131)
    {
        printf("XIP ctrl register does not match expected power on default of 0x%X, resetting (was 0x%X)\n", 131, xip_ctrl_hw->ctrl);
        xip_ctrl_hw->ctrl = 131;
    }
#endif

    CSavedSettings* settings = NULL;
    CLedControl led = CLedControl(PIN_LED, &settings);
    CRoutineOutput* routine_output  = NULL;
    set_leds_to_purple(&led);

    // I2C Initialisation
    i2c_init(i2c_default, 100 * 1000);
    gpio_set_function(I2C_SDA, GPIO_FUNC_I2C);
    gpio_set_function(I2C_SCL, GPIO_FUNC_I2C);
    gpio_pull_up(I2C_SDA);
    gpio_pull_up(I2C_SCL);
    mutex_init(&gI2cMutex);

    // Serial going to 3.5mm socket
    gpio_set_function(PIN_AUX_UART_TX, GPIO_FUNC_UART);
    gpio_set_function(PIN_AUX_UART_RX, GPIO_FUNC_UART);
    
    // Serial on acc port
    gpio_set_function(PIN_ACC_UART_TX, GPIO_FUNC_UART);
    gpio_set_function(PIN_ACC_UART_RX, GPIO_FUNC_UART);

    // For now, until settings loaded from eeprom, send debugging info to accessory port
    CDebugOutput::set_debug_destination(CDebugOutput::debug_dest_t::ACC);
    printf("\n\nZC95 Startup, firmware version: %s\n", firmware_info.firmware_version);

    sleep_ms(100); // wait for eeprom to be ready
    settings = new CSavedSettings(&eeprom);
    g_SavedSettings = settings;
    
    // Now settings have (hopefully!) been loaded, set debug output as per stored config
    CDebugOutput::set_debug_destination_from_settings(settings);   
    
    zc95_version_t hardware_version = CDetermineHardwareVersion::get_hardware_version();

    adc_init();
    messages_init();
    debug_counters_init();

    if (hardware_version == zc95_version_t::MKII)
    {
        printf("Hardware version: MKII\n");
        _hal = new HalMk2(&led, &routine_output, &_analogueCapture, &settings);
    }
    else if (hardware_version == zc95_version_t::MKI)
    {
        printf("Hardware version: MKI\n");
        _hal = new HalMk1(&led, &routine_output, &_analogueCapture, &settings);
    }
    else
    {
        printf("Hardware version: Unknown!\n");
        _hal = new HalDummy();
    }
    _hal->set_backlight(false);

    CHwCheck hw_check(_hal, &led);
    hw_check.check_part1(); // If a fault is found, this never returns

    _audio = new CAudio(&_analogueCapture, &audio_gain, _hal);
    _audio->set_audio_digipot_found(hw_check.audio_digipot_found());

    // Make sure there is some semi-random-ish data available
    seed_random_from_rosc();

    // Configure AUX port for serial or audio use
    _hal->audio_input_enable(settings->get_aux_port_use() == CSavedSettings::setting_aux_port_use::AUDIO);

    // Front panel LEDs - update brightness now saved settings are available
    led.set_all_led_colour(LedColour::Purple);
    led.loop(true);
    sleep_ms(1);
    led.loop(true);

    radio = new CRadio(&_analogueCapture);
    CBluetooth bluetooth = CBluetooth(radio);

    // Configure SPI display
    CDisplay display = CDisplay(_hal->front_panel(), &bluetooth, _hal->power_management());
    display.init(); // This takes some time - not far off a second
    hw_check.set_display(&display);

    // Show the splash screen & start the update of the display via DMA. To avoid briefly
    // showing rubbish, wait for that inital update to complete, then turn on the backlight.
    display.show_splash_screen(); 
    sleep_ms(25);

    _hal->set_backlight(true);

    // Get list of available patterns / routines
    std::vector<CRoutines::Routine> routines;
    CRoutines::get_routines(routines);
   
    hw_check.check_part2(); // If a fault is found, this never returns

    // Queue used for pulses from audio processing on core0 being sent to core1 for output
    for (uint8_t channel = 0; channel < MAX_CHANNELS; channel++)
        queue_init(&gPulseQueue[channel], sizeof(pulse_message_t), PULSE_QUEUE_LENGTH);

    // Queue used for routines (so far just Lua) running on Core1 to send debug messages (via print())
    // out over a websocket connection, if running via RemoteAccess
    queue_init(&gPatternTextOutputQueue, sizeof(pattern_text_output_t), PATTERN_TEXT_OUTPUT_QUEUE_LENGTH);

    // Queue used to send bluetooth HID events to Lua scripts
    queue_init(&gBtRawHidQueue , sizeof(CBluetoothConnect::bt_raw_hid_queue_entry_t), 15);

    // Load/set gain, mic preamp, etc., from eeprom
    _audio->init(settings, &display);

    _analogueCapture.start();

    led.set_all_led_colour(LedColour::Black);

    sleep_ms(100);

    core1_start(routines, settings);
    routine_output = new CRoutineOutputCore1(&display, &led, _hal, _audio);

    _audio->set_routine_output(routine_output);
    wifi = new CWifi(radio, &_analogueCapture, routine_output, routines);
    flash_helper_init(&_analogueCapture, routine_output);

    CMainMenu routine_selection = CMainMenu(&display, routines, settings, routine_output, &hw_check, _audio, &_analogueCapture, wifi, &bluetooth, radio, _hal);
    routine_selection.show();
    CMenu *current_menu = &routine_selection;
    display.set_current_menu(current_menu);

    uint64_t start = time_us_64();
    led.loop();
    uint64_t last_analog_check = 0;
    _hal->loop();

    set_normal_bootloader_mode(settings);

    while (1) 
    {
        uint64_t loop_start = time_us_64();
        radio->loop();
        wifi->loop();

        display.update();
        process_front_panel_input(current_menu);

        int8_t adj = _hal->front_panel()->get_adjust_control_change();
        if (adj && current_menu)
        {
            current_menu->adjust_rotary_encoder_change(adj);
        }

        if (time_us_64() > last_analog_check + 50000)
        {
            _hal->front_panel()->process(true);
            last_analog_check = time_us_64();
        }
    
        update_power_levels_from_front_panel(routine_output);
        if (time_us_64() - start > 1000000) // every second
        {
            start = time_us_64();
            led.loop(true);
            uint64_t timenow = time_us_64();
            // printf("Loop time: %" PRId64 ", batt: %d\n", timenow - loop_start, batt_percentage);
        }
 
        routine_output->loop();
        led.loop();
        _analogueCapture.process();
        _audio->process();

        if (_audio->is_audio_update_available(true))
        {
            display.set_update_required();
        }

        _hal->loop();

        if (g_SerialConnection)
            g_SerialConnection->loop();

        if (gFatalError)
        {
            routine_output->stop_routine();
            hw_check.die(gErrorString); // never returns
        }
    }

    return 0;
}

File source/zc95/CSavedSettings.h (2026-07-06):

#ifndef _CSAVEDSETTINGS_H
#define _CSAVEDSETTINGS_H

#include "bluetooth.h"
#include "Bluetooth/CBluetoothRemote.h"
#include "../common/zc95_config.h"
#include "CEeprom.h"
#include "CChannel_types.h"

#define EEPROM_SIZE      512 // EEPROM is 4Kbit

#define EEPROM_CHANNEL_COUNT 10 // Maximum number of configured channels that can be saved. Changing this invalidates EEPROM contents

class CSavedSettings
{
    enum class setting
    {
        EepromInit       =  0, // Contains magic value if eeprom as been initialised
        ChannelType      =  1, // Channel id 0 type
        ChannelIndex     =  2, // Channel id 0 index
        //  ...          = 19     Channel id 9 type
        //  ...          = 20     Channel id 9 index
        LEDBrightness    = 21, // default LED brightness
        PowerStep        = 22, // When using rot encoder for power, how many steps to increase power by for each click (e.g. as power level is 0-1000, 10 would give 100 possible power levels)
        RampUpTimeSecs   = 23, // When selecting a routine, how long (in seconds) does the power take to reach the power level set on the front panel
        AudioGainL       = 24, // Gain for left  channel
        AudioGainR       = 25, // Gain for right channel
        MicPreAmp        = 26, // Mic pre-amp enabled
        MicPower         = 27, // Mic power enabled
        Audio            = 28, // Audio setting: Auto/no gain/off
        Debug            = 29, // Debugging output destination
    
        // Collar config
        Collar0IdLow     = 30,
        Collar0IdHigh    = 31,
        Collar0Chan      = 32,
        Collar0Mode      = 33,
       // not used       = 34
       // Collar1IdLow   = 35
       // ...
       // Collar9Mode    = 78
       // not used       = 79

        AuxPort          = 80,  // Aux port usage - Audio or Serial
        WifiSSID         = 81,  // SSID to connect to. 32 characters/bytes + null
        WifiPSK          = 114, // Password, 64 characters + null
        WiFiConfigured   = 179, // Set to EEPROM_MAGIC_VAL if wifi configured. Anything else means not configured.
        WifiApPsk        = 180, // Auto-generated AP PSK. 16 characters + NULL
        WifiApPskEnd     = 196, //
        PowerLevelDisp   = 197, // Power level numeric display 
        ButtonLedBright  = 198, // Brightness of illuminated LED buttons 
        BluetoothOn      = 199, // Bluetooth enabled yes/no
        BTAddrStart      = 200, // Bluetooth address (6 bytes) start. Currently selected / paired device
        BTAddrEnd        = 205, // Bluetooth address end

        // These map keypress_t::* to a keypress_action_t::*, e.g. KEY_LEFT => ROT_LEFT
        BTButtonAction   = 206, // KEY_BUTTON
        BTUpAction       = 207, // KEY_UP
        BTDownAction     = 208, // KEY_DOWN
        BTLeftAction     = 209, // KEY_LEFT
        BTRightAction    = 210, // KEY_RIGHT
        BTShutterAction  = 211, // KEY_SHUTTER
        BTUnknownAction  = 212, // KEY_UNKNOWN
     //<next bt action>= 213,
        BtDeviceType     = 220, // Bluetooth device type (HID, GENERIC, etc.)
        BleAllowTriphase = 221, // If enabled, channel isolation can be disabled via BLE remote connect
        BlePowerMode     = 222, // What the front panel power dials do. See ble_power_dial_mode_t.
        PowerLevel       = 223, // Power level: Low, Medium or High (default)
        BatChargeCurrent = 224, // Max battery charge current. Multiply value held by 60 to get mA
     // Reserved         = 225  // Might use this in the future for BatChargeCurrent too
        StatusBarOption  = 226, // What to show in the status bar. Default is running pattern name      
        DisplayBrightness= 227, // Display brightness, in percent
        ExtendedRampLevel= 228, // Extended ramp percent, 1% - 100%
        ExtenedRampTime  = 229, // Extended ramp time. 1 - 200 (seconds)
        ExtendedRampShow = 230, // Show 'Ramp start' option on all patterns, and should progress be displayed on the status bar
        LedColourFormat  = 231, // Colour format (RBG, BGR, etc) of front panel LED buttons
        BootloaderMode   = EEPROM_BOOTLOADER_SETTING_ADDR, // (232) What the bootloader should do on next startup. Added as #define as it's shared with the bootloader code
        ExtenedRampShape = 233,
        BatteryStatus    = 234  // What to show inside the battery status icon
    };

    public:
        struct channel_selection
        {
            CChannel_types::channel_type type;
            uint8_t index;
        };

        struct collar_config
        {
            uint16_t id;
            uint8_t channel;
            uint8_t mode;
        };
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

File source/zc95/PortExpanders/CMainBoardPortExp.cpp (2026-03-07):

/*
 * ZC95
 * Copyright (C) 2025  CrashOverride85
 * 
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
 * You should have received a copy of the GNU General Public License
 * along with this program.  If not, see <http://www.gnu.org/licenses/>
 */

#include "../globals.h"
#include "../CUtil.h"
#include "hardware/gpio.h"
#include <string.h>
#include "CMainBoardPortExp.h"

/*
 * MKI (PCB <= v0.2)
 *   Deal with port expander U7 on the main board, which:
 *     - V0.1 front panel only: reads input from front panel buttons A, B, C & D.
 *       For front panels >= v0.2, p0-p3 are unused, and the buttons are connected 
 *       to a separate I/O expander on the front panel itself
 * 
 *     - is connected to IO1/2/3 on expansion header J17 (for optional audio input board)
 * 
 *     - controls the LCD backlight
 * 
 *    P4 - EXPAN_I03 - Mic pre-amp
 *    P5 - EXPAN_I02 - Mic power disable
 *    P6 - EXPAN_I01 - Audio enable (relay)
 *    P7 - LCD back light
 * 
 * MKII (PCB >= v2.0)
 *   Deal with port expander U28, which is connected to:
 *    P0 - TP4056 charger IC - standby
 *    P1 - TP4056 charger IC - charging
 *    P2 - N/C
 *    P3 - N/C
 *    P4 - Microphone preamp enable
 *    P5 - Microphone power enable (for electret mics)
 *    P6 - N/C
 *    P7 - N/C
 */

CMainBoardPortExp::CMainBoardPortExp(zc95_version_t hardware_version, hw_variant_t mkII_variant, IPortExpander* port_exp)
{
    _hardware_version = hardware_version;
    _port_exp = port_exp;
    _mkII_variant = mkII_variant;

    _old_state = 3;
    _last_read = 0;    
    _button_states_at_last_check = 0;
    memset(_last_state_change, 0, sizeof(_last_state_change));
    clear_input();
    process(true);
}

// Clear any pending input. has_button_been_pressed, etc., should return false after this has been called.
void CMainBoardPortExp::clear_input()
{
    // Do init here too
    _port_exp->set_pin_as_output(MicPreampEnablePin);
    _port_exp->set_pin_as_output(MicPowerDisablePin);

    if (_hardware_version == zc95_version_t::MKI)
    {
        _port_exp->set_pin_as_output(AudioInputEnablePin);
        _port_exp->set_pin_as_output(BackLightPin);
    }

    if (_mkII_variant == hw_variant_t::V2_2)
    {
        _port_exp->set_pin_as_output(UsbCcSelectPin);
        _port_exp->set_pin_as_output(UsbSenseSelectPin);
        _port_exp->set_pin_as_output(LcdResetPin);
    }
    
    _port_exp->read_port_expander(&_last_read);
    _button_states_at_last_check = _last_read;
}

void CMainBoardPortExp::interrupt()
{
    _interrupt = true;
}

void CMainBoardPortExp::process(bool always_update)
{
    if (_interrupt || always_update)
    {
        _interrupt = false;
        _port_exp->read_port_expander(&_last_read);
    }
}

bool CMainBoardPortExp::button_state(enum Button button)
{
    return (_last_read & (1 << (uint8_t)button));
}

bool CMainBoardPortExp::has_button_state_changed(enum Button button, bool *new_state)
{
  bool button_state_changed;
  bool last_button_state = (_button_states_at_last_check & (1 << (uint8_t)button));
  *new_state = button_state(button);

  button_state_changed = (last_button_state != *new_state);

  if (button_state_changed)
  {
    if (time_us_64() - _last_state_change[(uint8_t)button] < (25 * 1000) ) // 25ms debounce
      return false;
    else
      _last_state_change[(uint8_t)button] = time_us_64();
  }

  if (*new_state)
    _button_states_at_last_check |= (1 << (uint8_t)button);
  else
    _button_states_at_last_check &= ~(1 << (uint8_t)button);

  return button_state_changed;
}

/*
 * Enable microphone pre-amp on audio input board. Massively increases gain. 
 * Also results in mono input only as there is only one mic preamp
 */
void CMainBoardPortExp::mic_preamp_enable(bool enable)
{
    _port_exp->set_pin_state(MicPreampEnablePin, enable);
}

/*
 * When enabled and audio_input (below) is also enabled, ~3v is supplied via a current 
 * limiting resistor to the ring of the 3.5mm socket to power electret microphones
 */
void CMainBoardPortExp::mic_power_enable(bool enable)
{
    _port_exp->set_pin_state(MicPowerDisablePin, !enable);
}

/* Applies to MKI only where there's a single shared port for audio and serial.
 * MK2 has separate audio and serial ports so there is no switching.
 * Enabled  = 3.5mm socket used for Audio input
 * Disabled = 3.5mm socket used for RS232 serial
 */
void CMainBoardPortExp::audio_input_enable(bool enable)
{
    if (_hardware_version == zc95_version_t::MKI)
    {
        if (enable)
            printf("Enabling audio input\n");
        else
            printf("Disabling audio input\n");

        _port_exp->set_pin_state(AudioInputEnablePin, enable);
    }
}

// MKI only. On MKII backlight is connected directly to Pico
void CMainBoardPortExp::set_lcd_backlight(bool on)
{
    if (_hardware_version == zc95_version_t::MKI)
        _port_exp->set_pin_state(BackLightPin, on);
}

bool CMainBoardPortExp::get_tp4056_charge_status()
{
    if (_mkII_variant == hw_variant_t::V2_0)
        return _port_exp->get_pin_state(ChargePin);
    else
        return false;
}

bool CMainBoardPortExp::get_tp4056_standby_status()
{
    if (_mkII_variant == hw_variant_t::V2_0)
        return _port_exp->get_pin_state(StandbyPin);
    else
        return false;
}

// MKII only. Set where ADC0 comes from.
// V2.2 boards have the ability to switch between sending CC1, CC2 and 
// VBUS to ADC0. Earlier boards have no switch, so it's always VBUS.
void CMainBoardPortExp::set_adc0_source(adc0_select_t source)
{
    switch(_mkII_variant)
    {
        case hw_variant_t::NA:
            printf("MainBoardPortExp::set_adc0_source: Error - attempt to set adc0 source on MKI\n");
            return;

        case hw_variant_t::V2_0:
            if (source != adc0_select_t::USB_VBUS)
                printf("MainBoardPortExp::set_adc0_source: Error - attempt to set adc0 source to CC line on MKII < v2.2 \n");
            return;

        case hw_variant_t::V2_2:
        {
            if (source == adc0_select_t::USB_CC1 || source == adc0_select_t::USB_CC2)
            {
                _port_exp->set_pin_state(UsbSenseSelectPin, false);
                _port_exp->set_pin_state(UsbCcSelectPin, source == adc0_select_t::USB_CC2);
            }
            else
            {
                _port_exp->set_pin_state(UsbSenseSelectPin, true);
                // With UsbSenseSelect (SW_SENSE2) high, the ouput from the CC line
                // goes nowhere, so the setting of UsbCcSelect is irelevent.
            }

            return;
        }
    }
}

void CMainBoardPortExp::lcd_reset()
{
    if (_hardware_version == zc95_version_t::MKII)
    {
        _port_exp->set_pin_state(LcdResetPin, false);
        sleep_ms(10);
        _port_exp->set_pin_state(LcdResetPin, true);
    }
}

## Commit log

2021-11-16 inital commit
    [BoM.ods, output_bom_jlc.csv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]
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2021-12-31 add kicad files
    [FrontPannel-ADA358.kicad_pcb, MainBoard.kicad_pcb, MainBoard.sch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]
2022-02-04 fixes #2 - wrong gerber file for front panel (back) PCB
2022-04-23 add status bar that shows battery percentage and current pattern (if any)
2022-06-15 tweak reading of adc so it doesn't interfere as much with the rot encoder
2022-06-25 I2c comms with zc624 (#9)
    Implement i2c slave on zc624.
    On startup, zc95 checks zc624 output board is present, and has initialised correctly, erroring if not.
    Firmware version now embedded in zc624, and retrieved + displayed in about screen of zc95.
    [config.h, zc95.cpp]
2022-07-15 Enlarge pot holes (#10)
    * enlarge holes for pots on front panel
    * Add change log for PCBs
    * Update front panel gerbers
    [FrontPannel-ADA358.kicad_pcb]
2022-08-27 Audio input (#13)
    Add audio input - schematics, gerbers, build notes & code
    [AudioInput.kicad_pcb, AudioInput.kicad_sch, BoM.ods]
2022-09-30 Add "Audio Wave" pattern (#14)
    - Adds "Audio Wave" pattern - which is suited to stereo estim tracks via line input
    - Allows channel isolation to be removed, so multiple channels can pulse at the exact same moment (required for triphase effects)
    - Improved handling of adjust/rotary encoder input
    - Version check for zc624 output board on startup
    - Fixes issue where pulse width generated by zc624 was longer than intended
    [config.h, zc95.cpp]
2022-10-12 General tidyup (#15)
    * remove references to single core mode, which hasn't worked for ages
    * remove old code for front panel which had all rotary encoders instead of POT+ADC, and remove old rotary encoder logic that's since been replaced with something better
    * remove version file
    * remove remnants of code that could control a 312b via serial
    * rename references of zc1 to zc624
    * change BoM format from ods to fods. Still open office, but should be possible to see something in diffs when updated
    * BoM: fix typo, and add comment about WS2812D's with different pinouts
    * update photo in readme, tweak comments and add a todo to readme
    [BoM.ods]
2023-02-12 zc624: on power up calibration/self test, allow for a slightly greater variation in cal values than before (#18)
2023-02-19 fix issue where most patterns could get hidden if audio was switched off (#19)
2023-02-21 Remote access and Lua (#20)
    Adds support for a Pico-W to be used as the MCU on the main board, and allows remote control over WiFi.
    Also allows for Lua scripts to be upload and ran as a way to add new patterns.
2023-04-23 Output board bom update (#23)
    * update 100k resistors to be C149504 instead of C17407 (discontinued)
    * update inductor from C237915 (out of stock) to C177243
    * fix rotation on U2 and U3
    [output.sch, output_bom_jlc.csv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]
2023-05-12 Misc tweaks (#24)
    A few miscellaneous changes / fixes:
    * Allow Lua scripts to write to the 3x output lines on the accessory port
    * Allow Lua scripts to set 0 pulse width, i.e. generate only one polarity. Previously 1us was the minimum
    * Fix issue where the channel 1 bar graph would briefly show around 50% on power up
    * Fix bug in toggle pattern where turning the adjust dial with the 'Pulse/Cont.' parameter selected would trigger a swap to the next channel
    * Tweak toggle so that the default speed is somewhere near the middle, rather than the slowest speed
    [zc95.cpp]
2023-06-04 Allow eeprom to be cleared (#32)
    * allow eeprom to be cleared by holding down top right button when powering on
    * add notes on clearing eeprom to build docs
2023-08-05 update BoM and build notes (#39)
    - Update 10uF cap C191532 -> C88739
    - Update pin socket C50984 -> C124410
    - Add comment about orientation of PCF8591 to build notes
    [PanelControls.sch]
2023-08-05 fix issue where it wasn't possible to set the power to 0 from a Lua script. Fixes #38
2023-08-05 increase max line length permitted in uploaded Lua script, and add error for when this limit is hit. Addresses #37
    [config.h]
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2023-08-13 Change the order of some includes so that it will compile on arm-none-eabi-gcc (Arm GNU Toolchain 12.3.Rel1 (Build arm-12.35)) 12.3.1 20230626 otherwise you get failures due to missing definitions of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
2023-08-13 Update the debounce time to 25ms which was needed for the different push switches I used. With 10ms we'd get menu items skipping.
2023-08-18 Add a backplate OpenSCAD file and STL for a 3d printed backplate with (#57)
    [zc95panel.scad, zc95panel.stl]
2023-08-20 Show power level percent (#58)
    Adds the option to show a numeric/percentage power level display, Allows display of power level:
    * In large-ish text for a few moments on change. Based on code linked to in #52
    * In small text, all the time, in the bar graph
    Can be configured from settings -> Display options -> power level display.
2023-08-23 urldecode wifi access point ssid and password (#61)
    * More explicit setting of wifi power mode
    Use cyw43_pm_value to set the wifi power mode. The call results in the
    exact same value as before (0xa11140), but makes it more explicit what
    is happening. It also makes it easier to adjust the power management in
    the future.
    * urldecode wifi ssid and password
    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
2023-08-23 Don't display Up/Down button text if there is no action - fixes #59
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2023-08-29 Update LED display so Lua scripts don't just show solid red (#65)
    Makes LEDs when running a Lua script respond in a similar way to in built patterns like waves, climb, etc.
    Need to update both zc95 & zc624 firmwares.
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2023-10-07 tweak comms between zc95 & zc624 to reduce jitter in output
2023-10-07 Use OK LED on zc624 & improve error reporting (#69)
    * use OK LED on zc624. Improve error display on zc95 when output board init fails
    * add note to build docs / troubleshooting section about the OK LED
    [config.h]
2023-10-08 test SPI comms between main board and output board on startup (#70)
2023-10-14 fix issue where pin 6 (front panel interupt) was being driven high. Fixes #71
    [zc95.cpp]
2023-10-20 add note to arduino zc624 lib that it might not work with >= v1.7
2023-10-21 on panic, try and make sure both cores halt and the output board is shutdown
2023-10-29 fix debug output from arduino lib
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2023-12-11 Update kicad project
    [output.kicad_pcb, output.kicad_sch]
2023-12-11 updated gerbers & schematic
    [output_bom_jlc.csv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]
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2024-02-11 New front panel (#86)
    v0.2 of front panel. light up led buttons, new adc, new i/o expander
    [BOM-PanelControls.csv, FrontPannel-ADA358.kicad_pcb, PanelControls.kicad_pcb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]
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2024-03-02 Fix issue with new front panel where power level graphs didn't get updated when first entering remote mode, and a button press was registered at startup that wasn't there
2024-03-15 Bluetooth remotes (#88)
    Add support for Bluetooth remotes, and change battery status to an icon
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2024-04-21 fix issue where large script would casue a crash on upload (#92)
    * fix issue where large script would casue a crash on upload
    * when uploading a lua script, don't allocate the full 24k/48k in memory and write to flash at the end, instead write to flash in 4k blocks during upload
    [config.h]
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2024-06-18 fix bug where multi-choice selector when running patterns would forget current selection
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2024-06-25 Build notes update + 3d printed LED riser (#105)
    See #102
    [led-riser.stl, output.kicad_pcb, output.kicad_sch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]
2024-07-06 tweak hw check so that state of LED driver IC on front panel doesn't affect detection of front panel version (#108)
2024-08-16 Update AudioInput-Build.md
    D3 silkscreen wrong, thanks electro991 for identifying it
2024-08-17 allow rotary encoder to be used on pattern selection list and a couple of others (#116)
2024-09-01 fix 0805/0603 mixup (#120)
    [output.kicad_pcb, output_bom_jlc.csv]
2024-09-01 correct link text for front panel bom and cpl files
2024-09-02 Missed a 10uF 0805 cap that should be 0603 (#119 #120)
    [output.kicad_pcb, output_bom_jlc.csv]
2024-09-10 update R1 and R26 of output board to be C479327 instead of C479296 (#121)
    [output.kicad_pcb, output.kicad_sch, output_bom_jlc.csv]
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2024-11-02 Fix build with 2.0 SDK (#129)
    [CMainBoardPortExp.h]
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2024-11-06 Audio input board redesign for SMT (#133)
    [AudioInput.kicad_pcb, AudioInput.kicad_sch, BOM-AudioInput.csv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]
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2025-03-26 fix board outline for front panel and mainboad (#139)
    [FrontPannel-ADA358.kicad_pcb, MainBoard.kicad_pcb]
2025-04-18 Update kicad projects
    [AudioInput.kicad_pcb, AudioInput.kicad_sch, FrontPannel-ADA358.kicad_pcb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]
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2025-04-18 new gerbers
    [BOM-AudioInput.csv, BOM-main.csv, output_bom_jlc.csv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]
2025-04-18 some renaming
    [BOM-PanelControls.csv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]
2025-04-18 add 3d printed case
    [bottom.step, endplate.stl, top.step]
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2025-04-27 fix solder mask minimum width setting, then regenerate gerbers
    [main.kicad_pcb]
2025-05-04 J16 isn't supposed to be on the BoM, remove it.
    [BOM-main.csv]
2025-05-25 update out of stock 0.5R resistor C705591 to be C175573 instead
    [BOM-main.csv, main.kicad_pcb, output.kicad_sch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]
2025-06-12 fix typo BQ72441 -> BQ27441
    [config.h]
2025-06-20 fix i2c address for port expanders on schematic
    [main.kicad_sch]
2025-06-20 improve error messages when hardware check fails
    [CDetermineHardwareVersion.cpp, zc95.cpp]
2025-07-31 Add PCB v2.3 kicad project files + gerbers
    [BOM-main.csv, audio.kicad_sch, main.kicad_pcb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]
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2025-07-31 Support for v2.3 PCB: - use BQ25601 charge controller - set maximum battery charge current - sense type of USB adaptor plugged in - reset display on power on using port expander
    Changes for all MKIIs:
    - Ability to change display brightness
    - Option to show battery current in status bar instead of currently running pattern
    [CMainBoardPortExp.cpp, CMainBoardPortExp.h]
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2025-08-18 Remove C64 and C65
    [BOM-main.csv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]
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2025-09-15 Mainboard PCB v2.4
    [BOM-main.csv, audio.kicad_sch, main.kicad_pcb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]
2025-10-01 v2.5 schematic + PCB changes
    [audio.kicad_sch, main.kicad_pcb, main.kicad_sch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]
2025-10-17 update production files, schematic pdf, and change log
    [BOM-main.csv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]
2025-11-28 Change C50 on main board from 4.7nF to 47nF
    [BOM-main.csv, audio.kicad_sch, main.kicad_pcb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]
2025-11-28 Build with Pico SDK 2.2.0. Fixes #147
2026-01-17 Fix issue where buttons were unresponse on mk1 with front panel 0.1 (#160, #159)
2026-01-24 tolerate occasional ADC read error without shutting down
2026-02-06 C58 on the mainboard should be 10uF not 10nF
    [BOM-main.csv, main.kicad_pcb, main.kicad_sch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]
2026-02-19 Try i2c bus recovery after adc read errors
    [config.h, zc95.cpp]
2026-03-07 Pcb v2.6 (#167)
    [BOM-main.csv, audio.kicad_sch, main.kicad_pcb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]
2026-03-21 update R156 and R157 to be 100R not 10K
    [BOM-main.csv, main.kicad_sch, output.kicad_sch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]
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2026-05-17 add 3d printed frame for display
    [lcd_frame_ada.stl]
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2026-08-26 Add new front panel (#190)
    [BOM-PanelControls.csv, FrontPannel.kicad_pcb, PanelControls.kicad_pcb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]
2026-09-16 Allow shock collars to be used from Lua / general channel handling rework (#192)
    [CSavedSettings.h, zc95.cpp]
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2026-10-19 Don't miss quick presses on front panel v0.2 buttons (#201)
    Buttons were only checked once per main loop against the last port
    expander read, so a press released again before the check was missed.
    Remember buttons that go down when the port expander is read, and report
    the press on the next check even if the button is already up again.
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

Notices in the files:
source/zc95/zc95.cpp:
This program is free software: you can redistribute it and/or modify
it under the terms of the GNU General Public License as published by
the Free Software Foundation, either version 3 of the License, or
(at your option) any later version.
